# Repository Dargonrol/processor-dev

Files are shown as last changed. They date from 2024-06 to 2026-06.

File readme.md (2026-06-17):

# Project overview

| Project-name | Architecture | Microarchitecture | ISA | status |
| --- | --- | --- | --- | --- |
| **Dragon-1** | SAP-1 | SAP-1 | Dragon-1 | **completed** |
| Dragon-2 | SAP-1 | SAP-1 (mod.) | Dragon-2 | abandoned |
| Dragon-3 | JAM-1 (mod.) | JAM-1 (mod.) | - | abandoned |
| **Dragon-4** | Dragon-4 | Dragon-4 | Dragon-4 | **completed** |
| *Dragon-5* | RISC-D (Dragon) | Dragon-5 | Dragon-5 | *WIP* |
| LED+ | LED | LED-ext. | LED | abandoned |
| Phoenix-1 | - | - | - | in planning |
| Surtr-1 | Z80 | Z80 | Z80 | in planning |

# Descriptions
## Dragon-1
My first try to build an CPU. Basically followed Ben-Eaters breadboard CPU series and read the book Digital Computer Electronics from Albert P. Malvino. I did however implement and thought of my own ISA. It was a good project to get into processors and I'd recommend anyone interested giving building a simple SAP-1 a try.

## Dragon-2
Here is when I went creative and tried to implement all sorts of things I came up with. I only heard of interrupts without knowing what exactly they are and tried to implement them. I also tried to add a display. Both went horribly wrong. It was fun though coming up with all those interesting solutions. It was definitely an important learning step even if it never came to life.

## Dragon-3
Dragon-3 is when I watched a lot of James Sherman and his great homebrew CPU series. Seriously, if you have watched Ben Eater and want to step up things, go ahead and watch James Sherman. You will learn a lot. This is also when I first came across pipelining. Interestingly enough, James implemented it quite differently then a standard risc-V microarchitecture.
Anyway I tried to build my own pipelined CPU but ended up (mostly) copying James which I didn't like so I abandoned it. I am sure it would have come out quite differently if I would have continued but there was really no time to do that because at that time I got in contact with a person who would change my processor development journey for ever. He convinced me to participate at a German science tournament called 'Jugend Forscht'.

## Dragon-4
Knowing I need something proper for this (and especially not a copy of James's CPU) for Jugend Forscht, I began developing the Dragon-4. Due to time constrains I knew, that I couldn't make Dragon-4 pipelined since that would have been much more complicated.  Even tough I tried to not copy James, I was still heavily influenced by him and that's why the rough architecture is quite similar to his JAM-1. It is also the first CPU I build in reallife which added a lot of interesting challenges. If you are interested in the design process and inner workings, I'd recommend reading my 'paper' I had to write for the tournament.
If I had to name one feature of the Dragon-4, it would be that the ISA is horrible. Dragon-4 has 31 instructions, but uses 242 op-codes for them!!! That would be fine if I would have implemented different addressing modes like the 6502 but most of the instructions where just permutations to perform the same action with different registers. E.g. ADD A B, ADD B A, ADD A C etc...
The logic simulation was fine but for some reason I never got the flags working in the real-life version. 
The control logic is also really bad since it consists of 4x32kb of ROMs to decode instructions. This is also why Dragon-4 is really difficult to recreate in games.

## Dragon-5
My current work of art. Originally made to be easily build in computer games but honestly I might scratch that. More important is that I am getting really close to the physical limit for a completely custom microarchitecture. This is also why this will be my last and most capable processor I will build IRL. It's a risc like CPU with a capable ISA. It has stuff like MMIO, basic interrupt support, memory banks to support a large amount of memory as well as seperate instruction and data caches. It's still in early WIP. You'll find a simple comparison of the CPU's in the [readme](Dragon/Dragon_5/readme.md) of Dragon-5.

## LED+
This CPU was developed as an more capable successor to the LED-CPU in the game 'Turing Complete'. LED+ was basically completed but since I wasn't happy I kept trying to improve it but ultimately failed. There were even more iterations of the LED like LED++ and LED+++ but I decided to not include them in this list because they never got really far. Eventually the need for a good processor ingame let to the beginning of the development of the Dragon-5.
Fun-fact: 
Originally Dragon-5 was going to be Phoenix-1 and Phonix-1 was going to be Dragon-5.  Since Dragon-4 was my first real CPU I wanted the most capable and powerful CPU to be the successor of that. And Phoenix-1 was supposed to be the CPU 'for games'. However the reason why I did not do it that way was because the architecture and microarchitecture of the Dragon-4 (if you can even call it architecture) was really simple which fits to the now Dragon-5 (of course Dragon-5 is much more capable and is heavily inspired by the RISC-V). Phoenix-1 is going to be much more complicated therefore I thought a new name would be more fitting.

## Phönix-1
Phoenix-1 is going to be my most capable processor yet. While Dragon-5 was designed to be the last processor IRL, Phoenix-1 will be completely simulated giving me complete freedom. In future it should be able to run a simple operating system etc. (Description WIP)
- Has things like DMA, Branch prediction etc.

## Surtr-1
Surtr-1 is not going to be one of my most powerful machines, but is rather supposed to imitate an old gaming console... using the Z80 CPU...

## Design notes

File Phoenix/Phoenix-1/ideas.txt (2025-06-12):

superpipelining
UART
Interrupts
	- Normal Interrupts
	- Non maskable Interrupts
	- Reset
	{ interrupt interruptbar? -> ja ->  prioritäten... -> prop table in mem. ***annhang1***}
	{ interrupts as trap instr. or different?????? }
	{ Interrupt reg for defining type of int. etc. trough special instr. modble}
	{ When interrupt, save machine state, liks all regs inc. flags }
DMA?
16 oder 32bit???
seperate instruction and data Cache
hardware mul/div?
CLA adder
32 registers? saved and temp usw
program pointer mod-bar, add instr -> don't need jmp instr. but then slower as like in dragon-4

Things like northbrige for graphics card and sound card?????
or integrated graphics? then seperate graphics mem. 

Flags:
	Interrupt Enable

***anhang1***
ext. mem wie z.B. Floppy oder Festplatte wo OS drauf ist. und dann auch sowas wie prop table etc.
ROM on CPU für BIOS, welches OS lädt?
maybe 2 floppy drives or something else, one for OS other for idk. games? user data?

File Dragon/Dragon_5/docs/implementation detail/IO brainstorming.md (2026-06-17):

Remember, with MMIO no I/O data is in RAM. The address decoder detects that I am accessing IO and just pulls data from them.
on every I/O card dip switches to set start address? that way we do not have to convert addresses from CPU address space to IO address space. This also makes it possible to split addresses dynamically aka making having a device more MMIO then usual. 
IO address and data bus is the same with main address and data bus.
Dip switches are 16 bit. They select the address range of the device. we need two dip switches to select a range. The MMIO bit is always set.
``0bxxxx 1xxx xxxx xxxx``
When interrupt, send the upper 4 bits to Interrupt reg. it automatically completes to the full 16bit address.

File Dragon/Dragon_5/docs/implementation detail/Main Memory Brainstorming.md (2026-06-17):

### memory banks
I think it would make the most sense if one memory card holds multiple memory banks. because I want to use a PCIe connector the card would be too small in comparison if I would only put one bank on each card. I am thinking of maybe 4 per card. each card then has jumper or dip switches or simple two close vias that can be brigded to set which card is which *or* the mem cards don't really have any logic and the slot where you put it in decides which one is which. The second option would provide a better user experience.

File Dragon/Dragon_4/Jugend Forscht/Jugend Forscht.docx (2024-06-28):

Projekttitel: Dragon-4 | Ein auf Logikebene selbst entwickelter Prozessor

Projektbeschreibung: Beschreibe kurz, worum es in Deinem Projekt geht und welche Vorgehensweise Du planst.

Schon als kleines Kind habe ich mich immer gefragt, wie es möglich ist, dass ein so kleiner Microchip so viel kann. Als ich älter wurde fing ich an, mich damit auseinander zu setzten. Man findet viele Informationsvideos oder Datenblätter zu Prozessoren und ihrer Funktionsweise. Doch sie alle haben eins gemeinsam: Sie veranschaulichen nur oberflächlich, wie solch ein Wunderwerk der Technik funktioniert. Eine Antwort wie: „Die ALU (Arithmetic Logic Unit) berechnet irgendwelche Zahlen“ oder „Der RAM Speichert Daten“ reicht mir nicht. Ich will wissen, wie genau, auf kleinster Ebene, solch ein Prozessor funktioniert. Wie werden Daten gespeichert? Wie rechnet die ALU? Diese Fragen versuche ich zu beantworten, indem ich selbst einen Prozessor entwickle, um seine Funktionsweise bis ins kleinste Detail zu verstehen. Dazu verwende ich keinen fertigen Microcontroller, sondern stelle mir die benötigte Logik selbst zusammen, um das so tief wie mögliche Verständnis zu erlangen.

Ideen

In welcher Pipeline stage muss welche Control line hin. -> näher erläutern, denn bis zur ersten execution hat es ziemlich lange gedauert…

Überlegt, macht es Sinn content von RAM direkt in MAIN BUS? Aber nein, weil dann REG Controls in der ersten Stage sein müssten, das sind zu viele Lines für die erste

Pipeline: muss 1 clock cycle behind sein, weil sonst speicher an die falsche stelle pointet. -> input der Pipeline latchen

Reg controls in first and second stage, zwar mehr control lines, aber dafür kein noFetch notwendig -> speicher bus ist free to use, wir müssen keine „op skippen“ | DOCH NICHT, da wir keine neue Fetchen können, da das nächste Value im Speicher keineOP ist, sonder just a constant. Also würden wir wenn wir keine 2 Stages brauchen würden und also noFetch weg lassen, das Value als OP fetchen…. Deswegen brauchen wir auch keine direkte Verbindung zwischen RAM und Mainbus, weil wir eh 2 cylcen brauchen bis wir was neues fetchen können.

Alles was ich anders machen wollte, hat sich herausgestellt macht keinen Sinn

Pipeline zu Comlex. Würde eine Copie von James sein.bräuchte mehr Zeit um selber drauf zu kommen, mein Ziel zu lernen würde es dennoch erfüllen. Nur Jugend Forscht nicht. Weil ich unbedingt was eigenes auf die beine stellen möchte für Jugend Forscht, mache ich single Stage.

Anfangskonzept von Ben Eater, mit ROM als Control Unit und Fetch Unit

So, I ran out of OP-Codes when I did the ALU

Why not include cMOV instructions?

Immer gedacht, pipeline notwendig für cpu die quch wirklich was machen können, aber liegt eig. Nur an Architektur.

RAM logic war aua, hahb a lot of truth tables gedrawed, um das hin zu kriegen (some truth tables in die arbeit adden)

Last minute Change, all regs inv clocks

Talk about problem with CREGs in simulation

And massive routing problems, talk about airwires, pin’s waren nicht connected

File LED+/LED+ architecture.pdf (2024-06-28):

# LED+ architecture

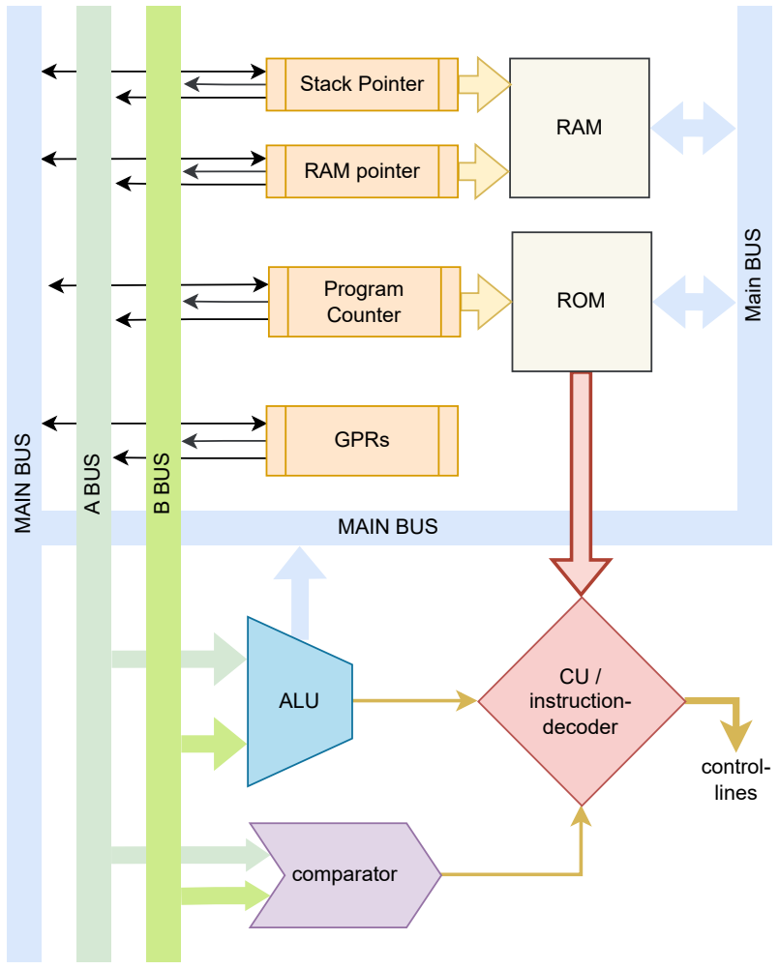
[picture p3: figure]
MAIN BUS; ROM; RAM; GPRs; Program Counter; Stack Pointer; RAM pointer; B BUS; BUS; Main BUS; ALU; comparator; CU / instruction- decoder; control- lines

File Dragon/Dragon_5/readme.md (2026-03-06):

#Dashboard #Dragon5 #Dragon
## general information
- 16bit CPU
- Pipelinded (? stages)
- separate data/instruction-cache
- dynamic instruction range
	- 16bit memory addr, 2 byte word (therefore no need for (auipc)

- Directly Mapped Cache

- nibble = 4-bit
- byte = 8-bit
- word = 16-bit
- dword = 32-bit
- qword = 64-bit

## Instruction Cache
- Directly Mapped
- 64k Cache lines
- 4-bit tag
- 16-bit set
that makes realistically: 2x32k x 8 bit memory chips for tag + valid bit and 1x64k x 16 bit memory chip for data

1. Cache Miss
2. Stall Pipeline
3. Send nearest round down address to RAM, request data
4. Increment address by 1, storing receiving words in Cache
5. after counter at SIZE unstall pipeline

## Graphics
- banked memory
- set double frame buffer mode for half the memory size
# CPU comparison
## **Dragon 5:**
### Instruction count
**Total Instruction Count (used op-codes):** 56 (without pseudo)
**Maximal Instruction Count:** 64, 6-bit
### Features
**Pipelined:** yes
**Variable Instruction Length:** no

## **Dragon 4:**
### Instruction count
**Real Instruction Count:** 31 (without permutations)*
**Total Instruction Count (used op-codes):** 242 (with permutations)*
**Maximal Instruction Count:** 256, 8-bit
### Features
**Pipelined:** no
**Variable Instruction Length:** yes

## **6502:**
### Instruction count
**Real Instruction Count:** 56 (without illegal ones)
**Total Instruction Count (used op-codes):** ?
**Maximal Instruction Count** 256, 8-bit

### Features
**Pipelined:** no
**Variable Instruction Length:** yes

footnote *
permutations means e.g. all the different addressing modes from the 6502 or in case of the dragon 4  for every register combination to add a value you had a different instruction (ADD A B is different than ADD B A) which resulted in a lot of permutations...

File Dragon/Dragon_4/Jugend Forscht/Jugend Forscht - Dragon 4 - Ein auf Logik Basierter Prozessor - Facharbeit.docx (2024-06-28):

2023

Bach Alexander

Jugend forscht

25.3.2023

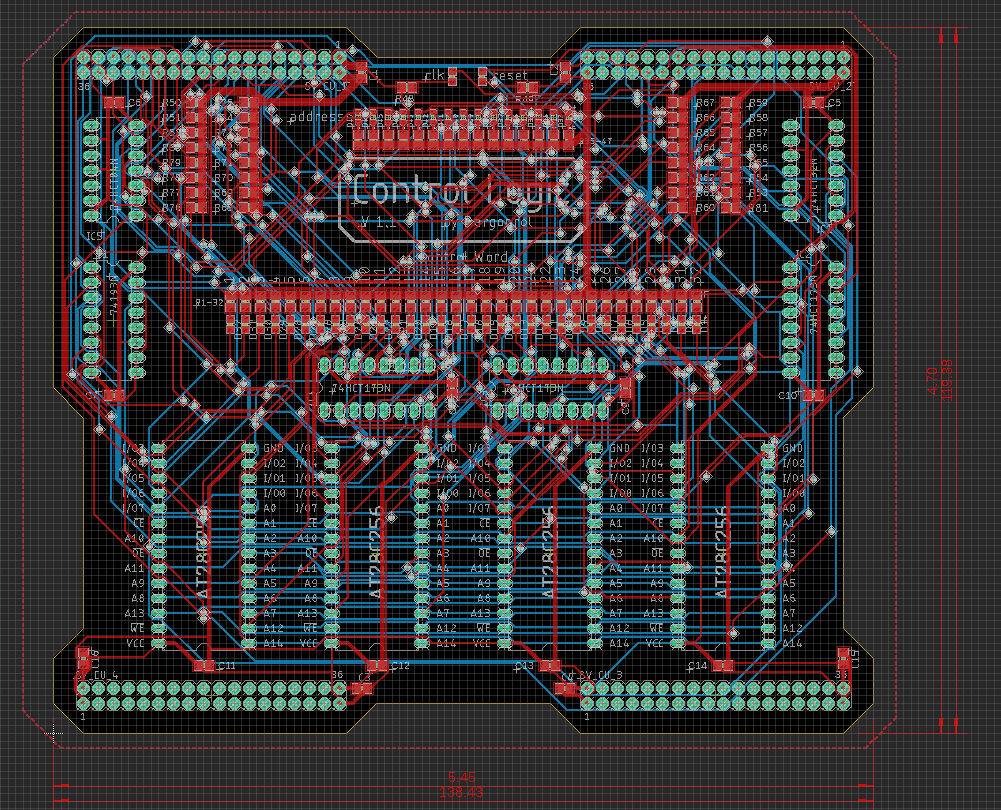
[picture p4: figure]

„Zu verstehen, ist die Essenz, um zu erschaffen.“

Dragon-4 | Ein auf Logikebene selbst entwickelter Prozessor

# Kurzfassung

Mein Ziel ist es die fundamentale Funktionsweise eines Prozessors zu verstehen. Schon oft habe ich gröbere Erklärvideos gesehen, die grundlegende Zusammenhänge darstellen wie zum Beispiel den Aufbau eines Prozessors. Doch all diese Lehrinhalte haben eines gemeinsam: Sie veranschaulichen nur einen groben Einblick in die komplexe Welt der Computer. So will ich nicht nur grundlegende Prinzipien verstehen, sondern mir einen so tiefgreifenden Einblick in die Thematik schaffen, dass ich selbst in der Lage wäre einen Prozessor von Grund auf selbst zu entwickeln. Und genau das tat ich. In diesem Projekt, konzentriert sich Jahrelange Liebe für Technik sowie stundenlanges Forschen und Entwickeln, für das Erschaffen eines eigenen Prozessors.

# 1. Einleitung

## 1.1 Ursprünge

Seit jungen Jahren bin ich ein technikbegeisterter Mensch. Schon damals wurde ich mit kleinen Bastelkits oder Technikmuseen begeistert. Mein Opa brachte mir viel allgemeines Wissen bei und ich fing an meine eigenen Projekte zu realisieren. Doch den Einstieg in Digitaltechnik machte ich tatsächlich durch ein Computerspiel namens Minecraft. So simpel es doch ausschaut ist es möglich, ganze Computer in diesem Spiel zu kreieren. An Inspiration mangelte es nicht. Auf YouTube sah ich dauernd Menschen, welche Taschenrechner oder einfache Spiele erschaffen hatten. Nicht lange danach fing ich selbst an mich mit dieser Thematik zu beschäftigen und machte mich relativ schnell vertraut mit Logikgattern. Logikgatter sind die ultimative Basis jeder Digitaltechnik. Auch wenn man sie weiter in z.B. Transistoren unterteilen kann, bilden Logikgatter die wahre Essenz und absolute Grundlage. In Minecraft dauert es nicht lange, bis man an die Grenzen des Möglichen stößt, weswegen sich die Ausweitung auf eine Logiksimulations-software wie Logisim nicht lange vor sich warten ließ. Zum ersten Mal war es mir möglich, alle meine Ideen umzusetzen, ohne Geld in teures Material zu investieren. Mein Wissen erweiterte ich, selbst heute noch, mit kostenlosen Inhalten wie Videos auf YouTube. Wenn man lange genug sucht, findet man äußerst lehrreichen Inhalt, der nur darauf warten gesehen zu werden. Durch Hilfe von außerhalb erlangte ich auch Zugriff auf Bücher wie The Art of Electronics von Paul Horowitz und Winfield Hill, sowie Digital Computer Electronics von Albert P. Malvino und Jerald A. Brown. Mehrere Jahre experimentiere ich so herum und erweiterte mein Horizont. Erst Letztes Jahr entfachte in mir die Flamme, einen Prozessor zu entwickeln und in der Realität umzusetzen.

## 1.2 Ein Traum wird Realität

Der Wendepunkt meiner Geschichte wurde von nur einer einzigen Person inszeniert. Mein Projektbetreuer Benjamin Brück war es, der mich zu Jugend forscht brachte. Erst jetzt war es möglich das kostenintensive Hobby in die Realität umzusetzen. Die Deadline, die dadurch entstand, brachte natürlich einerseits Unmut, doch im Wesentlichen ist genau das der Grund, warum ich überhaupt Fortschritte gemacht habe. Man kann sich plötzlich keine drei Jahre mehr Zeitnehmen, sondern wird aktiv dazu gebracht, weiterzumachen. Einen Monat vor der Anmeldung begann ich schließlich intensiv zu forschen, verwarf mehrmals meine Konzepte und brachte schließlich eine teilfertige Version ins Leben. Vor allem James Sharman, ein Youtuber, welcher einen sog. Pipelined processor[^1] entwickelt hat, löste einen unglaublichen Motivationsschub hervor. Zunächst wollte ich seinen Prozessor aus Zwecken des Verstehens lediglich nachbauen, doch die Teilnahme an Jugend forscht stellte sich dem Quer und das aus gutem Grund. Für meine privaten Ziele, des Verstehens hätte ein einfaches Nachbauen ausgereicht, doch durch die Teilnahme an Jugend forscht wollte ich etwas Eigenes auf die Beine stellen. Einfach etwas nachbauen kann jeder, auch wenn das Nachbauen und das tatsächliche Verstehen zwei unterschiedliche Dinge sind. So nahm ich mir stattdessen Sharmans Werk als Vorbild und baute darauf meinen eigenen Prozessor. Die Architektur[^2] mag ähnlich sein, doch meine bis zu dem Punkt entwickelten Architekturen wurden restlos übertroffen. So musste ich einen Kompromiss eingehen. Ich nahm seine Architektur als Vorbild, veränderte sie und baute dann darauf auf. Ich wollte mich so weit wie möglich von ihm entfernen, doch die Genialität seiner Architektur beibehalten. So ist der Kern meines CPUs[^3] essenziell anders. Jedes Modul wurde von mir selbst entwickelt, simuliert, geplant und schließlich gebaut. Ich habe immense Zeit und stundenlanges Kopfzerbrechen in dieses Projekt investiert, um mein Ziel, das tiefgründige Verstehen eines Prozessors, zu erreichen.

# 2. Vorgehens- und Funktionsweise

## 2.1 Entwürfe, Planung, Anfänge

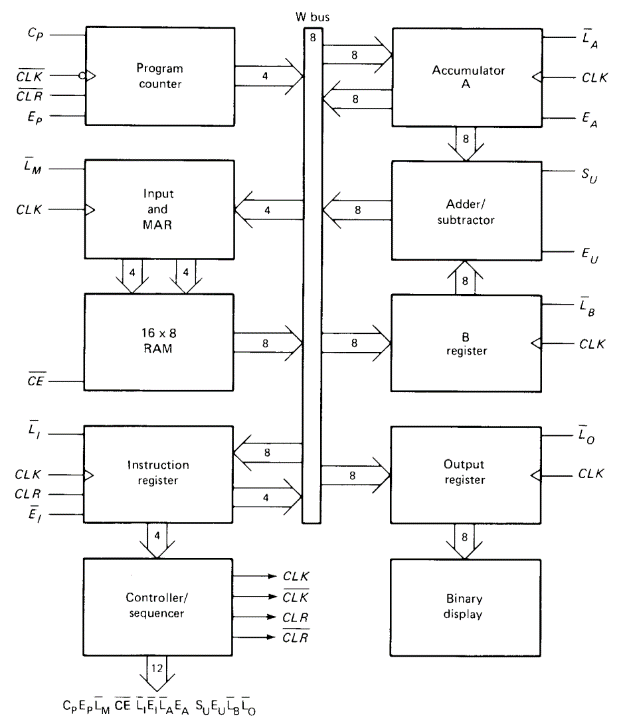
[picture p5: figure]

Zunächst begann alles mit dem SAP-1. SAP steht für Simple as Possible. Das ist Englisch und bedeutet so einfach wie möglich. Der SAP-1 ist eine Prozessor Architektur, vorgestellt von Albert P. Malvino in seinem Buch Digital Computer Electronics mit dem Ziel einem die Grundlagen eines Prozessors nahezubringen. Der SAP-1 ist die simpelste Form eines Turing vollständigen Prozessors. Turing vollständig bedeutet die universelle Programmierbarkeit eines Systems benannt nach Alan Turing. Im Endeffekt ist das ein System, welches in der Lage ist, sich selbst zu emulieren oder jede beliebige Berechnung zu tätigen, wenn sie unendlich Speicherplatz zur Verfügung hätte und die Berechnungszeit endlich ist. Den SAP-1 nachzubauen war mein erstes Ziel und der erste Schritt zu einem näheren Verständnis eines Prozessors. Alles weitere Wissen baut auf diesem Verständnis auf. Aber im Grunde gibt es eine Zentrale Einheit, die sog. Control Logic. Diese ist zuständig für die Erhaltung der Ordnung im System. Das macht sie, indem sie durch control lines Signale an die jeweiligen Module sendet. Das wiederum tut sie basierend auf eng. Instructions, Befehle, welche sie vom RAM[^4] bekommt.

### 2.1.1 Dragon-1

Der SAP-1 war mein Einstieg in Prozessoren. Einmal verstanden, kann man von da aus weiter seinen Weg gehen und komplexere Themen anstreben. Der Dragon-1, der erste Entwurf, war im Prinzip nichts anderes als der SAP-1, mit ein paar erweiterten Funktionen. U.a. konnte die ALU[^5] mehr logische Operationen, die die Ursprünge ALU des SAP-1 nicht konnte. Außerdem hatte der Dragon-1 mehr Register[^6] und vor allem ein Display. Mein Ziel war es damals, ein Display anzuschließen, bei dem sich jeder einzelne Pixel steuern lässt. Auch wenn meine Pläne wahrscheinlich in der Theorie funktioniert hätten, wären die Möglichkeiten sehr begrenzt und ineffizient gewesen. Auch wenn ich ihn schon beinahe fertig simuliert hatte, stufte ich den Dragon-1 äußerst unpraktisch ein und verwarf ihn.

Abbildung 1| SAP-1 Architektur

### 2.1.2 Dragon-2

Relativ schnell setzte ich mich schließlich an den Dragon-2, die Weiterentwicklung des Dragon-1. Hier lag der Fokus vor allem auf I/O-Handling[^7]. Der Dragon-2 hat dazu im Unterschied zum Dragon-1 eine vollständig selbst entwickelte Architektur und versucht Hardware-interrupts[^8] zu integrieren. Ich entwickelte von Grund auf selbst ein System, um Interrupts zu Implementieren. Einer der größten unterschiede war aber wohl das Trennen vom Daten- und Programmspeicher und das hinzufügen eines 16-Bit Adress-busses. So ähnelt die Architektur der Harvard Architektur. Der Dragon-1 hingegen basierte auf der Von-Neumann Architektur, die einen gemeinsamen Bus für Adressen und Daten verwendet. Zu guter Letzt finden wir noch einen sog. Stack, der z.B. für function-calling genutzt wird. Damit war der Dragon-2 eine wesentliche Weiterentwicklung gegenüber dem Dragon-1. Beim dem Dragon-2 wäre es wahrscheinlich auch geblieben, doch fand er nie seinen Weg vom Papier in die Simulation, denn es gibt zwei Sachen, die mich umgestimmt haben. Einmal, war ich mir sehr unsicher bezüglich des I/O-Handling Systems. Ich hatte nicht die Zeit und die Mittel, um dieses System zu testen. Ich konnte mir nie sicher sein, dass es auch wirklich funktionieren würde. Man beachte, dass wir hier vor dem Zeitpunkt der Anmeldung an Jugendforscht reden. Zweitens entdeckte ich James Sharman, ein YouTuber, der seinen eigenen Prozessor nach dem Pipeline-Prinzip entwickelte.

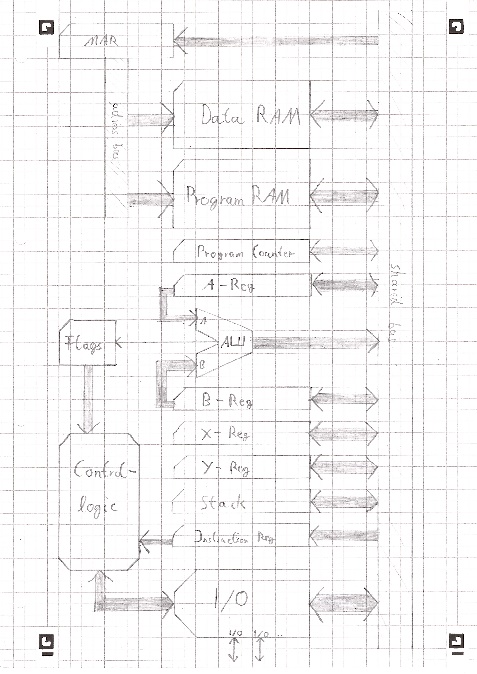
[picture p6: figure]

### 2.1.3 Dragon-3, Pipeline

Eine Pipeline ist eine andere Art der Steuerungseinheit. Im Gegensatz zu multicycle Prozessoren werden hier mehrere Instruktionen gleichzeitig bearbeitet. Das führt dazu, dass sich die Zeit, die der Prozessor benötigt, um einen Befehl auszuführen, effektiv auf Dauer eines Taktes der Taktfrequenz verringert. Bei einem multicycle Prozessor benötigt eine Instruction meist mehrere Taktzyklen. Daher der Begriff multicycle. Mit der Pipeline liegt der größte Unterschied des Dragon-3 zum Dragon-2 aber in der Anzahl der Busse oder einfach gesagt in der Architektur generell. Diese ist wie bereits erwähnt stark inspiriert von James Sharman. Anstatt eines MARs[^9] haben wir einen 16-Bit Adress-Bus, auf dem mehrere Adress-Register ihre Daten ablegen können. Außerdem ist der Haupt-Bus (main bus), auf dem Daten wie Ergebnisse von Berechnungen übertragen werden getrennt von dem Speicher-Bus (memory bus), sodass sich gleichzeitig Daten sowie auch neue Instruktionen bewegen können. Zu guter Letzt kann jedes Register Daten an die ALU mit separaten ALU-Bussen (ALU-Left, ALU-Right) senden. Das alles hat den Vorteil von deutlich mehr Flexibilität und Parallelisierung von Prozessen. Um I/O zu unterstützen, muss man lediglich ein Gerät an den Haupt-Bus anschließen und durch etwa einen I/O-Handler steuern lassen. Theoretisch ginge das auch direkt über die Steuereinheit (CU oder CL), die Anzahl von verfügbaren Steuerleitungen ist aber begrenzt. Auch der Dragon-3 war nicht weit entfernt von der fertigen Simulation, nichtsdestotrotz gibt es einige Punkte, weshalb ich nicht bei dem Dragon-3 geblieben bin. Der Hauptgrund ist wohl, die starke Ähnlichkeit zu James Sharmans CPU. Ein anderer Grund ist die wesentlich höhere Komplexität einer Pipeline. Zwar habe ich das Konzept einer Pipeline verstanden, jedoch würde es zu viel Zeit beanspruchen, eine eigene zu entwickeln, wenn man im Hinterkopf hat, dass wir uns hier schon unmittelbar nach der Anmeldung bei Jugend forscht befinden.

Abbildung 2 | Selbst gezeichnete Architektur des Dragon-2

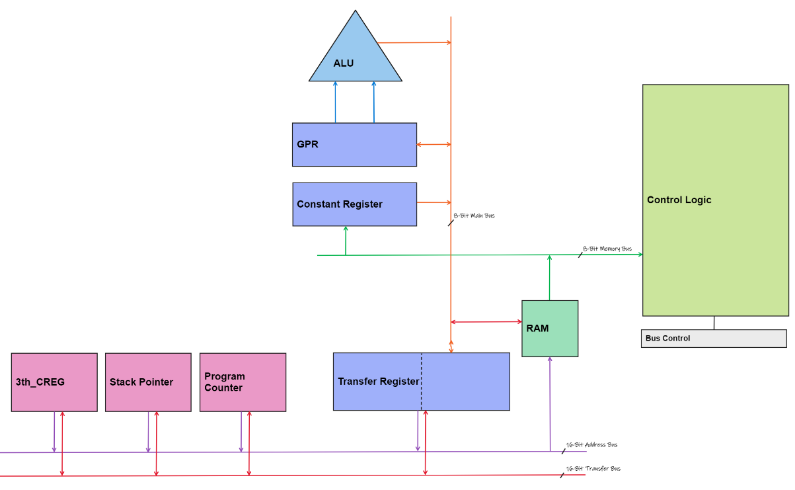
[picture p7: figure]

### 2.1.4 Dragon-4

So sind wir heute bei dem Dragon-4. Die Architektur basiert auf die des Dragon-3, also den von Sharman entworfenen Design, doch das Pipeline-Konzept, welches mich doch sehr inspiriert hat, wurde verworfen und wesentliche Änderungen an der Architektur vorgenommen.

Unter anderem wurde die Anzahl der 16-Bit Register auf drei reduziert und vor allem eine direkte Möglichkeit des RAMs Daten auf den Haupt-Bus aufzulegen erschaffen. Gleichzeitig wurde die Anzahl an GPRs[^10] erhöht und die Bus-Bridge, die in der von Sharmans Ursprünglichen Architektur den Haupt Bus und den Speicherbus verbunden hat, herausgenommen. Diese ist nämlich keine Notwendigkeit und wird durch das Abschaffen der Pipeline sowie eine direkte Verbindung des RAMs zum Haupt Bus auch nicht mehr benötigt.

Abbildung 3 | Dragon-4 Architektur

## 2.2 Vorgehensweise

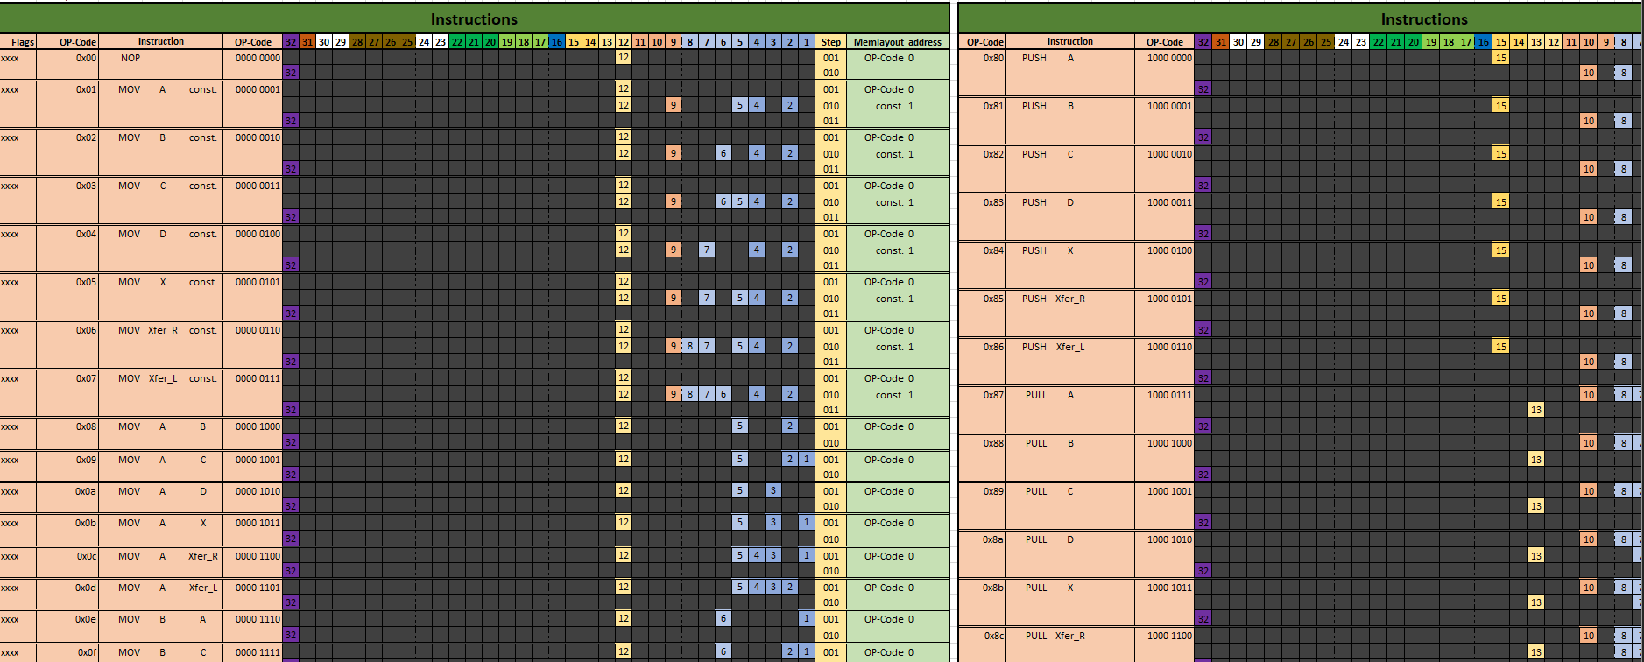
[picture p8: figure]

Zunächst einmal muss man das Grundgerüst, die System Architektur bilden, um anzufangen einen Prozessor zu entwickeln. Da mir diese durch den Dragon-3 bereits klar war, fing ich direkt damit an und nutze das von Microsoft für Windows verfügbare Programm Whiteboard (siehe Abb. 3). Dort ist das Grundgerüst entstanden. Natürlich muss einem vorher klar sein, was man erreichen möchte und was der Prozessor alles können soll, um darauf seine Architektur aufzubauen. Wichtig ist mir eine breite Anzahl an Funktionen, die der CPU leisten kann, sowie einfache Ein- und Ausgabe Möglichkeiten. Natürlich sollte er auch nicht zu langsam sein, um ein Minimalmaß an Nutzbarkeit zu erlangen. Für die Nutzbarkeit war vor allem ein breites Maß an Instruktionen notwendig. Jede Prozessorarchitektur hat seine eigene Programmiersprache, mit eigenen Befehlen, mit dem sie arbeiten kann, die Assemblersprache. Die Assemblersprache steht direkt vor der Maschinensprache mit Einsen und Nullen und besteht aus einfachen Begriffen z.B. MOV A B. Intel Prozessoren haben eine andere Syntax als AMD, da sie direkt vom Prozessortyp abhängig ist. Deshalb gibt es für meinen Prozessor keine fertige Sprache, sondern muss erst entwickelt werden. Dazu fertigte ich eine große Excel-Tabelle mit allen verfügbaren, von mir definierten Befehlen an. Da der Dragon-4 ein 8-Bit Prozessor ist, unterstützt er genau 256 verschiedene Befehle. Als Inspiration habe ich mir dazu das reale Instruction-Set des x86 Prozessors angeschaut.

Abbildung 4 | Ausschnitt des Instruction Sets

### 2.2.1 Simulation

Da nun alle Grundeigenschaften gegeben waren, konnte ich mit der Entwicklung der einzelnen Module anfangen. Das allerdings im realen Leben zu tun ist kostspielig und aufwendig. Deshalb verwendete ich zunächst eine Logik-Simulationssoftware namens Logisim. Logisim ist ein großartiges Werkzeug, um Logikbausteine zu simulieren und zu testen. So habe ich sie zum Beispiel genutzt, um zu experimentieren welche Kombination von Logik Gattern ich benötige, um das gewünschte Ergebnis zu erhalten. Das hat mir das aufwendige Aufbauen und Verkabeln von realen Bauteilen erspart und den Prozess um einiges Beschleunigt. Schließlich habe ich den gesamten Prozessor simuliert, um sicherzugehen, dass er überhaupt funktionieren würde. Dabei sind einem viele Logik- und Denkfehler aufgefallen, die teilweise zu neuen Ideenanstöße geführt haben. Das alles, die Entwicklung des Prozessors in der Software, sowie das Ausmerzen von Fehlern und experimentieren beschreibt einen großen Teil der von mir investierten Zeit in das Projekt.

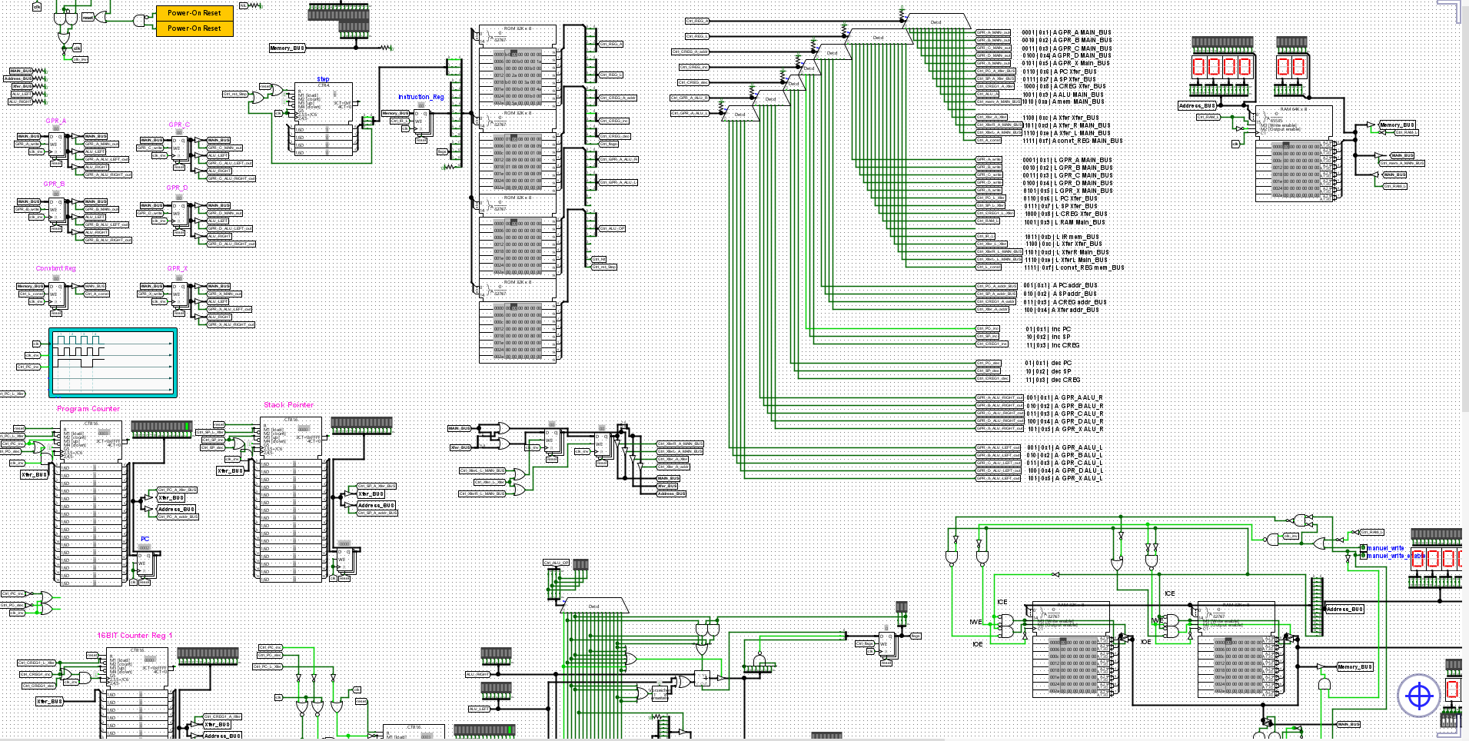
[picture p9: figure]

Abbildung 5 | Ausschnitt der Simulation des Dragon - 4

### 2.2.2 ROM-Datengenerator

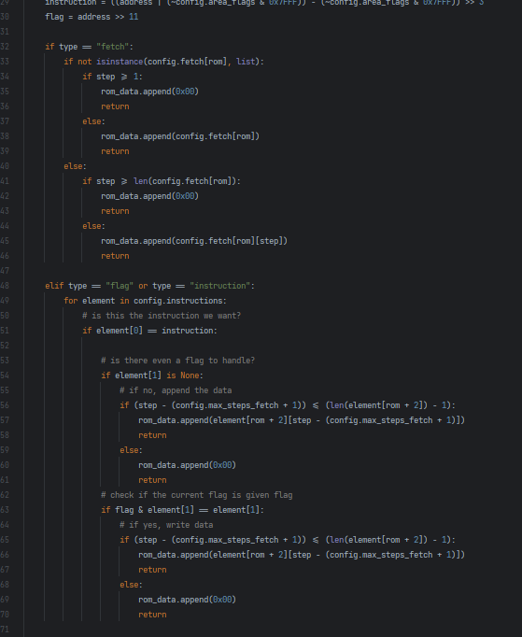
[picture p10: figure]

Um den CPU vollständig in der Logiksoftware zu testen, muss natürlich auch die Steuereinheit vollständig sein. Das Problem, was sich hier aber auftut, ist, dass die Steuereinheit aus ROMs[^11] besteht, die den gigantischen Dekodierer ersetzen, der ansonsten von Nöten wäre. Das Interessante an einen ROM ist, dass man mit Speicherchips jegliche kombinierbare Logik ersetzen kann. Das mache ich mir hier zunutze, um nicht einen übermäßig großen Dekodierer bauen zu müssen. Dieser würde ansonsten jegliche Dimensionen sprengen. Nun müssen dazu aber vorher die ROMs mit Daten gefüllt werden. Die hier verwendeten ROMs haben 32000 mal 8 Bit Speicherplatz. Also 32000 Zeilen mit jeweils 8 Bit oder 1 Byte an Daten. Die Steuereinheit nutzt vier Stück von diesen. Die Daten also von Hand einzutragen wäre nicht nur wahnsinnig, sondern auch noch eine große Zeitverschwendung. Dazu schrieb ich ein Programm in Python, welches für mich alle 32000 Zeilen an Daten füllt. Ich muss lediglich die 256 Instruktionen einmal von Hand in dem Programm definieren.

Abbildung 6 | Ausschnitt des "ROM-Datengenerators"

### 2.2.3 PCB design

Nachdem die Simulation einwandfrei funktionierte, wurde es Zeit, das Projekt in die Realität umzusetzen. Mir schien die Option, das Ganze auf Platinen zu bauen, effizienter und einfacher, als es mit handgefertigten Pantinen oder Breadboards zu versuchen. So arbeitete ich mit der PCB[^12]-Design Software Eagle um Schaltpläne des Dragon-4 zu erstellen und die PCBs zu designen. Dieser Prozess beanspruchte ebenfalls einen großen Teil meiner gesamt Investierten Zeit. Man beachte allerdings, dass „gesamt Investierte Zeit“ sich nur auf den Zeitraum von der Anmeldung bei Jugend forscht bis zur Fertigstellung des Projektes bezieht. Der Dragon-1 ist bereits zwei Jahre vorher entstanden. Über diese zwei Jahre verteilt wurde immens viel Zeit mit Recherche und Weiterbildung zu diesem Thema verbracht, sodass es schwierig ist, die gesamt Investierte Zeit zu schätzen.

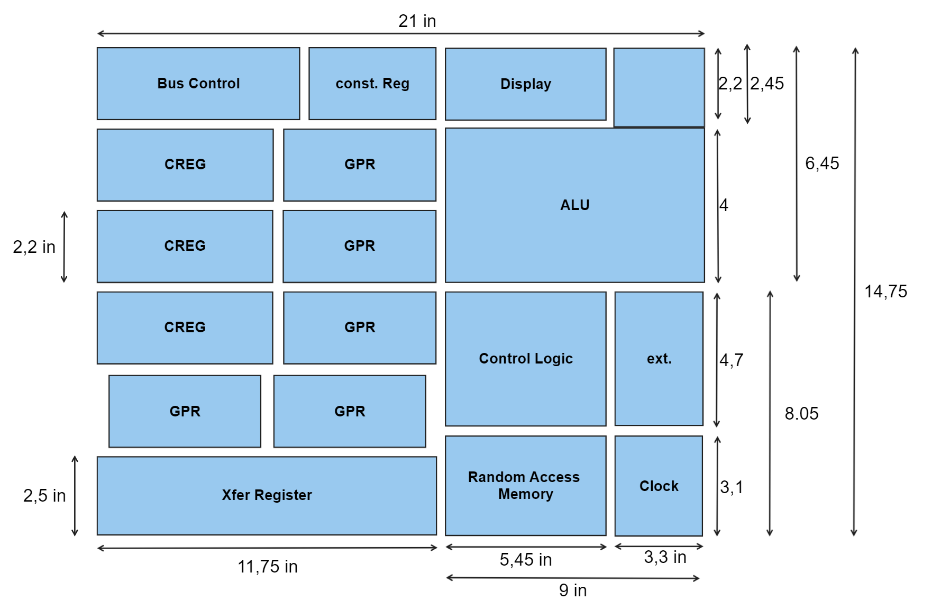
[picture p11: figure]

Bevor ich anfangen konnte, die PCBs zu designen oder die Schaltungen zu erstellen, musste ich mir erst über das Layout im Klaren werden. Hier stellte ich mir die Frage, wie soll der Prozessor später aussehen? Ich entschied mir für ein modulares Design, da Fehler unausweichlich sind und so diese einfacher zu korrigieren sind und ein modulares Design am meisten Flexibilität bietet. Ich kann einfach ein fehlerhaftes Modul herausnehmen und mit einem neuen ersetzen. Die tatsächlichen Maße weichen durch Weiterentwicklung während des PCB-Designs etwas ab, im Großen und Ganzen spiegelt Abbildung 7 aber sehr genau die tatsächliche Größe wider.

Abbildung 7 | Physisches Layout vom Dragon-4

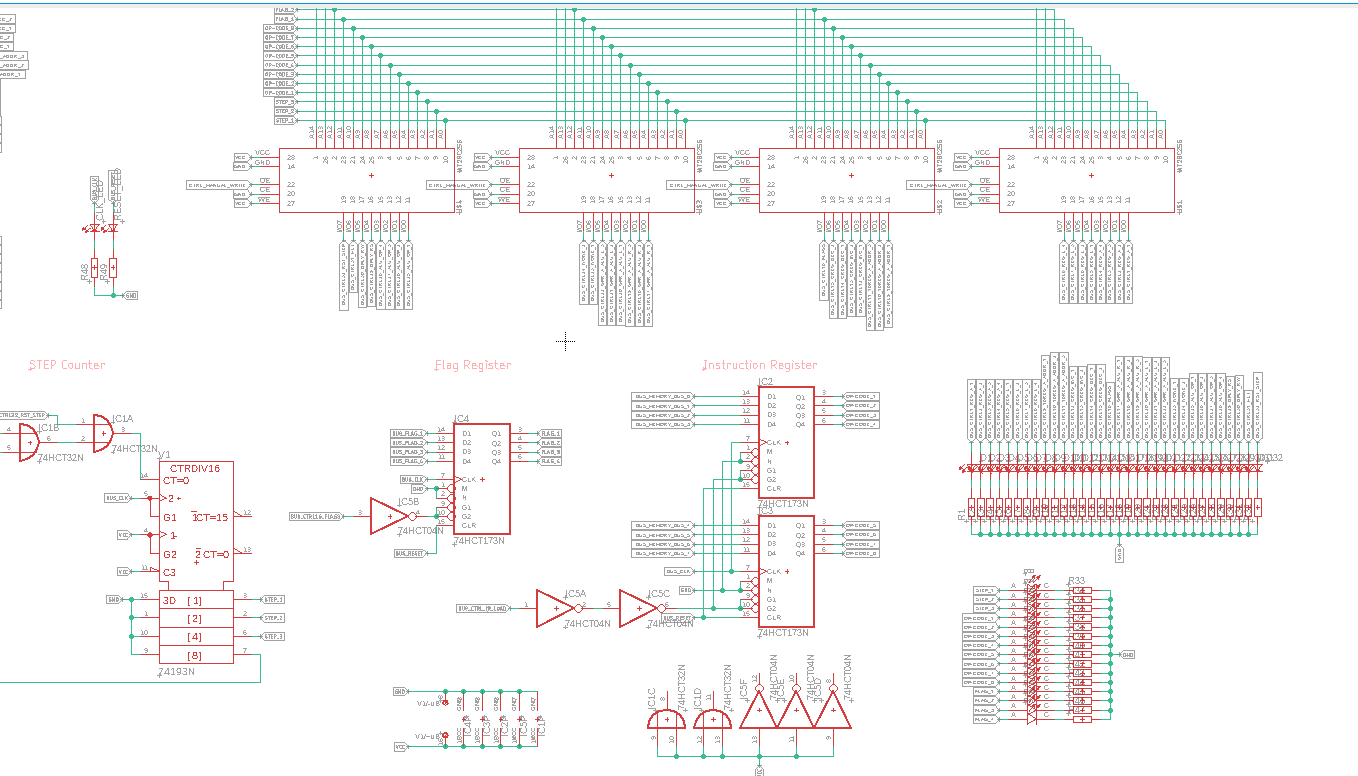
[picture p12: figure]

Nachdem das Layout stand, konnte ich anfangen, die Module zu erstellen. Zunächst der Schaltplan, dann das PCB. Hier galt es allerdings einiges zu beachten. Zunächst einmal muss man schauen, wie man die Bauteile in der Simulation in einen Schaltplan überträgt, denn die Simulation bietet nur idealisierte Bauteile. Ich musste also durch Recherche Bauteile finden, die dieselbe Funktion haben wie in der Simulation. Außerdem musste ich mich entscheiden, welche LEDs, welche Widerstände, welche Kondensatoren, welche Verbinder und noch vieles mehr ich nutzen möchte. Falls es diese dann nicht in dem Programm existieren, muss ich sie selbst erstellen. Zu beachten gibt es hier auch Dinge wie z.B. Lieferzeiten von Bauteilen und Verfügbarkeit. Ist die Schaltung einmal fertig gestellt, kann es zum PCB-Design übergehen. Hier musste ich mich erst mit allgemeinen Designregeln beschäftigen wie zum Beispiel, wann und wo man einen Kondensator platziert, und lernen mit dem Programm umzugehen. Da ich ein modulares Design verwende, muss es noch eine Grundplatte geben, die alles verbindet, das Motherboard. Nachdem alle Teile fertig designt waren, mussten diese lediglich von einem Platinen Hersteller gefertigt werden.

Abbildung 8 | Ausschnitt der Kontroll-Logik

### 2.2.4 Zusammenbau und Programmieren

Nach Anfertigen der Teileliste und deren bestellen. Steht nur noch das Zusammenfügen vor einem. Nach Löten von über 6000 Pins, wochenlanges verbessern von Fehlern und debuggen ist der Prozessor fertig. Doch äußerst viel kann er in dem Zustand noch nicht, denn es müssen noch die ROMs, welche sich in der Steuerungseinheit befinden, beschrieben werden. Danach muss man lediglich ein Programm in den RAM laden und schon konnte der Prozessor seiner Bestimmung nachgehen.

## 2.3 Funktionsweise

Die Funktionsweise in einem Umfang zu erklären, welche nicht die Limitierungen dieser Facharbeit sprengen würde, ist schwierig, weshalb ich mich hier relativ kurzfasse.

Um die Funktionsweise des Dragon-4 zu verstehen, ist ein gewisses Grundwissen notwendig. Dieses erläutert man am besten anhand des SAP-1. Immerhin ist der SAP-1 so einfach wie nur möglich aufgebaut. Um den folgenden Erklärungen besser zu folgen, ist auf der nächsten Seite wieder die Architektur des SAP-1, nur dieses Mal etwas größer, abgebildet.

### 2.3.1 Clock

Die Clock ist wohl das simpelste Bauteil eines jeden Prozessors. Die Clock ist dazu zuständig, nach einem definierten Zeitintervall periodisch ein Signal auszusenden. Dieses wird dazu verwendet den gesamten Prozessor zu synchronisieren, damit jedes Bauteil fehlerfrei miteinander kommunizieren kann. Die Frequenzen erreichen in modernen Prozessoren mehr als 4 GHz . Im Dragon-4 ist die Frequenz durch seine Größe und verwendeten Bauteile sehr begrenzt. Dadurch, dass das Clock-Modul noch nicht fertiggestellt wurde, wurden noch keine Hochgeschwindigkeitsversuche durchgeführt, ich rechne aber mit einer theoretischen maximalen Frequenz von 1,67 MHz . Die bisher höchste getestete Frequenz liegt bei 5 kHz .

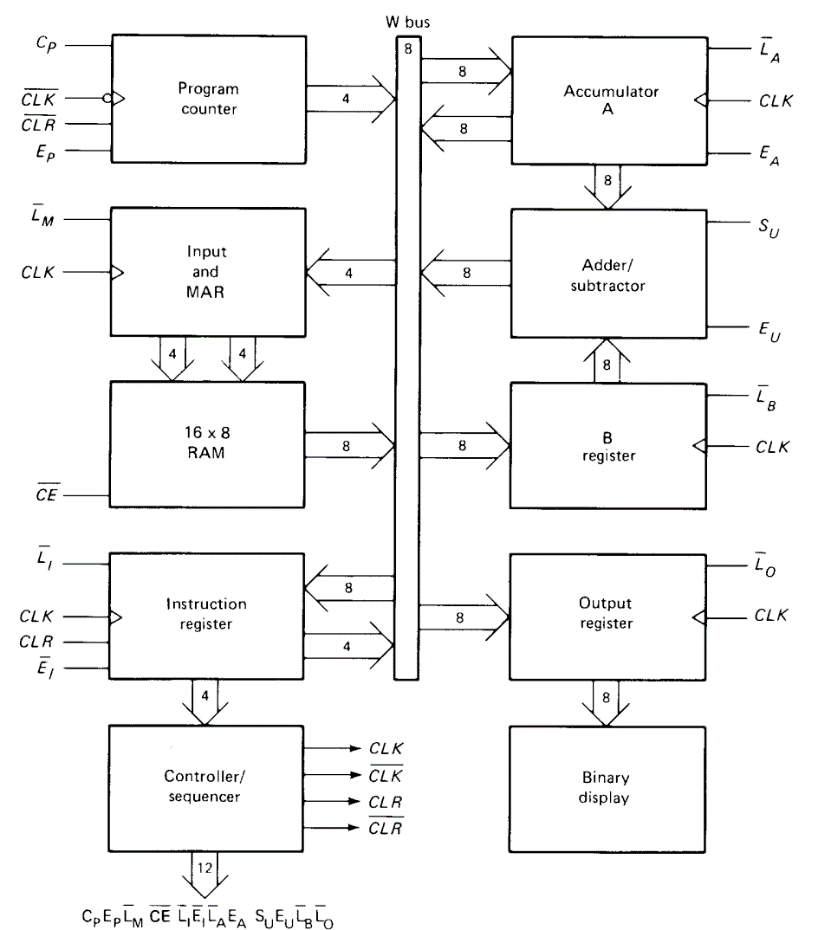
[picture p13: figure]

### 2.3.2 Register

Das Register, ein fester Bestandteil eines jeden Prozessors, tut nichts anderes als in meinem Fall 1-2 Byte an Daten für spätere Wiederverwendung zu speichern. Anders als bei dem RAM, haben wir hier nur eine Zeile mit Daten. Wenn das Register ein Signal zum Speichern empfängt, wird bei dem nächsten Clock-Zyklus die Daten, die sich am angrenzenden Datenbus befinden gespeichert. Nach empfangen eines Ausgabe-Befehls wirft das Register seine Daten wieder auf den Datenbus.

### 2.3.3 PC (Program Counter)

Der Programmzähler ist nichts anders als ein Register, welches die Fähigkeit hat, binär zu zählen. Auf Kommando erhöht es den Wert in seinem Register um eins. Das passiert genau nach jeder Instruktion. So könnte man ihn auch Instruction Pointer nennen. Denn er zählt im Grunde nur mit, bei welchem Punkt wir uns im Programm befinden. Er zeigt auf die Adresse im RAM, bei der die nächste Instruction gespeichert ist, damit diese ausgeführt werden kann.

Abbildung 9 | SAP-1 Architektur

### 2.3.4 MAR (Memory Address Register)

Das MAR ist ein weiteres Register, welches die Aktuelle Adresse des RAMs speichert. Im SAP-1 wird der Inhalt des program counters in das MAR verschoben, um die aktuelle Adresse zu ändern. In meinem Prozessor gibt es direkt kein MAR. Hier wird der Inhalt des program counters so lange auf einen Adressbus ausgegeben, bis sie nicht mehr benötigt wird. Der Adressbus ist direkt mit dem RAM verbunden.

### 2.3.5 RAM

Der RAM ist einer der zentralen Komponenten. Er beinhaltet das Programm, welches wir ausführen möchten und so die Instruktionen, die dem Prozessor sagen, was er zu tun hat. RAMs können mehrere Hunderttausende Speicherbänke mit Datensätze beinhalten. Welche Speicherbank gerade ausgewählt ist, wird als Adresse bezeichnet. In meinem Fall besitzt der RAM 64000 Speicherbänke mit jeweils einem Byte, also 8 Bit Daten. Der RAM kann seine Daten entweder auf einen BUS ausgeben, oder direkt Steuereinheit überreichen.

Der RAM des Dragon-4 ist gleichzeitig das Stack. Das Stack wird zum function-calling verwendet. Die Besonderheit, dass der Stack in dem RAM integriert ist, ist dass der Speicherplatz für beides, Stack und Programm variable ist. Wenn man nicht aufpasst, könnte man den einen Bereich mit dem anderen überschreiben, andererseits hat es den Vorteil, dass wenn man mehr RAM benötigt, einfach mehr nutzten kann.

### 2.3.6 Control Logic (CU, CL)

Die Steuereinheit ist das Herz eines jeden Prozessors. Ohne sie, wäre er nicht funktionsfähig. Die Steuereinheit nimmt sich eine Instruktion, welche sie von dem Instruktions-Register oder dem RAM bekommt und sagt dem ganzen Rest des CPUs, was er zu tun hat. Das macht sie mithilfe eines riesigen Dekodierers, der für jede Instruction einen Befehlssatz das sog. Control Word ausgibt.

### 2.3.7 ALU

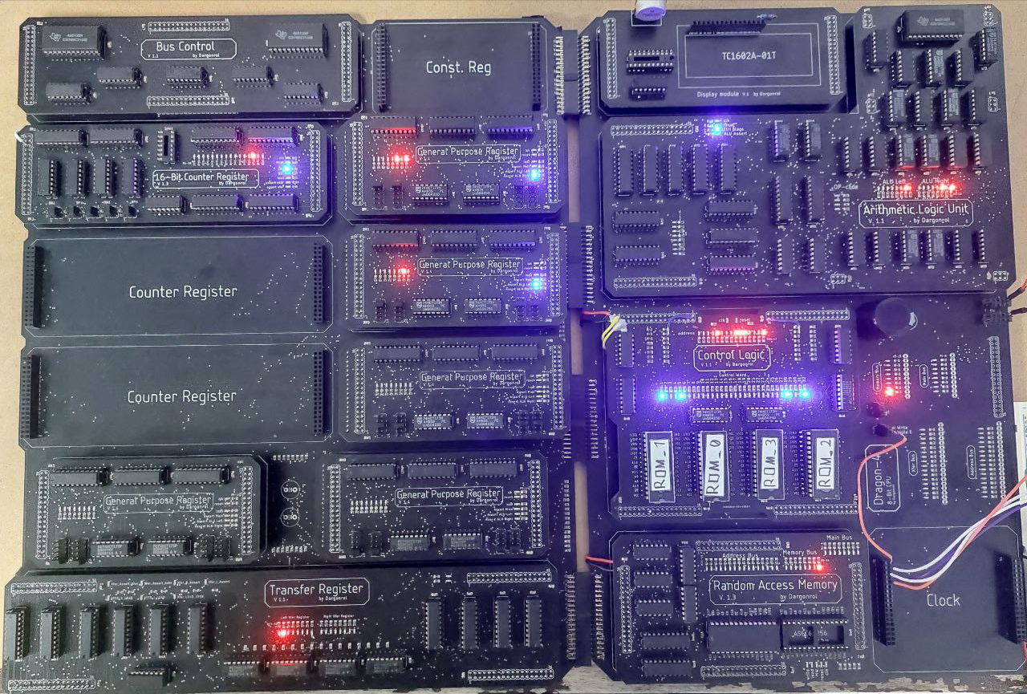
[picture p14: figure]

Viele bezeichnen die ALU, Arithmetisch Logische Einheit als das Gehirn eines Prozessors, doch ohne die anderen Komponenten ist sie sehr nutzlos. Wie der Name bereits hergibt, nimmt sie ein oder mehrere Werte von z.B. dem A und B Register (siehe Abbildung 9) oder von einem Bus, wie in dem Dragon-4 und führt mit diesen Werten Arithmetische Operationen wie plus- oder minusrechnen oder logische sowie bitwise Operationen wie AND oder bit shifting durch.

Abbildung 10 | gesamter Prozessor mit unfertigen Modulen

### 2.3.8 IR (Instruction Register)

Das Instruktions-Register speichert die derzeitig bearbeitete Instruktion, damit sie von der der Kontroll-Logik genutzt werden kann. Im Dragon-4 ist dieses in der Steuereinheit implementiert.

# 3. Ergebnisse

## 3.1 Probleme

Einen Prozessor zu entwickeln ist keine einfache Aufgabe. Das zeigte sich immer wieder während der Entwicklung, sowie auch während des Zusammenbauens. Fangen wir bei dem Dragon-3 an, der noch auf einer Pipeline basierte.

### 3.1.1 Pipeline

Die Pipeline ist ein geniales Konzept, welches die Nutzung von der internen Logik maximal optimiert. Doch mit der Genialität wächst auch die Komplexität. Eine Pipeline beinhaltet mehrere Stages, bei der eine Instruktion jeweils unterschiedliche Control-words lossenden muss. Fehler führen zu einem nicht ausführen einer Instruktion oder das Fetchen[^13] einer nicht Instruktion. Herauszufinden welche Steuerleitung, in welcher Pipeline Stufe wann aktiviert werden muss, war sehr herausfordernd und hat einige Zeit beansprucht. Zu der ersten Ausführung eines Befehles, hat es sehr lange gedauert.

Die Entscheidung das Pipeline-Konzept zu verwerfen, hat alle Probleme des Dragon-3 hinfällig gemacht. Für die Komplexität einer Pipeline, war einfach nicht genügend Zeit vorhanden, nichtsdestotrotz habe ich das Konzept und die Funktionsweise einer Pipeline verstanden und zu verstehen sowie sich weiterzubilden ist wie schon oft beschrieben, meine Hauptmotivation.

### 3.1.2 Simulation vs. Realität

In der Simulation gibt es Probleme, die man in der Realität nicht hat, in der Realität gibt es Probleme, die man in der Simulation nicht hat. Vereinfacht gesagt, Simulation und Realität sind etwas komplett Unterschiedliches. Mit einer Simulation kann man schließlich eine Realität nur nachahmen. Das hat unausweichlich zu einigen, teilweise fatalen, Problemen geführt. Zunächst einmal sind die Bauteile, die man in der Logik-Software verwenden konnte, nur idealisierte Bauelemente, die so in der Realität nicht existieren. Das brachte mich dazu reale Äquivalente zu finden, doch ist es nun mal so, dass es nicht immer welche gibt. So musste ich kreativ werden und nach weiteren Bauteilen suchen, die diese ersetzen können. Dabei sind einige Änderungen Im Schaltplan im Vergleich zu der Simulation entstanden. Ein Beispiel wäre, dass fast alle Control Lines, invertiert wurden. Das war aufgrund der Bauweise der Chips. Diese Tatsache führte zu einem meiner größten Probleme, denn invertiere Control Lines bedeutete eine teilweise komplett unterschiedliche Logik. In Kombination mit den unterschiedlichen Bauteilen führte das dazu, dass die im Schaltplan verwendete Logik vollständig in meinem Kopf entstand und so viele Fehler enthielt. Erst einen Tag vor der Bestellung der Platinen fielen mir nochmal so viele Fehler auf, dass ich beschlossen habe, die Idealisierten Bauteile in der Simulation so anzupassen, dass sie der Realität entsprechen. So fand ich nochmals einige fatale Fehler, wie zum Beispiel das Anwenden falscher Logikgatter im RAM-Modul. Das hätte dazu geführt, dass dieses nicht ganz oder sogar gar nicht funktioniert hätte. Durch das realitätsnähere Simulieren kann ich mir zumindest etwas sicherer sein, dass mein Entwurf funktioniert.

### 3.1.3 Routing Probleme

Das ganze Verbessern der Fehler beinhaltet das Neurouten von den Leiterbahnen auf den Platinen. Auf kleineren Boards ist das kein Problem, doch auf größeren komplexeren, wie die ALU wird das sehr schnell sehr unübersichtlich und schwierig. Da auf solch einem Board teilweise über 300 Verbindungen getätigt werden müssen, benutzte ich einen Autorouter, der mir die Leiterbahnen automatisch nach einem Algorithmus verlegt. Man sollte lediglich gewisse Voreinstellungen wie Leiterbahndicke festlegen. So schön das auch klingen mag, bei solch hochkomplexen Platinen benötigt der Autorouter teilweise stundenlange Rechenzeit und manchmal versagt er sogar, da es schlicht weg einfach unmöglich sein kann, auf so engen Platz so viele routen zu verlegen. Als Lösung arrangierte ich Bauteile neu und stellte die Leiterbahndicke niedriger, wobei man hier einen Kompromiss eingehen muss, denn je dünner die Bahnen, desto weniger Strom kann durch sie hindurchfließen. Die ALU erfolgreich zu routen hat dann schlussendlich mehrere Stunden gedauert.

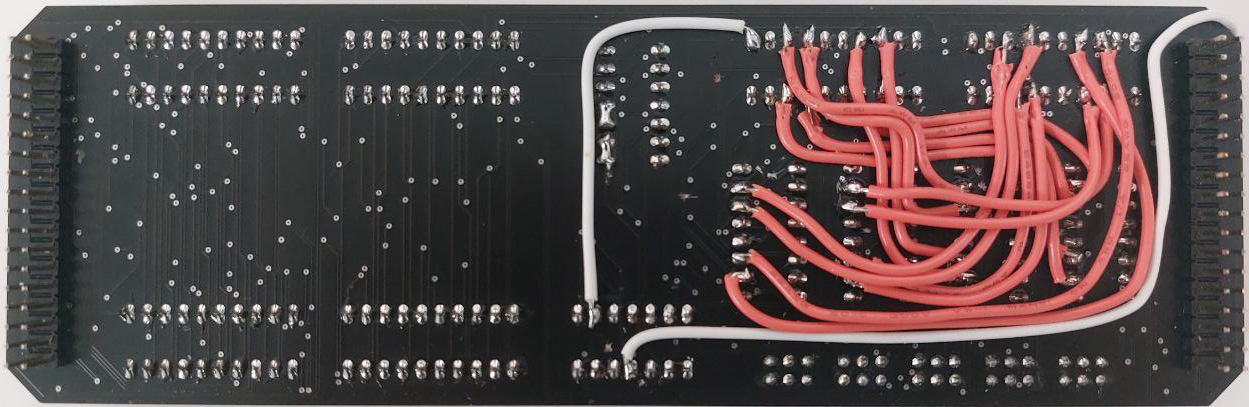
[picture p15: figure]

Abbildung 11 | fehlerhafte Platine

### 3.1.4 „Fehler sind Menschlich“

Nach dem Bestellen und zusammenbauen, passierte erst einmal nichts. Natürlich mussten sich Fehler, die man nicht voraussehen konnte, einschleichen, denn es wäre leichtsinnig gewesen, zu vermuten, dass alles auf Anhieb funktionieren würde. Trotzdem beansprucht das Debuggen von Problemen immense Zeit und kann sehr frustrierend sein. Doch dadurch lernt man, was ein wichtiger Prozess ist. Das Debuggen ist ein Prozess, der mehrere Wochen in Anspruch genommen hat. Letztendlich musste ich sogar den größten Teil der Platinen nochmal neu erstellen.

## 3.2 Leistung

Die Frage, was der Dragon-4 leisten kann ist eine schwierige, da ich noch nicht die Möglichkeit hatte ihn auf seine Höchstleistung zu testen. Fragt man mich aber was der Dragon-4 alles so kann, antworte ich alles. Das liegt daran, dass der Dragon-4 nach Alan Turing Turing Vollständig ist. D.h. er ist in der Lage jede beliebe Berechnung zu tätigen. Das beinhaltet auch hoch moderne Grafiken. Hätte der Prozessor eine Grafikkarte, wäre er auch in der Lage, diese anzuzeigen. Nach meinen Hypothesen sollte er bis zu einer Geschwindigkeit von 1,6 Mhz laufen können. Limitiert wird er von der Geschwindigkeit der ROM-chips, da diese am größten und komplexesten sind und so am meisten Zeit benötigen, bis eingehende Signale bearbeitet werden. Wenn eine Instruktion durchschnittlich ca. 5 Zyklen benötigt und wir eine maximale Taktfrequenz von 1,67 Mhz haben, kommen wir auf:

(1,67∙10^6 Hz)/5=334 kIPS (thousend instructions per second)

Da eine Pipeline theoretisch pro Zyklus eine Instruction verarbeitet, ist diese in dem Fall doppelt so schnell. Realistisch würde ich allerdings die Geschwindigkeit meines Prozessors geringer schätzen.

Der Grund, weshalb moderne Prozessoren wesentlich schneller sind, ist da diese mikroskopisch klein sind, und so die Bauteile nah aneinander liegen. Außerdem verwenden Hersteller modernste Technologien, auf die ich keinen Zugriff habe.

Allgemeine Statistiken:

Anzahl Instruktionen | durchschnittliche Länge der Instruktionen | Maximale Taktfrequenz | Speicherplatz | IPS (instructions per second) | Stromverbrauch
256 | 5 Zyklen | ca. 1,6 Mhz | 512 kB | 334 kIPS | ca. 1 Watt

# 4. Ergebnisdiskussion

Allgemein bin ich sehr zufrieden mit meinem Prozessor, doch Pläne habe ich noch viele mehr. Unter anderem wollte ich Ursprünglich eine Grafikkarte bauen, um die errechneten Ergebnisse zu visualisieren. Doch eine Grafikkarte ist kein einfaches Bauteil. Ich hätte wesentlich mehr Zeit benötigt, um eine Grafikkarte fertig zu stellen, vor allem da es für mich wichtig ist, dass ich keine fertigen Microcomputer für meinen CPU benutzte. Ich möchte alles von Grund auf selbst bauen. Das gleiche gilt für eine Soundkarte. I/O Handling war ein Ziel, welches ich Ursprünglich unbedingt implementiert haben wollte, doch auch hier war wegen der Vorbereitung auf die annähernden Abiturprüfungen im April wenig Zeit. Schließlich baute ich den Prozessor so, dass es theoretisch möglich wäre, einen I/O-handler anzuschließen, sollte ich in Zukunft Zeit und Lust finden, diesen zu bauen. Auch die Funktion durch eine Tastatur den Inhalt des RAMs zu verändern, ist momentan noch nicht möglich, da ich die dazu fehlende Hardware nicht rechtzeitig fertig stellen konnte. Trotzdem habe ich auch hier vorausgeplant und die Module so entwickelt, dass man diese Hardware einfach dazu stellen könnte. Bisher muss man also den RAM herausnehmen und sein Programm extern über einen Computer programmieren. Eine weitere Sache für die Zukunft wäre einen assembler zu schreiben. Bisher muss ich Programme direkt im Maschinencode programmieren, was sehr aufwendig ist.

Außerdem haben die fehlende Erfahrung in den diversen Programmen mir einige Schwierigkeiten und Frust bereitet, doch letztendlich habe ich nur dazugelernt. Sollte ich erneut einen Prozessor bauen oder diesen weiterentwickeln, weiß ich, wie. Vor allem das PCB-Design würde ich in Zukunft anders machen. Ich weiß zum Beispiel, dass man alle Bauteile nur auf die Oberfläche platzieren sollte, um sich eine Menge Arbeit und Kosten bei der Produktion zu sparen. Auch habe ich gelernt, dass es durch schlechte oder zu wenige Ground-Verbindungen zu Instabilität in den Chips kommen kann.

Rein theoretisch müsste es auch durch kleine Modifikationen möglich sein, das Pipeline-Konzept wieder einzuführen. Da der Prozessor sehr modular ist, kann man einfach Module austauschen. In dem Fall müsste man die gesamte Steuereinheit neu entwickeln. Das sind Dinge, die man sich in Zukunft vornehmen könnte.

# 5. Zusammenfassung

Trotz all den dutzenden Problemen bin ich sehr zufrieden. Dieses Projekt hat mir sehr viel Frust bereitet, aber auch umso mehr Erfahrung in allen Teilbereichen. Insgesamt hat es einen großen Spaß den Prozessor zu entwickeln und bauen, was das aller wichtigste ist.

Vor allem das zu demselben Zeitpunkt immer näher Rückende Abitur hat mir besonders Kopfschmerzen und immensen Zeitdruck veranstaltet. Nichtsdestotrotz war und ist meine Begeisterung für Technik und dem Forschen groß und hat schließlich dazu geführt, dass ich das Projekt rechtzeitig, nicht unbedingt abschließen, aber bis zu einen Zufriedenstellenden Punkt fertigstellen konnte. Mein Ziel, zu verstehen, habe ich erreicht. Ich verstehe nicht zu 50%, sondern zu 100%, wie zumindest eine solch simple Form eines Prozessors funktioniert. Zu verstehen, ist nicht nur das Ziel dieses einen Projektes, sondern das Ziel mehrere Jahre Begeisterung für Digitaltechnik. Man könnte sogar noch weiter gehen und sagen, es war Ziel, seit Anbeginn meiner Kindheit, seit Anbeginn meiner Sehnsucht und Liebe nach Technik. Schon als kleines Kind wollte ich wissen, wie die Welt funktioniert. Seither strebt mich das an weiter zu forschen, weiter zu entdecken, zu erfinden, zu leben. Technik ist Teil meines Lebens und ich bin dankbar dafür. Das Ziel im Engen Sinne, diesen Prozessor zu bauen, habe ich erreicht. Auch wenn manche Dinge nicht vollständig funktionieren, oder anders sind als erwartet, ist mein Ziel etwas selbst entwickeltes ins Leben zu rufen geglückt. Doch Ende ist hier noch lange nicht. Zu verstehen ist die Basis für alles Darauffolgende. Wenn man versteht, kann man kreieren, wenn man versteht, kann man weiterkommen. So will ich weiter verstehen, weiter nach Wissen streben, um immer höhere Horizonte zu erreichen. Ich bin dankbar für diese einzigartige Chance meinen Horizont zu erweitern und mir Wege für die Zukunft zu eröffnen. Dieses Projekt hat mir unglaublichen Spaß gemacht.

# 6. Quellenverzeichnis

- Wikipedia, Turing Vollständigkeit, https://de.wikipedia.org/wiki/Turing-Vollständigkeit, zuletzt besucht am 12.02.2023
- Wikipedia, Instruction pipelining, https://en.wikipedia.org/wiki/Instruction_pipelining, zuletzt besucht am 12.02.2023
- Wikipedia, Instructions per second, https://en.wikipedia.org/wiki/Instructions_per_second, zuletzt besucht am 25.03.2023
- Albert P. Malvino, Jerald A. Brown: „Digital Computer Electronics”, Kalifornien 1977
- Ben Eaters Video Reihe: „Building an 8-bit breadboard computer!”
- James Sharmans Video Reihe: „Making an 8 Bit pipelined CPU”

# 7. Unterstützungsleistung

Ich möchte meinen herzlichsten Dank an allen Personen ausrichten, die mich bei der Planung bis zur Realisierung dieses Projektes unterstützt haben.

Besonderes Dankeschön an:

- Wolfgang Schröder, für Ideenfindung und Wissensbereicherung
- Ben Eater, für den Einstieg in das Themenfeld der Funktionsweise von Prozessoren durch seine Video-Reihe
- James Sharman, für die Umfangreiche Ideenfindung und Wissensbereicherung, sowie Inspiration und Erläuterungen von komplexen Konzepten wie der Pipeline durch seine Video-Reihe

Und ganz besonders an:

Benjamin Brück,

für das in Kontakt bringen mit Jugend forscht, der finanziellen Unterstützung, das Bereitstellen diverser Materialien, Werkzeugen und Räumen, das Korrekturlesen dieser Arbeit und die Hilfestellung bei diversen Fragen

[^1] Siehe 2.2.3 Dragon-3, Pipeline
[^2] Architektur, hier: Aufbau eines Prozessors
[^3] CPU = Eng. Central Processing Unit | Prozessor
[^4] RAM = Random Access Memory | veränderbarer Speicherplatz für Daten
[^5] Arithmetic Logic Unit kurz ALU oder Arithmetisch Logische Einheit | zuständig für Logische und Arithmetische Berechnungen.
[^6] Register | zuständig für Temporäres Speichern von Daten
[^7] I/O = Input Output | I/O-Handling meint das Unterstützen von Geräten wie Tastatur und Display
[^8] Unterbrechung des laufenden Programmes für z.B. eine Tastatureingabe
[^9] MAR = Memory Address Register | Speicherort für die Adresse des RAMs
[^10] GPR = General Purpose Register | Temporärer Speicherort für Daten
[^11] ROM = Read Only Memory | Speicherchip, von dem nur gelesen werden kann
[^12] PCB = Printed Circuit Board | Platine
[^13] To fetch an instruction beschreibt den Prozess einen neuen Befehl in die Kontroll-Logik aufzunehmen, um ihn abzuarbeiten.

Seite 2 von 2

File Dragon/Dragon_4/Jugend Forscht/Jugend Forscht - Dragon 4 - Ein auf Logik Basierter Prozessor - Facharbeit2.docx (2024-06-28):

2023

Bach Alexander

Jugend forscht

12.2.2023


„Zu verstehen, ist die Essenz, um zu kreieren.“

Dragon-4 | Ein auf Logikebene selbst entwickelter Prozessor

# Kurzfassung

Zu verstehen bringt die Menschheit weiter, zu verstehen erschafft neue Talente, zu verstehen ist unsere Zukunft. Allein durch das Verständnis, eröffnet sich überhaupt erst die Möglichkeit Dinge zu erreichen, zu erschaffen. Nur weil wir Statik verstehen, können wir Hochhäuser bauen, nur weil wir die Chemie gründlich erforscht haben, ist es uns möglich täglich mit solch fortgeschrittenen chemischen Produkten zu leben. So ist das Verständnis auch Ziel meines Projektes. Es gilt zu verstehen, wie es uns möglich ist, Virtuelle Welten zu erschaffen, Millionen Rechnungen pro Sekunde zu tätigen oder auf ein Hundertstel Millimeter genau Metall zu schneiden. Das alles unterliegt einzig allein dem Fortschritt der Digitaltechnik, genauer noch dem Kern jedes fortgeschrittenen Elektronischen Gerätes; Dem Prozessor. So ist es mein Ziel diese Zentrale Komponente nicht nur oberflächlich, sondern genaustens auf dem Grund zu gehen. Das zu verstehende dann von Grund auf neu zu kreieren, ist nichts anderes als der direkte Beweis, des verstehen des erlangten Verständnisses. Auch wenn dieses Thema bereits erforscht worden mag, ist es trotzdem notwendig, die Grundlagen zu verstehen, um weitere Horizonten zu erreichen, denn alles baut auf einer Basis auf, alles fängt irgendwo an. In dem Ich versuche das größtmögliche Verständnis zu den Grundlagen eines Prozessors zu erlangen, erschaffe ich mir einen Weg in die Zukunft, eine Basis, auf der ich aufbauen kann. Das Ziel dieses Projektes sowie dieser Facharbeit ist das Erläutern und Veranschaulichen meiner Forschungsergebnisse, bei dem Versuch einen solchen Prozessor zu verstehen und zu erschaffen.

# 1. Einleitung

## 1.1 Ursprünge

Seit jungen Jahren, bin ich ein Technikbegeisterter Mensch. Schon damals wurde ich mit kleinen Bastelkits oder Technikmuseen begeistert. Mein Opa brachte mir viel allgemeines Wissen bei und ich fing an meine eigenen Projekte zu realisieren. Doch den Einstieg in Digitaltechnik machte ich tatsächlich durch ein Computerspiel namens Minecraft. So simpel es doch ausschaut, ist es möglich ganze Computer in diesem Spiel zu kreieren. An Inspiration mangelte es nicht. Auf YouTube sah ich dauernd Menschen, welche Taschenrechner oder einfache Spiele erschaffen hatten. Nicht lange danach fing ich selbst an mich mit dieser Thematik zu beschäftigen und machte mich relativ schnell vertraut mit Logikgattern. Logikgatter sind die Ultimative Basis jeder Digitaltechnik. Auch wenn man sie weiter in z.B. Transistoren unterteilen kann, bilden Logikgatter die wahre Essenz und absolute Grundlage. In Minecraft dauert es nicht lange, bis man an die Grenzen des Möglichen stoßt, weswegen sich die Ausweitung auf Logiksimulations-Software wie Logisim nicht lange vor sich hin braute. Zum ersten Mal war es mir Möglich alle meine Ideen umzusetzen, ohne Geld in teures Material zu investieren. Mein Wissen erweiterte ich, selbst heute noch mit kostenlosen Inhalten wie Videos auf YouTube. Wenn man lange genug sucht, findet man äußerst Lehrreichen Inhalt, der nur darauf warten gesehen zu werden. Durch Hilfe von außerhalb erlangte ich auch Zugriff auf Bücher wie The Art of Electronics von Paul Horowitz und Winfield Hill, sowie Digital Computer Electronics von Albert P. Malvino und Jerald A. Brown. Mehrere Jahre experimentiere ich so herum und erweiterte mein Horizont. Erst Letztes Jahr entfachte in mir die Flamme das Ganze in der Realität umzusetzen.

## 1.2 Ein Traum wird Realität

Der Wendepunkt meiner Geschichte wurde von nur einer einzigen Person inszeniert. Mein Projektbetreuer Benjamin Brück war es, der mich zu Jugendforscht brachte. Erst jetzt war es möglich das doch relativ kostenintensive Hobby in die Realität, um zu setzen. Die Deadline, die dadurch entstand, brachte natürlich einerseits Unmut, doch im Wesentlichen ist genau das der Grund, warum ich überhaupt Fortschritte gemacht habe. Man kann sich plötzlich keine 3 Jahre mehr Zeitnehmen, sondern wird aktiv dazu gebracht weiterzumachen. Einen Monat vor der Anmeldung begann ich schließlich intensiv zu forschen, verwarf mehrmals meine Konzepte und brachte schließlich eine teilfertige Version ins Leben. Vor allem James Sharman, ein Youtuber, welcher einen sog. Pipelined processor[^1] entwickelt hat, löste einen unglaublichen Motivationsschub hervor. Zunächst wollte ich seinen Prozessor aus Zwecken des Verstehens lediglich nachbauen, doch die Teilnahme an Jugendforscht stellte sich dem Quer und das aus gutem Grund. Für meine privaten Ziele, des Verstehens hätte ein einfaches Nachbauen ausgereicht, doch durch die Teilnahme an Jugendforscht wollte ich etwas Eigenes auf die Beine stellen. Einfach etwas nachbauen kann jeder, auch wenn das Nachbauen und das tatsächliche Verstehen zwei unterschiedliche Dinge sind. So nahm ich mir stattdessen Sharmans Werk als Vorbild und baute darauf meinen eigenen Prozessor. Die Architektur[^2] mag ähnlich sein, doch meine bis zu dem Punkt entwickelten Architekturen wurden restlos übertroffen. So musste ich ein Kompromiss einschlagen. Ich nahm seine Architektur als Vorbild, veränderte sie und baute dann darauf auf. Ich wollte mich so weit wie möglich von ihm entfernen, doch die Genialität seiner Architektur beibehalten. So ist der Kern meines CPUs[^3] essenziell anders. Jedes Modul wurde von mir selbst entwickelt, simuliert, geplant und schließlich gebaut. Natürlich floss viel Inspiration von anderen in meine Kreation, doch ändert das nichts an der Tatsache, dass ich immense Zeit und stundenlanges Kopfzerbrechen in dieses Projekt investiert habe. Mein Ziel ist und bleibt das tiefgründige Verstehen eines Prozessors.

# 2. Vorgehens- und Funktionsweise

## 2.1 Entwürfe, Planung, Anfänge


Zunächst begann alles mit dem SAP-1. SAP steht für Simple as Possible eng. Für so einfach wie möglich. Der SAP-1 ist eine Prozessor Architektur, vorgestellt von Albert P. Malvino in seinem Buch Digital Computer Electronics. Der SAP-1 ist die simpelste Form eines Turing vollständigen Prozessors. Turing vollständig bedeutet die universelle Programmierbarkeit eines Systems benannt nach Alan Turing. Im Endeffekt ist das ein System, welches in der Lage ist sich selbst zu emulieren oder auch jede beliebige Berechnung zu tätigen, wenn sie unendlich Speicherplatz zur Verfügung hätte. Die dafür benötigte Zeit wird allerdings völlig außer Acht gelassen. Den SAP-1 nachzubauen war mein erstes Ziel und der erste Schritt zu einem näheren Verständnis eines Prozessors. Wenn man ihn verstanden hat, hat man die Grundlage jedes modernen Prozessors verstanden. Moderne Prozessoren können um ein Vielfaches komplexer sein, doch im Kern basieren sie auf das gleiche Prinzip, welches sich in dem Bild sehr gut veranschaulichen lässt. Es gibt eine Zentrale Einheit, die sog. Control Logic. Diese ist zuständig für die Erhaltung der Ordnung im System. Das macht sie, indem sie durch control lines Signale an die jeweiligen Module sendet. Das wiederum tut sie basierend auf eng. Instructions, Befehle, welche sie vom RAM[^4] bekommt.

Abbildung 1| SAP-1 Architektur

### 2.1.1 Dragon-1

Der SAP-1 war mein Einstieg in Prozessoren. Einmal verstanden, kann man von da aus weiter seinen Weg gehen und komplexere Themen anstreben. Der Dragon-1, der erste Entwurf, war im Prinzip nichts anderes als der SAP-1, mit ein paar erweiterten Funktionen. U.a. konnte die ALU[^5] mehrere Logische Operation, die die Ursprünge ALU des SAP-1 nicht konnte. Außerdem hatte der Dragon-1 mehr Register[^6] und vor allem ein Display. Mein Ziel war es damals ein Display anzuschließen, bei dem sich jeder einzelne Pixel steuern lässt. Auch wenn meine Pläne wahrscheinlich in der Theory funktioniert hätten, wären die Möglichkeiten sehr begrenzt gewesen. Der Dragon-1 lässt sich also als äußerst unpraktisch einstufen und wurde so schnell verworfen.

### 2.1.2 Dragon-2

Relativ schnell setzte ich mich schließlich an den Dragon-2. Hier lag der Fokus vor allem auf I/O-Handling[^7]. Der Dragon-2 hat dazu im Unterschied zum Dragon-1 eine vollständig selbst entwickelte Architektur und versucht Hardware-interrupts[^8] zu integrieren. Ich entwickelte von Grund auf selbst ein System um Interrupts zu Implementieren. Einer der größten unterschiede war aber wohl das Trennen vom Daten- und Programmspeicher und das hinzufügen eines 16-Bit Adress-busses. So ähnelt die Architektur der Harvard Architektur. Der Dragon-1 hingeben basierte auf der Von-Neumann Architektur, die einen gemeinsamen Bus für Adressen und Daten verwendet. Zu guter Letzt finden wir noch einen Stack, der z.B. für function-calling genutzt wird. Damit war der Dragon-2 eine wesentliche Weiterentwicklung gegenüber dem Dragon-1. Beim dem Dragon-2 wäre es wahrscheinlich auch geblieben, gäbe es nicht zwei Sachen, die mich umgestimmt haben. Einmal, war ich mir sehr unsicher bezüglich des I/O-Handling Systems. Ich hatte nicht die Zeit und die Mittel, um dieses System zu testen. Ich konnte mir nie sicher sein, dass es auch wirklich funktionieren würde. Man beachte, dass wir hier vor dem Zeitpunkt der Anmeldung an Jugendforscht reden. Zweitens entdeckte ich James Sharman, ein YouTuber, der seinen eigenen Prozessor nach dem Pipeline-Prinzip entwickelte.

### 2.1.3 Dragon-3, Pipeline

Eine Pipeline ist eine andere Art der Control Logic. Im Gegensatz zu multicycle Prozessoren werden hier mehrere Instructions gleichzeitig bearbeitet. Das führt dazu, dass sich die Zeit, die der Prozessor benötigt, um einen Befehl auszuführen, effektiv auf Dauer eines Taktes der Taktfrequenz verringert. Bei einem multicycle Prozessor benötigt eine Instruction meist mehrere Taktzyklen. Daher der Begriff multicycle. Mit der Pipeline liegt der größte Unterschied des Dragon-3 zum Dragon-2 aber in der Anzahl der Busse oder einfach gesagt in der Architektur generell. Diese ist wie bereits erwähnt stark inspiriert von James Sharman. Anstatt eines MARs[^9] haben wir einen 16-Bit Adress-Bus, auf dem mehrere Adress-Register ihre Daten ablegen können. Außerdem ist der Haupt-Bus (main bus), auf dem Daten wie Ergebnisse von Berechnungen übertragen werden getrennt von dem Speicher-Bus (memory bus), sodass sich gleichzeitig Daten sowie auch neue Instructions bewegen können. Zu guter Letzt kann jedes Register Daten an die ALU mit separaten ALU-Bussen (ALU-Left, ALU-Right) senden. Das alles hat den Vorteil von deutlich mehr Flexibilität und Parallelisierung von Prozessen. Um I/O zu unterstützen, muss man lediglich ein Gerät an den Haupt-Bus anschließen und durch etwa einen I/O-Handler steuern lassen. Theoretisch ginge das auch direkt über die Control Logic (CU oder CL), die Anzahl von verfügbaren control lines ist aber begrenzt. Nichtsdestotrotz gibt es einige Punkte, weshalb ich nicht bei dem Dragon-3 geblieben bin. Dar Hauptgrund ist wohl, die starke Ähnlichkeit zu James Sharmans CPU. Ein anderer Grund ist die wesentlich höhere Komplexität einer Pipeline. Zwar habe ich das Konzept einer Pipeline verstanden, jedoch würde es zu viel Zeit beanspruchen eine eigene zu entwickeln, wenn man im Hinterkopf hat, dass wir uns hier schon unmittelbar nach der Anmeldung an Jugendforscht befinden.

### 2.1.4 Dragon-4

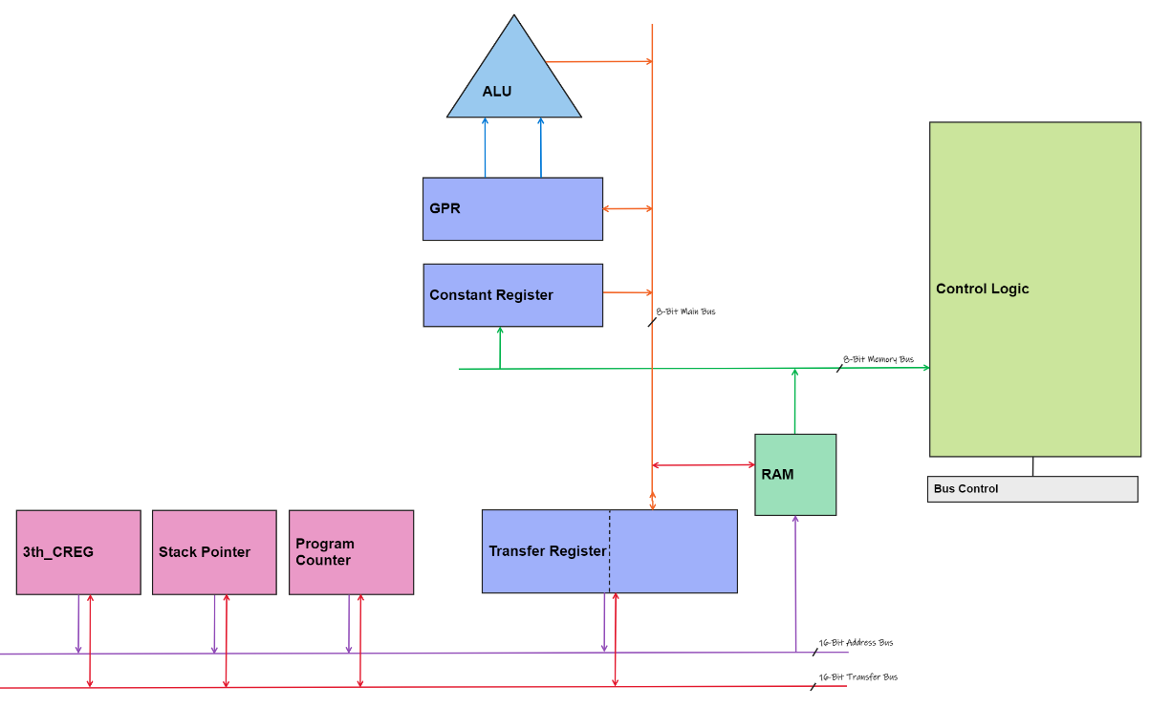
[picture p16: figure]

So befinden wir uns heute bei dem Dragon-4. Das Pipeline-Konzept, welches mich doch sehr inspiriert hat, wurde verworfen und wesentliche Änderungen an der Architektur vorgenommen.

Abbildung 2 | Dragon-4 Architektur

Unteranderem wurde die Anzahl der 16-Bit Register auf drei reduziert und vor allem eine direkte Möglichkeit des RAMs Daten auf den Haupt-Bus aufzulegen erschaffen. Gleichzeitig wurde die Anzahl an GPRs[^10] erhöht und die Bus-Bridge, die in der von Sharmans Ursprünglichen Architektur den Haupt Bus und den Speicherbus verbunden hat, herausgenommen. Diese ist nämlich keine Notwendigkeit und wird durch das Abschaffen der Pipeline sowie eine direkte Verbindung des RAMs zum Haupt Bus auch nicht mehr benötigt.

## 2.2 Vorgehensweise


Zunächst einmal muss man das Grundgerüst, die System Architektur bilden, um anzufangen einen Prozessor zu entwickeln. Da mir diese durch den Dragon-3 schon relativ klar war, fing ich direkt damit an und nutze das von Microsoft für Windows verfügbare Programm Whiteboard (siehe Abb. 2). Dort ist sozusagen das Grundgerüst entstanden. Natürlich muss einem vorher klar sein, was man erreichen möchte und was der Prozessor alles können soll, um darauf seine Architektur aufzubauen. Wichtig ist mir eine breite Anzahl an Funktionen, die der CPU leisten kann, sowie einfache Ein- und Ausgabe Möglichkeiten. Natürlich sollte er auch nicht zu langsam sein, um ein Minimalmaß an Nutzbarkeit zu erlangen. Für die Nutzbarkeit war vor allem ein breites Maß an Instructions notwendig. Jede Prozessorarchitektur hat seine eigene Programmiersprache, Instructions, mit dem sie arbeiten kann, die Assemblersprache. Die Assemblersprache steht direkt vor der Maschinensprache mit Einsen und Nullen und besteht aus einfachen Begriffen z.B. MOV A B. Intel Prozessoren haben eine andere Syntax als AMD, da sie direkt vom Prozessortyp abhängig ist. Deshalb gibt es für meinen Prozessor keine fertige Sprache, sondern muss erst entwickelt werden. Dazu fertigte ich eine große Excel-Tabelle mit allen verfügbaren, von mir definierten Befehlen an. Da der Dragon-4 ein 8-Bit Prozessor ist, unterstützt er genau 256 verschiedene Befehle. Als Inspiration habe ich mir dazu das reale Instruction-Set des x86 Prozessors angeschaut.

Abbildung 3 | Ausschnitt des Instruction Sets

### 2.2.1 Simulation

Da nun alle Grundeigenschaften gegeben waren, konnte ich mit der Entwicklung der einzelnen Module anfangen. Das allerdings im realen Leben zu tun ist kostspielig und aufwendig. Deshalb verwendete ich zunächst eine Logik-Simulationssoftware namens Logisim. Logisim ist ein großartiges Werkzeug, um Logikbausteine zu simulieren und zu testen. So habe ich sie zum Beispiel genutzt, um zu experimentieren welche Kombination von Logik Gattern ich benötige, um das gewünschte Ergebnis zu erhalten. Das hat mir das aufwendige Aufbauen und Verkabeln von realen Bauteilen erspart und den Prozess um einiges Beschleunigt. Schließlich habe ich den gesamten Prozessor simuliert, um sicherzugehen, dass er überhaupt funktionieren würde. Dabei sind einem viele Logik- und Denkfehler aufgefallen, die teilweise zu neuen Ideenanstöße geführt haben. Das alles, die Entwicklung des Prozessors in der Software, sowie das Ausmerzen von Fehlern und experimentieren beschreibt einen großen Teil der von mir investierten Zeit in das Projekt.

### 2.2.2 ROM-Programmierer

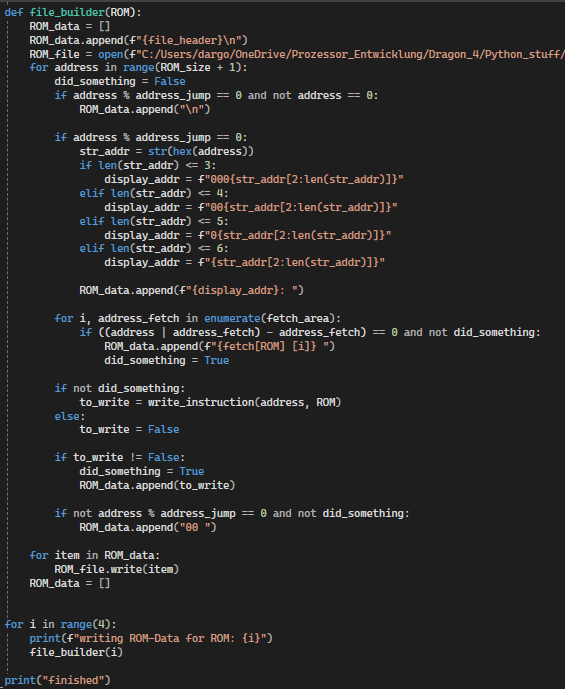
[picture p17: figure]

Um den CPU vollständig in der Logiksoftware zu testen, muss natürlich auch die Control Logic vollständig sein. Das Problem was sich hier aber auftut ist, dass die Control Logic aus ROMs[^11] besteht, die den gigantischen Dekodierer ersetzen, der ansonsten von Nöten wäre. Das interessante an einen ROM ist, dass man mit Speicherchips jegliche kombinierbare Logik ersetzen kann. Das mache ich mir hier zunutze, um nicht einen übermäßig großen Dekodierer bauen zu müssen. Dieser würde ansonsten jegliche Maße an Dimensionen sprengen. Nun müssen dazu aber vorher die ROMs mit Daten gefüllt werden. Die hier verwendeten ROMs haben 32000 mal 8 Bit Speicherplatz. Also 32000 Zeilen mit jeweils 8 Bit oder 1 Byte an Daten. Die Control Logic nutzt vier stück von diesen. Die Daten also von Hand einzutragen wäre nicht nur wahnsinnig, sondern auch noch eine große Zeitverschwendung. Dazu schrieb ich ein Programm in Python, welches für mich alle 32000 Zeilen an Daten füllt. Ich muss lediglich die 256 Instructions einmal von Hand in dem Programm definieren.

Abbildung 4 | Ausschnitt des "ROM-Programmierers"

### 2.2.3 PCB design


Nachdem die Simulation einwandfrei funktionierte, wurde es Zeit das Projekt in die Realität umzusetzen. Mir schien die Option das Ganze auf Platinen zu bauen effizienter und einfacher, als es mit handgefertigten Pantinen oder Breadboards zu versuchen. So arbeitete ich mit der PCB[^12]-Design Software Eagle um Schaltpläne des Dragon-4 zu erstellen und die PCBs zu designen. Dieser Prozess beanspruchte ebenfalls einen großen Teil meiner gesamt Investierten Zeit. Man beachte allerdings, dass „gesamt Investierte Zeit“ sich nur auf den Zeitraum von der Anmeldung bei Jugendforscht bis zur Fertigstellung des Projektes bezieht. Der Dragon-1 ist bereits zwei Jahre vorher entstanden. Über diese zwei Jahre verteilt wurde immens viel Zeit mit Recherche und Weiterbildung zu diesem Thema verbracht, sodass es schwierig ist, die gesamt Investierte Zeit zu schätzen.

Abbildung 5 | Physisches Layout vom Dragon-4

Bevor ich anfangen konnte, die PCBs zu designen oder die Schaltungen zu erstellen, musste ich mir erst über das Layout im Klaren werden. Hier stellte ich mir die Frage, wie soll der Prozessor später aussehen? Ich entschied mir für ein Modulares Design, da Fehler unausweichlich sind und so diese einfacher zu korrigieren sind und ein Modulares Design am meisten Flexibilität bietet. Ich kann einfach ein Fehlerhaftes Modul herausnehmen und mit einem neuen ersetzen. Die Tatsächlichen Maße weichen durch Weiterentwicklung während dem PCB design etwas ab, im Großen und Ganzen spiegelt Abbildung 5 aber sehr genau die Tatsächliche Größe wieder.


Nachdem das Layout stand, konnte ich anfangen die Module zu erstellen. Zunächst der Schaltplan, dann das PCB. Hier galt es allerdings einiges zu beachten. Zunächst einmal muss man schauen, wie man die Bauteile in der Simulation in einen Schaltplan überträgt, denn die Simulation bietet nur idealisierte Bauteile. Ich musste also durch Recherche Bauteile finden, die dieselbe Funktion haben, wie in der Simulation. Außerdem musste ich mich entscheiden, welche LEDs, welche Widerstände, welche Kondensatoren, welche Verbinder und noch vieles mehr ich nutzen möchte. Falls es diese dann nicht in dem Programm existieren, muss ich sie selbst erstellen. Zu beachtet gibt es hier auch Dinge wie z.B. Lieferzeiten von Bauteilen und Verfügbarkeit. Ist die Schaltung einmal fertig gestellt, kann es zum PCB-Design übergehen. Hier musste ich mich erst mit allgemeinen Designregeln beschäftigen wie zum Beispiel wann und wo man einen Kondensator platziert und lernen mit dem Programm umzugehen. Da ich ein Modulares Design verwende, muss es noch eine Grundplatte geben, die alles verbindet, das Motherboard. Nachdem alle Teile fertig designt waren, mussten diese lediglich von einem Platinen Hersteller gefertigt werden.

Abbildung 6 | Ausschnitt der Kontroll-Logik

### 2.2.4 Zusammenbau und Programmieren

Nach Anfertigen der Teileliste und deren bestellen. Steht nur noch das Zusammenfügen vor einem. Nach langem Löten, Fehler verbessern und debuggen ist der Prozessor fertig. Doch äußerst viel kann er in dem Zustand noch nicht, denn es müssen noch die ROMs, welche sich in der Kontroll-Logik befinden beschrieben werden. Hierfür nutze ich ein auf den vorherigen ROM-Programmierer basierenden selbst geschriebenes Programm, um die Daten für einen EEPROM-Programer[^13] zu erstellen. Mit diesem lässt sich dann so ein ROM sehr einfach Programmieren. War das getan, musste ich nur noch ein Programm in den RAM laden und schon konnte der Prozessor seiner Bestimmung nachgehen.

## 2.3 Funktionsweise

Die Funktionsweise in einem Umfang zu erklären, der nicht die Limitierungen dieser Facharbeit sprengen würde, ist schwierig, weshalb ich mich hier relativ kurzfasse.

Um die Funktionsweise des Dragon-4 zu verstehen, ist ein gewisses Grundwissen vonnöten. Dieses erläutert man am besten anhand des SAP-1. Immerhin ist der SAP-1 so einfach wie nur irgendwie möglich aufgebaut. Um den folgenden Erklärungen besser zu folgen, ist auf der nächsten Seite wieder die Architektur des SAP-1, nur dieses Mal etwas größer, abgebildet.

### 2.3.1 Clock

Die Clock ist wohl das simpelste Bauteil eines jeden Prozessors. Die Clock ist dazu zuständig, nach einem definierten Zeitintervall periodisch ein Signal auszusenden. Dieses wird dazu verwendet den gesamten Prozessor zu synchronisieren, damit jedes Bauteil fehlerfrei miteinander kommunizieren kann. Die Frequenzen erreichen in modernen Prozessoren mehr als 4 GHz . Im Dragon-4 ist die Frequenz durch seine Größe und verwendeten Bauteile sehr begrenzt. Dadurch, dass das Clock-Modul noch nicht fertiggestellt wurde, wurden noch keine Hochgeschwindigkeitsversuche durchgeführt, ich rechne aber mit einer theoretischen maximalen Frequenz von 1Mhz .

### 2.3.2 Register

Das Register, ein fester Bestandteil eines jeden Prozessors, tut nichts anderes als in meinem Fall 1-2 Byte an Daten für spätere Wiederverwendung zu speichern. Anders als bei dem RAM, haben wir hier nur eine Zeile mit Daten. Wenn das Register ein Signal zum Speichern empfängt, wird bei dem nächsten Clock-Zyklus die Daten, die sich am angrenzenden Datenbus befinden gespeichert. Nach empfangen eines Ausgabe-Befehls wirft das Register seine Daten wieder auf den Datenbus.


### 2.3.3 PC (Program Counter)

Der program counter ist nichts anders als ein Register, welches die Fähigkeit hat, binär zu zählen. Auf Kommando erhöht es den Wert in seinem Register um eins. Das passiert genau nach jeder Instruction. So könnte man ihn auch Instruction Pointer nennen. Denn er zählt im Grunde nur mit, bei welchem Punkt wir uns im Programm befinden. Er zeigt auf die Adresse im RAM, bei der die nächste Instruction gespeichert ist, damit diese ausgeführt werden kann.

### 2.3.4 MAR (Memory Address Register)

Das MAR ist ein weiteres Register, welches die Aktuelle Adresse des RAMs speichert. Im SAP-1 wird der Inhalt des program counters in das MAR verschoben, um die aktuelle Adresse zu ändern. In meinem Prozessor gibt es direkt kein MAR. Hier wird der Inhalt des program counters so lange auf einen Adressbus ausgegeben, bis sie nicht mehr benötigt wird. Der Adressbus ist direkt mit dem RAM verbunden.

### 2.3.5 RAM

Abbildung 7 | SAP-1 Architektur

Der RAM ist einer der zentralen Komponenten. Er beinhaltet das Programm, welches wir ausführen möchten und so die Instructions, die dem Prozessor sagen, was er zu tun hat. RAMs können mehrere Hunderttausende Speicherbänke mit Datensätze beinhalten. Welche Speicherbank gerade ausgewählt ist, wird als Adresse bezeichnet. In meinem Fall besitzt der RAM 64000 Speicherbänke mit jeweils einem Byte, also 8 Bit Daten. Der RAM kann seine Daten entweder auf einen BUS ausgeben, oder direkt der Kontroll-Logik überreichen.

Der RAM des Dragon-4 ist gleichzeitig der Stack. Der Stack wird zum function-calling verwendet. Die Besonderheit, dass der Stack in dem RAM integriert ist, ist dass der Speicherplatz für beides, Stack und Programm variable ist. Wenn man nicht aufpasst, könnte man den einen Bereich mit dem anderen überschreiben, andererseits hat es den Vorteil, dass man wenn man mehr RAM braucht einfach mehr nutzten kann.

### 2.3.6 Control Logic

Die Kontroll-Logik ist das Herz eines jeden Prozessors. Ohne sie, wäre er nicht funktionsfähig. Die Kontroll-Logik nimmt sich eine Instruction, welche sie von einem Instruction Register oder dem RAM bekommt und sagt dem ganzen Rest des CPUs, was er zu tun hat. Das macht sie mithilfe eines riesigen Dekodierers, der für jede Instruction einen Befehlssatz das sog. Control-word ausgibt.

### 2.3.7 ALU

Viele bezeichnen die ALU, Arithmetisch Logische Einheit als das Herz eines Prozessors, doch ohne die anderen Komponenten ist sie sehr nutzlos. Wie der Name bereits hergibt, nimmt sie ein oder mehrere Werte von z.B. dem A und B Register (siehe Abbildung 7) oder von einem Bus, wie in dem Dragon-4 und führt mit diesen Werten Arithmetische Operationen wie plus- oder minusrechnen oder logische sowie bitwise Operationen wie AND oder bit shifting durch.

### 2.3.8 IR (Instruction Register)

Das Instruction Register speichert die derzeitig bearbeitete Instruction, damit sie von der der Kontroll-Logik genutzt werden kann. Im Dragon-4 ist dieses in der Kontroll-Logik implementiert.

# 3. Ergebnisse

## 3.1 Probleme

Einen Prozessor zu entwickeln ist keine einfache Aufgabe. Das zeigte sich immer wieder während der Entwicklung, sowie auch während des Zusammenbauens. Fangen wir bei dem Dragon-3 an, der noch auf einer Pipeline basierte.

### 3.1.1 Pipeline

Die Pipeline ist ein geniales Konzept, welches die Nutzung von der internen Logik maximal optimiert. Doch mit der Genialität wächst auch die Komplexität. Eine Pipeline beinhaltet mehrere Stages, bei der eine Instruction jeweils unterschiedliche Control words lossenden muss. Fehler führen zu einem nicht ausführen einer Instruction oder das Fetchen[^14] einer nicht Instruction. Herauszufinden welche Control line, in welcher Pipeline stage wann aktiviert werden muss, war extrem anstrengend und hat einige Zeit beansprucht. Zu der ersten Ausführung eines Befehles, hat es sehr lange gedauert.

Die Entscheidung das Pipeline-Konzept zu verwerfen, hat alle Probleme des Dragon-3 hinfällig gemacht. Für die Komplexität einer Pipeline, war einfach nicht genügend Zeit vorhanden, nichtsdestotrotz habe ich das Konzept und die Funktionsweise einer Pipeline verstanden und zu verstehen sowie sich weiterzubilden ist der Hauptschwerpunkt meiner Motivation.

### 3.1.2 Simulation vs. Realität

In der Simulation gibt es Probleme, die man in der Realität nicht hat, in der Realität gibt es Probleme, die man in der Simulation nicht hat. Vereinfacht gesagt, Simulation und Realität sind etwas komplett Unterschiedliches. Mit einer Simulation kann man schließlich eine Realität nur nachahmen. Das hat unausweichlich zu einigen, teilweise fatalen, Problemen geführt. Zunächst einmal sind die Bauteile, die man in der Logik-Software verwenden konnte, nur idealisierte Bauelemente, die so in der Realität nicht existieren. Das brachte mich dazu reale Äquivalente zu finden, doch ist es nun mal so, dass es nicht immer welche gibt. So musste ich kreativ werden und nach weiteren Bauteilen suchen, die diese ersetzen können. Dabei sind einige Änderungen Im Schaltplan im Vergleich zu der Simulation entstanden. Ein Beispiel wäre, dass fast alle Control Lines, invertiert wurden. Das war aufgrund der Bauweise der Chips. Diese Tatsache führte zu einer meinen größten Problemen, denn invertiere Control Lines bedeutete eine teilweise komplett unterschiedliche Logik. In Kombination mit den Unterschiedlichen Bauteilen führte das dazu, dass die im Schaltplan verwendete Logik vollständig in meinem Kopf entstand und so viele Fehler enthielt. Erst einen Tag vor der Bestellung der Platinen vielen mir nochmal so viele Fehler auf, dass ich beschlossen habe, die Idealisierten Bauteile in der Simulation so anzupassen, dass sie der Realität entsprechen. So konnte ich nochmals einige fatale Fehler ausfindig machen und den Prozessor „realitätsnäher“ Simulieren.

### 3.1.3 Routing Probleme

Das ganze Verbessern der Fehler beinhaltet das Neurouten von den Leiterbahnen auf den Platinen. Auf kleineren Boards ist das kein Problem, doch auf größeren komplexeren, wie die ALU wird das sehr schnell sehr unübersichtlich und schwierig. Da auf solch einem Board teilweise über 300 Verbindungen getätigt werden müssen, benutzte ich einen Autorouter, der mir die Leiterbahnen automatisch nach einem Algorithmus verlegt. Man sollte lediglich gewisse Voreinstellungen wie Leiterbahndicke festlegen. SO schön das auch klingen mag, bei solch hochkomplexen Platinen benötigt der Autorouter teilweise stundenlange rechen Zeit und manchmal versagt er sogar, da es schlicht weg einfach unmöglich sein kann, auf so engen Platz so viele routen zu verlegen. Als Lösung arrangierte ich Bauteile neu und stellte die Leiterbahndicke niedriger, wobei man hier einen Kompromiss eingehen muss, denn so dünner die Bahnen, desto weniger Strom kann durch sie hindurchfließen. Die ALU erfolgreich zu routen hat dann schlussendlich mehrere Stunden gedauert.

### 3.1.4 „Fehler sind Menschlich“

Nach dem Bestellen und zusammenbauen, passierte erst einmal nichts. Natürlich mussten sich Fehler, die man nicht voraussehen konnte, einschleichen. Wer erwartet, dass etwas beim ersten Versuch funktioniert, ist leichtsinnig. Trotzdem beansprucht das Debuggen von Problemen immense Zeit und kann sehr frustrierend sein. Doch dadurch lernt man, was ein wichtiger Prozess des Lebens ist.

## 3.2 Leistung

Die Frage, was der Dragon-4 leisten kann ist eine schwierige, da ich noch nicht die Möglichkeit hatte ihn auf seine Höchstleistung zu testen. Fragt man mich aber was der Dragon-4 alles so kann, antworte ich alles. Das liegt daran, dass der Dragon-4 nach Alan Turing Turing Vollständig ist. D.h. er ist in der Lage jede beliebe Berechnung zu tätigen. Das beinhaltet auch hoch moderne Grafiken. Hätte der Prozessor eine Grafikkarte, wäre er auch in der Lage diese anzuzeigen. Das Problem ist nur, dass sich Turing Vollständig auf keine Zeit bezieht. Mein Prozessor könnte also unendlich lange Zeit für eine Berechnung benötigen, würde aber trotzdem als „Alleskönner“ eingestuft werden. Das heißt allerdings nicht, dass er langsam ist. Nach meinen Hypothesen sollte er bis zu einer Geschwindigkeit von 1Mhz laufen können. Limitiert wird er von der Geschwindigkeit der ROM-chips. Wenn eine Instruction durchschnittlich ca. 2 Zyklen benötigt, dann kann er bei einer Geschwindigkeit von 1Mhz 500.000 Instructions pro Sekunde verarbeiten.

(1Mhz)/2=500.000

Da eine Pipeline theoretisch pro Zyklus eine Instruction verarbeitet, ist diese in dem Fall doppelt so schnell. Realistisch würde ich allerdings die Geschwindigkeit meines Prozessors geringer schätzen.

Der Grund, weshalb moderne Prozessoren wesentlich schneller sind ist, da diese mikroskopisch klein sind, und so die Bauteile nah aneinander liegen. Außerdem verwenden Hersteller modernste Technologien, auf die ich keinen Zugriff habe.

Allgemeine Daten:

Anzahl Instructions | Durchschnittliche Länge der Instruction | Maximale Taktfrequenz | Speicherplatz
256 | 1,988 Zyklen | ca. 1Mhz | 65,536 KB

# 4. Ergebnisdiskussion

Allgemein bin ich sehr zufrieden mit meinem Prozessor, doch Pläne hatte ich noch viele mehr. Unter anderem wollte ich Ursprünglich eine Grafikkarte bauen, um die errechneten Ergebnisse zu visualisieren. Doch eine Grafikkarte ist kein einfaches Bauteil. Ich hätte wesentlich mehr Zeit benötigt, um eine Grafikkarte fertig zu stellen, vor allem da es für mich wichtig ist, dass ich keine fertigen Microcomputer für meinen CPU benutzte. Ich möchte alles von Grund auf selbst bauen. Das gleiche gilt für eine Soundkarte. I/O Handling war ein Ziel, welches ich Ursprünglich unbedingt implementiert haben wollte, doch auch hier viel die Zeit und vor allem das Abitur mir in den Rücken. Schließlich baute ich den Prozessor so, dass es theoretisch möglich wäre einen I/O-handler anzuschließen, sollte ich in Zukunft Zeit und Lust finden, diesen bauen zu wollen. Auch die Funktion durch eine Tastatur den Inhalt des RAMs zu verändern ist momentan noch nicht möglich, da ich die dazu fehlende Hardware nicht rechtzeitig fertig stellen konnte. Trotzdem habe ich auch hier vorausgeplant und die Module so entwickelt, dass man diese Hardware einfach dazu stellen könnte. Bisher muss man also den RAM herausnehmen und sein Programm extern über einen Computer eintragen.

Die Fehlende Erfahrung in den diversen Programmen haben mir einige Schwierigkeiten und Frust bereitet, doch letztendlich habe ich nur dazugelernt. Sollte ich erneut einen Prozessor bauen oder diesen weiterentwickeln, weiß ich wie. Vor allem das PCB design würde ich in Zukunft anders machen. Ich weiß zum Beispiel, dass man alle Bauteile nur auf die Oberfläche platzieren sollte, um sich eine Menge Arbeit und kosten bei der Produktion zu sparen. Rein theoretisch müsste es auch durch kleine Modifikationen möglich sein, das Pipeline-Konzept wieder einzuführen. Da der Prozessor sehr modular ist, kann man einfach Module austauschen. In dem Fall müsste man die gesamte Kontroll-Logik neu entwickeln. Das sind Dinge, die man sich in Zukunft vornehmen könnte.

Auch die nicht Fertigstellung des Clock-modules ärgert mich, da das ein fester Bestandteil eines jeden Prozessors ist. Allerdings hat auch hier die Zeit mir das nicht erlaubt, da ich mich hierzu erst ausführlicher mit Quarz-Crystalen müsste.

# 5. Zusammenfassung

Trotz all den unfertigen Modulen und Problemen bin ich sehr zufrieden. Dieses Projekt hat mir unglaublich viel Erfahrung in allen Teilbereichen eingebracht.

Vor allem das zu demselben Zeitpunkt immer näher Rückende Abitur hat mir besonders Kopfschmerzen und immensen Zeitdruck veranstaltet. Nichtsdestotrotz, war und ist meine Begeisterung für Technik und dem Forschen groß und hat schließlich dazu geführt, dass ich das Projekt rechtzeitig, nicht unbedingt abschließen, aber bis zu einen Zufriedenstellenden Punkt fertigstellen konnte. Mein Ziel, zu verstehen, habe ich erreicht. Ich verstehe nicht zu 50, sondern zu 100%, wie zumindest eine solch simple Form eines Prozessors funktioniert. Zu verstehen, ist nicht nur das Ziel dieses einen Projektes, sondern das Ziel mehrere Jahre Begeisterung für Digitaltechnik. Man könnte sogar noch weiter gehen und sagen, es war Ziel, seit Anbeginn meiner Kindheit, seit Anbeginn meiner Sehnsucht und Liebe nach Technik. Schon als kleines Kind wollte ich wissen, wie die Welt funktioniert. Seither strebt mich das an weiter zu forschen, weiter zu entdecken, zu erfinden, zu leben. Technik ist Teil meines Lebens und ich bin dankbar dafür. Doch Ende ist hier noch lange nicht. Wie in der Kurzfassung angedeutet, ist das hier nur der Anfang. Zu verstehen ist die Basis für alles Darauffolgende. Wenn man versteht, kann man kreieren, wenn man versteht, kann man weiterkommen. So will ich weiter verstehen, weiter streben nach Wissen, um immer höhere Horizonte zu erreichen. Ich bin dankbar für diese einzigartige Chance meinen Horizont zu erweitern und mir Wege für die Zukunft zu eröffnen. Dieses Projekt hat mir unglaublichen Spaß gemacht.

# 6. Quellenverzeichnis

- https://www.youtube.com/@weirdboyjim
- https://www.youtube.com/@BenEater
- Wikipedia, Turing Vollständigkeit, https://de.wikipedia.org/wiki/Turing-Vollständigkeit, zuletzt besucht am 12.02.2023
- Wikipedia, Instruction pipelining, https://en.wikipedia.org/wiki/Instruction_pipelining, zuletzt besucht am 12.02.2023
- Albert P. Malvino, Jerald A. Brown: „Digital Computer Electronics”, Kalifornien 1977
- Ben Eaters Video Reihe: „Building an 8-bit breadboard computer!”
- James Sharmans Video Reihe: „Making an 8 Bit pipelined CPU”

# 7. Unterstützungsleistung

Ich möchte meinen herzlichsten Dank an allen Personen ausrichten, die mich bei der Planung bis zur Realisierung dieses Projektes unterstützt haben.

Besonderes Dankeschön an:

- Wolfgang Schröder, für Ideenfindung und Wissensbereicherung
- Ben Eater, für den Einstieg in das Themenfeld der Funktionsweise von Prozessoren durch seine Video-Reihe
- James Sharman, für die Umfangreiche Ideenfindung und Wissensbereicherung, sowie Inspiration und Erläuterungen von komplexen Konzepten wie der Pipeline durch seine Video-Reihe

Und ganz besonders an:

Benjamin Brück,

für das in Kontakt bringen mit Jugendforscht, der finanziellen Unterstützung, das Bereitstellen diverser Materialien, Werkzeugen und Räumen und die Hilfestellung bei diversen Fragen

[^1] Siehe 2.2.3 Dragon-3, Pipeline
[^2] Architektur, hier: Aufbau eines Prozessors
[^3] CPU = Eng. Central Processing Unit | Prozessor
[^4] RAM = Random Access Memory | veränderbarer Speicherplatz für Daten
[^5] Arithmetic Logic Unit kurz ALU oder Arithmetisch Logische Einheit | Zuständig für Logische und Arithmetische Berechnungen.
[^6] Register | zuständig für Temporäres Speichern von Daten
[^7] I/O = Input Output | I/O-Handling meint das Unterstützen von Geräten wie Tastatur und Display
[^8] Unterbrechung des laufenden Programmes für z.B. eine Tastatureingabe
[^9] MAR = Memory Address Register | Speicherort für die Adresse des RAMs
[^10] GPR = General Purpose Register | Temporärer Speicherort für Daten
[^11] ROM = Read Only Memory | Speicherchip, von dem nur gelesen werden kann
[^12] PCB = Printed Circuit Board | Platine
[^13] EEPROM = Electrically Erasable Programmable Read-Only Memory | EEPROM-Programer werden genutzt, um EEPROMs zu beschreiben, obwohl sie eigentlich nur lesbar sind.
[^14] To fetch an instruction beschreibt den Prozess einen neuen Befehl in die Kontroll-Logik aufzunehmen, um ihn abzuarbeiten.

Seite 2 von 2

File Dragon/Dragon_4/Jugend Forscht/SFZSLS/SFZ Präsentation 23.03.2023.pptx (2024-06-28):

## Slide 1

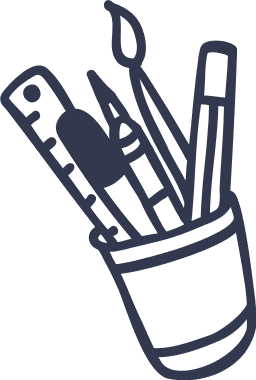
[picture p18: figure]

Der

Prozessor

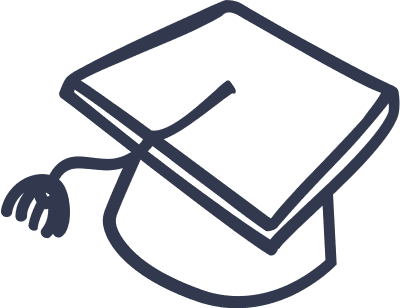
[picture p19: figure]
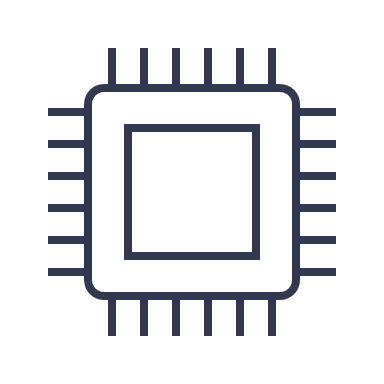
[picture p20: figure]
Prozessor Silhouette

One of the greatest achievements of mankind

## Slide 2

Ein Wunderwerk der Technik

> 1 Milliarde Transistoren

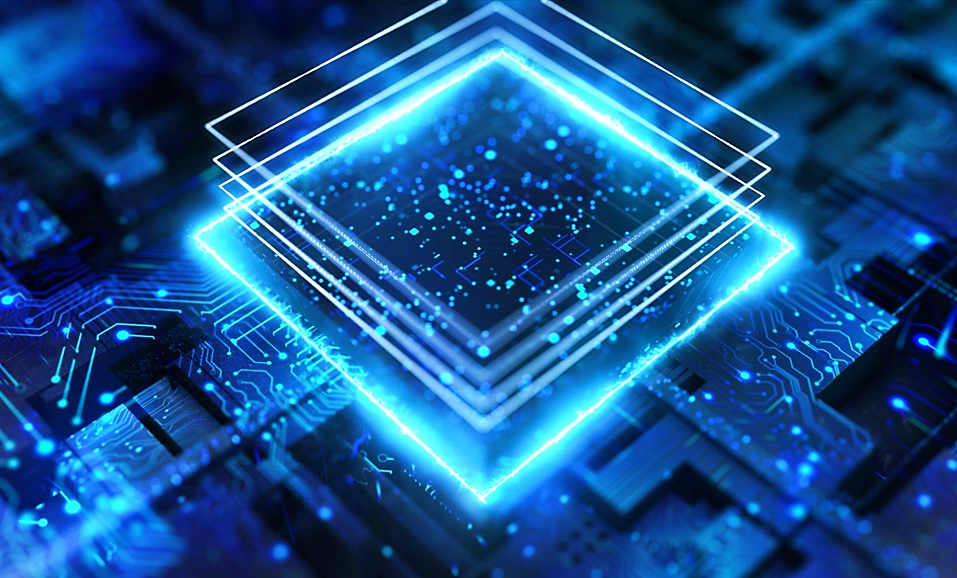
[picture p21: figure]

333 Millionen Transistoren pro mm²

128.300 MIPS (million instructions per second)

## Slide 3

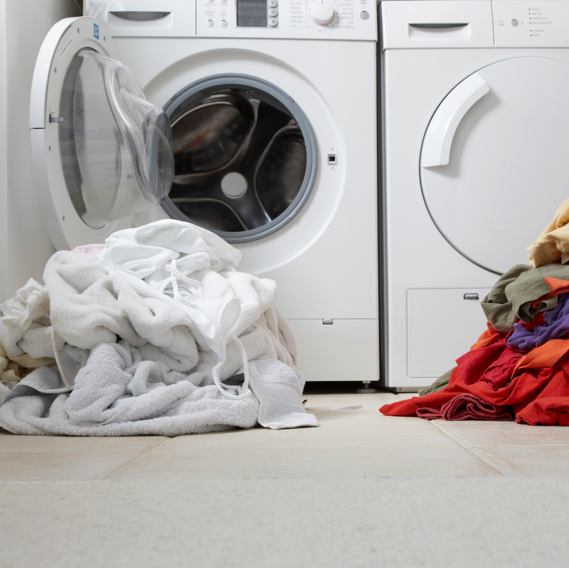
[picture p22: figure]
Wäscheraum mit Waschmaschinen und Kleidungsstücken

Alltag

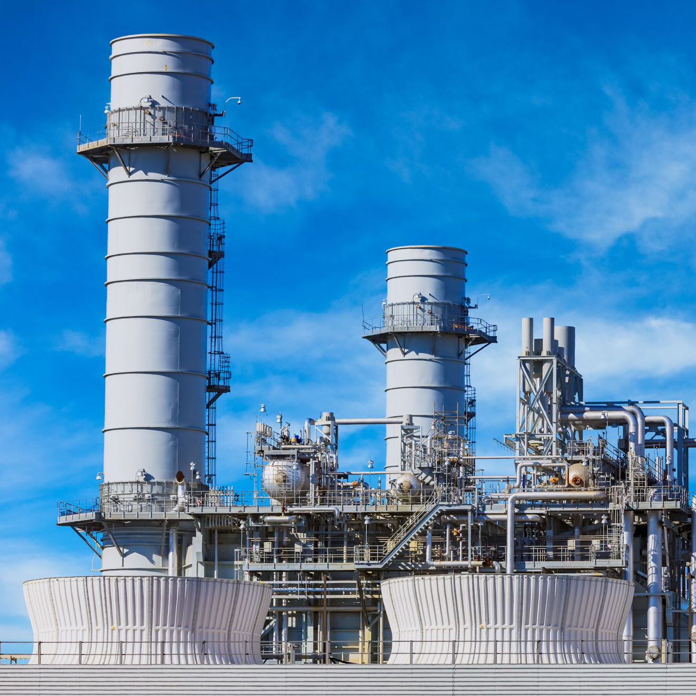
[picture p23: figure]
Erdgasbetriebenes Stromkraftwerk

Infrastruktur

Sie sind überall

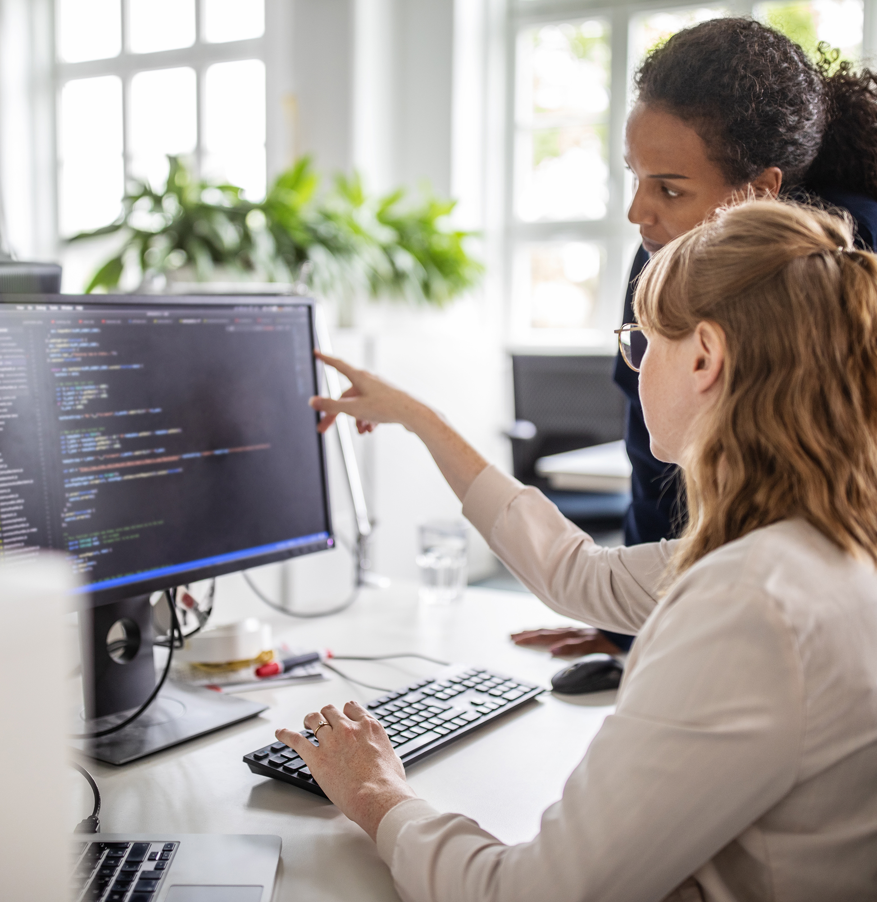
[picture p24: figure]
Personen, die am Computer arbeiten
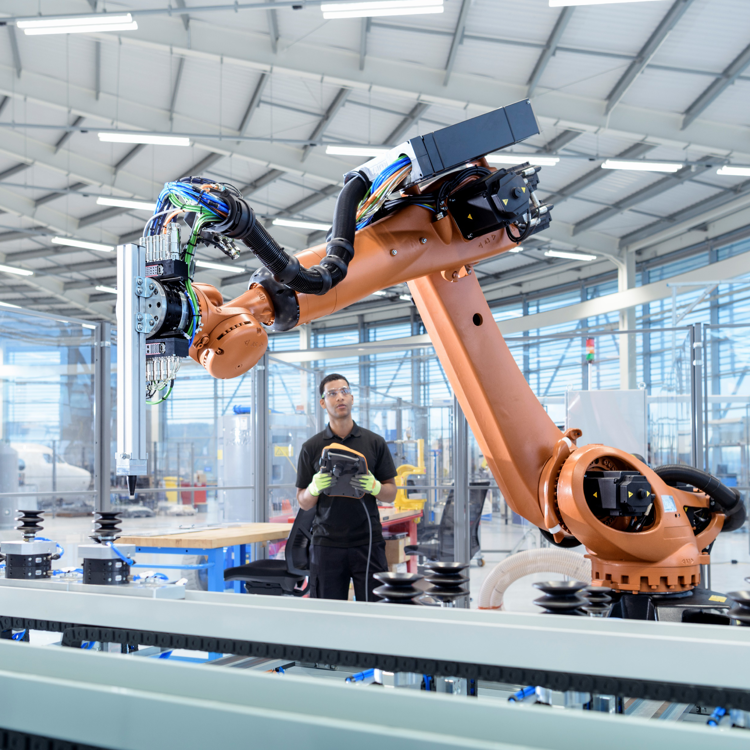
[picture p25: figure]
Ingenieurin, die einen Roboter in einer Robotik-Forschungseinrichtung programmiert

Wirtschaft

Beruf

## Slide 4

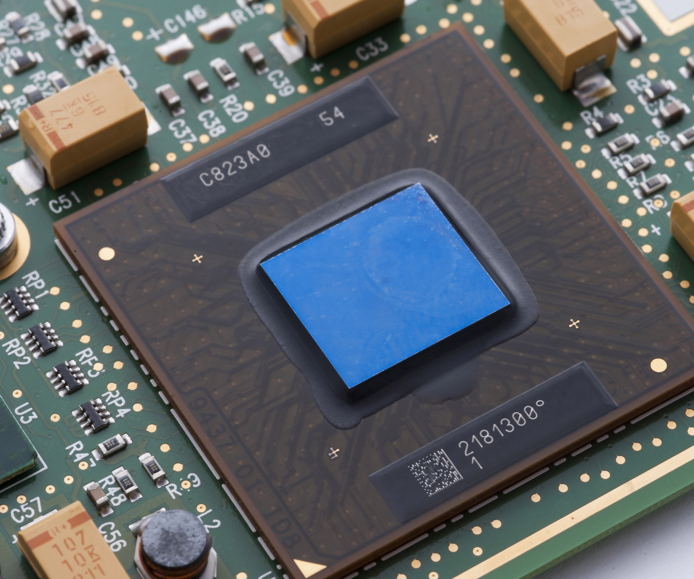
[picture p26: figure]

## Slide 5


Konrad Zuse

Pionier der Computergeschichte

Entwicklung der Z1, Z2 und Z3

Die Z3 war der erste funktionsfähige Digitalrechner weltweit.

Z3

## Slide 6

20


23

Netzteil (PCU)

Stellt den benötigten Strom zur Verfügung

Prozessor (CPU)

berechnen, koordinieren und ausführen von Befehlen und Daten

Grafikkarte (GPU)

Verarbeitet und stellt Grafiken dar

Arbeitsspeicher (RAM)

Schnelles zwischenspeichern von Daten

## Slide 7

20

Lupe

23

Prozessor (CPU)

berechnen, koordinieren und ausführen von Befehlen und Daten

CPU

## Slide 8

Introducing the
SAP-1

Der SAP-1 (Simple As Possible) entwickelt von Albert Paul Malvino ist dafür da, die absoluten Grundlagen eines Prozessors zu verstehen.
Jede höhere Stufe eines SAPs enthält komplexere Elemente, um einen schrittweise die Funktionsweise eines modernen Prozessors (CPU) zu erläutern.


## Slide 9

Die Register

Ein Register ist ein Ort, an dem sich ein Satz an Daten speichern lässt. Sie sind dazu da, um Daten zwischen zu speichern, damit sie anderweitig weiterverwendet werden können.


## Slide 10

Der Arbeitsspeicher

Der RAM (Random Access Memory) ist dazu dar, Daten zwischenzuspeichern. In ihm befindet sich das Programm, sowie auch einfache Werte.

Es gibt auch Architekturen, bei denen Programm- und Datenspeicher getrennt sind.

address

data

10011101
00110111
01010101
10101010
10110110
10101011
11110000
10101111

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
INPUT

0000

OUTPUT

10011101

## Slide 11

Der Arbeitsspeicher

Der RAM (Random Access Memory) ist dazu dar, Daten zwischenzuspeichern. In ihm befindet sich das Programm, sowie auch einfache Werte.

Es gibt auch Architekturen, bei denen Programm- und Datenspeicher getrennt sind.

address

data

10011101
00110111
01010101
10101010
10110110
10101011
11110000
10101111

INPUT

0001

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
OUTPUT

00110111

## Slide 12

Die ALU

Die Arithmetische Logische Einheit, ist dazu dar, arithmetische Operation wie plus oder minus oder auch logische Operationen wie and oder xor durchzuführen.


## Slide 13

Die Steuereinheit

Die CU (Control Logic) ist der wahre Mittelpunkt eines Prozessors. Sie steuert jedes Modul und passt auf, das es keine Komplikationen gibt.
Sie sagt z.B. der ALU, dass sie addieren soll.


Instruction Register

Step Counter

Befehls Dekodierer

Control Word

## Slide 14

PC_(out) | MAR_(in)

PC_(count) | RAM_(out) | IR_(in)

fetch

step 0

step 1

Die Steuereinheit

Die CU (Control Logic) ist der wahre Mittelpunkt eines Prozessors. Sie steuert jedes Modul und passt auf, das es keine Komplikationen gibt.
Sie sagt z.B. der ALU, dass sie addieren soll.

RAM_(out) | B_(in) | PC_(out) | OP:ADD

ALU_(out) | A_(in) | PC_(count)

instruction

step 2

RAM_(out) | A_(in) | PC_(count) | PC_(out)

step 4

step 3

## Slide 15

Vielen Dank!

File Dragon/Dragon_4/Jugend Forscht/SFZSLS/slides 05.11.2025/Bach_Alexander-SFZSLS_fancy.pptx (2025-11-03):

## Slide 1

>

Absolvierte am Oberstufenverbund Saarlouis das Abitur 2023

Belegte im selben Jahr den 1. Platz im Landeswettbewerb Jugendforscht

>

Alexander Bach


>

Das SFZSLS

- Erstkontakt über die Oberstufe
- Wichtige finanzielle und materielle Untersützung des Projektes
- Zugang zu diversen Laborressourcen

Studiert nun Informationssystemtechnik an der Technischen Universität Darmstadt

>

A desk with several computer monitors and a keyboard

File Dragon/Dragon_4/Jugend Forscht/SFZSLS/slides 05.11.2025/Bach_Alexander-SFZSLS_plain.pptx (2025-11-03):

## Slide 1

Bach Alexander

- Absolvierte am Oberstufenverbund Saarlouis das Abitur 2023
- Belegte im selben Jahr den 1. Platz im Landeswettbewerb Jugendforscht


- Studiert nun Informationssystemtechnik an der Technischen Universität Darmstadt
- Das SFZSLS
  - Erstkontakt über die Oberstufe
  - Wichtige finanzielle und materielle Unterstützung des Projektes
  - Zugang zu diversen Laborresourcen

A desk with several computer monitors and a keyboard

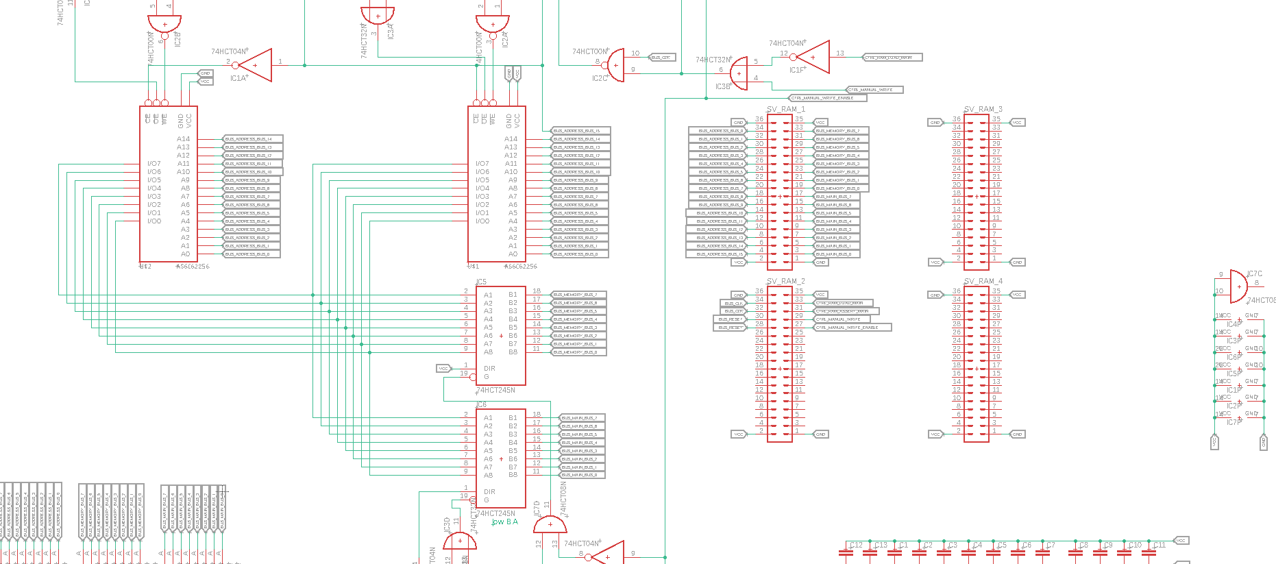
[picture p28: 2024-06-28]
Dragon/Dragon_4/Jugend Forscht/Jugend Forscht/RAM-schematic_screenshot.png

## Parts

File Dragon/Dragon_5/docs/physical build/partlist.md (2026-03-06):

## IC's

| part | quant. | cost | total | descrip. |
| --- | --- | --- | --- | --- |
| IS61C6416AL-12TLI | 10 | 2,25 € | 21,03 € | 64Kx16 **sram** |
| | | | | |

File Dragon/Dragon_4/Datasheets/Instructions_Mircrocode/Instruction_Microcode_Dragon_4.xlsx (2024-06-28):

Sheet: Instructions
Instructions |  |  |  |  |  |  |  |  |  |  |  |  |  |  |  |  |  |  |  |  |  |  |  |  |  |  |  |  |  |  |  |  |  |  |  |  |  |  |  |  | Instructions
Flags | OP-Code | Instruction |  |  | OP-Code | 32 | 31 | 30 | 29 | 28 | 27 | 26 | 25 | 24 | 23 | 22 | 21 | 20 | 19 | 18 | 17 | 16 | 15 | 14 | 13 | 12 | 11 | 10 | 9 | 8 | 7 | 6 | 5 | 4 | 3 | 2 | 1 | Step | Memlayout | address | OP-Code | Instruction |  |  | OP-Code | 32 | 31 | 30 | 29 | 28 | 27 | 26 | 25 | 24 | 23 | 22 | 21 | 20
xxxx | 0x00 | NOP |  |  | 0000 |  |  |  |  |  |  |  |  |  |  |  |  |  |  |  |  |  |  |  |  | 12 |  |  |  |  |  |  |  |  |  |  |  | 001 | OP-Code | 0 | 80 | ADD | A | B | 10000000 |  |  |  |  |  |  |  |  |  |  |  | 21
 |  |  |  |  |  | 32 |  |  |  |  |  |  |  |  |  |  |  |  |  |  |  |  |  |  |  |  |  |  |  |  |  |  |  |  |  |  |  | 010
xxxx | 0x01 | MOV | A | const. | 0001 |  |  |  |  |  |  |  |  |  |  |  |  |  |  |  |  |  |  |  |  | 12 |  |  |  |  |  |  |  |  |  |  |  | 001 | OP-Code | 0 |  |  |  |  |  | 32
 |  |  |  |  |  |  |  |  |  |  |  |  |  |  |  |  |  |  |  |  |  |  |  |  |  | 12 |  |  | 9 |  |  |  | 5 | 4 |  | 2 |  | 010 | const. | 1 | 81 | ADD | A | C | 10000001 |  |  |  |  |  |  |  |  |  |  |  | 21 | 20
 |  |  |  |  |  | 32 |  |  |  |  |  |  |  |  |  |  |  |  |  |  |  |  |  |  |  |  |  |  |  |  |  |  |  |  |  |  |  | 011
xxxx | 0x02 | MOV | B | const. | 0010 |  |  |  |  |  |  |  |  |  |  |  |  |  |  |  |  |  |  |  |  | 12 |  |  |  |  |  |  |  |  |  |  |  | 001 | OP-Code | 0 |  |  |  |  |  | 32
 |  |  |  |  |  |  |  |  |  |  |  |  |  |  |  |  |  |  |  |  |  |  |  |  |  | 12 |  |  | 9 |  |  | 6 |  | 4 |  | 2 |  | 010 | const. | 1 | 82 | ADD | A | D | 10000010 |  |  |  |  |  |  |  |  |  |  | 22
 |  |  |  |  |  | 32 |  |  |  |  |  |  |  |  |  |  |  |  |  |  |  |  |  |  |  |  |  |  |  |  |  |  |  |  |  |  |  | 011
xxxx | 0x03 | MOV | C | const. | 0011 |  |  |  |  |  |  |  |  |  |  |  |  |  |  |  |  |  |  |  |  | 12 |  |  |  |  |  |  |  |  |  |  |  | 001 | OP-Code | 0 |  |  |  |  |  | 32
 |  |  |  |  |  |  |  |  |  |  |  |  |  |  |  |  |  |  |  |  |  |  |  |  |  | 12 |  |  | 9 |  |  | 6 | 5 | 4 |  | 2 |  | 010 | const. | 1 | 83 | ADD | A | X | 10000011 |  |  |  |  |  |  |  |  |  |  | 22 |  | 20
 |  |  |  |  |  | 32 |  |  |  |  |  |  |  |  |  |  |  |  |  |  |  |  |  |  |  |  |  |  |  |  |  |  |  |  |  |  |  | 011
xxxx | 0x04 | MOV | D | const. | 0100 |  |  |  |  |  |  |  |  |  |  |  |  |  |  |  |  |  |  |  |  | 12 |  |  |  |  |  |  |  |  |  |  |  | 001 | OP-Code | 0 |  |  |  |  |  | 32
 |  |  |  |  |  |  |  |  |  |  |  |  |  |  |  |  |  |  |  |  |  |  |  |  |  | 12 |  |  | 9 |  | 7 |  |  | 4 |  | 2 |  | 010 | const. | 1 | 84 | ADD | B | C | 10000100 |  |  |  |  |  |  |  |  |  |  |  | 21 | 20
 |  |  |  |  |  | 32 |  |  |  |  |  |  |  |  |  |  |  |  |  |  |  |  |  |  |  |  |  |  |  |  |  |  |  |  |  |  |  | 011
xxxx | 5 | MOV | X | const. | 0101 |  |  |  |  |  |  |  |  |  |  |  |  |  |  |  |  |  |  |  |  | 12 |  |  |  |  |  |  |  |  |  |  |  | 001 | OP-Code | 0 |  |  |  |  |  | 32
 |  |  |  |  |  |  |  |  |  |  |  |  |  |  |  |  |  |  |  |  |  |  |  |  |  | 12 |  |  | 9 |  | 7 |  | 5 | 4 |  | 2 |  | 010 | const. | 1 | 85 | ADD | B | D | 10000101 |  |  |  |  |  |  |  |  |  |  | 22
 |  |  |  |  |  | 32 |  |  |  |  |  |  |  |  |  |  |  |  |  |  |  |  |  |  |  |  |  |  |  |  |  |  |  |  |  |  |  | 011
xxxx | 6 | MOV | Xfer_R | const. | 0110 |  |  |  |  |  |  |  |  |  |  |  |  |  |  |  |  |  |  |  |  | 12 |  |  |  |  |  |  |  |  |  |  |  | 001 | OP-Code | 0 |  |  |  |  |  | 32
 |  |  |  |  |  |  |  |  |  |  |  |  |  |  |  |  |  |  |  |  |  |  |  |  |  | 12 |  |  | 9 | 8 | 7 |  | 5 | 4 |  | 2 |  | 010 | const. | 1 | 86 | ADD | B | X | 10000110 |  |  |  |  |  |  |  |  |  |  | 22 |  | 20
 |  |  |  |  |  | 32 |  |  |  |  |  |  |  |  |  |  |  |  |  |  |  |  |  |  |  |  |  |  |  |  |  |  |  |  |  |  |  | 011
xxxx | 7 | MOV | Xfer_L | const. | 0111 |  |  |  |  |  |  |  |  |  |  |  |  |  |  |  |  |  |  |  |  | 12 |  |  |  |  |  |  |  |  |  |  |  | 001 | OP-Code | 0 |  |  |  |  |  | 32
 |  |  |  |  |  |  |  |  |  |  |  |  |  |  |  |  |  |  |  |  |  |  |  |  |  | 12 |  |  | 9 | 8 | 7 | 6 |  | 4 |  | 2 |  | 010 | const. | 1 | 87 | ADD | C | D | 10000111 |  |  |  |  |  |  |  |  |  |  | 22
 |  |  |  |  |  | 32 |  |  |  |  |  |  |  |  |  |  |  |  |  |  |  |  |  |  |  |  |  |  |  |  |  |  |  |  |  |  |  | 011
xxxx | 8 | MOV | A | B | 1000 |  |  |  |  |  |  |  |  |  |  |  |  |  |  |  |  |  |  |  |  | 12 |  |  |  |  |  |  | 5 |  |  | 2 |  | 001 | OP-Code | 0 |  |  |  |  |  | 32
 |  |  |  |  |  | 32 |  |  |  |  |  |  |  |  |  |  |  |  |  |  |  |  |  |  |  |  |  |  |  |  |  |  |  |  |  |  |  | 010 |  |  | 88 | ADD | C | X | 10001000 |  |  |  |  |  |  |  |  |  |  | 22 |  | 20
xxxx | 9 | MOV | A | C | 1001 |  |  |  |  |  |  |  |  |  |  |  |  |  |  |  |  |  |  |  |  | 12 |  |  |  |  |  |  | 5 |  |  | 2 | 1 | 001 | OP-Code | 0
 |  |  |  |  |  | 32 |  |  |  |  |  |  |  |  |  |  |  |  |  |  |  |  |  |  |  |  |  |  |  |  |  |  |  |  |  |  |  | 010 |  |  |  |  |  |  |  | 32
xxxx | 0x0a | MOV | A | D | 1010 |  |  |  |  |  |  |  |  |  |  |  |  |  |  |  |  |  |  |  |  | 12 |  |  |  |  |  |  | 5 |  | 3 |  |  | 001 | OP-Code | 0 | 89 | ADD | D | X | 10001001 |  |  |  |  |  |  |  |  |  |  | 22 |  | 20
 |  |  |  |  |  | 32 |  |  |  |  |  |  |  |  |  |  |  |  |  |  |  |  |  |  |  |  |  |  |  |  |  |  |  |  |  |  |  | 010
xxxx | 0x0b | MOV | A | X | 1011 |  |  |  |  |  |  |  |  |  |  |  |  |  |  |  |  |  |  |  |  | 12 |  |  |  |  |  |  | 5 |  | 3 |  | 1 | 001 | OP-Code | 0 |  |  |  |  |  | 32
 |  |  |  |  |  | 32 |  |  |  |  |  |  |  |  |  |  |  |  |  |  |  |  |  |  |  |  |  |  |  |  |  |  |  |  |  |  |  | 010 |  |  | 0x8a | ADC | A | B | 10001010 |  |  |  |  |  |  |  | 25 |  |  |  | 21
xxxx | 0x0c | MOV | A | Xfer_R | 1100 |  |  |  |  |  |  |  |  |  |  |  |  |  |  |  |  |  |  |  |  | 12 |  |  |  |  |  |  | 5 | 4 | 3 |  | 1 | 001 | OP-Code | 0
 |  |  |  |  |  | 32 |  |  |  |  |  |  |  |  |  |  |  |  |  |  |  |  |  |  |  |  |  |  |  |  |  |  |  |  |  |  |  | 010 |  |  |  |  |  |  |  | 32
xxxx | 0x0d | MOV | A | Xfer_L | 1101 |  |  |  |  |  |  |  |  |  |  |  |  |  |  |  |  |  |  |  |  | 12 |  |  |  |  |  |  | 5 | 4 | 3 | 2 |  | 001 | OP-Code | 0 | 0x8b | ADC | A | C | 10001011 |  |  |  |  |  |  |  | 25 |  |  |  | 21 | 20
 |  |  |  |  |  | 32 |  |  |  |  |  |  |  |  |  |  |  |  |  |  |  |  |  |  |  |  |  |  |  |  |  |  |  |  |  |  |  | 010
xxxx | 0x0e | MOV | B | A | 1110 |  |  |  |  |  |  |  |  |  |  |  |  |  |  |  |  |  |  |  |  | 12 |  |  |  |  |  | 6 |  |  |  |  | 1 | 001 | OP-Code | 0 |  |  |  |  |  | 32
 |  |  |  |  |  | 32 |  |  |  |  |  |  |  |  |  |  |  |  |  |  |  |  |  |  |  |  |  |  |  |  |  |  |  |  |  |  |  | 010 |  |  | 0x8c | ADC | A | D | 10001100 |  |  |  |  |  |  |  | 25 |  |  | 22
xxxx | 0x0f | MOV | B | C | 1111 |  |  |  |  |  |  |  |  |  |  |  |  |  |  |  |  |  |  |  |  | 12 |  |  |  |  |  | 6 |  |  |  | 2 | 1 | 001 | OP-Code | 0
 |  |  |  |  |  | 32 |  |  |  |  |  |  |  |  |  |  |  |  |  |  |  |  |  |  |  |  |  |  |  |  |  |  |  |  |  |  |  | 010 |  |  |  |  |  |  |  | 32
xxxx | 0x10 | MOV | B | D | 10000 |  |  |  |  |  |  |  |  |  |  |  |  |  |  |  |  |  |  |  |  | 12 |  |  |  |  |  | 6 |  |  | 3 |  |  | 001 | OP-Code | 0 | 0x8d | ADC | A | X | 10001101 |  |  |  |  |  |  |  | 25 |  |  | 22 |  | 20
 |  |  |  |  |  | 32 |  |  |  |  |  |  |  |  |  |  |  |  |  |  |  |  |  |  |  |  |  |  |  |  |  |  |  |  |  |  |  | 010
xxxx | 11 | MOV | B | X | 10001 |  |  |  |  |  |  |  |  |  |  |  |  |  |  |  |  |  |  |  |  | 12 |  |  |  |  |  | 6 |  |  | 3 |  | 1 | 001 | OP-Code | 0 |  |  |  |  |  | 32
 |  |  |  |  |  | 32 |  |  |  |  |  |  |  |  |  |  |  |  |  |  |  |  |  |  |  |  |  |  |  |  |  |  |  |  |  |  |  | 010 |  |  | 0x8e | ADC | B | C | 10001110 |  |  |  |  |  |  |  | 25 |  |  |  | 21 | 20
xxxx | 12 | MOV | B | Xfer_R | 10010 |  |  |  |  |  |  |  |  |  |  |  |  |  |  |  |  |  |  |  |  | 12 |  |  |  |  |  | 6 |  | 4 | 3 |  | 1 | 001 | OP-Code | 0
 |  |  |  |  |  | 32 |  |  |  |  |  |  |  |  |  |  |  |  |  |  |  |  |  |  |  |  |  |  |  |  |  |  |  |  |  |  |  | 010 |  |  |  |  |  |  |  | 32
xxxx | 13 | MOV | B | Xfer_L | 10011 |  |  |  |  |  |  |  |  |  |  |  |  |  |  |  |  |  |  |  |  | 12 |  |  |  |  |  | 6 |  | 4 | 3 | 2 |  | 001 | OP-Code | 0 | 0x8f | ADC | B | D | 10001111 |  |  |  |  |  |  |  | 25 |  |  | 22
 |  |  |  |  |  | 32 |  |  |  |  |  |  |  |  |  |  |  |  |  |  |  |  |  |  |  |  |  |  |  |  |  |  |  |  |  |  |  | 010
xxxx | 14 | MOV | C | A | 10100 |  |  |  |  |  |  |  |  |  |  |  |  |  |  |  |  |  |  |  |  | 12 |  |  |  |  |  | 6 | 5 |  |  |  | 1 | 001 | OP-Code | 0 |  |  |  |  |  | 32
 |  |  |  |  |  | 32 |  |  |  |  |  |  |  |  |  |  |  |  |  |  |  |  |  |  |  |  |  |  |  |  |  |  |  |  |  |  |  | 010 |  |  | 90 | ADC | B | X | 10010000 |  |  |  |  |  |  |  | 25 |  |  | 22 |  | 20
xxxx | 15 | MOV | C | B | 10101 |  |  |  |  |  |  |  |  |  |  |  |  |  |  |  |  |  |  |  |  | 12 |  |  |  |  |  | 6 | 5 |  |  | 2 |  | 001 | OP-Code | 0
 |  |  |  |  |  | 32 |  |  |  |  |  |  |  |  |  |  |  |  |  |  |  |  |  |  |  |  |  |  |  |  |  |  |  |  |  |  |  | 010 |  |  |  |  |  |  |  | 32
xxxx | 16 | MOV | C | D | 10110 |  |  |  |  |  |  |  |  |  |  |  |  |  |  |  |  |  |  |  |  | 12 |  |  |  |  |  | 6 | 5 |  | 3 |  |  | 001 | OP-Code | 0 | 91 | ADC | C | D | 10010001 |  |  |  |  |  |  |  | 25 |  |  | 22
 |  |  |  |  |  | 32 |  |  |  |  |  |  |  |  |  |  |  |  |  |  |  |  |  |  |  |  |  |  |  |  |  |  |  |  |  |  |  | 010
xxxx | 17 | MOV | C | X | 10111 |  |  |  |  |  |  |  |  |  |  |  |  |  |  |  |  |  |  |  |  | 12 |  |  |  |  |  | 6 | 5 |  | 3 |  | 1 | 001 | OP-Code | 0 |  |  |  |  |  | 32
 |  |  |  |  |  | 32 |  |  |  |  |  |  |  |  |  |  |  |  |  |  |  |  |  |  |  |  |  |  |  |  |  |  |  |  |  |  |  | 010 |  |  | 92 | ADC | C | X | 10010010 |  |  |  |  |  |  |  | 25 |  |  | 22 |  | 20
xxxx | 18 | MOV | C | Xfer_R | 11000 |  |  |  |  |  |  |  |  |  |  |  |  |  |  |  |  |  |  |  |  | 12 |  |  |  |  |  | 6 | 5 | 4 | 3 |  | 1 | 001 | OP-Code | 0
 |  |  |  |  |  | 32 |  |  |  |  |  |  |  |  |  |  |  |  |  |  |  |  |  |  |  |  |  |  |  |  |  |  |  |  |  |  |  | 010 |  |  |  |  |  |  |  | 32
xxxx | 19 | MOV | C | Xfer_L | 11001 |  |  |  |  |  |  |  |  |  |  |  |  |  |  |  |  |  |  |  |  | 12 |  |  |  |  |  | 6 | 5 | 4 | 3 | 2 |  | 001 | OP-Code | 0 | 93 | ADC | D | X | 10010011 |  |  |  |  |  |  |  | 25 |  |  | 22 |  | 20
 |  |  |  |  |  | 32 |  |  |  |  |  |  |  |  |  |  |  |  |  |  |  |  |  |  |  |  |  |  |  |  |  |  |  |  |  |  |  | 010
xxxx | 0x1a | MOV | D | A | 11010 |  |  |  |  |  |  |  |  |  |  |  |  |  |  |  |  |  |  |  |  | 12 |  |  |  |  | 7 |  |  |  |  |  | 1 | 001 | OP-Code | 0 |  |  |  |  |  | 32
 |  |  |  |  |  | 32 |  |  |  |  |  |  |  |  |  |  |  |  |  |  |  |  |  |  |  |  |  |  |  |  |  |  |  |  |  |  |  | 010 |  |  | 94 | SUB | A | B | 10010100 |  |  |  |  |  |  | 26 |  |  |  |  | 21
xxxx | 0x1b | MOV | D | B | 11011 |  |  |  |  |  |  |  |  |  |  |  |  |  |  |  |  |  |  |  |  | 12 |  |  |  |  | 7 |  |  |  |  | 2 |  | 001 | OP-Code | 0
 |  |  |  |  |  | 32 |  |  |  |  |  |  |  |  |  |  |  |  |  |  |  |  |  |  |  |  |  |  |  |  |  |  |  |  |  |  |  | 010 |  |  |  |  |  |  |  | 32
xxxx | 0x1c | MOV | D | C | 11100 |  |  |  |  |  |  |  |  |  |  |  |  |  |  |  |  |  |  |  |  | 12 |  |  |  |  | 7 |  |  |  |  | 2 | 1 | 001 | OP-Code | 0 | 95 | SUB | A | C | 10010101 |  |  |  |  |  |  | 26 |  |  |  |  | 21 | 20
 |  |  |  |  |  | 32 |  |  |  |  |  |  |  |  |  |  |  |  |  |  |  |  |  |  |  |  |  |  |  |  |  |  |  |  |  |  |  | 010
xxxx | 0x1d | MOV | D | X | 11101 |  |  |  |  |  |  |  |  |  |  |  |  |  |  |  |  |  |  |  |  | 12 |  |  |  |  | 7 |  |  |  | 3 |  | 1 | 001 | OP-Code | 0 |  |  |  |  |  | 32
 |  |  |  |  |  | 32 |  |  |  |  |  |  |  |  |  |  |  |  |  |  |  |  |  |  |  |  |  |  |  |  |  |  |  |  |  |  |  | 010 |  |  | 96 | SUB | A | D | 10010110 |  |  |  |  |  |  | 26 |  |  |  | 22
xxxx | 0x1e | MOV | D | Xfer_R | 11110 |  |  |  |  |  |  |  |  |  |  |  |  |  |  |  |  |  |  |  |  | 12 |  |  |  |  | 7 |  |  | 4 | 3 |  | 1 | 001 | OP-Code | 0
 |  |  |  |  |  | 32 |  |  |  |  |  |  |  |  |  |  |  |  |  |  |  |  |  |  |  |  |  |  |  |  |  |  |  |  |  |  |  | 010 |  |  |  |  |  |  |  | 32
xxxx | 0x1f | MOV | D | Xfer_L | 11111 |  |  |  |  |  |  |  |  |  |  |  |  |  |  |  |  |  |  |  |  | 12 |  |  |  |  | 7 |  |  | 4 | 3 | 2 |  | 001 | OP-Code | 0 | 97 | SUB | A | X | 10010111 |  |  |  |  |  |  | 26 |  |  |  | 22 |  | 20
 |  |  |  |  |  | 32 |  |  |  |  |  |  |  |  |  |  |  |  |  |  |  |  |  |  |  |  |  |  |  |  |  |  |  |  |  |  |  | 010
xxxx | 0x20 | MOV | X | A | 100000 |  |  |  |  |  |  |  |  |  |  |  |  |  |  |  |  |  |  |  |  | 12 |  |  |  |  | 7 |  | 5 |  |  |  | 1 | 001 | OP-Code | 0 |  |  |  |  |  | 32
 |  |  |  |  |  | 32 |  |  |  |  |  |  |  |  |  |  |  |  |  |  |  |  |  |  |  |  |  |  |  |  |  |  |  |  |  |  |  | 010 |  |  | 98 | SUB | B | A | 10011000 |  |  |  |  |  |  | 26 |  |  |  |  |  | 20
xxxx | 21 | MOV | X | B | 100001 |  |  |  |  |  |  |  |  |  |  |  |  |  |  |  |  |  |  |  |  | 12 |  |  |  |  | 7 |  | 5 |  |  | 2 |  | 001 | OP-Code | 0
 |  |  |  |  |  | 32 |  |  |  |  |  |  |  |  |  |  |  |  |  |  |  |  |  |  |  |  |  |  |  |  |  |  |  |  |  |  |  | 010 |  |  |  |  |  |  |  | 32
xxxx | 22 | MOV | X | C | 100010 |  |  |  |  |  |  |  |  |  |  |  |  |  |  |  |  |  |  |  |  | 12 |  |  |  |  | 7 |  | 5 |  |  | 2 | 1 | 001 | OP-Code | 0 | 99 | SUB | B | C | 10011001 |  |  |  |  |  |  | 26 |  |  |  |  | 21 | 20
 |  |  |  |  |  | 32 |  |  |  |  |  |  |  |  |  |  |  |  |  |  |  |  |  |  |  |  |  |  |  |  |  |  |  |  |  |  |  | 010
xxxx | 23 | MOV | X | D | 100011 |  |  |  |  |  |  |  |  |  |  |  |  |  |  |  |  |  |  |  |  | 12 |  |  |  |  | 7 |  | 5 |  | 3 |  |  | 001 | OP-Code | 0 |  |  |  |  |  | 32
 |  |  |  |  |  | 32 |  |  |  |  |  |  |  |  |  |  |  |  |  |  |  |  |  |  |  |  |  |  |  |  |  |  |  |  |  |  |  | 010 |  |  | 0x9a | SUB | B | D | 10011010 |  |  |  |  |  |  | 26 |  |  |  | 22
xxxx | 24 | MOV | X | Xfer_R | 100100 |  |  |  |  |  |  |  |  |  |  |  |  |  |  |  |  |  |  |  |  | 12 |  |  |  |  | 7 |  | 5 | 4 | 3 |  | 1 | 001 | OP-Code | 0
 |  |  |  |  |  | 32 |  |  |  |  |  |  |  |  |  |  |  |  |  |  |  |  |  |  |  |  |  |  |  |  |  |  |  |  |  |  |  | 010 |  |  |  |  |  |  |  | 32
xxxx | 25 | MOV | X | Xfer_L | 100101 |  |  |  |  |  |  |  |  |  |  |  |  |  |  |  |  |  |  |  |  | 12 |  |  |  |  | 7 |  | 5 | 4 | 3 | 2 |  | 001 | OP-Code | 0 | 0x9b | SUB | B | X | 10011011 |  |  |  |  |  |  | 26 |  |  |  | 22 |  | 20
 |  |  |  |  |  | 32 |  |  |  |  |  |  |  |  |  |  |  |  |  |  |  |  |  |  |  |  |  |  |  |  |  |  |  |  |  |  |  | 010
xxxx | 26 | MOV | Xfer_R | A | 100110 |  |  |  |  |  |  |  |  |  |  |  |  |  |  |  |  |  |  |  |  | 12 |  |  |  | 8 | 7 |  | 5 |  |  |  | 1 | 001 | OP-Code | 0 |  |  |  |  |  | 32
 |  |  |  |  |  | 32 |  |  |  |  |  |  |  |  |  |  |  |  |  |  |  |  |  |  |  |  |  |  |  |  |  |  |  |  |  |  |  | 010 |  |  | 0x9c | SUB | C | A | 10011100 |  |  |  |  |  |  | 26 |  |  |  |  |  | 20
xxxx | 27 | MOV | Xfer_R | B | 100111 |  |  |  |  |  |  |  |  |  |  |  |  |  |  |  |  |  |  |  |  | 12 |  |  |  | 8 | 7 |  | 5 |  |  | 2 |  | 001 | OP-Code | 0
 |  |  |  |  |  | 32 |  |  |  |  |  |  |  |  |  |  |  |  |  |  |  |  |  |  |  |  |  |  |  |  |  |  |  |  |  |  |  | 010 |  |  |  |  |  |  |  | 32
xxxx | 28 | MOV | Xfer_R | C | 101000 |  |  |  |  |  |  |  |  |  |  |  |  |  |  |  |  |  |  |  |  | 12 |  |  |  | 8 | 7 |  | 5 |  |  | 2 | 1 | 001 | OP-Code | 0 | 0x9d | SUB | C | B | 10011101 |  |  |  |  |  |  | 26 |  |  |  |  | 21
 |  |  |  |  |  | 32 |  |  |  |  |  |  |  |  |  |  |  |  |  |  |  |  |  |  |  |  |  |  |  |  |  |  |  |  |  |  |  | 010
xxxx | 29 | MOV | Xfer_R | D | 101001 |  |  |  |  |  |  |  |  |  |  |  |  |  |  |  |  |  |  |  |  | 12 |  |  |  | 8 | 7 |  | 5 |  | 3 |  |  | 001 | OP-Code | 0 |  |  |  |  |  | 32
 |  |  |  |  |  | 32 |  |  |  |  |  |  |  |  |  |  |  |  |  |  |  |  |  |  |  |  |  |  |  |  |  |  |  |  |  |  |  | 010 |  |  | 0x9e | SUB | C | D | 10011110 |  |  |  |  |  |  | 26 |  |  |  | 22
xxxx | 0x2a | MOV | Xfer_R | X | 101010 |  |  |  |  |  |  |  |  |  |  |  |  |  |  |  |  |  |  |  |  | 12 |  |  |  | 8 | 7 |  | 5 |  | 3 |  | 1 | 001 | OP-Code | 0
 |  |  |  |  |  | 32 |  |  |  |  |  |  |  |  |  |  |  |  |  |  |  |  |  |  |  |  |  |  |  |  |  |  |  |  |  |  |  | 010 |  |  |  |  |  |  |  | 32
xxxx | 0x2b | MOV | Xfer_R | Xfer_L | 101011 |  |  |  |  |  |  |  |  |  |  |  |  |  |  |  |  |  |  |  |  | 12 |  |  |  | 8 | 7 |  | 5 | 4 | 3 | 2 |  | 001 | OP-Code | 0 | 0x9f | SUB | C | X | 10011111 |  |  |  |  |  |  | 26 |  |  |  | 22 |  | 20
 |  |  |  |  |  | 32 |  |  |  |  |  |  |  |  |  |  |  |  |  |  |  |  |  |  |  |  |  |  |  |  |  |  |  |  |  |  |  | 010
xxxx | 0x2c | MOV | Xfer_L | A | 101100 |  |  |  |  |  |  |  |  |  |  |  |  |  |  |  |  |  |  |  |  | 12 |  |  |  | 8 | 7 | 6 |  |  |  |  | 1 | 001 | OP-Code | 0 |  |  |  |  |  | 32
 |  |  |  |  |  | 32 |  |  |  |  |  |  |  |  |  |  |  |  |  |  |  |  |  |  |  |  |  |  |  |  |  |  |  |  |  |  |  | 010 |  |  | 0xa0 | SUB | D | A | 10100000 |  |  |  |  |  |  | 26 |  |  |  |  |  | 20
xxxx | 0x2d | MOV | Xfer_L | B | 101101 |  |  |  |  |  |  |  |  |  |  |  |  |  |  |  |  |  |  |  |  | 12 |  |  |  | 8 | 7 | 6 |  |  |  | 2 |  | 001 | OP-Code | 0
 |  |  |  |  |  | 32 |  |  |  |  |  |  |  |  |  |  |  |  |  |  |  |  |  |  |  |  |  |  |  |  |  |  |  |  |  |  |  | 010 |  |  |  |  |  |  |  | 32
xxxx | 0x2e | MOV | Xfer_L | C | 101110 |  |  |  |  |  |  |  |  |  |  |  |  |  |  |  |  |  |  |  |  | 12 |  |  |  | 8 | 7 | 6 |  |  |  | 2 | 1 | 001 | OP-Code | 0 | 0xa1 | SUB | D | B | 10100001 |  |  |  |  |  |  | 26 |  |  |  |  | 21
 |  |  |  |  |  | 32 |  |  |  |  |  |  |  |  |  |  |  |  |  |  |  |  |  |  |  |  |  |  |  |  |  |  |  |  |  |  |  | 010
xxxx | 0x2f | MOV | Xfer_L | D | 101111 |  |  |  |  |  |  |  |  |  |  |  |  |  |  |  |  |  |  |  |  | 12 |  |  |  | 8 | 7 | 6 |  |  | 3 |  |  | 001 | OP-Code | 0 |  |  |  |  |  | 32
 |  |  |  |  |  | 32 |  |  |  |  |  |  |  |  |  |  |  |  |  |  |  |  |  |  |  |  |  |  |  |  |  |  |  |  |  |  |  | 010 |  |  | 0xa2 | SUB | D | C | 10100010 |  |  |  |  |  |  | 26 |  |  |  | 21 | 20
xxxx | 30 | MOV | Xfer_L | X | 110000 |  |  |  |  |  |  |  |  |  |  |  |  |  |  |  |  |  |  |  |  | 12 |  |  |  | 8 | 7 | 6 |  |  | 3 |  | 1 | 001 | OP-Code | 0
 |  |  |  |  |  | 32 |  |  |  |  |  |  |  |  |  |  |  |  |  |  |  |  |  |  |  |  |  |  |  |  |  |  |  |  |  |  |  | 010 |  |  |  |  |  |  |  | 32
xxxx | 31 | MOV | Xfer_L | Xfer_R | 110001 |  |  |  |  |  |  |  |  |  |  |  |  |  |  |  |  |  |  |  |  | 12 |  |  |  | 8 | 7 | 6 |  | 4 | 3 |  | 1 | 001 | OP-Code | 0 | 0xa3 | SUB | D | X | 10100011 |  |  |  |  |  |  | 26 |  |  |  | 22 |  | 20
 |  |  |  |  |  | 32 |  |  |  |  |  |  |  |  |  |  |  |  |  |  |  |  |  |  |  |  |  |  |  |  |  |  |  |  |  |  |  | 010
xxxx | 32 | MOV | PC | Xfer | 110010 |  |  |  |  |  |  |  |  |  |  |  |  |  |  |  |  |  |  |  |  | 12 |  |  |  |  | 7 | 6 |  | 4 | 3 |  |  | 001 | OP-Code | 0 |  |  |  |  |  | 32
 |  |  |  |  |  | 32 |  |  |  |  |  |  |  |  |  |  |  |  |  |  |  |  |  |  |  |  |  |  |  |  |  |  |  |  |  |  |  | 010 |  |  | 0xa4 | SUB | X | A | 10100100 |  |  |  |  |  |  | 26 |  |  |  |  |  | 20
xxxx | 33 | MOV | PC | SP | 110011 |  |  |  |  |  |  |  |  |  |  |  |  |  |  |  |  |  |  |  |  | 12 |  |  |  |  | 7 | 6 |  |  | 3 | 2 | 1 | 001 | OP-Code | 0
 |  |  |  |  |  | 32 |  |  |  |  |  |  |  |  |  |  |  |  |  |  |  |  |  |  |  |  |  |  |  |  |  |  |  |  |  |  |  | 010 |  |  |  |  |  |  |  | 32
xxxx | 34 | MOV | PC | CREG | 110100 |  |  |  |  |  |  |  |  |  |  |  |  |  |  |  |  |  |  |  |  | 12 |  |  |  |  | 7 | 6 |  | 4 |  |  |  | 001 | OP-Code | 0 | 0xa5 | SUB | X | B | 10100101 |  |  |  |  |  |  | 26 |  |  |  |  | 21
 |  |  |  |  |  | 32 |  |  |  |  |  |  |  |  |  |  |  |  |  |  |  |  |  |  |  |  |  |  |  |  |  |  |  |  |  |  |  | 010
xxxx | 35 | MOV | SP | Xfer | 110101 |  |  |  |  |  |  |  |  |  |  |  |  |  |  |  |  |  |  |  |  | 12 |  |  |  |  | 7 | 6 | 5 | 4 | 3 |  |  | 001 | OP-Code | 0 |  |  |  |  |  | 32
 |  |  |  |  |  | 32 |  |  |  |  |  |  |  |  |  |  |  |  |  |  |  |  |  |  |  |  |  |  |  |  |  |  |  |  |  |  |  | 010 |  |  | 0xa6 | SUB | X | C | 10100110 |  |  |  |  |  |  | 26 |  |  |  | 21 | 20
xxxx | 36 | MOV | SP | PC | 110110 |  |  |  |  |  |  |  |  |  |  |  |  |  |  |  |  |  |  |  |  | 12 |  |  |  |  | 7 | 6 | 5 |  | 3 | 2 |  | 001 | OP-Code | 0
 |  |  |  |  |  | 32 |  |  |  |  |  |  |  |  |  |  |  |  |  |  |  |  |  |  |  |  |  |  |  |  |  |  |  |  |  |  |  | 010 |  |  |  |  |  |  |  | 32
xxxx | 37 | MOV | SP | CREG | 110111 |  |  |  |  |  |  |  |  |  |  |  |  |  |  |  |  |  |  |  |  | 12 |  |  |  |  | 7 | 6 | 5 | 4 |  |  |  | 001 | OP-Code | 0 | 0xa7 | SUB | X | D | 10100111 |  |  |  |  |  |  | 26 |  |  | 22
 |  |  |  |  |  | 32 |  |  |  |  |  |  |  |  |  |  |  |  |  |  |  |  |  |  |  |  |  |  |  |  |  |  |  |  |  |  |  | 010
xxxx | 38 | MOV | CREG | Xfer | 111000 |  |  |  |  |  |  |  |  |  |  |  |  |  |  |  |  |  |  |  |  | 12 |  |  |  | 8 |  |  |  | 4 | 3 |  |  | 001 | OP-Code | 0 |  |  |  |  |  | 32
 |  |  |  |  |  | 32 |  |  |  |  |  |  |  |  |  |  |  |  |  |  |  |  |  |  |  |  |  |  |  |  |  |  |  |  |  |  |  | 010 |  |  | 0xa8 | SBB | A | B | 10101000 |  |  |  |  |  |  | 26 | 25 |  |  |  | 21
xxxx | 39 | MOV | CREG | PC | 111001 |  |  |  |  |  |  |  |  |  |  |  |  |  |  |  |  |  |  |  |  | 12 |  |  |  | 8 |  |  |  |  | 3 | 2 |  | 001 | OP-Code | 0
 |  |  |  |  |  | 32 |  |  |  |  |  |  |  |  |  |  |  |  |  |  |  |  |  |  |  |  |  |  |  |  |  |  |  |  |  |  |  | 010 |  |  |  |  |  |  |  | 32
xxxx | 0x3a | MOV | CREG | SP | 111010 |  |  |  |  |  |  |  |  |  |  |  |  |  |  |  |  |  |  |  |  | 12 |  |  |  | 8 |  |  |  |  | 3 | 2 | 1 | 001 | OP-Code | 0 | 0xa9 | SBB | B | A | 10101001 |  |  |  |  |  |  | 26 | 25 |  |  |  |  | 20
 |  |  |  |  |  | 32 |  |  |  |  |  |  |  |  |  |  |  |  |  |  |  |  |  |  |  |  |  |  |  |  |  |  |  |  |  |  |  | 010
xxxx | 0x3b | MOV | Xfer | PC | 111011 |  |  |  |  |  |  |  |  |  |  |  |  |  |  |  |  |  |  |  |  | 12 |  |  |  | 8 | 7 |  |  |  | 3 | 2 |  | 001 | OP-Code | 0 |  |  |  |  |  | 32
 |  |  |  |  |  | 32 |  |  |  |  |  |  |  |  |  |  |  |  |  |  |  |  |  |  |  |  |  |  |  |  |  |  |  |  |  |  |  | 010 |  |  | 0xaa | INC | A |  | 10101010 |  |  |  |  |  | 27
xxxx | 0x3c | MOV | Xfer | SP | 111100 |  |  |  |  |  |  |  |  |  |  |  |  |  |  |  |  |  |  |  |  | 12 |  |  |  | 8 | 7 |  |  |  | 3 | 2 | 1 | 001 | OP-Code | 0
 |  |  |  |  |  | 32 |  |  |  |  |  |  |  |  |  |  |  |  |  |  |  |  |  |  |  |  |  |  |  |  |  |  |  |  |  |  |  | 010 |  |  |  |  |  |  |  | 32
xxxx | 0x3d | MOV | Xfer | CREG | 111101 |  |  |  |  |  |  |  |  |  |  |  |  |  |  |  |  |  |  |  |  | 12 |  |  |  | 8 | 7 |  |  | 4 |  |  |  | 001 | OP-Code | 0 | 0xab | INC | B |  | 10101011 |  |  |  |  |  | 27
 |  |  |  |  |  | 32 |  |  |  |  |  |  |  |  |  |  |  |  |  |  |  |  |  |  |  |  |  |  |  |  |  |  |  |  |  |  |  | 010
xxxx | 0x3e | MOV | A | addr | 111110 |  |  |  |  |  |  |  |  |  |  |  |  |  |  |  |  |  |  |  |  | 12 |  |  |  |  |  |  |  |  |  |  |  | 001 | OP-Code | 0 |  |  |  |  |  | 32
 |  |  |  |  |  |  |  |  |  |  |  |  |  |  |  |  |  |  |  |  |  |  |  |  |  | 12 |  |  | 9 | 8 | 7 |  | 5 | 4 |  | 2 |  | 010 | addr | 1 | 0xac | INC | C |  | 10101100 |  |  |  |  |  | 27
 |  |  |  |  |  |  |  |  |  |  |  |  |  |  |  |  |  |  |  |  |  |  |  |  |  | 12 |  |  | 9 | 8 | 7 | 6 |  | 4 |  | 2 |  | 011 | addr | 2
 |  |  |  |  |  |  |  |  |  |  |  |  |  |  |  |  |  |  |  |  |  |  |  |  |  |  | 11 |  |  |  |  |  | 5 | 4 |  | 2 |  | 100 |  |  |  |  |  |  |  | 32
 |  |  |  |  |  | 32 |  |  |  |  |  |  |  |  |  |  |  |  |  |  |  |  |  |  |  |  |  |  |  |  |  |  |  |  |  |  |  | 101 |  |  | 0xad | INC | D |  | 10101101 |  |  |  |  |  | 27
xxxx | 0x3f | MOV | B | addr | 111111 |  |  |  |  |  |  |  |  |  |  |  |  |  |  |  |  |  |  |  |  | 12 |  |  |  |  |  |  |  |  |  |  |  | 001 | OP-Code | 0
 |  |  |  |  |  |  |  |  |  |  |  |  |  |  |  |  |  |  |  |  |  |  |  |  |  | 12 |  |  | 9 | 8 | 7 |  | 5 | 4 |  | 2 |  | 010 | addr | 1 |  |  |  |  |  | 32
 |  |  |  |  |  |  |  |  |  |  |  |  |  |  |  |  |  |  |  |  |  |  |  |  |  | 12 |  |  | 9 | 8 | 7 | 6 |  | 4 |  | 2 |  | 011 | addr | 2 | 0xae | INC | X |  | 10101110 |  |  |  |  |  | 27
 |  |  |  |  |  |  |  |  |  |  |  |  |  |  |  |  |  |  |  |  |  |  |  |  |  |  | 11 |  |  |  |  | 6 |  | 4 |  | 2 |  | 100
 |  |  |  |  |  | 32 |  |  |  |  |  |  |  |  |  |  |  |  |  |  |  |  |  |  |  |  |  |  |  |  |  |  |  |  |  |  |  | 101 |  |  |  |  |  |  |  | 32
xxxx | 40 | MOV | C | addr | 1000000 |  |  |  |  |  |  |  |  |  |  |  |  |  |  |  |  |  |  |  |  | 12 |  |  |  |  |  |  |  |  |  |  |  | 001 | OP-Code | 0 | 0xaf | DEC | A |  | 10101111 |  |  |  |  |  | 27 |  | 25
 |  |  |  |  |  |  |  |  |  |  |  |  |  |  |  |  |  |  |  |  |  |  |  |  |  | 12 |  |  | 9 | 8 | 7 |  | 5 | 4 |  | 2 |  | 010 | addr | 1
 |  |  |  |  |  |  |  |  |  |  |  |  |  |  |  |  |  |  |  |  |  |  |  |  |  | 12 |  |  | 9 | 8 | 7 | 6 |  | 4 |  | 2 |  | 011 | addr | 2 |  |  |  |  |  | 32
 |  |  |  |  |  |  |  |  |  |  |  |  |  |  |  |  |  |  |  |  |  |  |  |  |  |  | 11 |  |  |  |  | 6 | 5 | 4 |  | 2 |  | 100 |  |  | 0xb0 | DEC | B |  | 10110000 |  |  |  |  |  | 27 |  | 25
 |  |  |  |  |  | 32 |  |  |  |  |  |  |  |  |  |  |  |  |  |  |  |  |  |  |  |  |  |  |  |  |  |  |  |  |  |  |  | 101
xxxx | 41 | MOV | D | addr | 1000001 |  |  |  |  |  |  |  |  |  |  |  |  |  |  |  |  |  |  |  |  | 12 |  |  |  |  |  |  |  |  |  |  |  | 001 | OP-Code | 0 |  |  |  |  |  | 32
 |  |  |  |  |  |  |  |  |  |  |  |  |  |  |  |  |  |  |  |  |  |  |  |  |  | 12 |  |  | 9 | 8 | 7 |  | 5 | 4 |  | 2 |  | 010 | addr | 1 | 0xb1 | DEC | C |  | 10110001 |  |  |  |  |  | 27 |  | 25
 |  |  |  |  |  |  |  |  |  |  |  |  |  |  |  |  |  |  |  |  |  |  |  |  |  | 12 |  |  | 9 | 8 | 7 | 6 |  | 4 |  | 2 |  | 011 | addr | 2
 |  |  |  |  |  |  |  |  |  |  |  |  |  |  |  |  |  |  |  |  |  |  |  |  |  |  | 11 |  |  |  | 7 |  |  | 4 |  | 2 |  | 100 |  |  |  |  |  |  |  | 32
 |  |  |  |  |  | 32 |  |  |  |  |  |  |  |  |  |  |  |  |  |  |  |  |  |  |  |  |  |  |  |  |  |  |  |  |  |  |  | 101 |  |  | 0xb2 | DEC | D |  | 10110010 |  |  |  |  |  | 27 |  | 25
xxxx | 42 | MOV | X | addr | 1000010 |  |  |  |  |  |  |  |  |  |  |  |  |  |  |  |  |  |  |  |  | 12 |  |  |  |  |  |  |  |  |  |  |  | 001 | OP-Code | 0
 |  |  |  |  |  |  |  |  |  |  |  |  |  |  |  |  |  |  |  |  |  |  |  |  |  | 12 |  |  | 9 | 8 | 7 |  | 5 | 4 |  | 2 |  | 010 | addr | 1 |  |  |  |  |  | 32
 |  |  |  |  |  |  |  |  |  |  |  |  |  |  |  |  |  |  |  |  |  |  |  |  |  | 12 |  |  | 9 | 8 | 7 | 6 |  | 4 |  | 2 |  | 011 | addr | 2 | 0xb3 | DEC | X |  | 10110011 |  |  |  |  |  | 27 |  | 25
 |  |  |  |  |  |  |  |  |  |  |  |  |  |  |  |  |  |  |  |  |  |  |  |  |  |  | 11 |  |  |  | 7 |  | 5 | 4 |  | 2 |  | 100
 |  |  |  |  |  | 32 |  |  |  |  |  |  |  |  |  |  |  |  |  |  |  |  |  |  |  |  |  |  |  |  |  |  |  |  |  |  |  | 101 |  |  |  |  |  |  |  | 32
xxxx | 43 | MOV | Xfer_R | addr | 1000011 |  |  |  |  |  |  |  |  |  |  |  |  |  |  |  |  |  |  |  |  | 12 |  |  |  |  |  |  |  |  |  |  |  | 001 | OP-Code | 0 | 0xb4 | AND | A | B | 10110100 |  |  |  |  |  | 27 | 26 |  |  |  |  | 21
 |  |  |  |  |  |  |  |  |  |  |  |  |  |  |  |  |  |  |  |  |  |  |  |  |  | 12 |  |  | 9 | 8 | 7 |  | 5 | 4 |  | 2 |  | 010 | addr | 1
 |  |  |  |  |  |  |  |  |  |  |  |  |  |  |  |  |  |  |  |  |  |  |  |  |  | 12 |  |  | 9 | 8 | 7 | 6 |  | 4 |  | 2 |  | 011 | addr | 2 |  |  |  |  |  | 32
 |  |  |  |  |  |  |  |  |  |  |  |  |  |  |  |  |  |  |  |  |  |  |  |  |  |  | 11 |  |  | 8 | 7 |  | 5 | 4 |  | 2 |  | 100 |  |  | 0xb5 | AND | A | C | 10110101 |  |  |  |  |  | 27 | 26 |  |  |  |  | 21 | 20
 |  |  |  |  |  | 32 |  |  |  |  |  |  |  |  |  |  |  |  |  |  |  |  |  |  |  |  |  |  |  |  |  |  |  |  |  |  |  | 101
xxxx | 44 | MOV | Xfer_L | addr | 1000100 |  |  |  |  |  |  |  |  |  |  |  |  |  |  |  |  |  |  |  |  | 12 |  |  |  |  |  |  |  |  |  |  |  | 001 | OP-Code | 0 |  |  |  |  |  | 32
 |  |  |  |  |  |  |  |  |  |  |  |  |  |  |  |  |  |  |  |  |  |  |  |  |  | 12 |  |  | 9 | 8 | 7 |  | 5 | 4 |  | 2 |  | 010 | addr | 1 | 0xb6 | AND | A | D | 10110110 |  |  |  |  |  | 27 | 26 |  |  |  | 22
 |  |  |  |  |  |  |  |  |  |  |  |  |  |  |  |  |  |  |  |  |  |  |  |  |  | 12 |  |  | 9 | 8 | 7 | 6 |  | 4 |  | 2 |  | 011 | addr | 2
 |  |  |  |  |  |  |  |  |  |  |  |  |  |  |  |  |  |  |  |  |  |  |  |  |  |  | 11 |  |  | 8 | 7 | 6 |  | 4 |  | 2 |  | 100 |  |  |  |  |  |  |  | 32
 |  |  |  |  |  | 32 |  |  |  |  |  |  |  |  |  |  |  |  |  |  |  |  |  |  |  |  |  |  |  |  |  |  |  |  |  |  |  | 101 |  |  | 0xb7 | AND | A | X | 10110111 |  |  |  |  |  | 27 | 26 |  |  |  | 22 |  | 20
xxxx | 45 | MOV | addr | A | 1000101 |  |  |  |  |  |  |  |  |  |  |  |  |  |  |  |  |  |  |  |  | 12 |  |  |  |  |  |  |  |  |  |  |  | 001 | OP-Code | 0
 |  |  |  |  |  |  |  |  |  |  |  |  |  |  |  |  |  |  |  |  |  |  |  |  |  | 12 |  |  | 9 | 8 | 7 |  | 5 | 4 |  | 2 |  | 010 | addr | 1 |  |  |  |  |  | 32
 |  |  |  |  |  |  |  |  |  |  |  |  |  |  |  |  |  |  |  |  |  |  |  |  |  | 12 |  |  | 9 | 8 | 7 | 6 |  | 4 |  | 2 |  | 011 | addr | 2 | 0xb8 | AND | B | C | 10111000 |  |  |  |  |  | 27 | 26 |  |  |  |  | 21 | 20
 |  |  |  |  |  |  |  |  |  |  |  |  |  |  |  |  |  |  |  |  |  |  |  |  |  |  | 11 |  |  | 8 |  |  | 5 |  |  |  | 1 | 100
 |  |  |  |  |  | 32 |  |  |  |  |  |  |  |  |  |  |  |  |  |  |  |  |  |  |  |  |  |  |  |  |  |  |  |  |  |  |  | 101 |  |  |  |  |  |  |  | 32
xxxx | 46 | MOV | addr | B | 1000110 |  |  |  |  |  |  |  |  |  |  |  |  |  |  |  |  |  |  |  |  | 12 |  |  |  |  |  |  |  |  |  |  |  | 001 | OP-Code | 0 | 0xb9 | AND | B | D | 10111001 |  |  |  |  |  | 27 | 26 |  |  |  | 22
 |  |  |  |  |  |  |  |  |  |  |  |  |  |  |  |  |  |  |  |  |  |  |  |  |  | 12 |  |  | 9 | 8 | 7 |  | 5 | 4 |  | 2 |  | 010 | addr | 1
 |  |  |  |  |  |  |  |  |  |  |  |  |  |  |  |  |  |  |  |  |  |  |  |  |  | 12 |  |  | 9 | 8 | 7 | 6 |  | 4 |  | 2 |  | 011 | addr | 2 |  |  |  |  |  | 32
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

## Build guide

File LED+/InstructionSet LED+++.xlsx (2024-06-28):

ADD
ADC
SUB
SBB
INC
DEC
INC | variabler anzahl
DEC | variabler anzahl
AND
OR
NAND
XOR
XNOR
NOR
NOT
NEG
SHL | variabler anzahl
LRS | variabler anzahl
ARS | variabler anzahl
ROL | variabler anzahl
ROR | variabler anzahl
ROLc | variabler anzahl
RORc | variabler anzahl
ADDnC
SUBnC
MUL | (8bit)
DIV

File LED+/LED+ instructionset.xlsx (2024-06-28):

Instructionset LED+ architecure
 |  | memory layout
mode | name | byte 0 | byte 1 | byte 2 | byte 3
 |  | OP-Code | Arg A / immediate | Arg B / immediate | destination
 | add | 0b00xx0000
 | adc | 0b00xx0001
 | sub | 0b00xx0010
 | sbb | 0b00xx0011
 | inc
 | dec
 | and
 | or
 | xor
 | not
 | neg
 | shl
 | shrl
 | shra
 | rol
 | ror

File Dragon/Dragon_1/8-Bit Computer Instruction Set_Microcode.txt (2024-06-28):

_______________________________________________________________________________________________________________________________________________________________________________________________________________________________________________________________________________________________________________________________________________________________________
Control Word:

Clock halt | Step reset | RAM out | RAM write | MAR out BUS | MAR out RAM | MAR write | IR out BUS | IR out CU | IR In | A-reg out | A-reg In | B-reg out | B-reg In | OP-codeALU1 | OP-codeALU2 | OP-codeALU3 | ALU Sum out | PC out | PC count enable | PC load | Flag Reg Update | X Reg In | X Reg out | display x In | display y In | display write
hlt 	   | Sr	        | Ro      | Rw        | MBo         | MRo 	  | Mw	      | IBo	   | ICo       | II    | Ao	   | AI       | Bo        | BI       | OP1         | OP2         | OP3         | So	     | PCo    | PCe             | PCl     | FU              | Xi       | Xo	   | dxI	  | dyI		 | dw
_______________________________________________________________________________________________________________________________________________________________________________________________________________________________________________________________________________________________________________________________________________________________________

____________________________________________________________________________________________________________________________________________________
   1    2    3    4     5     6    7     8     9    10   11   12   13   14   15    16    17    18   19    20    21    22   23   24   25    26    27
| hlt | Sr | Ro | Rw | MBo | MRo | Mw | IBo | ICo | II | Ao | AI | Bo | BI | OP1 | OP2 | OP3 | So | PCo | PCe | PCl | FU | Xi | Xo | dxI | dyI | dw

	OP code	     Flags    Steps   MicroCode          1                   2                   3
_______________________________________1_2_3_4_5_6_7_8_9_0_1_2_3_4_5_6_7_8_9_0_1_2_3_4_5_6_7_8_9_0_1_2
Fetch	x x x x x x  x x x  0 0 0 0  | 0 0 0 0 0 0 1 0 0 0 0 0 0 0 0 0 0 0 1 0 0 0 0 0 0 0 0 0 0 0 0 0 HEX_2002000
	x x x x x x  x x x  0 0 0 1  | 0 0 1 0 0 1 0 0 0 1 0 0 0 0 0 0 0 0 0 1 0 0 0 0 0 0 0 0 0 0 0 0 HEX_24401000

NULL	0 0 0 0 0 0  x x x  0 0 1 0  | 0 1 0 0 0 0 0 0 0 0 0 0 0 0 0 0 0 0 0 0 0 1 0 0 0 0 0 0 0 0 0 0 HEX_40000400

LDA	0 0 0 0 0 1  x x x  0 0 1 0  | 0 0 0 0 0 0 1 0 1 0 0 0 0 0 0 0 0 0 0 0 0 0 0 0 0 0 0 0 0 0 0 0 HEX_2800000 		
	0 0 0 0 0 1  x x x  0 0 1 1  | 0 0 1 0 0 1 0 0 0 0 0 1 0 0 0 0 0 0 0 0 0 0 0 0 0 0 0 0 0 0 0 0 HEX_24100000
	0 0 0 0 0 1  x x x  0 1 0 0  | 0 1 0 0 0 0 0 0 0 0 0 0 0 0 0 0 0 0 0 0 0 0 0 0 0 0 0 0 0 0 0 0 HEX_40000000

LDB	0 0 0 0 0 1  x x x  0 0 1 0  | 0 0 0 0 0 0 1 0 1 0 0 0 0 0 0 0 0 0 0 0 0 0 0 0 0 0 0 0 0 0 0 0 HEX_28000000		
	0 0 0 0 0 1  x x x  0 0 1 1  | 0 0 1 0 0 1 0 0 0 0 0 0 0 1 0 0 0 0 0 0 0 0 0 0 0 0 0 0 0 0 0 0 HEX_24040000
	0 0 0 0 0 1  x x x  0 1 0 0  | 0 1 0 0 0 0 0 0 0 0 0 0 0 0 0 0 0 0 0 0 0 0 0 0 0 0 0 0 0 0 0 0 HEX_40000000

LDX	0 0 0 0 1 0  x x x  0 0 1 0  | 0 0 0 0 0 0 1 0 1 0 0 0 0 0 0 0 0 0 0 0 0 0 0 0 0 0 0 0 0 0 0 0 HEX_28000000		
	0 0 0 0 1 0  x x x  0 0 1 1  | 0 0 1 0 0 1 0 0 0 0 0 0 0 0 0 0 0 0 0 0 0 0 1 0 0 0 0 0 0 0 0 0 HEX_24000200
	0 0 0 0 1 0  x x x  0 1 0 0  | 0 1 0 0 0 0 0 0 0 0 0 0 0 0 0 0 0 0 0 0 0 0 0 0 0 0 0 0 0 0 0 0 HEX_40000000

ADD	0 0 0 0 0 1  x x x  0 0 1 0  | 0 0 0 0 0 0 1 1 0 0 0 0 0 0 0 0 0 0 0 0 0 0 0 0 0 0 0 0 0 0 0 0 HEX_3000000		
	0 0 0 0 0 1  x x x  0 0 1 1  | 0 0 1 0 0 1 0 0 0 0 0 0 0 1 1 0 0 0 0 0 0 0 0 0 0 0 0 0 0 0 0 0 HEX_24060000
	0 0 0 0 0 1  x x x  0 1 0 0  | 0 0 0 0 0 0 0 0 0 0 0 1 0 0 1 0 0 1 0 0 0 0 0 0 0 0 0 0 0 0 0 0 HEX_124000
	0 0 0 0 0 1  x x x  0 1 0 1  | 0 1 0 0 0 0 0 0 0 0 0 0 0 0 0 0 0 0 0 0 0 0 0 0 0 0 0 0 0 0 0 0 HEX_40000000

HLT:	0 0 1 0 1 1  x x x  0 0 1 0  | 1 0 0 0 0 0 0 0 0 0 0 0 0 0 0 0 0 0 0 0 0 0 0 0 0 0 0 0 0 0 0 0 HEX_80000000

Ui	1 0 0 0 0 0  0 0 0  0 0 1 0  | 0 0 0 0 0 0 0 0 0 0 0 0 0 0 0 0 0 0 0 0 0 0 0 0 0 0 0 0 0 0 0 0 HEX_ MARo PCi SCr(StepCounterReset)
	1 0 0 0 0 0  0 0 1  0 0 1 1  | 0 0 0 0 0 0 0 0 0 0 0 0 0 0 0 0 0 0 0 0 0 0 0 0 0 0 0 0 0 0 0 0 HEX_ IRo MARi
	1 0 0 0 0 0  x x x  0 1 0 0  | InRo RAMwe  reset input Flag reg | reset input reg

_______________________________________________________________________________________________________________________________________________________________________________________________________________________________________________________________________________________________________________________________________________________________________
Control Word Dragon-2:

Clock halt | Step reset | RAM out | RAM write | MAR out BUS | MAR out RAM | MAR write | IR out BUS | IR out CU | IR In | A-reg out | A-reg In | B-reg out | B-reg In | OP-codeALU1 | OP-codeALU2 | OP-codeALU3 | ALU Sum out | PC out | PC count enable | PC load | Flag Reg Update | X Reg In | X Reg out | display x In | display y In | display write
hlt 	   | Sr	        | Ro      | Rw        | MBo         | MRo 	  | Mw	      | IBo	   | ICo       | II    | Ao	   | AI       | Bo        | BI       | OP1         | OP2         | OP3         | So	     | PCo    | PCe             | PCl     | FU              | Xi       | Xo	   | dxI	  | dyI		 | dw
_______________________________________________________________________________________________________________________________________________________________________________________________________________________________________________________________________________________________________________________________________________________________________

____________________________________________________________________________________________________________________________________________________
   1    2    3    4     5     6    7     8     9    10   11   12   13   14   15    16    17    18   19    20    21    22   23   24   25    26    27
| hlt | Sr | Ro | Rw | MBo | MRo | Mw | IBo | ICo | II | Ao | AI | Bo | BI | OP1 | OP2 | OP3 | So | PCo | PCe | PCl | FU | Xi | Xo | dxI | dyI | dw

	OP code	     Flags    Steps   MicroCode          1                   2                   3
_______________________________________1_2_3_4_5_6_7_8_9_0_1_2_3_4_5_6_7_8_9_0_1_2_3_4_5_6_7_8_9_0_1_2
Fetch	x x x x x x  x x x  0 0 0 0  | 0 0 0 0 0 0 1 0 0 0 0 0 0 0 0 0 0 0 1 0 0 0 0 0 0 0 0 0 0 0 0 0 HEX_2002000
	x x x x x x  x x x  0 0 0 1  | 0 0 1 0 0 1 0 0 0 1 0 0 0 0 0 0 0 0 0 1 0 0 0 0 0 0 0 0 0 0 0 0 HEX_24401000

NULL	0 0 0 0 0 0  x x x  0 0 1 0  | 0 1 0 0 0 0 0 0 0 0 0 0 0 0 0 0 0 0 0 0 0 1 0 0 0 0 0 0 0 0 0 0 HEX_40000400

LDA	0 0 0 0 0 1  x x x  0 0 1 0  | 0 0 0 0 0 0 1 0 1 0 0 0 0 0 0 0 0 0 0 0 0 0 0 0 0 0 0 0 0 0 0 0 HEX_2800000 		
	0 0 0 0 0 1  x x x  0 0 1 1  | 0 0 1 0 0 1 0 0 0 0 0 1 0 0 0 0 0 0 0 0 0 0 0 0 0 0 0 0 0 0 0 0 HEX_24100000
	0 0 0 0 0 1  x x x  0 1 0 0  | 0 1 0 0 0 0 0 0 0 0 0 0 0 0 0 0 0 0 0 0 0 0 0 0 0 0 0 0 0 0 0 0 HEX_40000000

LDB	0 0 0 0 0 1  x x x  0 0 1 0  | 0 0 0 0 0 0 1 0 1 0 0 0 0 0 0 0 0 0 0 0 0 0 0 0 0 0 0 0 0 0 0 0 HEX_28000000		
	0 0 0 0 0 1  x x x  0 0 1 1  | 0 0 1 0 0 1 0 0 0 0 0 0 0 1 0 0 0 0 0 0 0 0 0 0 0 0 0 0 0 0 0 0 HEX_24040000
	0 0 0 0 0 1  x x x  0 1 0 0  | 0 1 0 0 0 0 0 0 0 0 0 0 0 0 0 0 0 0 0 0 0 0 0 0 0 0 0 0 0 0 0 0 HEX_40000000

LDX	0 0 0 0 1 0  x x x  0 0 1 0  | 0 0 0 0 0 0 1 0 1 0 0 0 0 0 0 0 0 0 0 0 0 0 0 0 0 0 0 0 0 0 0 0 HEX_28000000		
	0 0 0 0 1 0  x x x  0 0 1 1  | 0 0 1 0 0 1 0 0 0 0 0 0 0 0 0 0 0 0 0 0 0 0 1 0 0 0 0 0 0 0 0 0 HEX_24000200
	0 0 0 0 1 0  x x x  0 1 0 0  | 0 1 0 0 0 0 0 0 0 0 0 0 0 0 0 0 0 0 0 0 0 0 0 0 0 0 0 0 0 0 0 0 HEX_40000000

ADD	0 0 0 0 0 1  x x x  0 0 1 0  | 0 0 0 0 0 0 1 1 0 0 0 0 0 0 0 0 0 0 0 0 0 0 0 0 0 0 0 0 0 0 0 0 HEX_3000000		
	0 0 0 0 0 1  x x x  0 0 1 1  | 0 0 1 0 0 1 0 0 0 0 0 0 0 1 1 0 0 0 0 0 0 0 0 0 0 0 0 0 0 0 0 0 HEX_24060000
	0 0 0 0 0 1  x x x  0 1 0 0  | 0 0 0 0 0 0 0 0 0 0 0 1 0 0 1 0 0 1 0 0 0 0 0 0 0 0 0 0 0 0 0 0 HEX_124000
	0 0 0 0 0 1  x x x  0 1 0 1  | 0 1 0 0 0 0 0 0 0 0 0 0 0 0 0 0 0 0 0 0 0 0 0 0 0 0 0 0 0 0 0 0 HEX_40000000

HLT:	0 0 1 0 1 1  x x x  0 0 1 0  | 1 0 0 0 0 0 0 0 0 0 0 0 0 0 0 0 0 0 0 0 0 0 0 0 0 0 0 0 0 0 0 0 HEX_80000000

Ui	1 0 0 0 0 0  0 0 0  0 0 1 0  | 0 0 0 0 0 0 0 0 0 0 0 0 0 0 0 0 0 0 0 0 0 0 0 0 0 0 0 0 0 0 0 0 HEX_ MARo PCi SCr(StepCounterReset)
	1 0 0 0 0 0  0 0 1  0 0 1 1  | 0 0 0 0 0 0 0 0 0 0 0 0 0 0 0 0 0 0 0 0 0 0 0 0 0 0 0 0 0 0 0 0 HEX_ IRo MARi
	1 0 0 0 0 0  x x x  0 1 0 0  | InRo RAMwe  reset input Flag reg | reset input reg

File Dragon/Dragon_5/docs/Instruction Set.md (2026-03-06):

# Arithmetic Operations

| Instr. | Attr. 1 | Attr. 2 | Attr. 3 | OP-code  | size | Instr type | info |
| --- | --- | --- | --- | --- | ---- | --- | --- |
| **ADD** | regS | regS | regD | ``0x01`` | 3 | RRR | |
| **ADDi** | regS | regD | Imm | ``0x02`` | 4 | RRI | |
| **ADC** | regS | regS | regD | ``0x03`` | 3 | RRR | add with carry |
| **SUB** | regS | regS | regD | ``0x04`` | 3 | RRR | |
| **SUBi** | regS | regD | Imm | ``0x05`` | 4 | RRI | |
| **SBB** | regS | regS | regD | ``0x06`` | 3 | RRR | sub with borrow |
| **MUL** | regS | regS | regD | ``0x07`` | 3 | RRR | multiply lower half |
| **MULH** | regS | regS | regD | ``0x08`` | 3 | RRR | multiply upper half |
| **MULHu**  | regS | regS | regD | ``0x09`` | 3 | RRR | multiply upper half unsigned |
| **MULHsu** | regS | regS | regD | ``0x0A`` | 3 | RRR | multiply upper half signed, unsigned |
| **DIV** | regS | regS | regD | ``0x0B`` | 3 | RRR | |
| **DIVu** | regS | regS | regD | ``0x0C`` | 3 | RRR | |
| **REM** | regS | regS | regD | ``0x0D`` | 3 | RRR | remainder |
| **REMu** | regS | regS | regD | ``0x0E`` | 3 | RRR | |
| **CMP** | regS | regS | | ``0x0F`` | 2 | RR | compare. Sub R1 and R2 and set flags without saving value |
# Logical Operations

| Instr. | Attr. 1 | Attr. 2 | Attr. 3 | OP-code  | size | Instr type | info |
| --- | --- | --- | --- | --- | ---- | --- | --- |
| **AND** | regS | regS | regD | ``0x10`` | 3 | RRR | |
| **OR** | regS | regS | regD | ``0x11`` | 3 | RRR | |
| **XOR** | regS | regS | regD | ``0x12`` | 3 | RRR | |
| **NOR** | regS | regS | regD | ``0x13`` | 3 | RRR | |
| **NAND**  | regS | regS | regD | ``0x14`` | 3 | RRR | |
| **NOT** | regS | regD | | ``0x15`` | 2 | RR | ~regS |
| **NEG** | regS | regD | | ``0x16`` | 2 | RR | ~regS + 1 |
| **SHL** | regS | regS | regD | ``0x17`` | 3 | RRR | shift left |
| **SHR** | regS | regS | regD | ``0x18`` | 3 | RRR | shift right (logical) |
| **SHRa**  | regS | regS | regD | ``0x19`` | 3 | RRR | shift right (arithmetical) |
| **SHLi**  | regS | regD | Imm | ``0x1A`` | 4 | RRI | |
| **SHRi**  | regS | regD | Imm | ``0x1B`` | 4 | RRI | |
| **SHRai** | regS | regD | Imm | ``0x1C`` | 4 | RRI | |
| **ROR** | regS | regD | | ``0x1D`` | 2 | RR | rotate right |
| **ROL** | regS | regD | | ``0x1E`` | 2 | RR | rotate left |
| **NOP** | | | | ``0x1F`` | 1 | | reserved |

# Jumps
absolute jump:
**JMP** reg, Imm
PC = reg + Imm
**JALr** reg, RA, Imm (modifies RA register)
PC = reg + Imm ; RA = PC + 4

relative jump:
**JALr** PC, RA, Imm | or | **JAL** Imm
**JZ** LABEL
if zeroflag = 1:
	RA=PC+4,    PC+=Imm(signed)
Take the value of R2, add it with the offset and put it into R1.

| Instr. | Attr. 1 | Attr. 2 | Attr. 3  | OP-code  | size | Instr type | info |
| --- | --- | --- | --- | --- | ---- | --- | --- |
| **JALr** | regS | regD | Imm/offs | ``0x20`` | 4 | RRI | Jump and Link; PC = regS+Offs; regD(RA) = PC+4 |
| **JZr**  | regS | regD | offs | ``0x21`` | 4 | RRI | Jump if Zero |
| **JNZr** | regS | regD | offs | ``0x22`` | 4 | RRI | Jump if not Zero |
| **JSr**  | regS | regD | offs | ``0x23`` | 4 | RRI | Jump if Signed |
| **JNSr** | regS | regD | offs | ``0x24`` | 4 | RRI | Jump if not Signed |
| **JCr**  | regS | regD | offs | ``0x25`` | 4 | RRI | Jump if Carry |
| **JNCr** | regS | regD | offs | ``0x26`` | 4 | RRI | Jump if not Carry |
| **JOr**  | regS | regD | offs | ``0x27`` | 4 | RRI | Jump if Overflow |
| **JNOr** | regS | regD | offs | ``0x28`` | 4 | RRI | Jump if not Overflow |
| **JPr**  | regS | regD | offs | ``0x29`` | 4 | RRI | Jump if Parity |
| **JNPr** | regS | regD | offs | ``0x2A`` | 4 | RRI | Jump if not Parity |
| **JGr**  | regS | regD | offs | ``0x2B`` | 4 | RRI | Jump if greater ``ZF==0 and SF==OF`` (signed) |
| **JLEr** | regS | regD | offs | ``0x2C`` | 4 | RRI | Jump if less or equal ``ZF==1 or SF!=OF`` (signed) |
| **JAr**  | regS | regD | offs | ``0x2D`` | 4 | RRI | Jump if above ``CF==0 and ZF==0`` (unsigned) |
| **JBEr** | regS | regD | offs | ``0x2E`` | 4 | RRI | Jump if Below or Equal ``CF==1 or ZF==1`` (unsigned) |
| **NOP**  | | | | ``0x2F`` | 1 | | reserved |

# Memory Operations

| Instr. | Attr. 1 | Attr. 2 | Attr. 3 | OP-code  | size | Instr type | info |
| --- | --- | --- | --- | --- | ---- | --- | --- |
| **SW** | regS | regS^ | offs | ``0x30`` | 4 | RRI | store word |
| **LW** | regS | regD^ | offs | ``0x31`` | 4 | RRI | load word |
| **SWi**  | regS | Imm | | ``0x32`` | 4 | RI | Store Immediate at regS |
| **MOV**  | regS | regD | | ``0x33`` | 2 | RR | move |
| **SW0**  | regS | regS^ | offs | ``0x34`` | 4 | RRI | ignores mem bank |
| **LW0**  | regS | regD^ | offs | ``0x35`` | 4 | RRI | ignores mem bank |
| **SWB**  | regS | regS^ | Imm^^ | ``0x36`` | 4 | RRI | Store word Bank (Imm) |
| **LWB**  | regS | regD^ | Imm^^ | ``0x37`` | 4 | RRI | Load word Bank (Imm) |
| **SWBr** | regS | regS^ | regS^^  | ``0x38`` | 3 | RRR | Store Word Bank (register) |
| **LWBr** | regS | regS^^  | regD^ | ``0x39`` | 3 | RRR | Load Word Bank (register)  |
^ this is the register that get's saved or saved to
^^ which memory bank
# Other Instructions

| Instr. | Attr. 1 | Attr. 2 | Attr. 3 | OP-code  | size | Instr type | info |
| --- | --- | --- | --- | --- | ---- | --- | --- |
| **NOP** | | | | ``0x00`` | 1 | | No operation |
| **INVDC** | regS | | | ``0x3A`` | | | Invalidate data cache |
| **INVIC** | regS | | | ``0x3B`` | | | Invalidate instruction cache |
| **NOP** | | | | ``0x3C`` | | | reserved |
| **NOP** | | | | ``0x3D`` | | | reserved |
| **NOP** | | | | ``0x3E`` | | | reserved |
| **HALT**  | | | | ``0x3F`` | 1 | | halts the CPU |

# Pseudo Instructions
## Arithmetic
| Instr.  | Attr. 1 | Attr. 2 | Attr. 3 | translation | OP-code  | info |
| --- | --- | --- | --- | --- | --- | --- |
| **INC** | regS | regD | | **ADD** 0x1 regS regD | ``0x01`` | increment by 1 |
| **DEC** | regS | regD | | **SUB** 0x1 regS regD | ``0x04`` | decrement by 1 |
| **INC** | reg | | | **ADD** 0x1 reg reg | ``0x01`` | |
| **DEC** | reg | | | **SUB** 0x1 reg reg | ``0x04`` | |

## Logical
| Instr. | Attr. 1 | Attr. 2 | Attr. 3 | translation | OP-code  | info |
| --- | --- | --- | --- | --- | --- | --- |
| **SHRl**  | regS | regS | regD | **SHRa** regS regS regD | ``0x18`` | shift right logical |
| **SHRli** | regS | regD | Imm | **SHRai** regS regD Imm | ``0x1B`` | shift right logical |

## Jumps
| Instr.  | Attr. 1 | Attr. 2 | Attr. 3 | translation | OP-code  | info |
| --- | --- | --- | --- | --- | --- | --- |
| **JMP** | reg | offs | | **ADDi** reg offs PC | ``0x02`` | absolute jump |
| **JAL** | offs/Label | | | **JALr** PC RA offs | ``0x20`` | relative jump |
| **JAL** | reg | offs | | **JALr** PC reg offs | ``0x20`` | custom RA register |
| **JZ**  | offs | | | **JZr** PC x0 offs | ``0x21`` | doesn't change RA  |
| **JNZ** | offs | | | **JNZr** PC x0 offs | ``0x22`` | |
| **JE**  | offs | | | **JZr** PC x0 offs | ``0x21`` | |
| **JNE** | offs | | | **JNE** PC x0 offs | ``0x22`` | |
| **JS**  | offs | | | **JSr** PC x0 offs | ``0x23`` | |
| **JNS** | offs | | | **JNSr** PC x0 offs | ``0x24`` | |
| **JC**  | offs | | | **JCr** PC x0 offs | ``0x25`` | |
| **JNC** | offs | | | **JNCr** PC x0 offs | ``0x26`` | |
| **JO**  | offs | | | **JOr** PC x0 offs | ``0x27`` | |
| **JNO** | offs | | | **JNOr** PC x0 offs | ``0x28`` | |
| **JP**  | offs | | | **JPr** PC x0 offs | ``0x29`` | |
| **JNP** | offs | | | **JNPr** PC x0 offs | ``0x2A`` | |
| **JG**  | offs | | | **JGr** PC x0 offs | ``0x2B`` | |
| **JLE** | offs | | | **JLEr** PC x0 offs<br> | ``0x2C`` | |
| **JA**  | offs | | | **JAr** PC x0 offs | ``0x2D`` | |
| **JBE** | offs | | | **JBEr** PC x0 offs | ``0x2E`` | |

## Memory Operations
| Instr. | Attr. 1 | Attr. 2 | Attr. 3 | translation | OP-code  | info |
| --- | --- | --- | --- | --- | --- | --- |
| **WRITE**  | regS | regS | Imm | **SW** regS regS Imm | ``0x30`` | |
| **READ** | regS | regD | Imm | **LW** regS regD Imm | ``0x31`` | |
| **WRITEi** | regS | Imm | | **SWi** regS Imm | ``0x34`` | |
| **MV** | regS | regD | | **MOV** regS regD | ``0x36`` | |
| **MOVE** | regS | regD | | **MOV** regS regD | ``0x36`` | |
| **RET** | | | | **MOV** PC RA | ``0x36`` | PC = RA (does not pop from stack) |
| **RETURN** | | | | **MOV** PC RA | ``0x36`` | |
| **PUSH** | reg | offs | | **SW0** SP reg offs  | ``0x30`` | push to stack |
| **POP** | reg | offs | | **LW0** SP reg offs  | ``0x31`` | pop from stack |

## other Instructions
| Instr. | Attr. 1 | Attr. 2 | Attr. 3 | translation | OP-code  | info |
| --- | --- | --- | --- | --- | --- | --- |
| **cFLAGS** | | | | **MOV** x1F x0 | ``0x36`` | clears FLAGS |

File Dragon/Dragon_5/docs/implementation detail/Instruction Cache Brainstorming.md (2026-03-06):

Caches are complicated so I have to write down step by step what needs to happen in order to help me implement the Cache.

Each cache line has 16 words. Those are stored consecutively  in sram. To access those individually the word offset is needed. 
If I fetch something at address 0x415F the next 15 words are also fetched into the cache. 
The address is split into multiple parts:

| tag | index  | word offset |
| ----- | --- | --- |
| 7 bit | 12 bit | 4 bit |

Cache SRAM layout:

| valid flag | tag | data |
| --- | ----- | --- |
| 1 bit | 7 bit | 16 bit |
So the Cache has 64k words with a word being 24 bit long.

## What needs to happen
Whenever an read or write is performed either of two things can happen:
- **Cache miss**
- **Cache hit**

### Cache Hit
The pipeline accesses the cache at it's address and performs it's action on the location. 
If the value is just *read*, nothing special needs to happen.
If the value is *modified*, we update both the value in the cache and main memory.
This is called **Write-Through, write-allocate**. 

### Cache Miss
If the given address is not in the Cache, it has to be fetched. 
The Pipeline is stalled and the Control Logic gives full bus control to the cache controller. The cache controller fetches 16 words from the main memory and loads it into the cache. the valid bit get's set.

### I/O writes to main memory
I forgot that I have memory mapped I/O (MMIO). With MMIO I/O devides cannot simply write into main memory. MMIO should also not be cached so if the CPU accesses those addresses, the Cache get's bypassed.

## Cache invalidation
When a store instruction wrote to the main memory the cache could be incoherent. A potential solution would be an invalidation buffer. If the Data cache writes, send the address to the instruction cache and buffer it. When the cache is not busy work through the buffer. if an address in the buffer is also in the cache, invalidate it. If the Instruction Cache is read and invalidation buffer not empty, stall pipeline, work through buffer then read.
-> Too much work, too much hardware... Self modifying code not allowed! (not enforced) + simple instruction to invalid single line of cache.
Then neither the Instruction Cache nor the Data Cache need any coherence mechanisms which saves a lot of hardware, pcb real-estate and time.

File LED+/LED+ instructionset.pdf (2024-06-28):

mode | Instruction | OP-Code
byte 0

Arg A/immediate
byte 1

Arg B/immediate
byte 2

destination
byte 3
mode | Instruction | OP-Code
byte 0

Arg A/immediate
byte 1

Arg B/immediate
byte 2

destination byte
3
mode | Instruction | OP-Code
byte 0

Arg A/immediate
byte 1

Arg B/immediate
byte 2

destination
byte 3
add | 0b00 00 0000 | register | register | register | mov / move | 0b01 00 0000 | register | (addr register) | register / RAM / IO | jz | 0b01 00 0000 | register | x | PC
adc | 0b00 00 0001 | register | register | register | push | 0b01 00 0001 | register | x | RAM | jnz | 0b01 00 0001 | register | x | PC
sub | 0b00 00 0010 | register | register | register | pop | 0b01 00 0010 | RAM | x | register / IO | js | 0b01 00 0010 | register | x | PC
mul | 0b00 00 0011 | register | register | register | jmp | 0b01 00 0011 | register | x | register | jns | 0b01 00 0011 | register | x | PC
inc | 0b00 00 0100 | x | register | register | | 0b01 00 0100 | | | | jc | 0b01 00 0100 | register | x | PC
dec | 0b00 00 0101 | x | register | register | | 0b01 00 0101 | | | | jnc | 0b01 00 0101 | register | x | PC
and | 0b00 00 0110 | register | register | register | | 0b01 00 0110 | | | | je (equal) | 0b01 00 0110 | register | register | PC
or | 0b00 00 0111 | register | register | register | | 0b01 00 0111 | | | | jne (not equal) | 0b01 00 0111 | register | register | PC
xor | 0b00 00 1000 | register | register | register | | 0b01 00 1000 | | | | ja (above unsigned) | 0b01 00 1000 | register | register | PC
not | 0b00 00 1001 | x | register | register | | 0b01 00 1001 | | | | jb (below unsigned) | 0b01 00 1001 | register | register | PC
neg | 0b00 00 1010 | x | register | register | | 0b01 00 1010 | | | | jg (greater signed) | 0b01 00 1010 | register | register | PC
shl | 0b00 00 1011 | x | register | register | | 0b01 00 1011 | | | | jl (less signed) | 0b01 00 1011 | register | register | PC
shrl | 0b00 00 1100 | x | register | register | | 0b01 00 1100 | | | | jp / jpe (even parity) | 0b01 00 1100 | register | x | PC
shra | 0b00 00 1101 | x | register | register | | 0b01 00 1101 | | | | jnp / jpo (odd parity) | 0b01 00 1101 | register | x | PC
rol | 0b00 00 1110 | x | register | register | | 0b01 00 1110 | | | | jcz (last calc. zero) | 0b01 00 1110 | register | x | PC
ror | 0b00 00 1111 | x | register | register | | 0b01 00 1111 | | | | jcnz (last calc. not zero) | 0b01 00 1111 | register | x | PC
iBadd / iadd | 0b00 01 0000 | register | immediate | register | iamov / iamove | 0b01 01 0000 | register | immediate | RAM | | 0b01 01 0000
iBadc / iadc | 0b00 01 0001 | register | immediate | register | | 0b01 01 0001 | | | | | 0b01 01 0001
iBsub / isub | 0b00 01 0010 | register | immediate | register | | 0b01 01 0010 | | | | | 0b01 01 0010
iBmul / imul | 0b00 01 0011 | register | immediate | register | | 0b01 01 0011 | | | | | 0b01 01 0011
iBinc / iinc | 0b00 01 0100 | x | immediate | register | | 0b01 01 0100 | | | | | 0b01 01 0100
iBdec / idec | 0b00 01 0101 | x | immediate | register | | 0b01 01 0101 | | | | | 0b01 01 0101
iBand / iand | 0b00 01 0110 | register | immediate | register | | 0b01 01 0110 | | | | iBJE (equal) | 0b01 01 0110 | register | immediate | PC
iBor / ior | 0b00 01 0111 | register | immediate | register | | 0b01 01 0111 | | | | iBJNE (not equal) | 0b01 01 0111 | register | immediate | PC
iBxor / ixor | 0b00 01 1000 | register | immediate | register | | 0b01 01 1000 | | | | iBJA (above unsigned) | 0b01 01 1000 | register | immediate | PC
iBnot / inot | 0b00 01 1001 | x | immediate | register | | 0b01 01 1001 | | | | iBJB (below unsigned) | 0b01 01 1001 | register | immediate | PC
iBneg / ineg | 0b00 01 1010 | x | immediate | register | | 0b01 01 1010 | | | | iBJG (greater signed) | 0b01 01 1010 | register | immediate | PC
iBshl / ishl | 0b00 01 1011 | x | immediate | register | | 0b01 01 1011 | | | | iBJL (less signed) | 0b01 01 1011 | register | immediate | PC
iBshrl / ishrl | 0b00 01 1100 | x | immediate | register | | 0b01 01 1100 | | | | | 0b01 01 1100
iBshra / ishra | 0b00 01 1101 | x | immediate | register | | 0b01 01 1101 | | | | | 0b01 01 1101
iBrol / irol | 0b00 01 1110 | x | immediate | register | | 0b01 01 1110 | | | | | 0b01 01 1110
iBror / iror | 0b00 01 1111 | x | immediate | register | | 0b01 01 1111 | | | | | 0b01 01 1111
iAadd | 0b00 10 0000 | immediate | register | register | ivmov / ivmove | 0b01 10 0000 | immediate | (addr register) | register / RAM / IO | iAjz | 0b01 10 0000 | immediate | x | PC
iAadc | 0b00 10 0001 | immediate | register | register | ipush | 0b01 10 0001 | immediate | x | RAM | iAjnz | 0b01 10 0001 | immediate | x | PC
iAsub | 0b00 10 0010 | immediate | register | register | ipop | 0b01 10 0010 | immediate | x | register / IO | iAjs | 0b01 10 0010 | immediate | x | PC
iAmul | 0b00 10 0011 | immediate | register | register | ijmp | 0b01 10 0011 | immediate | x | register | iAjns | 0b01 10 0011 | immediate | x | PC
iAinc (unvalid) | 0b00 10 0100 | UNVALID | UNVALID | UNVALID | | 0b01 10 0100 | | | | iAjc | 0b01 10 0100 | immediate | x | PC
iAdec (unvalid) | 0b00 10 0101 | UNVALID | UNVALID | UNVALID | | 0b01 10 0101 | | | | iAjnc | 0b01 10 0101 | immediate | x | PC
iAand | 0b00 10 0110 | immediate | register | register | | 0b01 10 0110 | | | | iAje (equal) | 0b01 10 0110 | immediate | register | PC
iAor | 0b00 10 0111 | immediate | register | register | | 0b01 10 0111 | | | | iAjne (not equal) | 0b01 10 0111 | immediate | register | PC
iAxor | 0b00 10 1000 | immediate | register | register | | 0b01 10 1000 | | | | iAja (above unsigned) | 0b01 10 1000 | immediate | register | PC
iAnot (unvalid) | 0b00 10 1001 | UNVALID | UNVALID | UNVALID | | 0b01 10 1001 | | | | iAjb (below unsigned) | 0b01 10 1001 | immediate | register | PC
iAneg (unvalid) | 0b00 10 1010 | UNVALID | UNVALID | UNVALID | | 0b01 10 1010 | | | | iAjg (greater signed) | 0b01 10 1010 | immediate | register | PC
iAshl (unvalid) | 0b00 10 1011 | UNVALID | UNVALID | UNVALID | | 0b01 10 1011 | | | | iAjl (less signed) | 0b01 10 1011 | immediate | register | PC
iAshrl (unvalid) | 0b00 10 1100 | UNVALID | UNVALID | UNVALID | | 0b01 10 1100 | | | | iAjp / iAjpe (even parity) | 0b01 10 1100 | immediate | x | PC
iAshra (unvalid) | 0b00 10 1101 | UNVALID | UNVALID | UNVALID | | 0b01 10 1101 | | | | iAjnp / iAjpo (odd parity) | 0b01 10 1101 | immediate | x | PC
iArol (unvalid) | 0b00 10 1110 | UNVALID | UNVALID | UNVALID | | 0b01 10 1110 | | | | iAjcz (last calc. zero) | 0b01 10 1110 | immediate | x | PC
iAror (unvalid) | 0b00 10 1111 | UNVALID | UNVALID | UNVALID | | 0b01 10 1111 | | | | iAjcnz (last calc. not zero) | 0b01 10 1111 | immediate | x | PC
iABadd | 0b00 11 0000 | immediate | immediate | register | | 0b01 11 0000 | | | | | 0b01 11 0000
iABadc | 0b00 11 0001 | immediate | immediate | register | | 0b01 11 0001 | | | | | 0b01 11 0001
iABsub | 0b00 11 0010 | immediate | immediate | register | | 0b01 11 0010 | | | | | 0b01 11 0010
iABsbb | 0b00 11 0011 | immediate | immediate | register | | 0b01 11 0011 | | | | | 0b01 11 0011
iABinc (unvalid) | 0b00 11 0100 | UNVALID | UNVALID | UNVALID | | 0b01 11 0100 | | | | | 0b01 11 0100
iABdec (unvalid) | 0b00 11 0101 | UNVALID | UNVALID | UNVALID | | 0b01 11 0101 | | | | | 0b01 11 0101
iABand | 0b00 11 0110 | immediate | immediate | register | | 0b01 11 0110 | | | | iABJE (equal) | 0b01 11 0110 | immediate | immediate | PC
iABor | 0b00 11 0111 | immediate | immediate | register | | 0b01 11 0111 | | | | iABJNE (not equal) | 0b01 11 0111 | immediate | immediate | PC
iABxor | 0b00 11 1000 | immediate | immediate | register | | 0b01 11 1000 | | | | iABJA (above unsigned) | 0b01 11 1000 | immediate | immediate | PC
iABnot (unvalid) | 0b00 11 1001 | UNVALID | UNVALID | UNVALID | | 0b01 11 1001 | | | | iABJB (below unsigned) | 0b01 11 1001 | immediate | immediate | PC
iABneg (unvalid) | 0b00 11 1010 | UNVALID | UNVALID | UNVALID | | 0b01 11 1010 | | | | iABJG (greater signed) | 0b01 11 1010 | immediate | immediate | PC
iABshl (unvalid) | 0b00 11 1011 | UNVALID | UNVALID | UNVALID | | 0b01 11 1011 | | | | iABJL (less signed) | 0b01 11 1011 | immediate | immediate | PC
iABshrl (unvalid) | 0b00 11 1100 | UNVALID | UNVALID | UNVALID | | 0b01 11 1100 | | | | | 0b01 11 1100
iABshra (unvalid) | 0b00 11 1101 | UNVALID | UNVALID | UNVALID | | 0b01 11 1101 | | | | | 0b01 11 1101
iABrol (unvalid) | 0b00 11 1110 | UNVALID | UNVALID | UNVALID | | 0b01 11 1110 | | | | | 0b01 11 1110
iABror (unvalid) | 0b00 11 1111 | UNVALID | UNVALID | UNVALID | | 0b01 11 1111 | | | | | 0b01 11 1111

# Instructionset LED+ architecture

# condition condition condition

# calculate

# condition

# move move move move

# calculate calculate calculate

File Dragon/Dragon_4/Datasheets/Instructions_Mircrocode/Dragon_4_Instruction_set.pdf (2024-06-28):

237/255

## Instructions

Flags | OP-Code | Instruction | OP-Code | 32 | 31 | 30 | 29 | 28 | 27 | 26 | 25 24 | 23 | 22 | 21 | 20 | 19 | 18 | 17 16 | 15 | 14 | 13 | 12 | 11 | 10 | 9 8 | 7 | 6 | 5 | 4 | 3 | 2 | 1 | Step | Memlayout address
xxxx | 0x00 | NOP | 0000 0000 | | | | | | | | | | | | | | | | | | | | | 12 | | | | | | | | | | | | 001 010 | OP-Code 0
| | | | 32
xxxx | 0x01 | MOV A const. | 0000 0001 | | | | | | | | | | | | | | | | | | | | | 12 | | | | | | | | | | | | 001 010 011 | OP-Code 0 const. 1
| | | | | | | | | | | | | | | | | | | | | | | | 12 | | | 9 | | | | 5 | 4 | | 2
| | | | 32
xxxx | 0x02 | MOV B const. | 0000 0010 | | | | | | | | | | | | | | | | | | | | | 12 | | | | | | | | | | | | 001 010 011 | OP-Code 0 const. 1
| | | | | | | | | | | | | | | | | | | | | | | | 12 | | | 9 | | | 6 | | 4 | | 2
| | | | 32
xxxx | 0x03 | MOV C const. | 0000 0011 | | | | | | | | | | | | | | | | | | | | | 12 | | | | | | | | | | | | 001 010 011 | OP-Code 0 const. 1
| | | | | | | | | | | | | | | | | | | | | | | | 12 | | | 9 | | | 6 | 5 | 4 | | 2
| | | | 32
xxxx | 0x04 | MOV D const. | 0000 0100 | | | | | | | | | | | | | | | | | | | | | 12 | | | | | | | | | | | | 001 010 011 | OP-Code 0 const. 1
| | | | | | | | | | | | | | | | | | | | | | | | 12 | | | 9 | | 7 | | | 4 | | 2
| | | | 32
xxxx | 0x05 | MOV X const. | 0000 0101 | | | | | | | | | | | | | | | | | | | | | 12 | | | | | | | | | | | | 001 010 011 | OP-Code 0 const. 1
| | | | | | | | | | | | | | | | | | | | | | | | 12 | | | 9 | | 7 | | 5 | 4 | | 2
| | | | 32
xxxx | 0x06 | MOV Xfer_R const. | 0000 0110 | | | | | | | | | | | | | | | | | | | | | 12 | | | | | | | | | | | | 001 010 011 | OP-Code 0 const. 1
| | | | | | | | | | | | | | | | | | | | | | | | 12 | | | 9 8 | | 7 | | 5 | 4 | | 2
| | | | 32
xxxx | 0x07 | MOV Xfer_L const. | 0000 0111 | | | | | | | | | | | | | | | | | | | | | 12 | | | | | | | | | | | | 001 010 011 | OP-Code 0 const. 1
| | | | | | | | | | | | | | | | | | | | | | | | 12 | | | 9 8 | | 7 | 6 | | 4 | | 2
| | | | 32
xxxx | 0x08 | MOV A B | 0000 1000 | | | | | | | | | | | | | | | | | | | | | 12 | | | | | | | 5 | | | 2 | | 001 010 | OP-Code 0
| | | | 32
xxxx | 0x09 | MOV A C | 0000 1001 | | | | | | | | | | | | | | | | | | | | | 12 | | | | | | | 5 | | | 2 | 1 | 001 010 | OP-Code 0
| | | | 32
xxxx | 0x0a | MOV A D | 0000 1010 | | | | | | | | | | | | | | | | | | | | | 12 | | | | | | | 5 | | 3 | | | 001 010 | OP-Code 0
| | | | 32
xxxx | 0x0b | MOV A X | 0000 1011 | | | | | | | | | | | | | | | | | | | | | 12 | | | | | | | 5 | | 3 | | 1 | 001 010 | OP-Code 0
| | | | 32
xxxx | 0x0c | MOV A Xfer_R | 0000 1100 | | | | | | | | | | | | | | | | | | | | | 12 | | | | | | | 5 | 4 | 3 | | 1 | 001 010 | OP-Code 0
| | | | 32
xxxx | 0x0d | MOV A Xfer_L | 0000 1101 | | | | | | | | | | | | | | | | | | | | | 12 | | | | | | | 5 | 4 | 3 | 2 | | 001 010 | OP-Code 0
| | | | 32
xxxx | 0x0e | MOV B A | 0000 1110 | | | | | | | | | | | | | | | | | | | | | 12 | | | | | | 6 | | | | | 1 | 001 010 | OP-Code 0
| | | | 32
xxxx | 0x0f | MOV B C | 0000 1111 | | | | | | | | | | | | | | | | | | | | | 12 | | | | | | 6 | | | | 2 | 1 | 001 010 | OP-Code 0
| | | | 32
xxxx | 0x10 | MOV B D | 0001 0000 | | | | | | | | | | | | | | | | | | | | | 12 | | | | | | 6 | | | 3 | | | 001 010 | OP-Code 0
| | | | 32
xxxx | 0x11 | MOV B X | 0001 0001 | | | | | | | | | | | | | | | | | | | | | 12 | | | | | | 6 | | | 3 | | 1 | 001 010 | OP-Code 0
| | | | 32
xxxx | 0x12 | MOV B Xfer_R | 0001 0010 | | | | | | | | | | | | | | | | | | | | | 12 | | | | | | 6 | | 4 | 3 | | 1 | 001 010 | OP-Code 0
| | | | 32
xxxx | 0x13 | MOV B Xfer_L | 0001 0011 | | | | | | | | | | | | | | | | | | | | | 12 | | | | | | 6 | | 4 | 3 | 2 | | 001 010 | OP-Code 0
| | | | 32
xxxx | 0x14 | MOV C A | 0001 0100 | | | | | | | | | | | | | | | | | | | | | 12 | | | | | | 6 | 5 | | | | 1 | 001 010 | OP-Code 0
| | | | 32
xxxx | 0x15 | MOV C B | 0001 0101 | | | | | | | | | | | | | | | | | | | | | 12 | | | | | | 6 | 5 | | | 2 | | 001 010 | OP-Code 0
| | | | 32
xxxx | 0x16 | MOV C D | 0001 0110 | | | | | | | | | | | | | | | | | | | | | 12 | | | | | | 6 | 5 | | 3 | | | 001 010 | OP-Code 0
| | | | 32
xxxx | 0x17 | MOV C X | 0001 0111 | | | | | | | | | | | | | | | | | | | | | 12 | | | | | | 6 | 5 | | 3 | | 1 | 001 010 | OP-Code 0
| | | | 32
xxxx | 0x18 | MOV C Xfer_R | 0001 1000 | | | | | | | | | | | | | | | | | | | | | 12 | | | | | | 6 | 5 | 4 | 3 | | 1 | 001 010 | OP-Code 0
| | | | 32
xxxx | 0x19 | MOV C Xfer_L | 0001 1001 | | | | | | | | | | | | | | | | | | | | | 12 | | | | | | 6 | 5 | 4 | 3 | 2 | | 001 010 | OP-Code 0
| | | | 32
xxxx | 0x1a | MOV D A | 0001 1010 | | | | | | | | | | | | | | | | | | | | | 12 | | | | | 7 | | | | | | 1 | 001 010 | OP-Code 0
| | | | 32
xxxx | 0x1b | MOV D B | 0001 1011 | | | | | | | | | | | | | | | | | | | | | 12 | | | | | 7 | | | | | 2 | | 001 010 | OP-Code 0
| | | | 32
xxxx | 0x1c | MOV D C | 0001 1100 | | | | | | | | | | | | | | | | | | | | | 12 | | | | | 7 | | | | | 2 | 1 | 001 010 | OP-Code 0
| | | | 32
xxxx | 0x1d | MOV D X | 0001 1101 | | | | | | | | | | | | | | | | | | | | | 12 | | | | | 7 | | | | 3 | | 1 | 001 010 | OP-Code 0
| | | | 32
xxxx | 0x1e | MOV D Xfer_R | 0001 1110 | | | | | | | | | | | | | | | | | | | | | 12 | | | | | 7 | | | 4 | 3 | | 1 | 001 010 | OP-Code 0
| | | | 32
xxxx | 0x1f | MOV D Xfer_L | 0001 1111 | | | | | | | | | | | | | | | | | | | | | 12 | | | | | 7 | | | 4 | 3 | 2 | | 001 010 | OP-Code 0
| | | | 32
xxxx | 0x20 | MOV X A | 0010 0000 | | | | | | | | | | | | | | | | | | | | | 12 | | | | | 7 | | 5 | | | | 1 | 001 010 | OP-Code 0
| | | | 32
xxxx | 0x21 | MOV X B | 0010 0001 | | | | | | | | | | | | | | | | | | | | | 12 | | | | | 7 | | 5 | | | 2 | | 001 010 | OP-Code 0
| | | | 32
xxxx | 0x22 | MOV X C | 0010 0010 | | | | | | | | | | | | | | | | | | | | | 12 | | | | | 7 | | 5 | | | 2 | 1 | 001 010 | OP-Code 0
| | | | 32
xxxx | 0x23 | MOV X D | 0010 0011 | | | | | | | | | | | | | | | | | | | | | 12 | | | | | 7 | | 5 | | 3 | | | 001 010 | OP-Code 0
| | | | 32
xxxx | 0x24 | MOV X Xfer_R | 0010 0100 | | | | | | | | | | | | | | | | | | | | | 12 | | | | | 7 | | 5 | 4 | 3 | | 1 | 001 010 | OP-Code 0
| | | | 32
xxxx | 0x25 | MOV X Xfer_L | 0010 0101 | | | | | | | | | | | | | | | | | | | | | 12 | | | | | 7 | | 5 | 4 | 3 | 2 | | 001 010 | OP-Code 0
| | | | 32
xxxx | 0x26 | MOV Xfer_R A | 0010 0110 | | | | | | | | | | | | | | | | | | | | | 12 | | | | 8 | 7 | | 5 | | | | 1 | 001 010 | OP-Code 0
| | | | 32
xxxx | 0x27 | MOV Xfer_R B | 0010 0111 | | | | | | | | | | | | | | | | | | | | | 12 | | | 8 | | 7 | | 5 | | | 2 | | 001 010 | OP-Code 0
| | | | 32
xxxx | 0x28 | MOV Xfer_R C | 0010 1000 | | | | | | | | | | | | | | | | | | | | | 12 | | | 8 | | 7 | | 5 | | | 2 | 1 | 001 010 | OP-Code 0
| | | | 32
xxxx | 0x29 | MOV Xfer_R D | 0010 1001 | | | | | | | | | | | | | | | | | | | | | 12 | | | | 8 | 7 | | 5 | | 3 | | | 001 010 | OP-Code 0
| | | | 32
xxxx | 0x2a | MOV Xfer_R X | 0010 1010 | | | | | | | | | | | | | | | | | | | | | 12 | | | 8 | | 7 | | 5 | | 3 | | 1 | 001 | OP-Code 0

xxxx | 0x2b | MOV Xfer_R | Xfer_L | 0010 1011 | 12
2 | 001 | OP-Code
xxxx | 0x2c | A MOV Xfer_L | 0010 1100 | | 12 | | 8 | 7 | 6 | | | | | 1 | 001 010 | OP-Code 0
| | | | 32
xxxx | 0x2d | MOV Xfer_L B | 0010 1101 | | | 12 | | | | 8 | 7 | 6 | | | | 2 | | 001 010 | OP-Code 0
| | | | 32
xxxx | 0x2e | C MOV Xfer_L | 0010 1110 | | | 12 | | | 8 | | 7 | 6 | | | | 2 | 1 | 001 010 | OP-Code 0
| | | | 32
xxxx | 0x2f | MOV Xfer_L D | 0010 1111 | | | 12 | | | 8 | | 7 | 6 | | | 3 | | | 001 010 | OP-Code 0
| | | | 32
xxxx | 0x30 | X MOV Xfer_L | 0011 0000 | | | 12 | | | | 8 | 7 | 6 | | | 3 | | 1 | 001 010 | OP-Code 0
| | | | 32
xxxx | 0x31 | MOV Xfer_L Xfer_R | 0011 0001 | | | 12 | | | 8 | | 7 | 6 | | 4 | 3 | | 1 | 001 010 | OP-Code 0
| | | | 32
xxxx | 0x32 | MOV PC Xfer | 0011 0010 | | | 12 | | | | | 7 | 6 | | 4 | 3 | | | 001 010 | OP-Code 0
| | | | 32
xxxx | 0x33 | MOV PC SP | 0011 0011 | | | 12 | | | | | 7 | 6 | | | 3 | 2 | 1 | 001 010 | OP-Code 0
| | | | 32
xxxx | 0x34 | MOV PC CREG | 0011 0100 | | | 12 | | | | | 7 | 6 | | 4 | | | | 001 010 | OP-Code 0
| | | | 32
xxxx | 0x35 | MOV SP Xfer | 0011 0101 | | | 12 | | | | | 7 | 6 | 5 | 4 | 3 | | | 001 010 | OP-Code 0
| | | | 32
xxxx | 0x36 | MOV SP PC | 0011 0110 | | | 12 | | | | | 7 | 6 | 5 | | 3 | 2 | | 001 010 | OP-Code 0
| | | | 32
xxxx | 0x37 | MOV SP CREG | 0011 0111 | | | 12 | | | | | 7 | 6 | 5 | 4 | | | | 001 010 | OP-Code 0
| | | | 32
xxxx | 0x38 | MOV CREG Xfer | 0011 1000 | | | 12 | | | 8 | | | | | 4 | 3 | | | 001 010 | OP-Code 0
| | | | 32
xxxx | 0x39 | MOV CREG PC | 0011 1001 | | | 12 | | | 8 | | | | | | 3 | 2 | | 001 010 | OP-Code 0
| | | | 32
xxxx | 0x3a | MOV CREG SP | 0011 1010 | | | 12 | | | | 8 | | | | | 3 | 2 | 1 | 001 010 | OP-Code 0
| | | | 32
xxxx | 0x3b | MOV Xfer PC | 0011 1011 | | | 12 | | | 8 | | 7 | | | | 3 | 2 | | 001 010 | OP-Code 0
| | | | 32
xxxx | 0x3c | MOV Xfer SP | 0011 1100 | | | 12 | | | 8 | | 7 | | | | 3 | 2 | 1 | 001 010 | OP-Code 0
| | | | 32
xxxx | 0x3d | MOV Xfer CREG | 0011 1101 | | | 12 | | | | 8 | 7 | | | 4 | | | | 001 010 | OP-Code 0
| | | | 32
xxxx | 0x3e | MOV A addr | 0011 1110 | | | 12 | | | | | | | | | | | | 001 010 011 100 101 | OP-Code 0 addr 1 addr 2
| | | | | | 12 | | | 9 8 | | 7 | | 5 | 4 | | 2
| | | | | | 12 | | | 9 8 | | 7 | 6 | | 4 | | 2
| | | | | | | 11 | | | | | | 5 | 4 | | 2
| | | | 32
xxxx | 0x3f | MOV B addr | 0011 1111 | | | 12 | | | | | | | | | | | | 001 010 011 100 101 | OP-Code 0 addr 1 addr 2
| | | | | | 12 | | | 9 | 8 | 7 | | 5 | 4 | | 2
| | | | | | 12 | | | 9 8 | | 7 | 6 | | 4 | | 2
| | | | | | | 11 | | | | | 6 | | 4 | | 2
| | | | 32
xxxx | 0x40 | MOV C addr | 0100 0000 | | | 12 | | | | | | | | | | | | 001 010 011 100 101 | OP-Code 0 addr 1 addr 2
| | | | | | 12 | | | 9 8 | | 7 | | 5 | 4 | | 2
| | | | | | 12 | | | 9 8 | | 7 | 6 | | 4 | | 2
| | | | | | | 11 | | | | | 6 | 5 | 4 | | 2
| | | | 32
xxxx | 0x41 | MOV D addr | 0100 0001 | | | 12 | | | | | | | | | | | | 001 010 011 100 101 | OP-Code 0 addr 1 addr 2
| | | | | | 12 | | | 9 8 | | 7 | | 5 | 4 | | 2
| | | | | | 12 | | | 9 | 8 | 7 | 6 | | 4 | | 2
| | | | | | | 11 | | | | 7 | | | 4 | | 2
| | | | 32
xxxx | 0x42 | MOV X addr | 0100 0010 | | | 12 | | | | | | | | | | | | 001 010 011 100 101 | OP-Code 0 addr 1 addr 2
| | | | | | 12 | | | 9 8 | | 7 | | 5 | 4 | | 2
| | | | | | 12 | | | 9 8 | | 7 | 6 | | 4 | | 2
| | | | | | | 11 | | | | 7 | | 5 | 4 | | 2
| | | | 32
xxxx | 0x43 | MOV Xfer_R addr | 0100 0011 | | | 12 | | | | | | | | | | | | 001 010 011 100 101 | OP-Code 0 addr 1 addr 2
| | | | | | 12 | | | 9 8 | | 7 | | 5 | 4 | | 2
| | | | | | 12 | | | 9 8 | | 7 | 6 | | 4 | | 2
| | | | | | | 11 | | | 8 | 7 | | 5 | 4 | | 2
| | | | 32
xxxx | 0x44 | MOV Xfer_L addr | 0100 0100 | | | 12 | | | | | | | | | | | | 001 010 011 100 101 | OP-Code 0 addr 1 addr 2
| | | | | | 12 | | | 9 | 8 | 7 | | 5 | 4 | | 2
| | | | | | 12 | | | 9 8 | | 7 | 6 | | 4 | | 2
| | | | | | | 11 | | 8 | | 7 | 6 | | 4 | | 2
| | | | 32
xxxx | 0x45 | MOV addr A | 0100 0101 | | | 12 | | | | | | | | | | | | 001 010 011 100 101 | OP-Code 0 addr 1 addr 2
| | | | | | 12 | | | 9 8 | | 7 | | 5 | 4 | | 2
| | | | | | 12 | | | 9 | 8 | 7 | 6 | | 4 | | 2
| | | | | | | 11 | | 8 | | | | 5 | | | | 1
| | | | 32
xxxx | 0x46 | MOV addr B | 0100 0110 | | | 12 | | | | | | | | | | | | 001 010 011 100 101 | OP-Code 0 addr 1 addr 2
| | | | | | 12 | | | 9 8 | | 7 | | 5 | 4 | | 2
| | | | | | 12 | | | 9 | 8 | 7 | 6 | | 4 | | 2
| | | | | | | 11 | | 8 | | | | 5 | | | 2
| | | | 32
xxxx | 0x47 | MOV addr C | 0100 0111 | | | 12 | | | | | | | | | | | | 001 010 011 100 101 | OP-Code 0 addr 1 addr 2
| | | | | | 12 | | | 9 8 | | 7 | | 5 | 4 | | 2
| | | | | | 12 | | | 9 8 | | 7 | 6 | | 4 | | 2
| | | | | | | 11 | | | 8 | | | 5 | | | 2 | 1
| | | | 32
xxxx | 0x48 | D MOV addr | 0100 1000 | | | 12 | | | | | | | | | | | | 001 010 011 100 101 | OP-Code 0 addr 1 addr 2
| | | | | | 12 | | | 9 8 | | 7 | | 5 | 4 | | 2
| | | | | | 12 | | | 9 8 | | 7 | 6 | | 4 | | 2
| | | | | | | 11 | | 8 | | | | 5 | | 3
| | | | 32

xxxx | 0x49 | MOV | addr
X | 0100 1001 | 12 | 001 | OP-Code
2 | 010 | addr
12 | | 9 8 | 7 | 6 | | 4
| 11 | 8 | | | 5 | | 3
2 | 011 | addr

2
1 | 100
32 | 101
xxxx | 0x4a JMP const. 0100 1010 | | 12 | | | | | | | | | | 001 010 011 100 101 | OP-Code 0 const. 1 const. 2
| | | 12 | | 9 8 | 7 | | 5 | 4 | | 2
| | | | | 9 8 | 7 | 6 | | 4 | | 2
| | | | | | 7 | 6 | | 4 | 3
| | 32
xxxx | 0x4b JMP Xfer 0100 1011 | | | | | 7 | 6 | | 4 | 3 | | | 001 010 | OP-Code 0
| | 32
xxxx | 0x4c JMP SP 0100 1100 | | | | | 7 | 6 | | | 3 | 2 | 1 | 001 010 | OP-Code 0
| | 32
xxxx | 0x4d JMP CREG 0100 1101 | | | | | 7 | 6 | | 4 | | | | 001 010 | OP-Code 0
32
0001 0000 | 0x4e JC const. 0100 1110 0x4e 0100 1110 | | 12 | | | | | | | | | | 001 010 011 100 101 001 010 | OP-Code 0 const. 1 const. 2
| | | 12 | | 9 8 | 7 | | 5 | 4 | | 2
| | | | | 9 | 8 | 7 | 6 | | 4 | | 2
| | | | | | | 7 | 6 | | 4 | 3
32 | | | 12

32
0001 0000 | 0x4f JC Xfer 0100 1111 0x4f 0100 1111 | | | | | 7 | 6 | | 4 | 3 | | | 001 010 001 010 | OP-Code 0
| | 32 | 12

32
0001 0000 | 0x50 JC Sp 0101 0000 0x50 0101 0000 | | | | | 7 | 6 | | | 3 | 2 | 1 | 001 010 001 010 | OP-Code 0
| | 32 | 12
| | 32
0001 0000 | 0x51 JC CREG 0101 0001 0x51 0101 0001 | | | | | 7 | 6 | | 4 | | | | 001 010 001 010 | OP-Code 0
| | 32 | 12
| | 32
0000 0001 | 0x52 JNC const. 0101 0010 0x52 0101 0010 | | | 12 | | | | | | | | | | | | 001 010 011 100 101 001 010 | OP-Code 0 const. 1 const. 2
| | | | 12 | | | 9 8 | | 7 | | 5 | 4 | | 2
| | | | | | | 9 8 | | 7 | 6 | | 4 | | 2
| | | | | | | | | 7 | 6 | | 4 | 3
| | 32 | | 12
| | 32
0000 0001 | 0x53 JNC Xfer 0101 0011 0x53 0101 0011 | | | | | | | | 7 | 6 | | 4 | 3 | | | 001 010 001 010 | OP-Code 0
| | 32 | | 12
| | 32
0000 0001 | 0x54 JNC Sp 0101 0100 0x54 0101 0100 | | | | | | | | 7 | 6 | | | 3 | 2 | 1 | 001 010 001 010 | OP-Code 0
| | 32 | | 12
| | 32
0000 0001 | 0x55 JNC CREG 0101 0101 0x55 0101 0101 | | | | | | | | 7 | 6 | | 4 | | | | 001 010 001 010 | OP-Code 0
| | 32 | | 12
| | 32
0010 0000 | 0x56 JZ const. 0101 0110 0x56 0101 0110 | | | 12 | | | | | | | | | | | | 001 010 011 100 101 001 010 | OP-Code 0 const. 1 const. 2
| | | | 12 | | | 9 8 | | 7 | | 5 | 4 | | 2
| | | | | | | 9 8 | | 7 | 6 | | 4 | | 2
| | | | | | | | | 7 | 6 | | 4 | 3
| | 32 | | 12
| | 32
0010 0000 | 0x57 JZ Xfer 0101 0111 0x57 0101 0111 | | | | | | | | 7 | 6 | | 4 | 3 | | | 001 010 001 010 | OP-Code 0
| | 32 | | 12
| | 32
0010 0000 | 0x58 JZ Sp 0101 1000 0x58 0101 1000 | | | | | | | | 7 | 6 | | | 3 | 2 | 1 | 001 010 001 010 | OP-Code 0
| | 32 | | 12
| | 32
0010 0000 | 0x59 JZ CREG 0101 1001 0x59 0101 1001 | | | | | | | | 7 | 6 | | 4 | | | | 001 010 001 010 | OP-Code 0
| | 32 | | 12
| | 32
0000 0010 | 0x5a JNZ const. 0101 1010 0x5a 0101 1010 | | | 12 | | | | | | | | | | | | 001 010 011 100 101 001 010 | OP-Code 0 const. 1 const. 2
| | | | 12 | | | 9 | 8 | 7 | | 5 | 4 | | 2
| | | | | | | 9 8 | | 7 | 6 | | 4 | | 2
| | | | | | | | | 7 | 6 | | 4 | 3
| | 32 | | 12
| | 32
0000 0010 | 0x5b JNZ Xfer 0101 1011 0x5b 0101 1011 | | | | | | | | 7 | 6 | | 4 | 3 | | | 001 010 001 010 | OP-Code 0
| | 32 | | 12
| | 32

0000 | 0x5c | JNZ | Sp | 0101 1100
1 | 001 | OP-Code
0010 | 0x5c | 0101 1100 | 12 | 001
32 | 010
0000 0010 | 0x5d JNZ CREG 0101 1101 0x5d 0101 1101 | | | | | | | | 7 | 6 | | 4 | | | | 001 010 001 010 | OP-Code 0
| | 32 | | | 12
| | 32
0100 0000 | 0x5e JS const. 0101 1110 0x5e 0101 1110 | | | | 12 | | | | | | | | | | | 001 010 011 100 101 001 010 | OP-Code 0 const. 1 const. 2
| | | | | 12 | | 9 8 | | 7 | | 5 | 4 | | 2
| | | | | | | 9 8 | | 7 | 6 | | 4 | | 2
| | | | | | | | | 7 | 6 | | 4 | 3
| | 32 | | | 12
| | 32
0100 0000 | 0x5f JS Xfer 0101 1111 0x5f 0101 1111 | | | | | | | | 7 | 6 | | 4 | 3 | | | 001 010 001 010 | OP-Code 0
| | 32 | | | 12
| | 32
0100 0000 | 0x60 JS Sp 0110 0000 0x60 0110 0000 | | | | | | | | 7 | 6 | | | 3 | 2 | 1 | 001 010 001 010 | OP-Code 0
| | 32 | | | 12
| | 32
0100 0000 | 0x61 JS CREG 0110 0001 0x61 0110 0001 | | | | | | | | 7 | 6 | | 4 | | | | 001 010 001 010 | OP-Code 0
| | 32 | | | 12
| | 32
0000 0100 | 0x62 JNS const. 0110 0010 0x62 0110 0010 | | | | 12 | | | | | | | | | | | 001 010 011 100 101 001 010 | OP-Code 0 const. 1 const. 2
| | | | | 12 | | 9 8 | | 7 | | 5 | 4 | | 2
| | | | | | | 9 | 8 | 7 | 6 | | 4 | | 2
| | | | | | | | | 7 | 6 | | 4 | 3
| | 32 | | | 12
| | 32
0000 0100 | 0x63 JNS Xfer 0110 0011 0x63 0110 0011 | | | | | | | | 7 | 6 | | 4 | 3 | | | 001 010 001 010 | OP-Code 0
| | 32 | | | 12
| | 32
0000 0100 | 0x64 JNS Sp 0110 0100 0x64 0110 0100 | | | | | | | | 7 | 6 | | | 3 | 2 | 1 | 001 010 001 010 | OP-Code 0
| | 32 | | | 12
| | 32
0000 0100 | 0x65 JNS CREG 0110 0101 0x65 0110 0101 | | | | | | | | 7 | 6 | | 4 | | | | 001 010 001 010 | OP-Code 0
| | 32 | | | 12
| | 32
xxxx | 0x66 CALL CREG 0110 0110 | | | | | | | 8 | 7 | | 5 | | 3 | 2 | | 001 010 011 100 101 110 | OP-Code 0
| | | | | | | 8 | | 7 | 6 | | | 3 | 2
| | | 15 | | | | | | 7 | 6 | | 4
| | | 15 | | | 10 | 8 | | | | 5 | 4 | 3 | | 1
| | | | | | 10 | 8 | | | | 5 | 4 | 3 | 2
| | 32
xxxx | 0x67 RETURN 0110 0111 | | | 13 | | 10 | 8 | | 7 | | 5 | 4 | | 2 | | 001 010 011 100 101 | OP-Code 0
| | | | 13 | | 10 | 8 | | 7 | 6 | | 4 | | 2
| | | | | | | | | 7 | 6 | | 4 | 3
| | | | | 12
| | 32
xxxx | 0x68 MOV CREG const. 0110 1000 | | | | 12 | | | | | | | | | | | 001 010 011 100 101 | OP-Code 0 const. 1 const. 2
| | | | | 12 | | 9 | 8 | 7 | | 5 | 4 | | 2
| | | | | 12 | | 9 | 8 | 7 | 6 | | 4 | | 2
| | | | | | | 8 | | | | | 4 | 3
| | 32
0001 0000 | 0x69 cMOVC A B 0110 1001 0x69 0110 1001 | | | | 12 | | | | | | 5 | | | 2 | | 001 010 001 010 | OP-Code 0
| | 32 | | | 12
| | 32
0001 0000 | 0x6a cMOVC B A 0110 1010 0x6a 0110 1010 | | | | 12 | | | | | 6 | | | | | 1 | 001 010 001 010 | OP-Code 0
| | 32 | | | 12
| | 32
0001 0000 | 0x6b cMOVC X A 0110 1001 0x6b 0110 1001 | | | | 12 | | | | 7 | | 5 | | | | 1 | 001 010 001 010 | OP-Code 0
| | 32 | | | 12
| | 32
0001 0000 | 0x6c cMOVC X B 0110 1010 0x6c 0110 1010 | | | | 12 | | | | 7 | | 5 | | | 2 | | 001 010 001 010 | OP-Code 0
| | 32 | | | 12
| | 32

0001 | 0x6d | cMOVC

A

X | 0110 1001 | 12
1 | 001 | OP-Code
0000 | 0x6d | 0110 1001 | 12 | 001
32 | 010
0001 0000 | 0x6e cMOVC B X 0110 1010 0x6e 0110 1010 | | 12 | 7 | 6 | 3 | 1 | 001 010 001 010 | OP-Code 0
| | 32 | 12
| | 32

OP-Code | Instruction | OP-Code | 32 | 31 | 30 | 29 | 28 | 27 | 26 | 25 24 | 23 | 22 | 21 | 20 | 19 | 18 | 17 16 | 15 | 14 | 13 | 12 | 11 | 10 | 9 8 | 7 | 6 | 5 | 4 | 3 | 2 | 1 | Step | Memlayout address
0x80 | PUSH A | 1000 0000 | | | | | | | | | | | | | | | | | | 15 | | | | | | | | | | | | | | | 001 010 011 | OP-Code 0
| | | | | | | | | | | | | | | | | | | | | | | | | 10 | 8 | | | | 5 | | | | 1
| | | 32
0x81 | PUSH B | 1000 0001 | | | | | | | | | | | | | | | | | | 15 | | | | | | | | | | | | | | | 001 010 011 | OP-Code 0
| | | | | | | | | | | | | | | | | | | | | | | | | 10 | 8 | | | | 5 | | | 2
| | | 32
0x82 | PUSH C | 1000 0010 | | | | | | | | | | | | | | | | | | 15 | | | | | | | | | | | | | | | 001 010 011 | OP-Code 0
| | | | | | | | | | | | | | | | | | | | | | | | | 10 | 8 | | | | 5 | | | 2 | 1
| | | 32
0x83 | PUSH D | 1000 0011 | | | | | | | | | | | | | | | | | | 15 | | | | | | | | | | | | | | | 001 010 011 | OP-Code 0
| | | | | | | | | | | | | | | | | | | | | | | | | 10 | 8 | | | | 5 | | 3
| | | 32
0x84 | PUSH X | 1000 0100 | | | | | | | | | | | | | | | | | | 15 | | | | | | | | | | | | | | | 001 010 011 | OP-Code 0
| | | | | | | | | | | | | | | | | | | | | | | | | 10 | 8 | | | | 5 | | 3 | | 1
| | | 32
0x85 | PUSH Xfer_R | 1000 0101 | | | | | | | | | | | | | | | | | | 15 | | | | | | | | | | | | | | | 001 010 011 | OP-Code 0
| | | | | | | | | | | | | | | | | | | | | | | | | 10 | 8 | | | | 5 | 4 | 3 | | 1
| | | 32
0x86 | PUSH Xfer_L | 1000 0110 | | | | | | | | | | | | | | | | | | 15 | | | | | | | | | | | | | | | 001 010 011 | OP-Code 0
| | | | | | | | | | | | | | | | | | | | | | | | | 10 | 8 | | | | 5 | 4 | 3 | 2
| | | 32
0x87 | PULL A | 1000 0111 | | | | | | | | | | | | | | | | | | | | | | | 10 | 8 | | 7 | 6 | 5 | | | | | 001 010 011 | OP-Code 0
| | | | | | | | | | | | | | | | | | | | | | 13 | | | | | | | | 5 | 4 | 3 | 2 | 1
| | | 32
0x88 | PULL B | 1000 1000 | | | | | | | | | | | | | | | | | | | | | | | 10 | 8 | | 7 | 6 | 5 | | | | | 001 010 011 | OP-Code 0
| | | | | | | | | | | | | | | | | | | | | | 13 | | | | | | | 6 | | 4 | 3 | 2 | 1
| | | 32
0x89 | PULL C | 1000 1001 | | | | | | | | | | | | | | | | | | | | | | | 10 | 8 | | 7 | 6 | 5 | | | | | 001 010 011 | OP-Code 0
| | | | | | | | | | | | | | | | | | | | | | 13 | | | | | | | 6 | 5 | 4 | 3 | 2 | 1
| | | 32
0x8a | PULL D | 1000 1010 | | | | | | | | | | | | | | | | | | | | | | | 10 | 8 | | 7 | 6 | 5 | | | | | 001 010 011 | OP-Code 0
| | | | | | | | | | | | | | | | | | | | | | 13 | | | | | | 7 | | | 4 | 3 | 2 | 1
| | | 32
0x8b | PULL X | 1000 1011 | | | | | | | | | | | | | | | | | | | | | | | 10 | 8 | | 7 | 6 | 5 | | | | | 001 010 011 | OP-Code 0
| | | | | | | | | | | | | | | | | | | | | | 13 | | | | | | 7 | | 5 | 4 | 3 | 2 | 1
| | | 32
0x8c | PULL Xfer_R | 1000 1100 | | | | | | | | | | | | | | | | | | | | | | | 10 | 8 | | 7 | 6 | 5 | | | | | 001 010 011 | OP-Code 0
| | | | | | | | | | | | | | | | | | | | | | 13 | | | | | 8 | 7 | | 5 | 4 | 3 | 2 | 1
| | | 32
0x8d | PULL Xfer_L | 1000 1101 | | | | | | | | | | | | | | | | | | | | | | | 10 | 8 | | 7 | 6 | 5 | | | | | 001 010 011 | OP-Code 0
| | | | | | | | | | | | | | | | | | | | | | 13 | | | | | 8 | 7 | 6 | | 4 | 3 | 2 | 1
| | | 32
0x8e | ADD A B | 1000 1110 | | | | | | | | | | | | 21 | | | | 17 16 | | | | | 12 | | | | | | | | | | | | 001 010 011 | OP-Code 0
| | | | | | | | | | | | | | | | | | | | | | | | | | | | | | 5 | 4 | | | 1
| | | 32
0x8f | ADD A C | 1000 1111 | | | | | | | | | | | | 21 | 20 | | | 17 16 | | | | | 12 | | | | | | | | | | | | 001 010 011 | OP-Code 0
| | | | | | | | | | | | | | | | | | | | | | | | | | | | | | 5 | 4 | | | 1
| | | 32
0x90 | ADD A D | 1001 0000 | | | | | | | | | | | 22 | | | | | 17 16 | | | | | 12 | | | | | | | | | | | | 001 010 011 | OP-Code 0
| | | | | | | | | | | | | | | | | | | | | | | | | | | | | | 5 | 4 | | | 1
| | | 32
0x91 ADD A X 1001 0001 | | | | | | | | | | | | | 22 | | 20 | | | 17 16 | | | | | 12 | | | | | | | | | | | | 001 010 011 | OP-Code 0
| | | | | | | | | | | | | | | | | | | | | | | | | | | | | | 5 | 4 | | | 1
| | | 32
0x92 ADD B C 1001 0010 | | | | | | | | | | | | | | 21 | 20 | | 18 | 16 | | | | | 12 | | | | | | | | | | | | 001 010 011 | OP-Code 0
| | | | | | | | | | | | | | | | | | | | | | | | | | | | | 6 | | 4 | | | 1
| | | 32
0x93 ADD B D 1001 0011 | | | | | | | | | | | | | 22 | | | | 18 | 16 | | | | | 12 | | | | | | | | | | | | 001 010 011 | OP-Code 0
| | | | | | | | | | | | | | | | | | | | | | | | | | | | | 6 | | 4 | | | 1
| | | 32
0x94 ADD B X 1001 0100 | | | | | | | | | | | | | 22 | | 20 | | 18 | | 16 | | | | 12 | | | | | | | | | | | | 001 010 011 | OP-Code 0
| | | | | | | | | | | | | | | | | | | | | | | | | | | | | 6 | | 4 | | | 1
| | | 32
0x95 ADD C D 1001 0101 | | | | | | | | | | | | | 22 | | | | 18 | 17 | 16 | | | | 12 | | | | | | | | | | | | 001 010 011 | OP-Code 0
| | | | | | | | | | | | | | | | | | | | | | | | | | | | | 6 | 5 | 4 | | | 1
| | | 32
0x96 ADD C X 1001 0110 | | | | | | | | | | | | | 22 | | 20 | | 18 | 17 | 16 | | | | 12 | | | | | | | | | | | | 001 010 011 | OP-Code 0
| | | | | | | | | | | | | | | | | | | | | | | | | | | | | 6 | 5 | 4 | | | 1
| | | 32
0x97 ADD D X 1001 0111 | | | | | | | | | | | | | 22 | | 20 | 19 | | | 16 | | | | 12 | | | | | | | | | | | | 001 010 011 | OP-Code 0
| | | | | | | | | | | | | | | | | | | | | | | | | | | | 7 | | | 4 | | | 1
| | | 32
0x98 ADC A B 1001 1000 | | | | | | | | | | 25 | | | | 21 | | | | 17 | 16 | | | | 12 | | | | | | | | | | | | 001 010 011 | OP-Code 0
| | | | | | | | | | | | | | | | | | | | | | | | | | | | | | 5 | 4 | | | 1
| | | 32
0x99 ADC A C 1001 1001 | | | | | | | | | | 25 | | | | 21 | 20 | | | 17 16 | | | | | 12 | | | | | | | | | | | | 001 010 011 | OP-Code 0
| | | | | | | | | | | | | | | | | | | | | | | | | | | | | | 5 | 4 | | | 1
| | | 32
0x9a ADC A D 1001 1010 | | | | | | | | | | 25 | | | 22 | | | | | 17 16 | | | | | 12 | | | | | | | | | | | | 001 010 011 | OP-Code 0
| | | | | | | | | | | | | | | | | | | | | | | | | | | | | | 5 | 4 | | | 1
| | | 32
0x9b ADC A X 1001 1011 | | | | | | | | | | 25 | | | 22 | | 20 | | | 17 16 | | | | | 12 | | | | | | | | | | | | 001 010 011 | OP-Code 0
| | | | | | | | | | | | | | | | | | | | | | | | | | | | | | 5 | 4 | | | 1
| | | 32
0x9c ADC B C 1001 1100 | | | | | | | | | | 25 | | | | 21 | 20 | | 18 | 16 | | | | | 12 | | | | | | | | | | | | 001 010 011 | OP-Code 0
| | | | | | | | | | | | | | | | | | | | | | | | | | | | | 6 | | 4 | | | 1
| | | 32
0x9d ADC B D 1001 1101 | | | | | | | | | | 25 | | | 22 | | | | 18 | 16 | | | | | 12 | | | | | | | | | | | | 001 010 011 | OP-Code 0
| | | | | | | | | | | | | | | | | | | | | | | | | | | | | 6 | | 4 | | | 1
| | | 32
0x9e ADC B X 1001 1110 | | | | | | | | | | 25 | | | 22 | | 20 | | 18 | 16 | | | | | 12 | | | | | | | | | | | | 001 010 | OP-Code 0
| | | | | | | | | | | | | | | | | | | | | | | | | | | | | 6 | | 4 | | | 1

## Instructions

0x9f ADC

C

D | 1001 1111 | 25 | 22 | 18 | 17 16 | 12 | 001 | OP-Code
32 | 011
0xa0 ADC C X 1010 0000 | | | | 25 | 22 | | 20 | | 18 | 17 16 | | | 12 | | | | | | | | 001 010 011 | OP-Code 0
| | | | | | | | | | | | | | | | | 6 | 5 | 4 | | | 1
32
X 1010 0001 0xa1 ADC D | | | | 25 | 22 | | 20 | 19 | | 16 | | | 12 | | | | | | | | 001 010 011 | OP-Code 0
| | | | | | | | | | | | | | | | 7 | | | 4 | | | 1
32
0xa2 SUB A B 1010 0010 | | | 26 | | | 21 | | | | 17 16 | | | 12 | | | | | | | | 001 010 011 | OP-Code 0
| | | | | | | | | | | | | | | | | | 5 | 4 | | | 1
32
0xa3 SUB A C 1010 0011 | | | 26 | | | 21 | 20 | | | 17 16 | | | 12 | | | | | | | | 001 010 011 | OP-Code 0
| | | | | | | | | | | | | | | | | | 5 | 4 | | | 1
32
0xa4 SUB A D 1010 0100 | | | 26 | | 22 | | | | | 17 16 | | | 12 | | | | | | | | 001 010 011 | OP-Code 0
| | | | | | | | | | | | | | | | 5 | 4 | | | 1
| 32
0xa5 SUB A X 1010 0101 | | | 26 | | 22 | | 20 | | | 17 16 | | | 12 | | | | | | | | 001 010 011 | OP-Code 0
| | | | | | | | | | | | | | | | 5 | 4 | | | 1
| 32
0xa6 SUB B A 1010 0110 | | | 26 | | | | 20 | | 18 | 16 | | | 12 | | | | | | | | 001 010 011 | OP-Code 0
| | | | | | | | | | | | | | | 6 | | 4 | | | 1
| 32
0xa7 SUB B C 1010 0111 | | | 26 | | | | 21 | 20 | | 18 | | 16 | | 12 | | | | | | | | | | 001 010 011 | OP-Code 0
| | | | | | | | | | | | | | | | | | 6 | | 4 | | | 1
| 32
0xa8 SUB B D 1010 1000 | | | 26 | | | 22 | | | | 18 | | 16 | | 12 | | | | | | | | | | 001 010 011 | OP-Code 0
| | | | | | | | | | | | | | | | | | 6 | | 4 | | | 1
| 32
0xa9 SUB B X 1010 1001 | | | 26 | | | 22 | | 20 | | 18 | | 16 | | 12 | | | | | | | | | | 001 010 011 | OP-Code 0
| | | | | | | | | | | | | | | | | | 6 | | 4 | | | 1
| 32
0xaa SUB C A 1010 1010 | | | 26 | | | | | 20 | | 18 | 17 | 16 | | 12 | | | | | | | | | | 001 010 011 | OP-Code 0
| | | | | | | | | | | | | | | | | | 6 | 5 | 4 | | | 1
| 32
0xab SUB C B 1010 1011 | | | 26 | | | | 21 | | | 18 | 17 | 16 | | 12 | | | | | | | | | | 001 010 011 | OP-Code 0
| | | | | | | | | | | | | | | | | | 6 | 5 | 4 | | | 1
| 32
0xac SUB C D 1010 1100 | | | 26 | | | 22 | | | | 18 | 17 16 | | | 12 | | | | | | | | | | 001 010 011 | OP-Code 0
| | | | | | | | | | | | | | | | | | 6 | 5 | 4 | | | 1
| 32
0xad SUB C X 1010 1101 | | | 26 | | | 22 | | 20 | | 18 | 17 16 | | | 12 | | | | | | | | | | 001 010 011 | OP-Code 0
| | | | | | | | | | | | | | | | | | 6 | 5 | 4 | | | 1
| 32
0xae SUB D A 1010 1110 | | | 26 | | | | | 20 | 19 | | 16 | | | 12 | | | | | | | | | | 001 010 011 | OP-Code 0
| | | | | | | | | | | | | | | | | 7 | | | 4 | | | 1
| 32
0xaf SUB D B 1010 1111 | | | 26 | | | | 21 | | 19 | | 16 | | | 12 | | | | | | | | | | 001 010 011 | OP-Code 0
| | | | | | | | | | | | | | | | | 7 | | | 4 | | | 1
| 32
0xb0 SUB D C 1011 0000 | | | 26 | | | | 21 | 20 | 19 | | 16 | | | 12 | | | | | | | | | | 001 010 011 | OP-Code 0
| | | | | | | | | | | | | | | | | 7 | | | 4 | | | 1
| 32
0xb1 SUB D X 1011 0001 | | | 26 | | | 22 | | 20 | 19 | | 16 | | | 12 | | | | | | | | | | 001 010 011 | OP-Code 0
| | | | | | | | | | | | | | | | | 7 | | | 4 | | | 1
| 32
0xb2 SUB X A 1011 0010 | | | 26 | | | | | 20 | 19 | | 17 16 | | | 12 | | | | | | | | | | 001 010 011 | OP-Code 0
| | | | | | | | | | | | | | | | | 7 | | 5 | 4 | | | 1
| 32
B 1011 0011 0xb3 SUB X | | | 26 | | | | 21 | | 19 | | 17 16 | | | 12 | | | | | | | | | | 001 010 011 | OP-Code 0
| | | | | | | | | | | | | | | | | 7 | | 5 | 4 | | | 1
| 32
0xb4 SUB X C 1011 0100 | | | 26 | | | | 21 | 20 | 19 | | 17 16 | | | 12 | | | | | | | | | | 001 010 011 | OP-Code 0
| | | | | | | | | | | | | | | | | 7 | | 5 | 4 | | | 1
| 32
0xb5 SUB X D 1011 0101 | | | 26 | | | 22 | | | 19 | | 17 16 | | | 12 | | | | | | | | | | 001 010 011 | OP-Code 0
| | | | | | | | | | | | | | | | | 7 | | 5 | 4 | | | 1
| 32
0xb6 SBB A B 1011 0110 | | | 26 | 25 | | | 21 | | | | 17 | 16 | | 12 | | | | | | | | | | 001 010 011 | OP-Code 0
| | | | | | | | | | | | | | | | | | | 5 | 4 | | | 1
| 32
0xb7 SBB B A 1011 0111 | | | 26 | 25 | | | | 20 | | 18 | | 16 | | 12 | | | | | | | | | | 001 010 011 | OP-Code 0
| | | | | | | | | | | | | | | | | | 6 | | 4 | | | 1
| 32
0xb8 SHL A 1011 1000 | | 27 | | | | | | | | | 17 | 16 | | 12 | | | | | | | | | | 001 010 011 | OP-Code 0
| | | | | | | | | | | | | | | | | | | 5 | 4 | | | 1
| 32
0xb9 SHL B 1011 1001 | | 27 | | | | | | | | 18 | 16 | | | 12 | | | | | | | | | | 001 010 011 | OP-Code 0
| | | | | | | | | | | | | | | | | | 6 | | 4 | | | 1
| 32
0xba SHL C 1011 1010 | | 27 | | | | | | | | 18 | 17 16 | | | 12 | | | | | | | | | | 001 010 011 | OP-Code 0
| | | | | | | | | | | | | | | | | | 6 | 5 | 4 | | | 1
| 32
0xbb SHL D 1011 1011 | | 27 | | | | | | | 19 | | 16 | | | 12 | | | | | | | | | | 001 010 011 | OP-Code 0
| | | | | | | | | | | | | | | | | 7 | | | 4 | | | 1
| 32
0xbc SHL X 1011 1100 | | 27 | | | | | | | 19 | | 17 16 | | | 12 | | | | | | | | | | 001 010 011 | OP-Code 0
| | | | | | | | | | | | | | | | | 7 | | 5 | 4 | | | 1
| 32
A 1011 1101 0xbd SHRA | | 27 | | 25 | | | | | | | 17 16 | | | 12 | | | | | | | | | | 001 010 011 | OP-Code 0
| | | | | | | | | | | | | | | | | | | 5 | 4 | | | 1
| 32

0xbe | SHRA
B | 1011 1110 | 27 | 25 | 18 | 16 | 12 | 001 | OP-Code
32 | 011
0xbf SHRA C 1011 1111 | | | 27 | | 25 | | | | 18 | 17 16 | | | 12 | | | | | | | | 001 010 011 | OP-Code 0
| | | | | | | | | | | | | | | | | 6 | 5 | 4 | | | 1
32
0xc0 SHRA D 1100 0000 | | | 27 | | 25 | | | 19 | | 16 | | | 12 | | | | | | | | 001 010 011 | OP-Code 0
| | | | | | | | | | | | | | | 7 | | 4 | | | 1
| 32
0xc1 SHRA X 1100 0001 | | | 27 | | 25 | | | 19 | | 17 16 | | | 12 | | | | | | | | 001 010 011 | OP-Code 0
| | | | | | | | | | | | | | | 7 | 5 | 4 | | | 1
| 32
0xc2 SHRL A 1100 0010 | | | 27 | 26 | | | | | | 17 16 | | | 12 | | | | | | | | 001 010 011 | OP-Code 0
| | | | | | | | | | | | | | | | 5 | 4 | | | 1
| 32
0xc3 SHRL B 1100 0011 | | | 27 | 26 | | | | | | 18 | | 16 | | 12 | | | | | | | | | | 001 010 011 | OP-Code 0
| | | | | | | | | | | | | | | | | | 6 | | 4 | | | 1
| 32
0xc4 SHRL C 1100 0100 | | | 27 | 26 | | | | | | 18 | 17 | 16 | | 12 | | | | | | | | | | 001 010 011 | OP-Code 0
| | | | | | | | | | | | | | | | | | 6 | 5 | 4 | | | 1
| 32
0xc5 SHRL D 1100 0101 | | | 27 | 26 | | | | | 19 | | | 16 | | 12 | | | | | | | | | | 001 010 011 | OP-Code 0
| | | | | | | | | | | | | | | | | 7 | | | 4 | | | 1
| 32
0xc6 SHRL X 1100 0110 | | | 27 | 26 | | | | | 19 | | 17 | 16 | | 12 | | | | | | | | | | 001 010 011 | OP-Code 0
| | | | | | | | | | | | | | | | | 7 | | 5 | 4 | | | 1
| 32
0xc7 INC A 1100 0111 | | | 27 | 26 | 25 | | | | | | 17 16 | | | 12 | | | | | | | | | | 001 010 011 | OP-Code 0
| | | | | | | | | | | | | | | | | | | 5 | 4 | | | 1
| 32
0xc8 INC B 1100 1000 | | | 27 | 26 | 25 | | | | | 18 | 16 | | | 12 | | | | | | | | | | 001 010 011 | OP-Code 0
| | | | | | | | | | | | | | | | | | 6 | | 4 | | | 1
| 32
0xc9 INC C 1100 1001 | | | 27 | 26 | 25 | | | | | 18 | 17 16 | | | 12 | | | | | | | | | | 001 010 011 | OP-Code 0
| | | | | | | | | | | | | | | | | | 6 | 5 | 4 | | | 1
| 32
0xca INC D 1100 1010 | | | 27 | 26 | 25 | | | | 19 | | 16 | | | 12 | | | | | | | | | | 001 010 011 | OP-Code 0
| | | | | | | | | | | | | | | | | 7 | | | 4 | | | 1
| 32
0xcb INC X 1100 1011 | | | 27 | 26 | 25 | | | | 19 | | 17 16 | | | 12 | | | | | | | | | | 001 010 011 | OP-Code 0
| | | | | | | | | | | | | | | | | 7 | | 5 | 4 | | | 1
| 32
0xcc AND A B 1100 1100 | | 28 | | | | | 21 | | | | 17 16 | | | 12 | | | | | | | | | | 001 010 011 | OP-Code 0
| | | | | | | | | | | | | | | | | | | 5 | 4 | | | 1
| 32
0xcd AND A C 1100 1101 | | 28 | | | | | 21 | 20 | | | 17 16 | | | 12 | | | | | | | | | | 001 010 011 | OP-Code 0
| | | | | | | | | | | | | | | | | | | 5 | 4 | | | 1
| 32
0xce AND A D 1100 1110 | | 28 | | | | 22 | | | | | 17 16 | | | 12 | | | | | | | | | | 001 010 011 | OP-Code 0
| | | | | | | | | | | | | | | | | | | 5 | 4 | | | 1
| 32
0xcf AND A X 1100 1111 | | 28 | | | | 22 | | 20 | | | 17 16 | | | 12 | | | | | | | | | | 001 010 011 | OP-Code 0
| | | | | | | | | | | | | | | | | | | 5 | 4 | | | 1
| 32
0xd0 AND B C 1101 0000 | | 28 | | | | | 21 | 20 | | 18 | | 16 | | 12 | | | | | | | | | | 001 010 011 | OP-Code 0
| | | | | | | | | | | | | | | | | | 6 | | 4 | | | 1
| 32
0xd1 AND B D 1101 0001 | | 28 | | | | 22 | | | | 18 | | 16 | | 12 | | | | | | | | | | 001 010 011 | OP-Code 0
| | | | | | | | | | | | | | | | | | 6 | | 4 | | | 1
| 32
0xd2 AND B X 1101 0010 | | 28 | | | | 22 | | 20 | | 18 | | 16 | | 12 | | | | | | | | | | 001 010 011 | OP-Code 0
| | | | | | | | | | | | | | | | | | 6 | | 4 | | | 1
| 32
0xd3 AND C D 1101 0011 | | 28 | | | | 22 | | | | 18 | 17 16 | | | 12 | | | | | | | | | | 001 010 011 | OP-Code 0
| | | | | | | | | | | | | | | | | | 6 | 5 | 4 | | | 1
| 32
0xd4 AND C X 1101 0100 | | 28 | | | | 22 | | 20 | | 18 | 17 16 | | | 12 | | | | | | | | | | 001 010 011 | OP-Code 0
| | | | | | | | | | | | | | | | | | 6 | 5 | 4 | | | 1
| 32
0xd5 AND D X 1101 0101 | | 28 | | | | 22 | | 20 | 19 | | 16 | | | 12 | | | | | | | | | | 001 010 011 | OP-Code 0
| | | | | | | | | | | | | | | | | 7 | | | 4 | | | 1
| 32
0xd6 OR A B 1101 0110 | | 28 | | | 25 | | 21 | | | | 17 16 | | | 12 | | | | | | | | | | 001 010 011 | OP-Code 0
| | | | | | | | | | | | | | | | | | | 5 | 4 | | | 1
| 32
C 1101 0111 0xd7 OR A | | 28 | | | 25 | | 21 | 20 | | | 17 16 | | | 12 | | | | | | | | | | 001 010 011 | OP-Code 0
| | | | | | | | | | | | | | | | | | | 5 | 4 | | | 1
| 32
0xd8 OR A D 1101 1000 | | 28 | | | 25 | 22 | | | | | 17 16 | | | 12 | | | | | | | | | | 001 010 011 | OP-Code 0
| | | | | | | | | | | | | | | | | | | 5 | 4 | | | 1
| 32
0xd9 OR A X 1101 1001 | | 28 | | | 25 | 22 | | 20 | | | 17 16 | | | 12 | | | | | | | | | | 001 010 011 | OP-Code 0
| | | | | | | | | | | | | | | | | | | 5 | 4 | | | 1
| 32

0xda OR

B

C | 1101 1010 | 28 | 25 | 21 | 20 | 18 | 16 | 12 | 001 | OP-Code
32 | 011
0xdb OR B D 1101 1011 | | 28 | | 25 | 22 | | | | 18 | 16 | | | 12 | | | | | | | | 001 010 011 | OP-Code 0
| | | | | | | | | | | | | | | | | 6 | | 4 | | | 1
32
0xdc OR B X 1101 1100 | | 28 | | 25 | 22 | | 20 | | 18 | 16 | | | 12 | | | | | | | | 001 010 011 | OP-Code 0
| | | | | | | | | | | | | | | | | 6 | | 4 | | | 1
32
0xdd OR C D 1101 1101 | | 28 | | 25 | 22 | | | | 18 | 17 16 | | | 12 | | | | | | | | 001 010 011 | OP-Code 0
| | | | | | | | | | | | | | | 6 | 5 | 4 | | | 1
| 32
0xde OR C X 1101 1110 | | 28 | | 25 | 22 | | 20 | | 18 | 17 16 | | | 12 | | | | | | | | 001 010 011 | OP-Code 0
| | | | | | | | | | | | | | | 6 | 5 | 4 | | | 1
| 32
0xdf OR D X 1101 1111 | | 28 | | 25 | | 22 | | 20 | 19 | | | 16 | | 12 | | | | | | | | | | 001 010 011 | OP-Code 0
| | | | | | | | | | | | | | | | | 7 | | | 4 | | | 1
| 32
0xe0 XOR A B 1110 0000 | | 28 | 26 | | | | 21 | | | | 17 | 16 | | 12 | | | | | | | | | | 001 010 011 | OP-Code 0
| | | | | | | | | | | | | | | | | | | 5 | 4 | | | 1
| 32
0xe1 XOR A C 1110 0001 | | 28 | 26 | | | | 21 | 20 | | | 17 16 | | | 12 | | | | | | | | | | 001 010 011 | OP-Code 0
| | | | | | | | | | | | | | | | | | | 5 | 4 | | | 1
| 32
0xe2 XOR A D 1110 0010 | | 28 | 26 | | | 22 | | | | | 17 16 | | | 12 | | | | | | | | | | 001 010 011 | OP-Code 0
| | | | | | | | | | | | | | | | | | | 5 | 4 | | | 1
| 32
0xe3 XOR A X 1110 0011 | | 28 | 26 | | | 22 | | 20 | | | 17 16 | | | 12 | | | | | | | | | | 001 010 011 | OP-Code 0
| | | | | | | | | | | | | | | | | | | 5 | 4 | | | 1
| 32
C 1110 0100 0xe4 XOR B | | 28 | 26 | | | | 21 | 20 | | 18 | 16 | | | 12 | | | | | | | | | | 001 010 011 | OP-Code 0
| | | | | | | | | | | | | | | | | | 6 | | 4 | | | 1
| 32
0xe5 XOR B D 1110 0101 | | 28 | 26 | | | 22 | | | | 18 | 16 | | | 12 | | | | | | | | | | 001 010 011 | OP-Code 0
| | | | | | | | | | | | | | | | | | 6 | | 4 | | | 1
| 32
0xe6 XOR B X 1110 0110 | | 28 | 26 | | | 22 | | 20 | | 18 | 16 | | | 12 | | | | | | | | | | 001 010 011 | OP-Code 0
| | | | | | | | | | | | | | | | | | 6 | | 4 | | | 1
| 32
0xe7 XOR C D 1110 0111 | | 28 | 26 | | | 22 | | | | 18 | 17 16 | | | 12 | | | | | | | | | | 001 010 011 | OP-Code 0
| | | | | | | | | | | | | | | | | | 6 | 5 | 4 | | | 1
| 32
0xe8 XOR C X 1110 1000 | | 28 | 26 | | | 22 | | 20 | | 18 | 17 16 | | | 12 | | | | | | | | | | 001 010 011 | OP-Code 0
| | | | | | | | | | | | | | | | | | 6 | 5 | 4 | | | 1
| 32
0xe9 XOR D X 1110 1001 | | 28 | 26 | | | 22 | | 20 | 19 | | 16 | | | 12 | | | | | | | | | | 001 010 011 | OP-Code 0
| | | | | | | | | | | | | | | | | 7 | | | 4 | | | 1
| 32
B 1110 1010 0xea NAND A | | 28 | 26 | 25 | | | 21 | | | | 17 16 | | | 12 | | | | | | | | | | 001 010 011 | OP-Code 0
| | | | | | | | | | | | | | | | | | | 5 | 4 | | | 1
| 32
0xeb NAND A C 1110 1011 | | 28 | 26 | 25 | | | 21 | 20 | | | 17 | 16 | | 12 | | | | | | | | | | 001 010 011 | OP-Code 0
| | | | | | | | | | | | | | | | | | | 5 | 4 | | | 1
| 32
0xec NAND A D 1110 1100 | | 28 | 26 | 25 | | 22 | | | | | 17 | 16 | | 12 | | | | | | | | | | 001 010 011 | OP-Code 0
| | | | | | | | | | | | | | | | | | | 5 | 4 | | | 1
| 32
0xed NAND A X 1110 1101 | | 28 | 26 | 25 | | 22 | | 20 | | | 17 | 16 | | 12 | | | | | | | | | | 001 010 011 | OP-Code 0
| | | | | | | | | | | | | | | | | | | 5 | 4 | | | 1
| 32
C 1110 1110 0xee NAND B | | 28 | 26 | 25 | | | 21 | 20 | | 18 | 16 | | | 12 | | | | | | | | | | 001 010 011 | OP-Code 0
| | | | | | | | | | | | | | | | | | 6 | | 4 | | | 1
| 32
0xef NAND B D 1110 1111 | | 28 | 26 | 25 | | 22 | | | | 18 | 16 | | | 12 | | | | | | | | | | 001 010 011 | OP-Code 0
| | | | | | | | | | | | | | | | | | 6 | | 4 | | | 1
| 32
0xf0 NAND B X 1111 0000 | | 28 | 26 | 25 | | 22 | | 20 | | 18 | 16 | | | 12 | | | | | | | | | | 001 010 011 | OP-Code 0
| | | | | | | | | | | | | | | | | | 6 | | 4 | | | 1
| 32
0xf1 NAND C D 1111 0001 | | 28 | 26 | 25 | | 22 | | | | 18 | 17 16 | | | 12 | | | | | | | | | | 001 010 011 | OP-Code 0
| | | | | | | | | | | | | | | | | | 6 | 5 | 4 | | | 1
| 32
0xf2 NAND C X 1111 0010 | | 28 | 26 | 25 | | 22 | | 20 | | 18 | 17 16 | | | 12 | | | | | | | | | | 001 010 011 | OP-Code 0
| | | | | | | | | | | | | | | | | | 6 | 5 | 4 | | | 1
| 32
0xf3 NAND D X 1111 0011 | | 28 | 26 | 25 | | 22 | | 20 | 19 | | 16 | | | 12 | | | | | | | | | | 001 010 011 | OP-Code 0
| | | | | | | | | | | | | | | | | 7 | | | 4 | | | 1
| 32

0xf4 | NEG
A | 1111 0100 | 28 | 27 | 26 | 17 16 | 12 | 001 | OP-Code
32 | 011
0xf5 NEG B 1111 0101 | | 28 | 27 | 26 | | | | 18 | 16 | | | 12 | | | | | | | | 001 010 011 | OP-Code 0
| | | | | | | | | | | | | | | | 6 | | 4 | | | 1
32
0xf6 NEG C 1111 0110 | | 28 | 27 | 26 | | | | 18 | 17 16 | | | 12 | | | | | | | | 001 010 011 | OP-Code 0
| | | | | | | | | | | | | | | | 6 | 5 | 4 | | | 1
32
0xf7 NEG D 1111 0111 | | 28 | 27 | 26 | | | 19 | | 16 | | | 12 | | | | | | | | 001 010 011 | OP-Code 0
| | | | | | | | | | | | | | 7 | | 4 | | | 1
| 32
0xf8 NEG X 1111 1000 | | 28 | 27 | 26 | | | 19 | | 17 16 | | | 12 | | | | | | | | 001 010 011 | OP-Code 0
| | | | | | | | | | | | | | 7 | 5 | 4 | | | 1
| 32
0xf9 NOT A 1111 1001 | | 28 | 27 | 26 | 25 | | | | | 17 | 16 | | 12 | | | | | | | | | | 001 010 011 | OP-Code 0
| | | | | | | | | | | | | | | | | | 5 | 4 | | | 1
| 32
0xfa NOT B 1111 1010 | | 28 | 27 | 26 | 25 | | | | 18 | | 16 | | 12 | | | | | | | | | | 001 010 011 | OP-Code 0
| | | | | | | | | | | | | | | | | 6 | | 4 | | | 1
| 32
C 1111 1011 0xfb NOT | | 28 | 27 | 26 | 25 | | | | 18 | 17 16 | | | 12 | | | | | | | | | | 001 010 011 | OP-Code 0
| | | | | | | | | | | | | | | | | 6 | 5 | 4 | | | 1
| 32
0xfc NOT D 1111 1100 | | 28 | 27 | 26 | 25 | | | 19 | | 16 | | | 12 | | | | | | | | | | 001 010 011 | OP-Code 0
| | | | | | | | | | | | | | | | 7 | | | 4 | | | 1
| 32
0xfd NOT X 1111 1101 | | 28 | 27 | 26 | 25 | | | 19 | | 17 16 | | | 12 | | | | | | | | | | 001 010 011 | OP-Code 0
| | | | | | | | | | | | | | | | 7 | | 5 | 4 | | | 1
| 32
0xfe NOR A B 1111 1110 | | 28 | 27 | | | 21 | | | | 17 16 | | | 12 | | | | | | | | | | 001 010 011 | OP-Code 0
| | | | | | | | | | | | | | | | | | 5 | 4 | | | 1
| 32
0xff XNOR A B 1111 1111 | | 28 | 27 | | 25 | 21 | | | | 17 16 | | | 12 | | | | | | | | | | 001 010 011 | OP-Code 0
| | | | | | | | | | | | | | | | | | 5 | 4 | | | 1
| 32

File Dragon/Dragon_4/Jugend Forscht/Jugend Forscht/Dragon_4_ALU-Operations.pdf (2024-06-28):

ALU_Right = A
ALU_Left = B
description
0000 0x0 | ADD | | add
0001 0x1 | ADC | | add with carry
0010 0x2 | SUB | | subtract
0011 0x3 | SBB | | subtract with borrow
0100 0x4 | SHL | A << 1 | shift left (ALU_LEFT)
0101 0x5 | SHRA | A >>> 1 | shift right (arithmetic) (ALU_LEFT)
0110 0x6 | SHRL | A >> 1 | shift right (logic) (ALU_LEFT)
0111 0x7 | INC | | increment (ALU_LEFT)
1000 0x8 | AND | A and B | and
1001 0x9 | OR | A or B | or
1010 0xa | XOR | A xor B | xor
1011 0xb | NAND | A nand B | nand
1100 0xc | NOR | A nor B | nor
1101 0xd | XNOR | A xnor B | xnor
1110 0xe | NEG | 2's A | 2's ALU_LEFT
1111 0xf | NOT | | invert ALU_LEFT

## ALU OPERATION'S

OP-Code | Operation

Aҧ

A + 1

A + Bത + C

A + Bത

A + B
A + B + C

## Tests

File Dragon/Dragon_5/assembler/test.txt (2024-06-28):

mov A 0x240f
shr A
push 0x2444
push A
jmp 0x66ff
jz A

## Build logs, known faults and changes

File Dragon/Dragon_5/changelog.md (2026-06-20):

### 01.09.2025
- created changelog
- redesigned "Jumps and Branches" in the ISA; renamed -> "Jumps"
- *after* thinking a lot, RISC-V type branches are going to be omitted in the ISA. The only advantage would be taking up 1 instruction less when branching. Only supporting jumps would get rid of the advantages of flags. Also, with our flag based jumps we can directly call a function with refreshing the RA in one instruction if the flags has been set beforehand.
- created flags documentation
- continued pseudo-instruction-translation-table
- removed pseudo-instruction-translation-table
- separate pseudo instruction from main instruction (put into separate table with translations included)
- (holy sh#t, the jump instructions are so much better now!!)

### 05.12.2025
- corrected Instruction Types documentation and added additional information
- continued Microarchitecture diagram (SVG)
- improved instruction decoding
	Since Instructions can and mostly are longer than 2 byte but we only have a 16bit Bus we have to fetch in 2 cycles. For the RRR-Type instructions I moved the destination register to the second word so that the pipeline can already start working with the first two bytes and no stall is needed. For every other Instruction with a destination register I moved the destination register to the last position to make decoding easier.
- added LogiSim file

### 05.12.2025 (2)
- continued microarchitecture diagram
- fixed jumps explanation in ISA
- after careful consideration, omitted the variable instruction length idea because it would make the architecture and microarchitecture a whole lot more complicated.
	An extra bit to decode the instruction length would be needed which would only allow for 15-bit immediates and with RRR-Types one register would need to be 4bit addressable instead of 5. Both are limitations I can live with but this makes the instructions not word aligned and decoding harder. instructions longer than 2 byte cannot any longer be fetched in 2 cycles but must be present as a whole on one cycle. **Therefore every instruction is now 4 Bytes long** Maybe make a Dragon-5V in the future...

### 06.12.2025
- continued Microarchitecture
- removed **JBIT** instruction.
	while it is totally possible to implement this instruction, it requires special logic outside of normal flag based jumps. Since I want to keep Dragon 5 "as simple as possible" I choose to not include this one.
- removed **SB** and **LB** instructions
	I decided that my memory will not by byte addressable and the smallest possible unit is 16 bits. This makes things simpler.
- made **PUSH** and **POP** instructions Pseudo instructions

### 07.12.2025
- worked on simulation
	- finished register file

### 07.12.2025 (2)
- Reimplemented Register file in simulation
	after thinking how to implement the register file IRL I noticed that this is pretty much impossible because I would need 100+ IC's just for the register file. 
- decided that I would like to address more than 128KiB of RAM therefore introduced memory banks.
- Added **SW0** and **LW0** which always operate on the 0th memory bank as well as **SWB**, **LWB**, **SWBr**, **LWBr** which fetch data from a mem bank without jumping to that address / switching the bank.
- Added **MBR** Register (Memory Bank Register)
- Added **MBS** Flag to detect Memory Bank switches.
- Begann implementing Instruction Cache

### 04.03.2026
- Redesigned instruction cache and decided on a bunch of design questions. 
	The Cache is going to be 64kx32 big. the first 16 bit are the actual value, the rest consists of the tag and valid bit. 
	I will use write though, write allocate to make things simpler.
- Continued implementing the cache in logisim

### 05.03.2026
- changed MBR register size  to 8 bit. Every thing else is overkill, you are not going to connect 64000 memory expansion slots to the pcb. Because of that the tag bits are only 7 bit wide now. 
- continued Instr Cache in logisim
- I came across multiple  huge problems:
	- way to many data lines into the cache: 100+, unrealistic in irl.
	- self modifying code. If a write instruction stores a value at a cached code location, the cache wouldn't update. I could either simply not allow writing to code segments, add a cache invalidation instruction or implement coherence mechanism. the later is needed anyway in the data cache because of I/O. So now I have to decide what to do. I think for now I will implement a proper coherence mechanism. The inner workings are explained in the Instruction Cache Brainstorming file. MMIO should not be cached!!! So bypass cache for IO addresses!!!

### 06.03.2026
- finished data cache
- finished instruction cache

### 06.03.2026 (2)
- added Cache invalidation instructions
- refactored a bunch of stuff
- began partlist
- began main memory in logisim
	- finished memory card
	- began working on main memory controller
- added memory bank count register that always tells you the amount of connected memory banks

### 08.03.2026
- continued working on memory controller

### 17.06.2026
- refactored memory controller a bit
- added documentation
- changed memory bank count register (MBC) to memory card count (MCC). Every bit in the register represents a physical card slot. with the LSB beeing the 0-th card and bit 8 beeing the 7-th card.

### 20.06.2026
- created Memory Bus diagram

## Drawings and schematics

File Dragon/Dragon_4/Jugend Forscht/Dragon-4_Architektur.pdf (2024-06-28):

# Dragon - 4.0

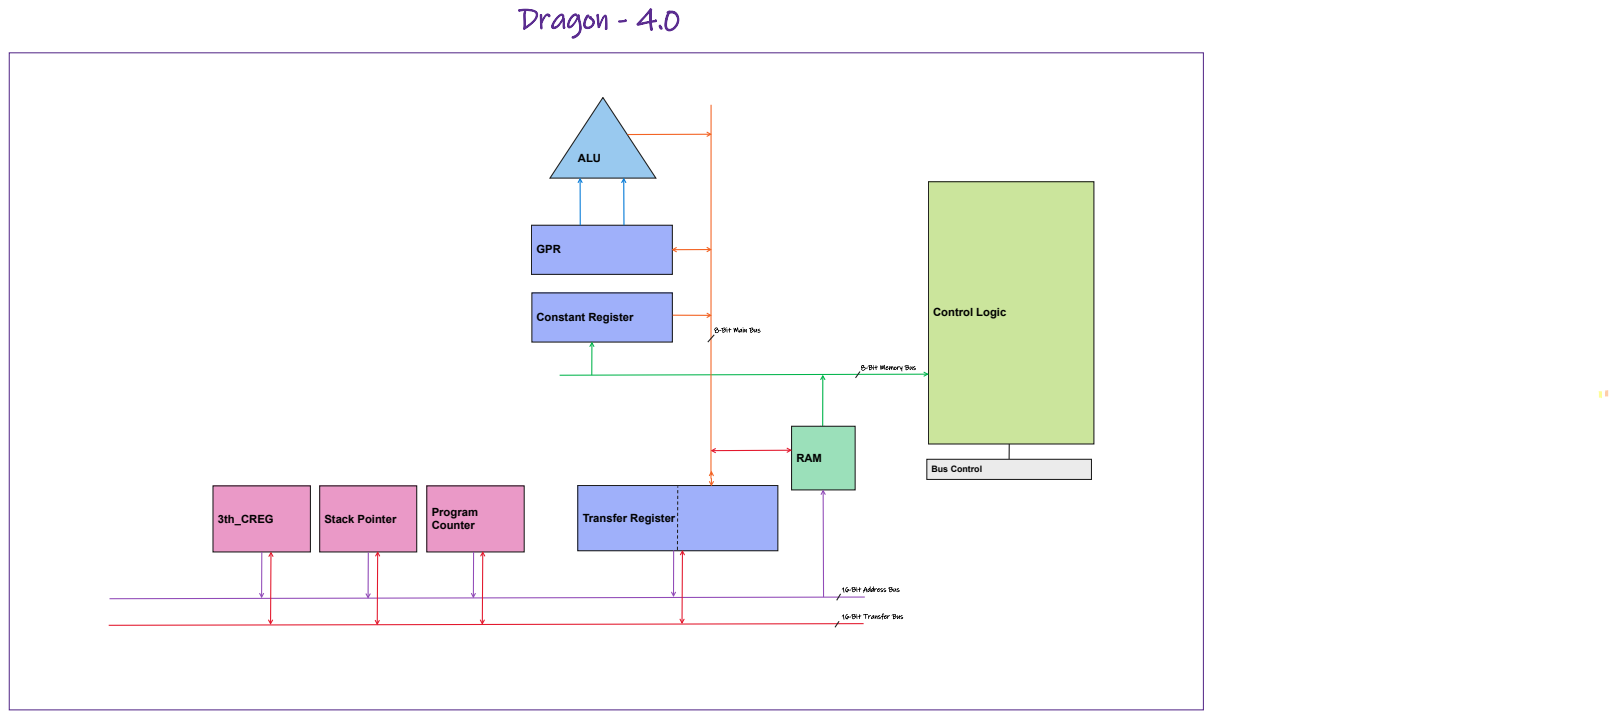
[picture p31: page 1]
Control Logic; Counter 3th_CREG; Stack Pointer; Constant Register; GPR; ALU; RAM; Bus Control

8-Bit Main Bus

8-Bit Memory Bus

Transfer Register Program

16-Bit Address Bus

16-Bit Transfer Bus

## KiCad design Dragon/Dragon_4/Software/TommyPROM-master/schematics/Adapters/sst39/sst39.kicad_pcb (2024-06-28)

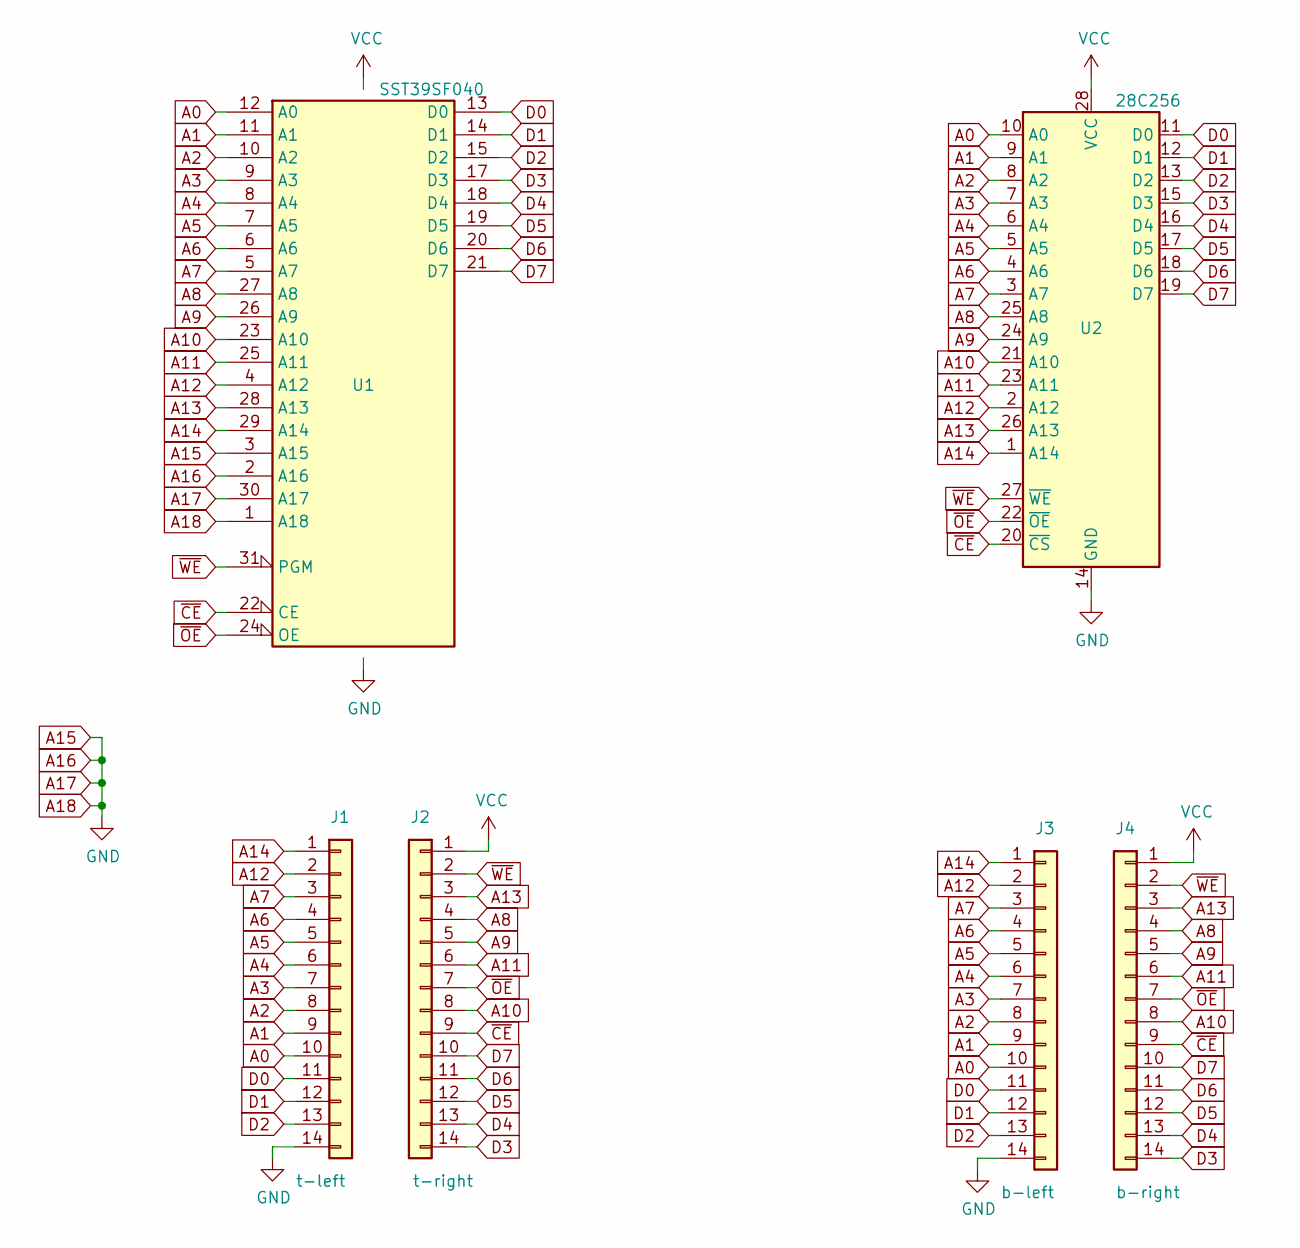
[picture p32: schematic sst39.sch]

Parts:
J1: t-left; PinHeader_1x14_P2.54mm_Vertical
J2: t-right; PinHeader_1x14_P2.54mm_Vertical
J3: b-left; PinSocket_1x14_P2.54mm_Vertical
J4: b-right; PinSocket_1x14_P2.54mm_Vertical
U1: SST39SF040; DIP-32_W15.24mm_Socket
U2: 28C256; DIP-28_W15.24mm

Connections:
A0: J1.10, J3.10, U1.12 (A0), U2.10 (A0)
A1: J1.9, J3.9, U1.11 (A1), U2.9 (A1)
A2: J1.8, J3.8, U1.10 (A2), U2.8 (A2)
A3: J1.7, J3.7, U1.9 (A3), U2.7 (A3)
A4: J1.6, J3.6, U1.8 (A4), U2.6 (A4)
A5: J1.5, J3.5, U1.7 (A5), U2.5 (A5)
A6: J1.4, J3.4, U1.6 (A6), U2.4 (A6)
A7: J1.3, J3.3, U1.5 (A7), U2.3 (A7)
A8: J2.4, J4.4, U1.27 (A8), U2.25 (A8)
A9: J2.5, J4.5, U1.26 (A9), U2.24 (A9)
A10: J2.8, J4.8, U1.23 (A10), U2.21 (A10)
A11: J2.6, J4.6, U1.25 (A11), U2.23 (A11)
A12: J1.2, J3.2, U1.4 (A12), U2.2 (A12)
A13: J2.3, J4.3, U1.28 (A13), U2.26 (A13)
A14: J1.1, J3.1, U1.29 (A14), U2.1 (A14)
A15: J1.14, J3.14, U1.1 (A18), U1.2 (A16), U1.3 (A15), U1.16 (GND), U1.30 (A17), U2.14 (GND)
D0: J1.11, J3.11, U1.13 (D0), U2.11 (D0)
D1: J1.12, J3.12, U1.14 (D1), U2.12 (D1)
D2: J1.13, J3.13, U1.15 (D2), U2.13 (D2)
D3: J2.14, J4.14, U1.17 (D3), U2.15 (D3)
D4: J2.13, J4.13, U1.18 (D4), U2.16 (D4)
D5: J2.12, J4.12, U1.19 (D5), U2.17 (D5)
D6: J2.11, J4.11, U1.20 (D6), U2.18 (D6)
D7: J2.10, J4.10, U1.21 (D7), U2.19 (D7)
VCC: J2.1, J4.1, U1.32 (VCC), U2.28 (VCC)
~CE: J2.9, J4.9, U1.22 (CE), U2.20 (~CS)
~OE: J2.7, J4.7, U1.24 (OE), U2.22 (~OE)
~WE: J2.2, J4.2, U1.31 (PGM), U2.27 (~WE)

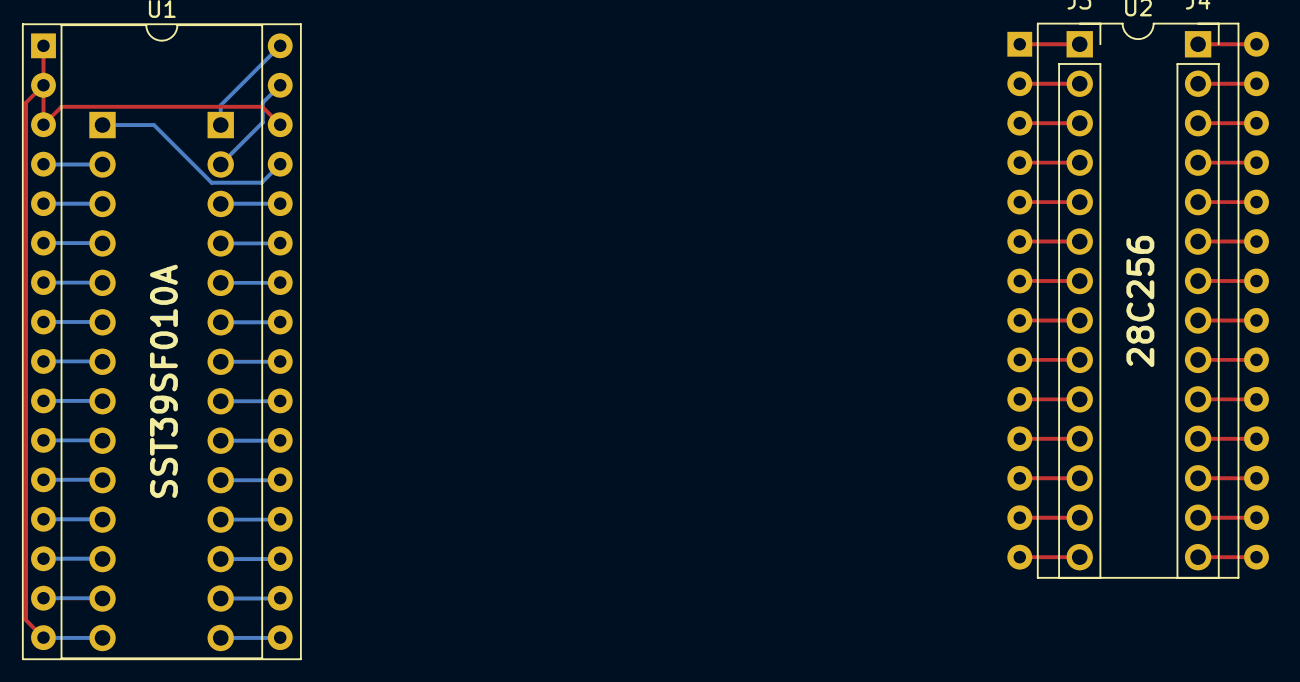
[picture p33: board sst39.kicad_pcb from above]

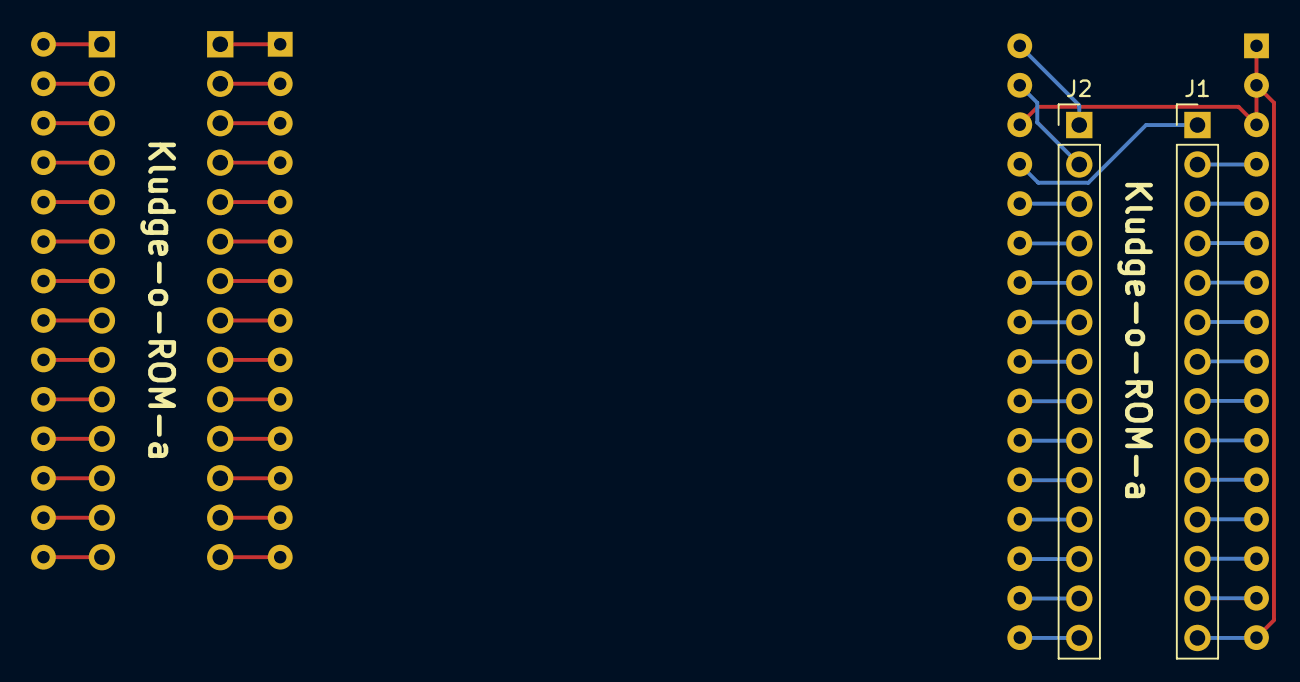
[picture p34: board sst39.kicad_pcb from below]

Board: 2 copper layers, 6 parts (2 on the bottom side), 28 nets.

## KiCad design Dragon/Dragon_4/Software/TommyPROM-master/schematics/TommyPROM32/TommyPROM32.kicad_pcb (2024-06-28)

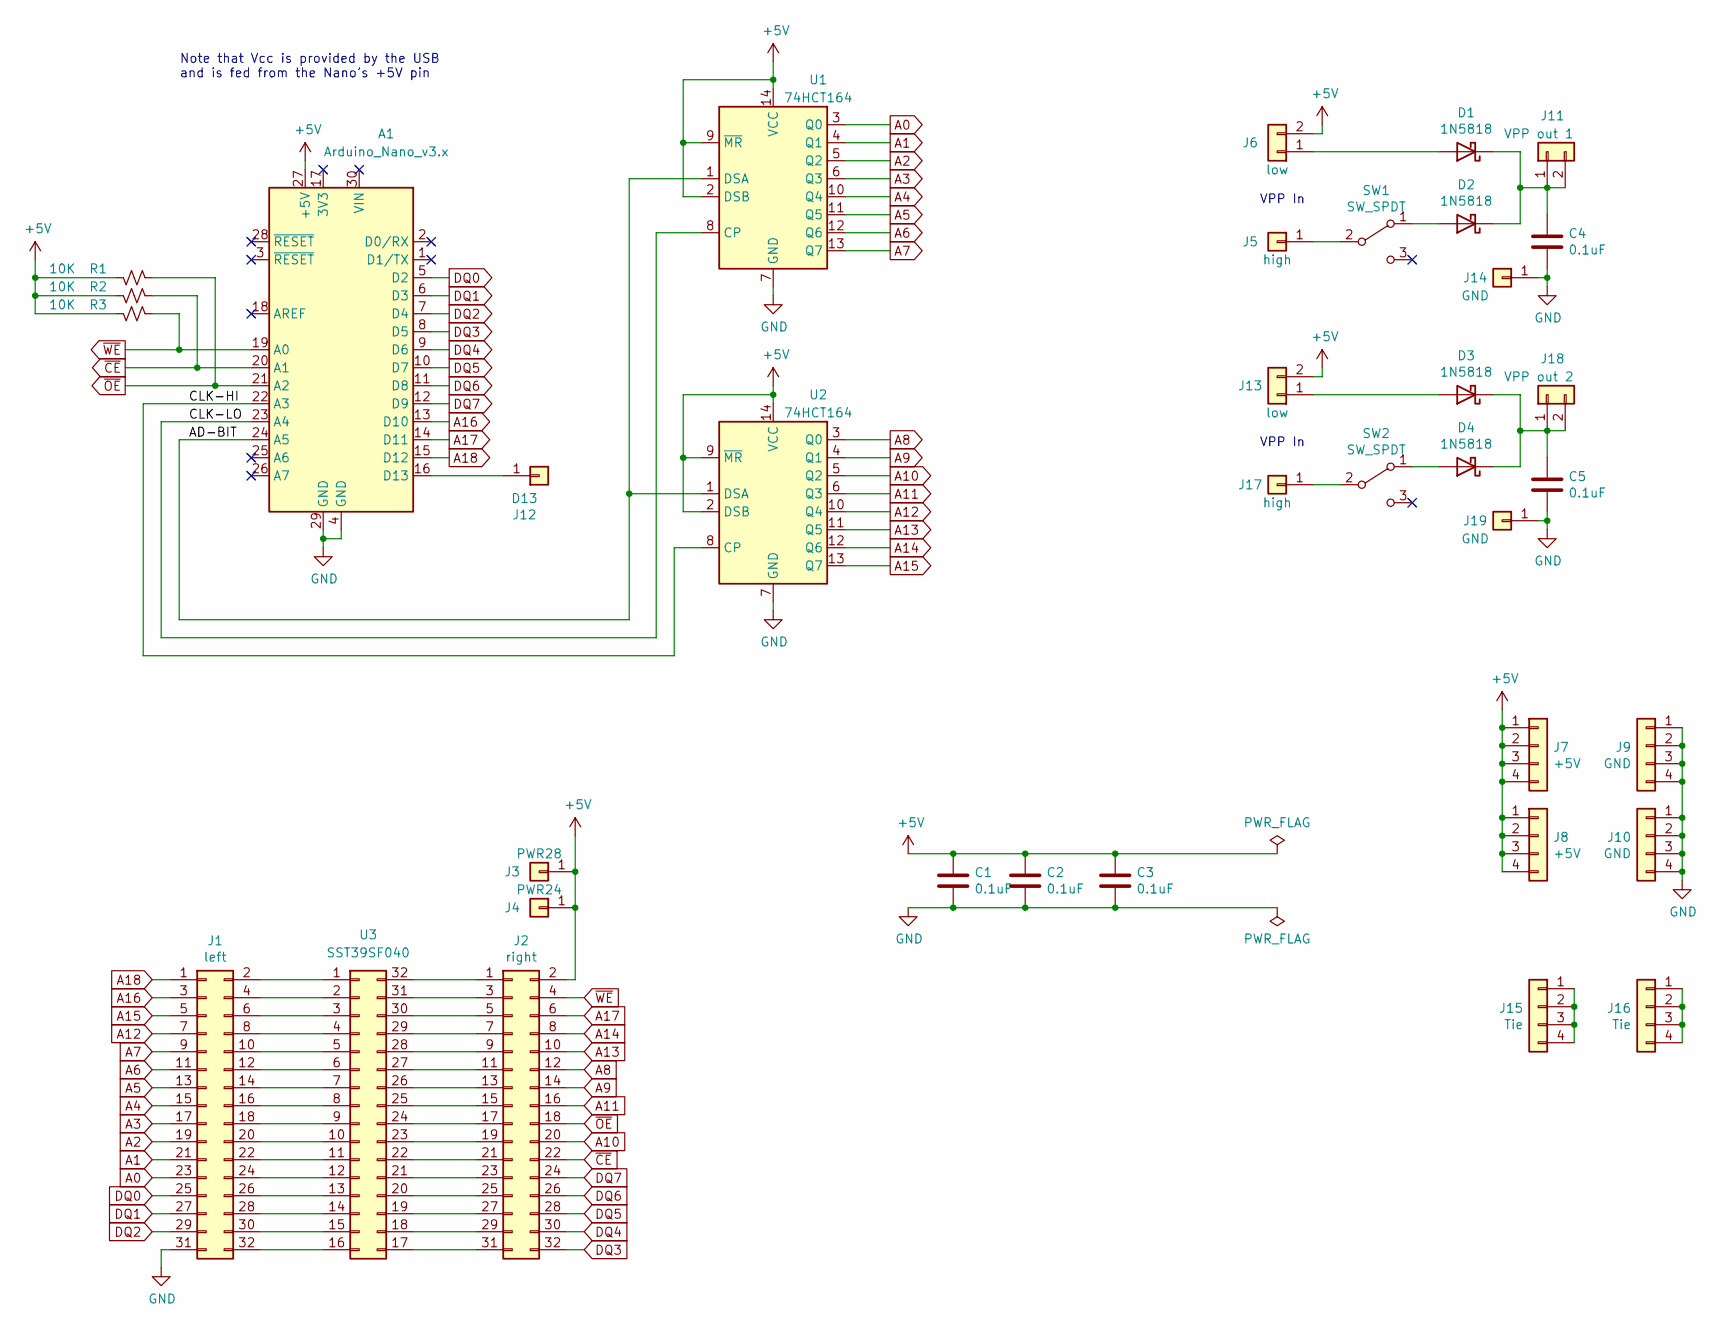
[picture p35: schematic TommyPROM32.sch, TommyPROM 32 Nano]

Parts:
A1: Arduino_Nano_v3.x; Arduino_Nano
C1, C2, C3, C4, C5: 0.1uF; C_Disc_D3.0mm_W1.6mm_P2.50mm
D1, D2, D3, D4: 1N5818; D_DO-41_SOD81_P10.16mm_Horizontal
J1: left; PinHeader_2x16_P2.54mm_Vertical
J2: right; PinHeader_2x16_P2.54mm_Vertical
J3: PWR28; PinHeader_1x01_P2.54mm_Vertical
J4: PWR24; PinHeader_1x01_P2.54mm_Vertical
J5, J17: high; PinHeader_1x01_P2.54mm_Vertical
J6, J13: low; PinHeader_1x02_P2.54mm_Vertical
J7, J8: +5V; PinHeader_1x04_P2.54mm_Vertical
J9, J10: GND; PinHeader_1x04_P2.54mm_Vertical
J11: VPP out 1; PinHeader_1x02_P2.54mm_Vertical
J12: D13; PinHeader_1x01_P2.54mm_Vertical
J14, J19: GND; PinHeader_1x01_P2.54mm_Vertical
J15, J16: Tie; PinHeader_1x04_P2.54mm_Vertical
J18: VPP out 2; PinHeader_1x02_P2.54mm_Vertical
R1, R2, R3: 10K; R_Axial_DIN0207_L6.3mm_D2.5mm_P10.16mm_Horizontal
SW1, SW2: SW_SPDT; Switch_Slide_11.6x4mm_EG1218
U1, U2: 74HCT164; DIP-14_W7.62mm
U3: SST39SF040; DIP_Socket-32_W11.9_W12.7_W15.24_W17.78_W18.5_3M_232-1285-0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

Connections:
+5V: A1.27 (+5V), C1.1, C2.1, C3.1, J2.2, J3.1, J4.1, J6.2, J7.1, J7.2, J7.3, J7.4, J8.1, J8.2, J8.3, J8.4, J13.2, R1.1, R2.1, R3.1, U1.2 (DSB), U1.9 (~MR), U1.14 (VCC), U2.2 (DSB), U2.9 (~MR), U2.14 (VCC)
/AD-BIT: A1.24 (A5), U1.1 (DSA), U2.1 (DSA)
/CLK-HI: A1.22 (A3), U2.8 (CP)
/CLK-LO: A1.23 (A4), U1.8 (CP)
A0: J1.23, U1.3 (Q0)
A1: J1.21, U1.4 (Q1)
A2: J1.19, U1.5 (Q2)
A3: J1.17, U1.6 (Q3)
A4: J1.15, U1.10 (Q4)
A5: J1.13, U1.11 (Q5)
A6: J1.11, U1.12 (Q6)
A7: J1.9, U1.13 (Q7)
A8: J2.12, U2.3 (Q0)
A9: J2.14, U2.4 (Q1)
A10: J2.20, U2.5 (Q2)
A11: J2.16, U2.6 (Q3)
A12: J1.7, U2.10 (Q4)
A13: J2.10, U2.11 (Q5)
A14: J2.8, U2.12 (Q6)
A15: J1.5, U2.13 (Q7)
A16: A1.13 (D10), J1.3
A17: A1.14 (D11), J2.6
A18: A1.15 (D12), J1.1
DQ0: A1.5 (D2), J1.25
DQ1: A1.6 (D3), J1.27
DQ2: A1.7 (D4), J1.29
DQ3: A1.8 (D5), J2.32
DQ4: A1.9 (D6), J2.30
DQ5: A1.10 (D7), J2.28
DQ6: A1.11 (D8), J2.26
DQ7: A1.12 (D9), J2.24
GND: A1.4 (GND), A1.29 (GND), C1.2, C2.2, C3.2, C4.2, C5.2, J1.31, J9.1, J9.2, J9.3, J9.4, J10.1, J10.2, J10.3, J10.4, J14.1, J19.1, U1.7 (GND), U2.7 (GND)
unnamed: A1.16 (D13), J12.1
unnamed: C4.1, D1.1 (K), D2.1 (K), J11.1, J11.2
unnamed: C5.1, D3.1 (K), D4.1 (K), J18.1, J18.2
unnamed: D1.2 (A), J6.1
unnamed: D2.2 (A), SW1.1 (A)
unnamed: D3.2 (A), J13.1
unnamed: D4.2 (A), SW2.1 (A)
unnamed: J1.2, U3.1
unnamed: J1.4, U3.2
unnamed: J1.6, U3.3
unnamed: J1.8, U3.4
unnamed: J1.10, U3.5
unnamed: J1.12, U3.6
unnamed: J1.14, U3.7
unnamed: J1.16, U3.8
unnamed: J1.18, U3.9
unnamed: J1.20, U3.10
unnamed: J1.22, U3.11
unnamed: J1.24, U3.12
unnamed: J1.26, U3.13
unnamed: J1.28, U3.14
unnamed: J1.30, U3.15
unnamed: J1.32, U3.16
unnamed: J2.1, U3.32
unnamed: J2.3, U3.31
unnamed: J2.5, U3.30
unnamed: J2.7, U3.29
unnamed: J2.9, U3.28
unnamed: J2.11, U3.27
unnamed: J2.13, U3.26
unnamed: J2.15, U3.25
unnamed: J2.17, U3.24
unnamed: J2.19, U3.23
unnamed: J2.21, U3.22
unnamed: J2.23, U3.21
unnamed: J2.25, U3.20
unnamed: J2.27, U3.19
unnamed: J2.29, U3.18
unnamed: J2.31, U3.17
unnamed: J5.1, SW1.2 (B)
unnamed: J15.1, J15.2, J15.3, J15.4
unnamed: J16.1, J16.2, J16.3, J16.4
unnamed: J17.1, SW2.2 (B)
~CE: A1.20 (A1), J2.22, R2.2
~OE: A1.21 (A2), J2.18, R1.2
~WE: A1.19 (A0), J2.4, R3.2

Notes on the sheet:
Note that Vcc is provided by the USB and is fed from the Nano’s +5V pin
VPP In

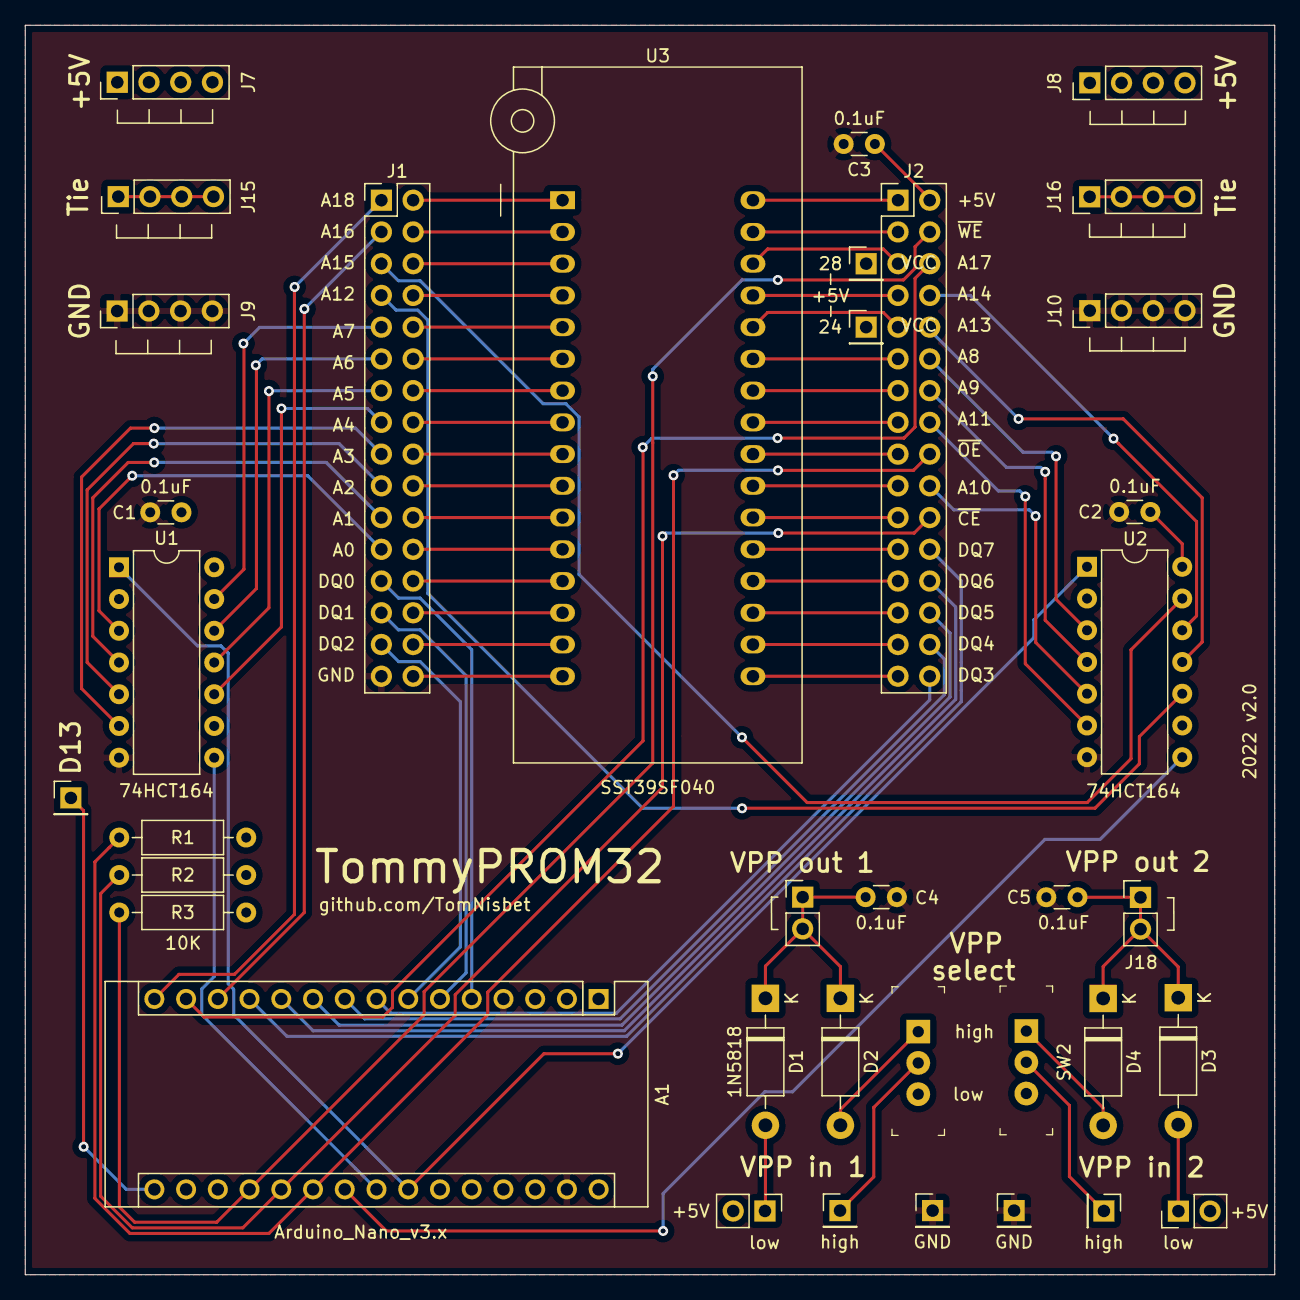
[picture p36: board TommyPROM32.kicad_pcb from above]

Board: 2 copper layers, 100.0 x 100.0 mm, 37 parts (0 on the bottom side), 78 nets.

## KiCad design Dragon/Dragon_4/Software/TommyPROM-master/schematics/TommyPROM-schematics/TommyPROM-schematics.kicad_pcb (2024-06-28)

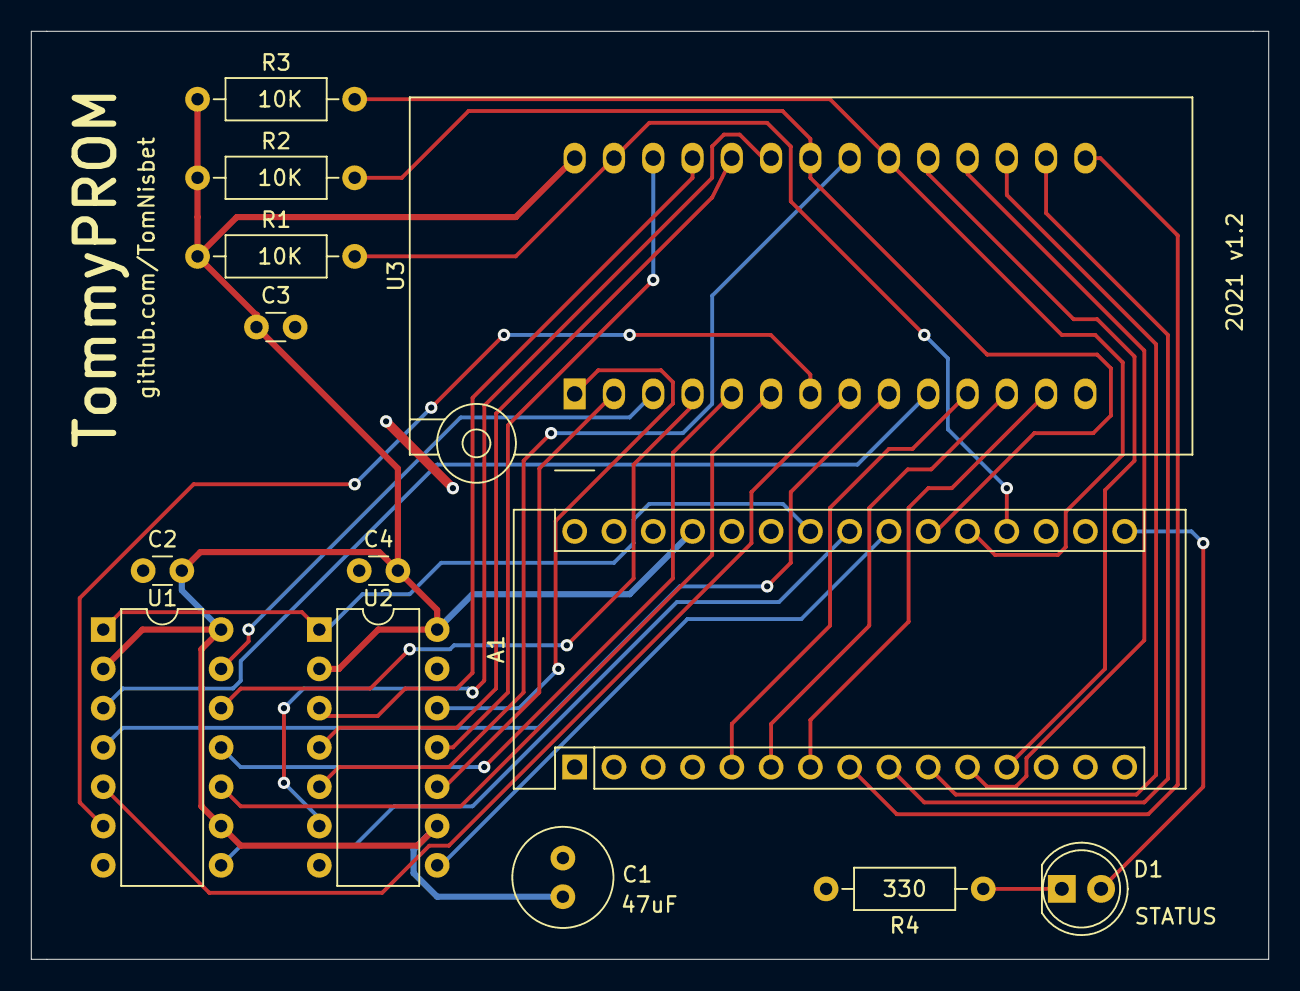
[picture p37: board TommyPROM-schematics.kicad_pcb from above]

Board: 2 copper layers, 80.0 x 60.0 mm, 13 parts (0 on the bottom side), 33 nets.

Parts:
A1: Arduino_Nano_v3.x; Arduino_Nano
C1: 47uF; C_Radial_D6.3mm_H11.0mm_P2.50mm
C2, C3, C4: 0.1uF; C_Disc_D3.0mm_W1.6mm_P2.50mm
D1: STATUS; LED_D5.0mm
R1, R2, R3: 10K; R_Axial_DIN0207_L6.3mm_D2.5mm_P10.16mm_Horizontal
R4: 330; R_Axial_DIN0207_L6.3mm_D2.5mm_P10.16mm_Horizontal
U1, U2: 74HCT164; DIP-14_W7.62mm
U3: 28C256; DIP_Socket-28_W11.9_W12.7_W15.24_W17.78_W18.5_3M_228-1277-0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

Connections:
/A0: U1.3, U3.10
/A1: U1.4, U3.9
/A2: U1.5, U3.8
/A3: U1.6, U3.7
/A4: U1.10, U3.6
/A5: U1.11, U3.5
/A6: U1.12, U3.4
/A7: U1.13, U3.3
/A8: U2.3, U3.25
/A9: U2.4, U3.24
/A10: U2.5, U3.21
/A11: U2.6, U3.23
/A12: U2.10, U3.2
/A13: U2.11, U3.26
/A14: U2.12, U3.1
/AD-BIT: A1.24, U1.1, U2.1
/CE: A1.20, R3.2, U3.20
/CLK-HI: A1.22, U2.8
/CLK-LO: A1.23, U1.8
/D0: A1.5, U3.11
/D1: A1.6, U3.12
/D2: A1.7, U3.13
/D3: A1.8, U3.15
/D4: A1.9, U3.16
/D5: A1.10, U3.17
/D6: A1.11, U3.18
/D7: A1.12, U3.19
/OE: A1.21, R2.2, U3.22
/WE: A1.19, R1.2, U3.27
GND: A1.4, A1.29, C1.2, C2.2, C3.2, C4.2, R4.2, U1.7, U2.7, U3.14
unnamed: A1.16, D1.2
unnamed: D1.1, R4.1
VCC: A1.27, C1.1, C2.1, C3.1, C4.1, R1.1, R2.1, R3.1, U1.2, U1.9, U1.14, U2.2, U2.9, U2.14, U3.28

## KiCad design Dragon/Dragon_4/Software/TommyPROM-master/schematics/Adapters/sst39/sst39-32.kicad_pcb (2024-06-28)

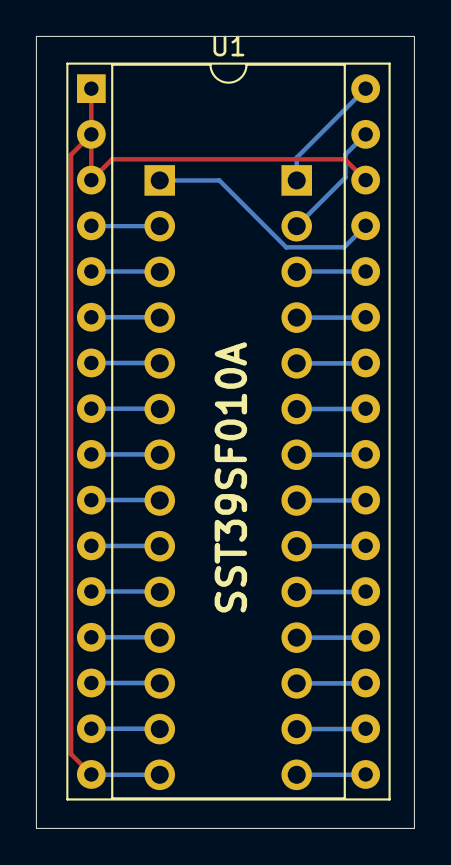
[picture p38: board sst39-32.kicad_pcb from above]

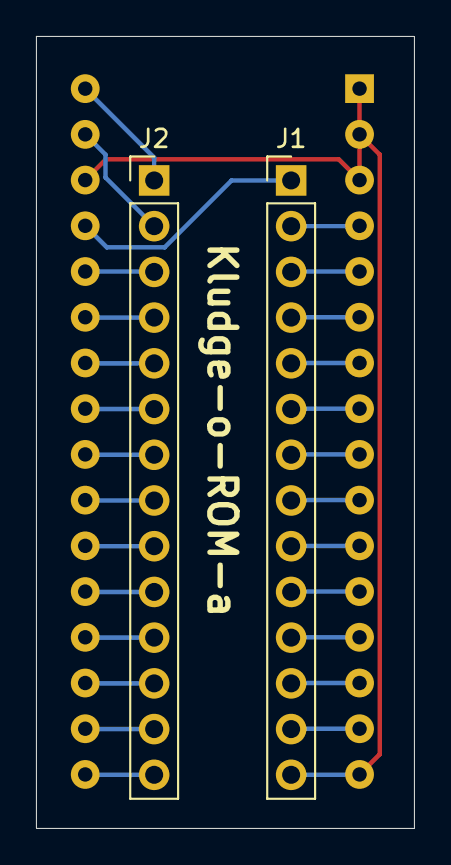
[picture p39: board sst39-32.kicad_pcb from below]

Board: 2 copper layers, 21.0 x 44.0 mm, 3 parts (2 on the bottom side), 28 nets.

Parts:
J1: t-left; PinHeader_1x14_P2.54mm_Vertical
J2: t-right; PinHeader_1x14_P2.54mm_Vertical
U1: SST39SF040; DIP-32_W15.24mm_Socket

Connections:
A0: J1.10, U1.12
A1: J1.9, U1.11
A2: J1.8, U1.10
A3: J1.7, U1.9
A4: J1.6, U1.8
A5: J1.5, U1.7
A6: J1.4, U1.6
A7: J1.3, U1.5
A8: J2.4, U1.27
A9: J2.5, U1.26
A10: J2.8, U1.23
A11: J2.6, U1.25
A12: J1.2, U1.4
A13: J2.3, U1.28
A14: J1.1, U1.29
A15: J1.14, U1.1, U1.2, U1.3, U1.16, U1.30
D0: J1.11, U1.13
D1: J1.12, U1.14
D2: J1.13, U1.15
D3: J2.14, U1.17
D4: J2.13, U1.18
D5: J2.12, U1.19
D6: J2.11, U1.20
D7: J2.10, U1.21
VCC: J2.1, U1.32
~CE: J2.9, U1.22
~OE: J2.7, U1.24
~WE: J2.2, U1.31

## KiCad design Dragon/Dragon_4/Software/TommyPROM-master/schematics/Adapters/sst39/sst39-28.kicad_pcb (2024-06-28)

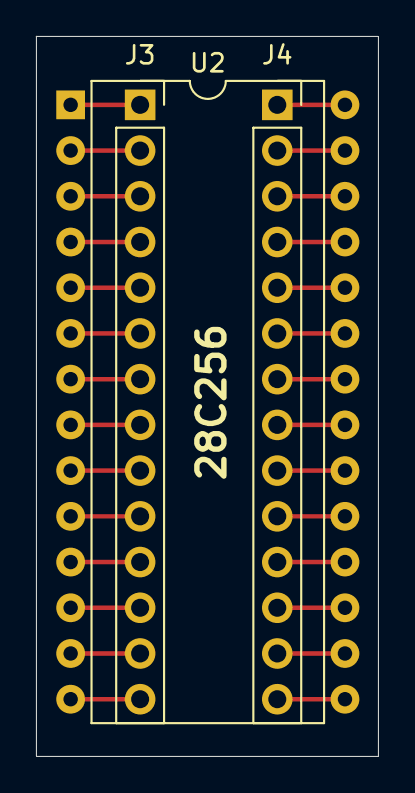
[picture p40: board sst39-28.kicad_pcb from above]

Board: 2 copper layers, 19.0 x 40.0 mm, 3 parts (0 on the bottom side), 28 nets.

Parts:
J3: b-left; PinSocket_1x14_P2.54mm_Vertical
J4: b-right; PinSocket_1x14_P2.54mm_Vertical
U2: 28C256; DIP-28_W15.24mm

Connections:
A0: J3.10, U2.10
A1: J3.9, U2.9
A2: J3.8, U2.8
A3: J3.7, U2.7
A4: J3.6, U2.6
A5: J3.5, U2.5
A6: J3.4, U2.4
A7: J3.3, U2.3
A8: J4.4, U2.25
A9: J4.5, U2.24
A10: J4.8, U2.21
A11: J4.6, U2.23
A12: J3.2, U2.2
A13: J4.3, U2.26
A14: J3.1, U2.1
A15: J3.14, U2.14
D0: J3.11, U2.11
D1: J3.12, U2.12
D2: J3.13, U2.13
D3: J4.14, U2.15
D4: J4.13, U2.16
D5: J4.12, U2.17
D6: J4.11, U2.18
D7: J4.10, U2.19
VCC: J4.1, U2.28
~CE: J4.9, U2.20
~OE: J4.7, U2.22
~WE: J4.2, U2.27

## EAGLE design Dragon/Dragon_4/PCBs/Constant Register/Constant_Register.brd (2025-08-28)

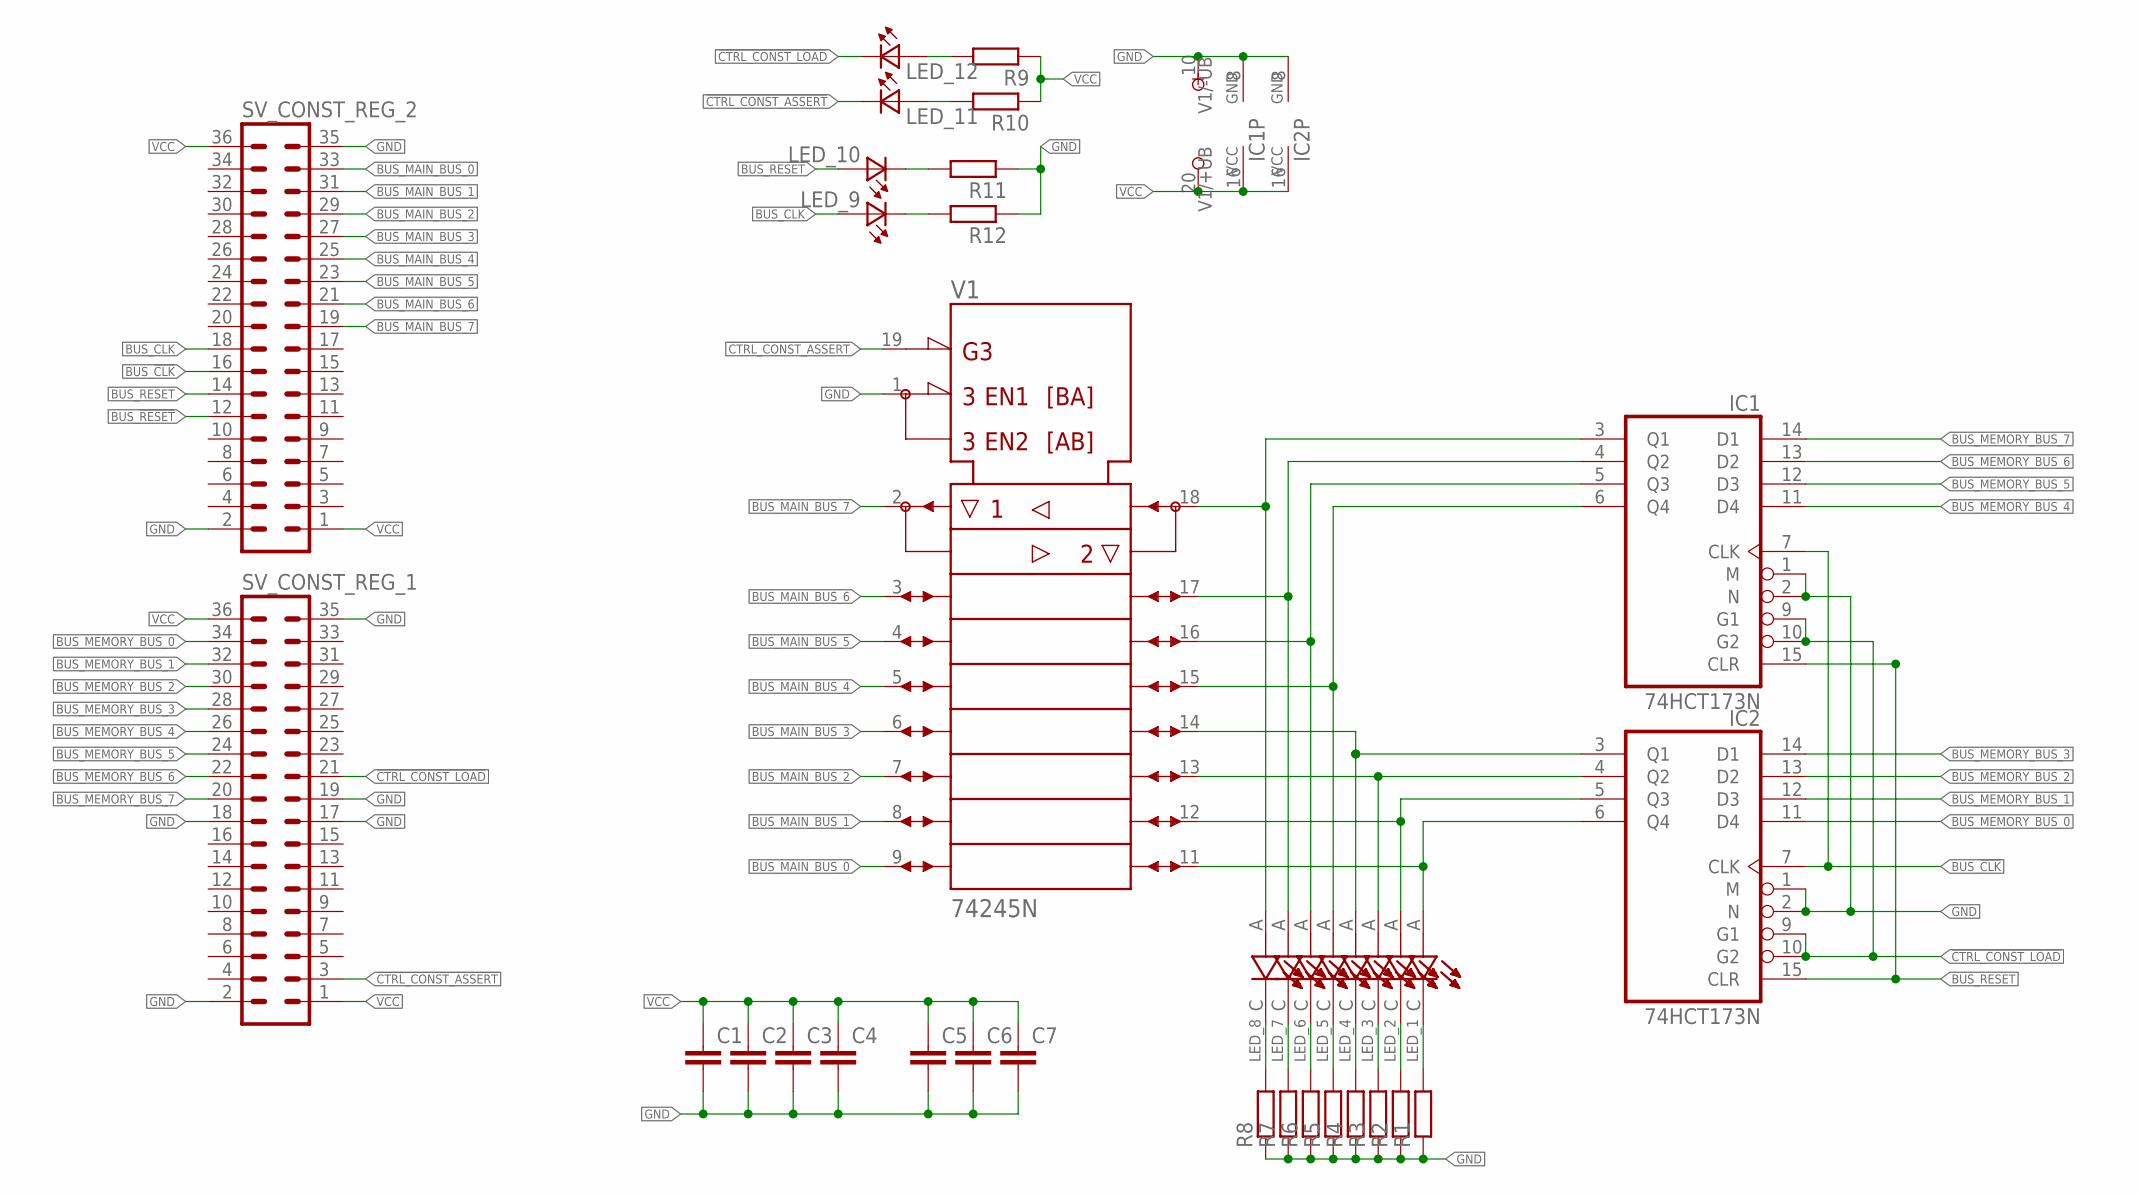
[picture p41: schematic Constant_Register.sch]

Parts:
C1, C2, C3, C4, C5, C6, C7: C-EUC0805; C0805
IC1, IC2: 74HCT173N; DIL16
LED_1, LED_2, LED_3, LED_4, LED_5, LED_6, LED_7, LED_8: LTST-C193KRKT-5A; LEDC1608X45N
LED_9, LED_10, LED_11, LED_12: LTST-C193TBKT-5A; 0603
R1, R2, R3, R4, R5, R6, R7, R8, R9, R10, R11, R12: R-EU_R0805; R0805
SV_CONST_REG_1, SV_CONST_REG_2: MA18-2
V1: 74245N; DIL20

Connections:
!CTRL_CONST_ASSERT: LED_11.1 (K2), SV_CONST_REG_1.3, V1.19 (!G)
!CTRL_CONST_LOAD: IC1.9 (G1), IC1.10 (G2), IC2.9 (G1), IC2.10 (G2), LED_12.1 (K2), SV_CONST_REG_1.21
BUS_!CLK: IC1.7 (CLK), IC2.7 (CLK), SV_CONST_REG_2.16
BUS_!RESET: SV_CONST_REG_2.12
BUS_CLK: LED_9.2 (A2), SV_CONST_REG_2.18
BUS_MAIN_BUS_0: SV_CONST_REG_2.33, V1.9 (A8)
BUS_MAIN_BUS_1: SV_CONST_REG_2.31, V1.8 (A7)
BUS_MAIN_BUS_2: SV_CONST_REG_2.29, V1.7 (A6)
BUS_MAIN_BUS_3: SV_CONST_REG_2.27, V1.6 (A5)
BUS_MAIN_BUS_4: SV_CONST_REG_2.25, V1.5 (A4)
BUS_MAIN_BUS_5: SV_CONST_REG_2.23, V1.4 (A3)
BUS_MAIN_BUS_6: SV_CONST_REG_2.21, V1.3 (A2)
BUS_MAIN_BUS_7: SV_CONST_REG_2.19, V1.2 (A1)
BUS_MEMORY_BUS_0: IC2.11 (D4), SV_CONST_REG_1.34
BUS_MEMORY_BUS_1: IC2.12 (D3), SV_CONST_REG_1.32
BUS_MEMORY_BUS_2: IC2.13 (D2), SV_CONST_REG_1.30
BUS_MEMORY_BUS_3: IC2.14 (D1), SV_CONST_REG_1.28
BUS_MEMORY_BUS_4: IC1.11 (D4), SV_CONST_REG_1.26
BUS_MEMORY_BUS_5: IC1.12 (D3), SV_CONST_REG_1.24
BUS_MEMORY_BUS_6: IC1.13 (D2), SV_CONST_REG_1.22
BUS_MEMORY_BUS_7: IC1.14 (D1), SV_CONST_REG_1.20
BUS_RESET: IC1.15 (CLR), IC2.15 (CLR), LED_10.2 (A2), SV_CONST_REG_2.14
GND: C1.2, C2.2, C3.2, C4.2, C5.2, C6.2, C7.2, IC1.1 (M), IC1.2 (N), IC1.8 (GND), IC2.1 (M), IC2.2 (N), IC2.8 (GND), R1.1, R2.1, R3.1, R4.1, R5.1, R6.1, R7.1, R8.1, R11.1, R12.1, SV_CONST_REG_1.2, SV_CONST_REG_1.17, SV_CONST_REG_1.18, SV_CONST_REG_1.19, SV_CONST_REG_1.35, SV_CONST_REG_2.2, SV_CONST_REG_2.35, V1.1 (DIR), V1.10 (-UB)
unnamed: LED_8.C, R8.2
unnamed: LED_7.C, R7.2
unnamed: LED_6.C, R6.2
unnamed: LED_5.C, R5.2
unnamed: LED_4.C, R4.2
unnamed: LED_3.C, R3.2
unnamed: LED_2.C, R2.2
unnamed: LED_1.C, R1.2
unnamed: IC2.3 (Q1), LED_4.A, V1.14 (B5)
unnamed: IC1.4 (Q2), LED_7.A, V1.17 (B2)
unnamed: IC2.6 (Q4), LED_1.A, V1.11 (B8)
unnamed: IC2.5 (Q3), LED_2.A, V1.12 (B7)
unnamed: IC2.4 (Q2), LED_3.A, V1.13 (B6)
unnamed: IC1.6 (Q4), LED_5.A, V1.15 (B4)
unnamed: IC1.5 (Q3), LED_6.A, V1.16 (B3)
unnamed: IC1.3 (Q1), LED_8.A, V1.18 (B1)
unnamed: LED_11.2 (A2), R10.2
unnamed: LED_12.2 (A2), R9.2
unnamed: LED_9.1 (K2), R12.2
unnamed: LED_10.1 (K2), R11.2
VCC: C1.1, C2.1, C3.1, C4.1, C5.1, C6.1, C7.1, IC1.16 (VCC), IC2.16 (VCC), R9.1, R10.1, SV_CONST_REG_1.1, SV_CONST_REG_1.36, SV_CONST_REG_2.1, SV_CONST_REG_2.36, V1.20 (+UB)

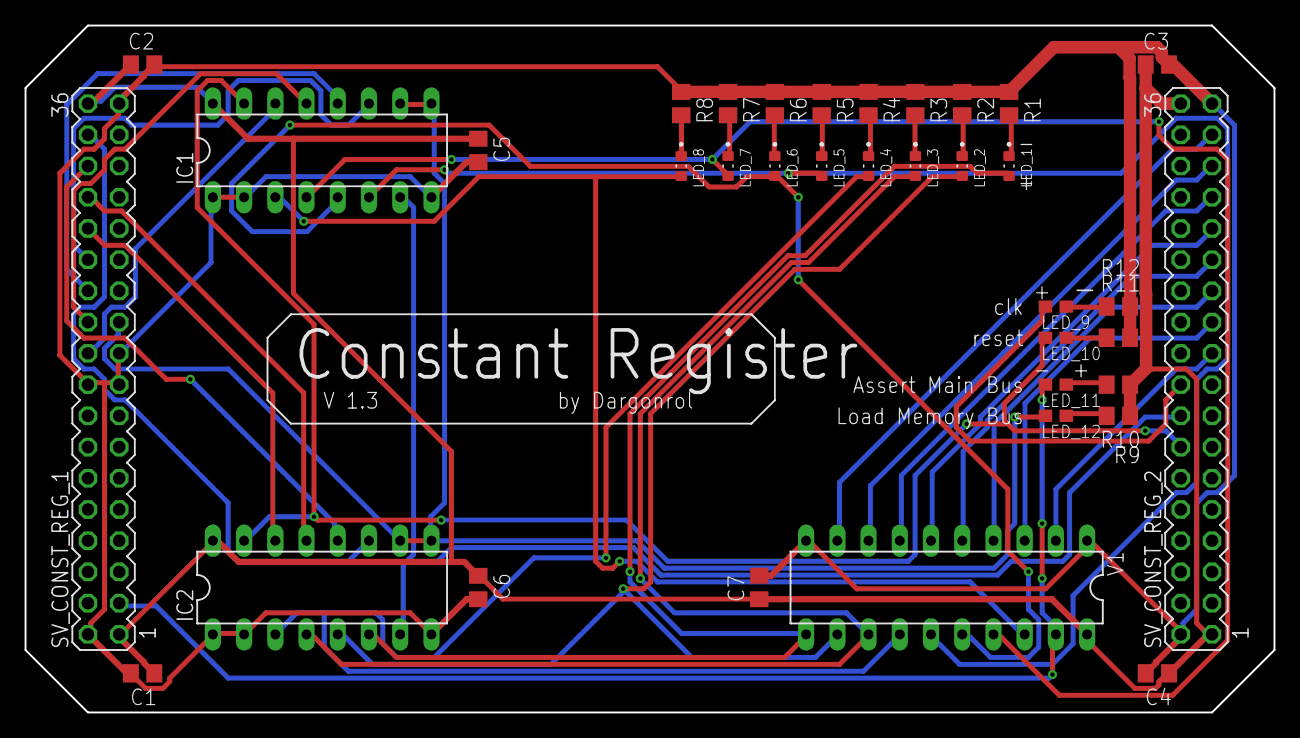
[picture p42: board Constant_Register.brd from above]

Board: 2 copper layers, 101.6 x 55.9 mm, 36 parts (0 on the bottom side), 43 nets.

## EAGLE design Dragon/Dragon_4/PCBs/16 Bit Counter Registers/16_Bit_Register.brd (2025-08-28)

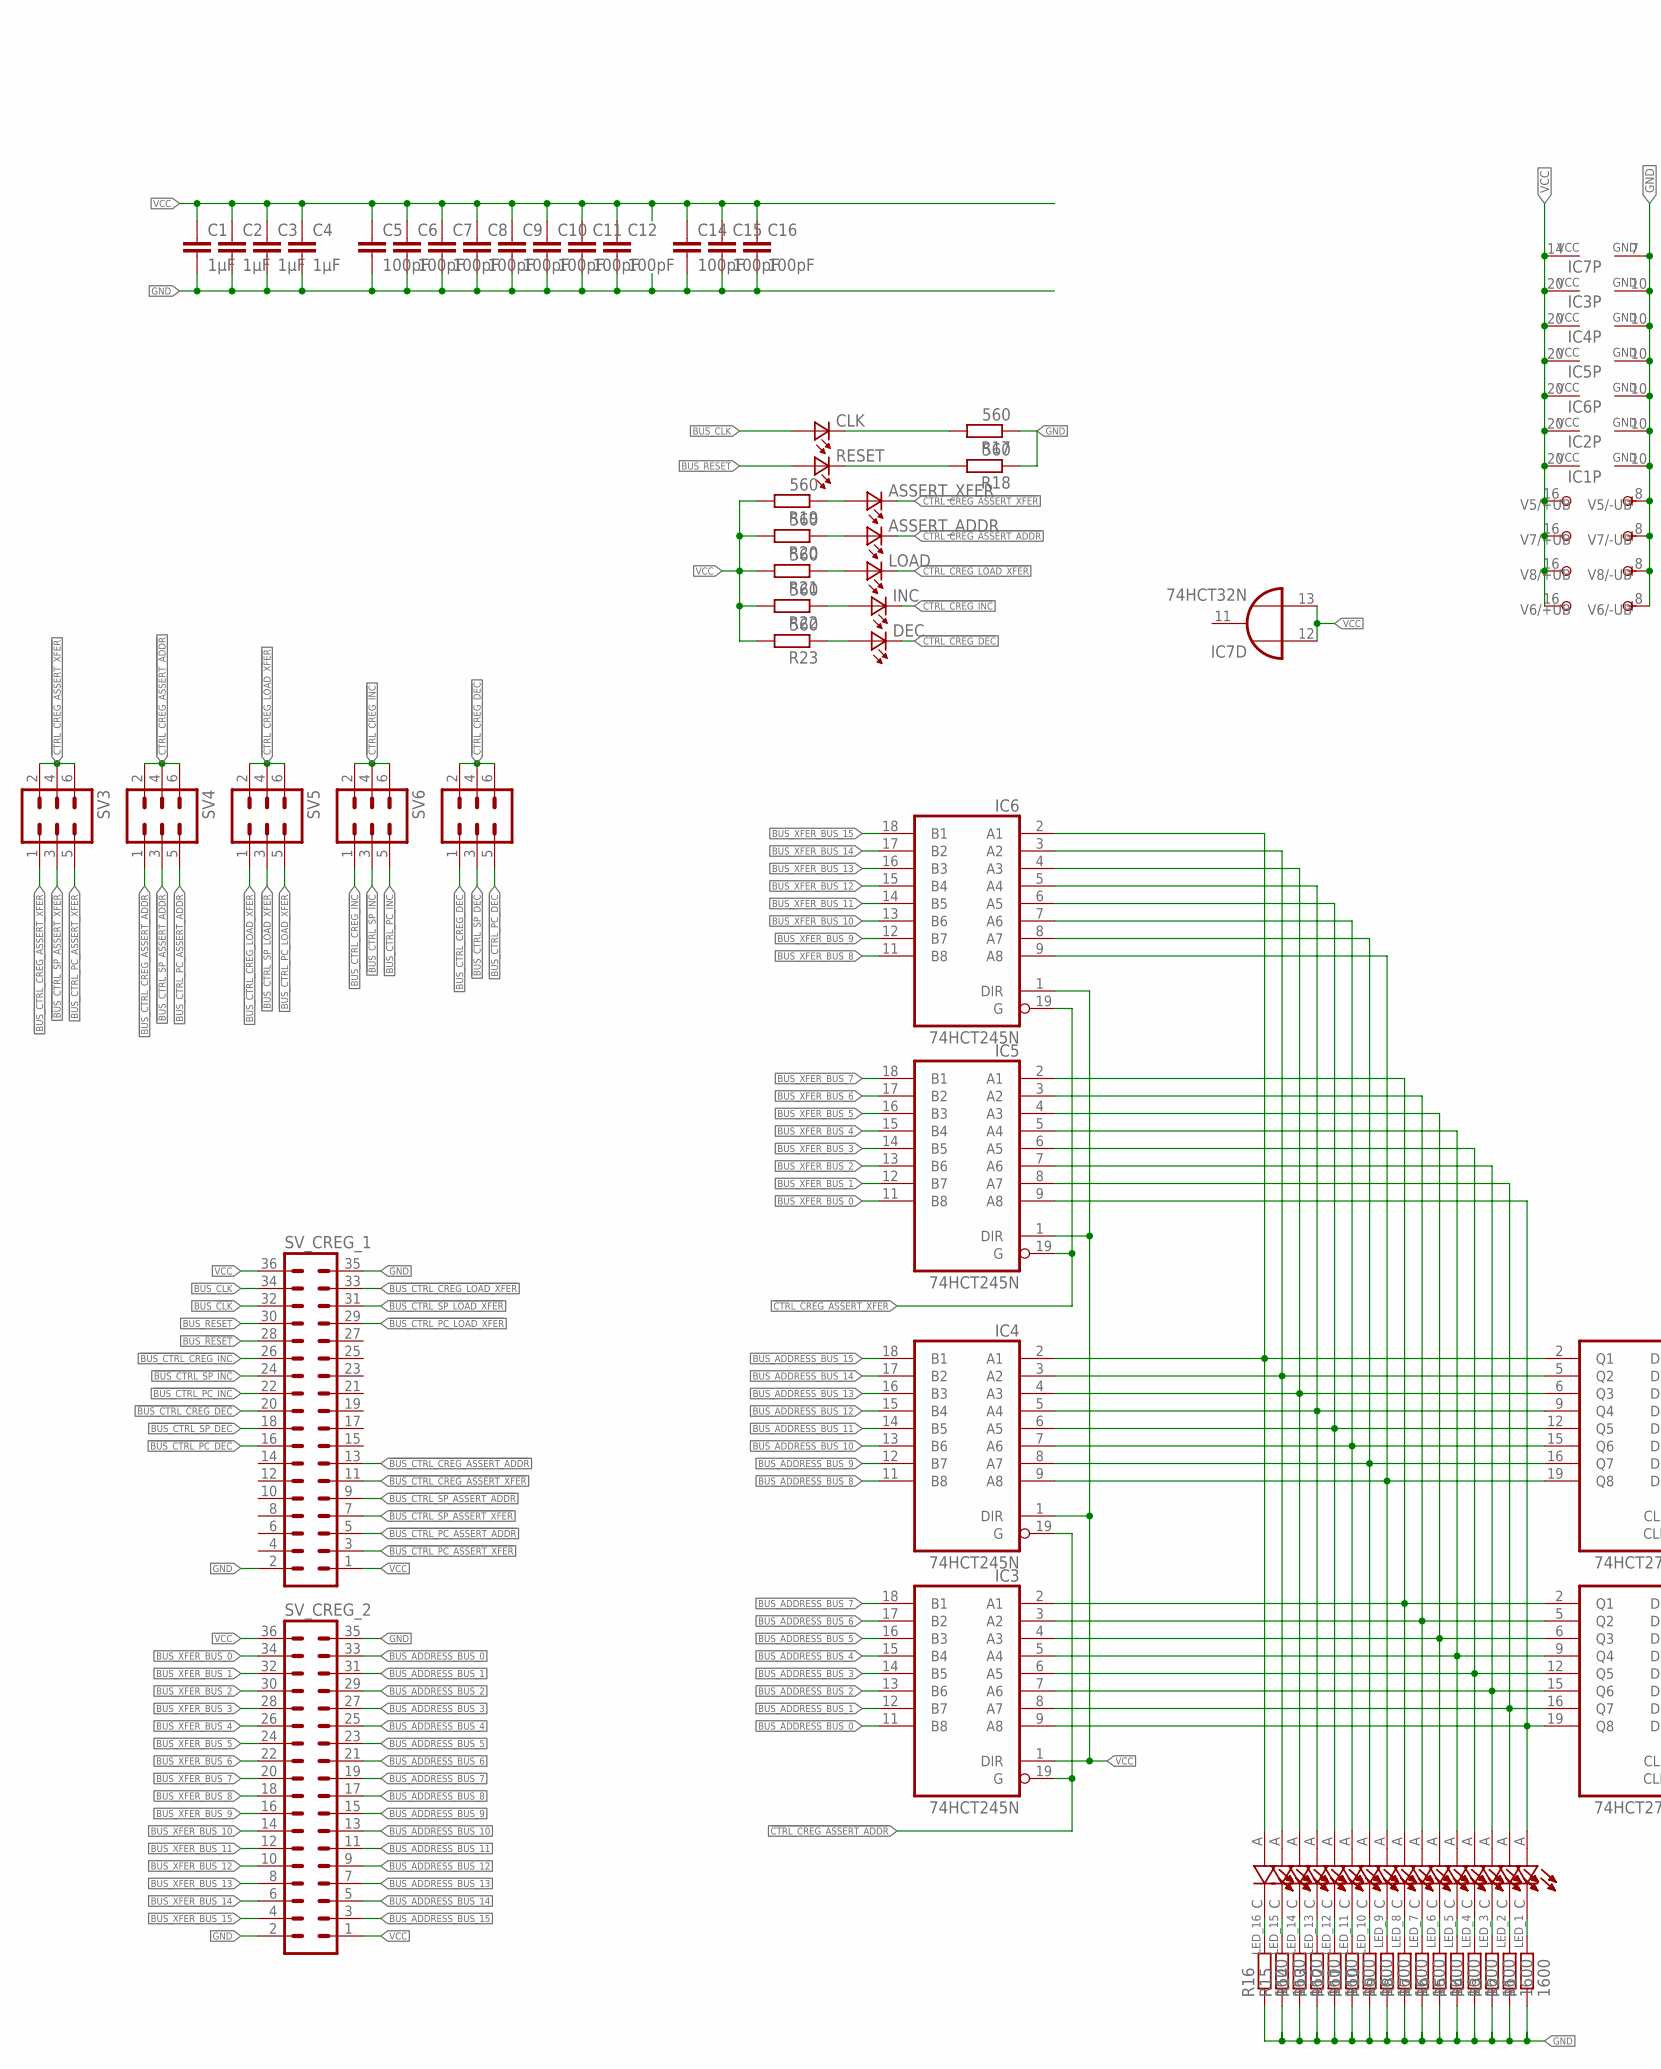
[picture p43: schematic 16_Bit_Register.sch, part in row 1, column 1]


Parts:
ASSERT_ADDR: LTST-C193TBKT-5A; 0603
ASSERT_XFER: LTST-C193TBKT-5A; 0603
C1, C2, C3, C4: 1µF; C0805
C5, C6, C7, C8, C9, C10, C11, C12, C14, C15, C16: 100pF; C0805
CLK: LTST-C193TBKT-5A; 0603
DEC: LTST-C193TBKT-5A; 0603
IC1, IC2: 74HCT273N; DIL20
IC3, IC4, IC5, IC6: 74HCT245N; DIL20
IC7: 74HCT32N; DIL14
INC: LTST-C193TBKT-5A; 0603
LED_1, LED_2, LED_3, LED_4, LED_5, LED_6, LED_7, LED_8, LED_9, LED_10, LED_11, LED_12, LED_13, LED_14, LED_15, LED_16: LTST-C193KRKT-5A; LEDC1608X45N
LOAD: LTST-C193TBKT-5A; 0603
R1, R2, R3, R4, R5, R6, R7, R8, R9, R10, R11, R12, R13, R14, R15, R16: 1600; R0805
R17, R18, R19, R20, R21, R22, R23: 560; R0805
RESET: LTST-C193TBKT-5A; 0603
SV3, SV4, SV5, SV6, SV7: MA03-2
SV_CREG_1, SV_CREG_2: MA18-2
V5, V6, V7, V8: 74193N; DIL16

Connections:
!BUS_CTRL_CREG_ASSERT_ADDR: SV4.1, SV_CREG_1.13
!BUS_CTRL_CREG_ASSERT_XFER: SV3.1, SV_CREG_1.11
!BUS_CTRL_CREG_DEC: SV7.1, SV_CREG_1.20
!BUS_CTRL_CREG_INC: SV6.1, SV_CREG_1.26
!BUS_CTRL_CREG_LOAD_XFER: SV5.1, SV_CREG_1.33
!BUS_CTRL_PC_ASSERT_ADDR: SV4.5, SV_CREG_1.5
!BUS_CTRL_PC_ASSERT_XFER: SV3.5, SV_CREG_1.3
!BUS_CTRL_PC_DEC: SV7.5, SV_CREG_1.16
!BUS_CTRL_PC_INC: SV6.5, SV_CREG_1.22
!BUS_CTRL_PC_LOAD_XFER: SV5.5, SV_CREG_1.29
!BUS_CTRL_SP_ASSERT_ADDR: SV4.3, SV_CREG_1.9
!BUS_CTRL_SP_ASSERT_XFER: SV3.3, SV_CREG_1.7
!BUS_CTRL_SP_DEC: SV7.3, SV_CREG_1.18
!BUS_CTRL_SP_INC: SV6.3, SV_CREG_1.24
!BUS_CTRL_SP_LOAD_XFER: SV5.3, SV_CREG_1.31
!CTRL_CREG_ASSERT_ADDR: ASSERT_ADDR.1 (K2), IC3.19 (G), IC4.19 (G), SV4.2, SV4.4, SV4.6
!CTRL_CREG_ASSERT_XFER: ASSERT_XFER.1 (K2), IC5.19 (G), IC6.19 (G), SV3.2, SV3.4, SV3.6
!CTRL_CREG_DEC: DEC.1 (K2), IC7.5 (I1), SV7.2, SV7.4, SV7.6
!CTRL_CREG_INC: IC7.2 (I1), INC.1 (K2), SV6.2, SV6.4, SV6.6
!CTRL_CREG_LOAD_XFER: IC7.10 (I1), LOAD.1 (K2), SV5.2, SV5.4, SV5.6
BUS_!CLK: IC7.1 (I0), IC7.4 (I0), SV_CREG_1.32
BUS_!RESET: IC1.1 (CLR), IC2.1 (CLR), SV_CREG_1.28
BUS_ADDRESS_BUS_0: IC3.11 (B8), SV_CREG_2.33
BUS_ADDRESS_BUS_1: IC3.12 (B7), SV_CREG_2.31
BUS_ADDRESS_BUS_2: IC3.13 (B6), SV_CREG_2.29
BUS_ADDRESS_BUS_3: IC3.14 (B5), SV_CREG_2.27
BUS_ADDRESS_BUS_4: IC3.15 (B4), SV_CREG_2.25
BUS_ADDRESS_BUS_5: IC3.16 (B3), SV_CREG_2.23
BUS_ADDRESS_BUS_6: IC3.17 (B2), SV_CREG_2.21
BUS_ADDRESS_BUS_7: IC3.18 (B1), SV_CREG_2.19
BUS_ADDRESS_BUS_8: IC4.11 (B8), SV_CREG_2.17
BUS_ADDRESS_BUS_9: IC4.12 (B7), SV_CREG_2.15
BUS_ADDRESS_BUS_10: IC4.13 (B6), SV_CREG_2.13
BUS_ADDRESS_BUS_11: IC4.14 (B5), SV_CREG_2.11
BUS_ADDRESS_BUS_12: IC4.15 (B4), SV_CREG_2.9
BUS_ADDRESS_BUS_13: IC4.16 (B3), SV_CREG_2.7
BUS_ADDRESS_BUS_14: IC4.17 (B2), SV_CREG_2.5
BUS_ADDRESS_BUS_15: IC4.18 (B1), SV_CREG_2.3
BUS_CLK: CLK.2 (A2), IC1.11 (CLK), IC2.11 (CLK), IC7.9 (I0), SV_CREG_1.34
BUS_RESET: RESET.2 (A2), SV_CREG_1.30, V5.14 (CLR), V6.14 (CLR), V7.14 (CLR), V8.14 (CLR)
BUS_XFER_BUS_0: IC5.11 (B8), SV_CREG_2.34, V8.15 (A)
BUS_XFER_BUS_1: IC5.12 (B7), SV_CREG_2.32, V8.1 (B)
BUS_XFER_BUS_2: IC5.13 (B6), SV_CREG_2.30, V8.10 (C)
BUS_XFER_BUS_3: IC5.14 (B5), SV_CREG_2.28, V8.9 (D)
BUS_XFER_BUS_4: IC5.15 (B4), SV_CREG_2.26, V7.15 (A)
BUS_XFER_BUS_5: IC5.16 (B3), SV_CREG_2.24, V7.1 (B)
BUS_XFER_BUS_6: IC5.17 (B2), SV_CREG_2.22, V7.10 (C)
BUS_XFER_BUS_7: IC5.18 (B1), SV_CREG_2.20, V7.9 (D)
BUS_XFER_BUS_8: IC6.11 (B8), SV_CREG_2.18, V6.15 (A)
BUS_XFER_BUS_9: IC6.12 (B7), SV_CREG_2.16, V6.1 (B)
BUS_XFER_BUS_10: IC6.13 (B6), SV_CREG_2.14, V6.10 (C)
BUS_XFER_BUS_11: IC6.14 (B5), SV_CREG_2.12, V6.9 (D)
BUS_XFER_BUS_12: IC6.15 (B4), SV_CREG_2.10, V5.15 (A)
BUS_XFER_BUS_13: IC6.16 (B3), SV_CREG_2.8, V5.1 (B)
BUS_XFER_BUS_14: IC6.17 (B2), SV_CREG_2.6, V5.10 (C)
BUS_XFER_BUS_15: IC6.18 (B1), SV_CREG_2.4, V5.9 (D)
GND: C1.2, C2.2, C3.2, C4.2, C5.2, C6.2, C7.2, C8.2, C9.2, C10.2, C11.2, C12.2, C14.2, C15.2, C16.2, IC1.10 (GND), IC2.10 (GND), IC3.10 (GND), IC4.10 (GND), IC5.10 (GND), IC6.10 (GND), IC7.7 (GND), R1.1, R2.1, R3.1, R4.1, R5.1, R6.1, R7.1, R8.1, R9.1, R10.1, R11.1, R12.1, R13.1, R14.1, R15.1, R16.1, R17.1, R18.1, SV_CREG_1.2, SV_CREG_1.35, SV_CREG_2.2, SV_CREG_2.35, V5.8 (-UB), V6.8 (-UB), V7.8 (-UB), V8.8 (-UB)
unnamed: IC2.19 (Q8), IC3.9 (A8), IC5.9 (A8), LED_1.A
unnamed: IC2.16 (Q7), IC3.8 (A7), IC5.8 (A7), LED_2.A
unnamed: IC2.15 (Q6), IC3.7 (A6), IC5.7 (A6), LED_3.A
unnamed: IC2.12 (Q5), IC3.6 (A5), IC5.6 (A5), LED_4.A
unnamed: IC2.9 (Q4), IC3.5 (A4), IC5.5 (A4), LED_5.A
unnamed: IC2.6 (Q3), IC3.4 (A3), IC5.4 (A3), LED_6.A
unnamed: IC2.5 (Q2), IC3.3 (A2), IC5.3 (A2), LED_7.A
unnamed: IC2.2 (Q1), IC3.2 (A1), IC5.2 (A1), LED_8.A
unnamed: IC1.19 (Q8), IC4.9 (A8), IC6.9 (A8), LED_9.A
unnamed: IC1.16 (Q7), IC4.8 (A7), IC6.8 (A7), LED_10.A
unnamed: IC1.15 (Q6), IC4.7 (A6), IC6.7 (A6), LED_11.A
unnamed: IC1.12 (Q5), IC4.6 (A5), IC6.6 (A5), LED_12.A
unnamed: IC1.9 (Q4), IC4.5 (A4), IC6.5 (A4), LED_13.A
unnamed: IC1.6 (Q3), IC4.4 (A3), IC6.4 (A3), LED_14.A
unnamed: IC1.5 (Q2), IC4.3 (A2), IC6.3 (A2), LED_15.A
unnamed: IC1.2 (Q1), IC4.2 (A1), IC6.2 (A1), LED_16.A
unnamed: LOAD.2 (A2), R21.1
unnamed: ASSERT_ADDR.2 (A2), R20.1
unnamed: LED_1.C, R1.2
unnamed: ASSERT_XFER.2 (A2), R19.1
unnamed: IC2.18 (D8), V5.3 (QA)
unnamed: IC2.17 (D7), V5.2 (QB)
unnamed: IC2.14 (D6), V5.6 (QC)
unnamed: IC2.13 (D5), V5.7 (QD)
unnamed: IC2.8 (D4), V6.3 (QA)
unnamed: IC2.7 (D3), V6.2 (QB)
unnamed: IC2.4 (D2), V6.6 (QC)
unnamed: IC2.3 (D1), V6.7 (QD)
unnamed: IC1.18 (D8), V7.3 (QA)
unnamed: IC1.17 (D7), V7.2 (QB)
unnamed: IC1.14 (D6), V7.6 (QC)
unnamed: IC1.13 (D5), V7.7 (QD)
unnamed: IC1.8 (D4), V8.3 (QA)
unnamed: IC1.7 (D3), V8.2 (QB)
unnamed: IC1.4 (D2), V8.6 (QC)
unnamed: IC1.3 (D1), V8.7 (QD)
unnamed: V5.12 (!CO), V6.5 (UP)
unnamed: V5.13 (!BO), V6.4 (DOWN)
unnamed: V6.12 (!CO), V7.5 (UP)
unnamed: V6.13 (!BO), V7.4 (DOWN)
unnamed: V7.12 (!CO), V8.5 (UP)
unnamed: V7.13 (!BO), V8.4 (DOWN)
unnamed: IC7.6 (O), V5.4 (DOWN)
unnamed: IC7.8 (O), V5.11 (!LOAD), V6.11 (!LOAD), V7.11 (!LOAD), V8.11 (!LOAD)
unnamed: IC7.3 (O), V5.5 (UP)
unnamed: DEC.2 (A2), R23.1
unnamed: INC.2 (A2), R22.1
unnamed: LED_2.C, R2.2
unnamed: LED_3.C, R3.2
unnamed: LED_4.C, R4.2
unnamed: LED_5.C, R5.2
unnamed: LED_6.C, R6.2
unnamed: LED_7.C, R7.2
unnamed: LED_8.C, R8.2
unnamed: LED_9.C, R9.2
unnamed: LED_10.C, R10.2
unnamed: LED_11.C, R11.2
unnamed: LED_12.C, R12.2
unnamed: LED_13.C, R13.2
unnamed: LED_14.C, R14.2
unnamed: CLK.1 (K2), R17.2
unnamed: R18.2, RESET.1 (K2)
unnamed: LED_15.C, R15.2
unnamed: LED_16.C, R16.2
VCC: C1.1, C2.1, C3.1, C4.1, C5.1, C6.1, C7.1, C8.1, C9.1, C10.1, C11.1, C12.1, C14.1, C15.1, C16.1, IC1.20 (VCC), IC2.20 (VCC), IC3.1 (DIR), IC3.20 (VCC), IC4.1 (DIR), IC4.20 (VCC), IC5.1 (DIR), IC5.20 (VCC), IC6.1 (DIR), IC6.20 (VCC), IC7.12 (I0), IC7.13 (I1), IC7.14 (VCC), R19.2, R20.2, R21.2, R22.2, R23.2, SV_CREG_1.1, SV_CREG_1.36, SV_CREG_2.1, SV_CREG_2.36, V5.16 (+UB), V6.16 (+UB), V7.16 (+UB), V8.16 (+UB)


Board: 2 copper layers, 172.7 x 55.9 mm, 79 parts (0 on the bottom side), 122 nets.

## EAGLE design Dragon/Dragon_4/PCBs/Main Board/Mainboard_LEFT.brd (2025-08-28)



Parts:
C1, C2: CPOL-EUE5-10.5; E5-10,5
R1, R2, R3, R4, R5, R6, R7, R8, R9, R10, R11, R12, R13, R14, R15, R16, R17, R18, R19, R20, R21, R22, R23, R24, R25, R26, R27, R28, R29, R30, R31, R32, R33, R34, R35, R36, R37, R38, R39, R40, R41, R42, R43, R44, R45, R46, R47, R48, R49, R50, R51, R52, R53, R54, R55, R56, R57, R58, R59, R60, R61, R62, R63, R64: R-EU_R0805; R0805
SV1_GPR_1, SV1_GPR_2, SV2_CREG_1, SV2_CREG_2, SV2_GPR_1, SV2_GPR_2, SV3_CREG_1, SV3_CREG_2, SV3_GPR_1, SV3_GPR_2, SV4_GPR_1, SV4_GPR_2, SV5_GPR_1, SV5_GPR_2: MA18-2
SV_BUS_CONTROL_1, SV_BUS_CONTROL_2, SV_BUS_CONTROL_3, SV_BUS_CONTROL_4: MA18-2
SV_CONST_REG_1, SV_CONST_REG_2: MA18-2
SV_CREG_1, SV_CREG_2: MA18-2
SV_EXT_1, SV_EXT_2, SV_EXT_3, SV_EXT_4: MA18-2W
SV_XFER_1, SV_XFER_2, SV_XFER_3, SV_XFER_4: MA18-2

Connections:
!CLK: SV1_GPR_1.16, SV2_CREG_1.32, SV2_GPR_1.16, SV3_CREG_1.32, SV3_GPR_1.16, SV4_GPR_1.16, SV5_GPR_1.16, SV_CONST_REG_1.16, SV_CREG_1.32, SV_EXT_3.7, SV_XFER_2.6
!CONST_REG_ASSERT_MAIN_BUS: SV1_GPR_2.3, SV2_GPR_2.3, SV3_GPR_2.3, SV4_GPR_2.3, SV5_GPR_2.3
!CONST_REG_LOAD: SV1_GPR_2.21, SV2_GPR_2.21, SV3_GPR_2.21, SV4_GPR_2.21, SV5_GPR_2.21
!CTRL_ALU_ASSERT: SV_BUS_CONTROL_2.18, SV_EXT_3.13
!CTRL_CONST_ASSERT: SV_BUS_CONTROL_2.6, SV_CONST_REG_2.3
!CTRL_CONST_LOAD: SV_BUS_CONTROL_2.33, SV_CONST_REG_2.21
!CTRL_CREG_ASSERT_ADDR: SV2_CREG_1.13, SV3_CREG_1.13, SV_BUS_CONTROL_3.30, SV_CREG_1.13
!CTRL_CREG_ASSERT_XFER: SV2_CREG_1.11, SV3_CREG_1.11, SV_BUS_CONTROL_2.20, SV_CREG_1.11
!CTRL_CREG_DEC: SV2_CREG_1.20, SV3_CREG_1.20, SV_BUS_CONTROL_3.25, SV_CREG_1.20
!CTRL_CREG_INC: SV2_CREG_1.26, SV3_CREG_1.26, SV_BUS_CONTROL_3.15, SV_CREG_1.26
!CTRL_CREG_LOAD_XFER: SV2_CREG_1.33, SV3_CREG_1.33, SV_BUS_CONTROL_2.19, SV_CREG_1.33
!CTRL_DPLY_ENABLE: SV_BUS_CONTROL_2.23, SV_EXT_3.21
!CTRL_GPR_A_ASSERT: SV_BUS_CONTROL_2.34
!CTRL_GPR_A_ASSERT_ALU_L: SV_BUS_CONTROL_3.16
!CTRL_GPR_A_ASSERT_ALU_R: SV_BUS_CONTROL_3.26
!CTRL_GPR_A_LOAD: SV_BUS_CONTROL_2.5
!CTRL_GPR_B_ASSERT: SV_BUS_CONTROL_2.32
!CTRL_GPR_B_ASSERT_ALU_L: SV_BUS_CONTROL_3.14
!CTRL_GPR_B_ASSERT_ALU_R: SV_BUS_CONTROL_3.24
!CTRL_GPR_B_LOAD: SV_BUS_CONTROL_2.7
!CTRL_GPR_C_ASSERT: SV_BUS_CONTROL_2.30
!CTRL_GPR_C_ASSERT_ALU_L: SV_BUS_CONTROL_3.12
!CTRL_GPR_C_ASSERT_ALU_R: SV_BUS_CONTROL_3.22
!CTRL_GPR_C_LOAD: SV_BUS_CONTROL_2.9
!CTRL_GPR_D_ASSERT: SV_BUS_CONTROL_2.28
!CTRL_GPR_D_ASSERT_ALU_L: SV_BUS_CONTROL_3.10
!CTRL_GPR_D_ASSERT_ALU_R: SV_BUS_CONTROL_3.20
!CTRL_GPR_D_LOAD: SV_BUS_CONTROL_2.11
!CTRL_GPR_X_ASSERT: SV_BUS_CONTROL_2.26
!CTRL_GPR_X_ASSERT_ALU_L: SV_BUS_CONTROL_3.8
!CTRL_GPR_X_ASSERT_ALU_R: SV_BUS_CONTROL_3.18
!CTRL_GPR_X_LOAD: SV_BUS_CONTROL_2.13
!CTRL_IR_LOAD: SV_BUS_CONTROL_2.25, SV_EXT_3.23
!CTRL_PC_ASSERT_ADDR: SV2_CREG_1.5, SV3_CREG_1.5, SV_BUS_CONTROL_3.34, SV_CREG_1.5
!CTRL_PC_ASSERT_XFER: SV2_CREG_1.3, SV3_CREG_1.3, SV_BUS_CONTROL_2.24, SV_CREG_1.3
!CTRL_PC_DEC: SV2_CREG_1.16, SV3_CREG_1.16, SV_BUS_CONTROL_3.21, SV_CREG_1.16
!CTRL_PC_INC: SV2_CREG_1.22, SV3_CREG_1.22, SV_BUS_CONTROL_3.11, SV_CREG_1.22
!CTRL_PC_LOAD_XFER: SV2_CREG_1.29, SV3_CREG_1.29, SV_BUS_CONTROL_2.15, SV_CREG_1.29
!CTRL_RAM_ASSERT_MAIN: SV_BUS_CONTROL_2.16, SV_EXT_3.15
!CTRL_RAM_LOAD_MAIN: SV_BUS_CONTROL_2.21, SV_EXT_3.19
!CTRL_SP_ASSERT_ADDR: SV2_CREG_1.9, SV3_CREG_1.9, SV_BUS_CONTROL_3.32, SV_CREG_1.9
!CTRL_SP_ASSERT_XFER: SV2_CREG_1.7, SV3_CREG_1.7, SV_BUS_CONTROL_2.22, SV_CREG_1.7
!CTRL_SP_DEC: SV2_CREG_1.18, SV3_CREG_1.18, SV_BUS_CONTROL_3.23, SV_CREG_1.18
!CTRL_SP_INC: SV2_CREG_1.24, SV3_CREG_1.24, SV_BUS_CONTROL_3.13, SV_CREG_1.24
!CTRL_SP_LOAD_XFER: SV2_CREG_1.31, SV3_CREG_1.31, SV_BUS_CONTROL_2.17, SV_CREG_1.31
!CTRL_XFER_ASSERT_ADDR: SV_BUS_CONTROL_3.28, SV_XFER_2.23
!CTRL_XFER_ASSERT_XFER: SV_BUS_CONTROL_2.12, SV_XFER_2.25
!CTRL_XFER_LOAD_XFER: SV_BUS_CONTROL_2.27, SV_XFER_2.29
!CTRL_XFER_L_ASSERT: SV_BUS_CONTROL_2.8, SV_XFER_2.19
!CTRL_XFER_L_LOAD: SV_BUS_CONTROL_2.31, SV_XFER_2.31
!CTRL_XFER_R_ASSERT: SV_BUS_CONTROL_2.10, SV_XFER_2.21
!CTRL_XFER_R_LOAD: SV_BUS_CONTROL_2.29, SV_XFER_2.33
!GPR_A_ALU_LEFT_ASSERT: SV1_GPR_2.34, SV2_GPR_2.34, SV3_GPR_2.34, SV4_GPR_2.34, SV5_GPR_2.34
!GPR_A_ALU_RIGHT_ASSERT: SV1_GPR_2.24, SV2_GPR_2.24, SV3_GPR_2.24, SV4_GPR_2.24, SV5_GPR_2.24
!GPR_A_ASSERT_MAIN_BUS: SV1_GPR_2.15, SV2_GPR_2.15, SV3_GPR_2.15, SV4_GPR_2.15, SV5_GPR_2.15
!GPR_A_LOAD: SV1_GPR_2.33, SV2_GPR_2.33, SV3_GPR_2.33, SV4_GPR_2.33, SV5_GPR_2.33
!GPR_B_ALU_LEFT_ASSERT: SV1_GPR_2.32, SV2_GPR_2.32, SV3_GPR_2.32, SV4_GPR_2.32, SV5_GPR_2.32
!GPR_B_ALU_RIGHT_ASSERT: SV1_GPR_2.22, SV2_GPR_2.22, SV3_GPR_2.22, SV4_GPR_2.22, SV5_GPR_2.22
!GPR_B_ASSERT_MAIN_BUS: SV1_GPR_2.13, SV2_GPR_2.13, SV3_GPR_2.13, SV4_GPR_2.13, SV5_GPR_2.13
!GPR_B_LOAD: SV1_GPR_2.31, SV2_GPR_2.31, SV3_GPR_2.31, SV4_GPR_2.31, SV5_GPR_2.31
!GPR_C_ALU_LEFT_ASSERT: SV1_GPR_2.30, SV2_GPR_2.30, SV3_GPR_2.30, SV4_GPR_2.30, SV5_GPR_2.30
!GPR_C_ALU_RIGHT_ASSERT: SV1_GPR_2.20, SV2_GPR_2.20, SV3_GPR_2.20, SV4_GPR_2.20, SV5_GPR_2.20
!GPR_C_ASSERT_MAIN_BUS: SV1_GPR_2.11, SV2_GPR_2.11, SV3_GPR_2.11, SV4_GPR_2.11, SV5_GPR_2.11
!GPR_C_LOAD: SV1_GPR_2.29, SV2_GPR_2.29, SV3_GPR_2.29, SV4_GPR_2.29, SV5_GPR_2.29
!GPR_D_ALU_LEFT_ASSERT: SV1_GPR_2.28, SV2_GPR_2.28, SV3_GPR_2.28, SV4_GPR_2.28, SV5_GPR_2.28
!GPR_D_ALU_RIGHT_ASSERT: SV1_GPR_2.18, SV2_GPR_2.18, SV3_GPR_2.18, SV4_GPR_2.18, SV5_GPR_2.18
!GPR_D_ASSERT_MAIN_BUS: SV1_GPR_2.9, SV2_GPR_2.9, SV3_GPR_2.9, SV4_GPR_2.9, SV5_GPR_2.9
!GPR_D_LOAD: SV1_GPR_2.27, SV2_GPR_2.27, SV3_GPR_2.27, SV4_GPR_2.27, SV5_GPR_2.27
!GPR_X_ALU_LEFT_ASSERT: SV1_GPR_2.26, SV2_GPR_2.26, SV3_GPR_2.26, SV4_GPR_2.26, SV5_GPR_2.26
!GPR_X_ALU_RIGHT_ASSERT: SV1_GPR_2.16, SV2_GPR_2.16, SV3_GPR_2.16, SV4_GPR_2.16, SV5_GPR_2.16
!GPR_X_ASSERT_MAIN_BUS: SV1_GPR_2.7, SV2_GPR_2.7, SV3_GPR_2.7, SV4_GPR_2.7, SV5_GPR_2.7
!GPR_X_LOAD: SV1_GPR_2.25, SV2_GPR_2.25, SV3_GPR_2.25, SV4_GPR_2.25, SV5_GPR_2.25
!RESERVED_ASSERT: SV1_GPR_2.5, SV2_GPR_2.5, SV3_GPR_2.5, SV4_GPR_2.5, SV5_GPR_2.5
!RESERVERD_LOAD: SV1_GPR_2.23, SV2_GPR_2.23, SV3_GPR_2.23, SV4_GPR_2.23, SV5_GPR_2.23
!RESET: SV1_GPR_1.12, SV2_CREG_1.28, SV2_GPR_1.12, SV3_CREG_1.28, SV3_GPR_1.12, SV4_GPR_1.12, SV5_GPR_1.12, SV_CONST_REG_1.12, SV_CREG_1.28, SV_EXT_3.11, SV_XFER_2.10
ADDRESS_BUS_0: R33.1, SV2_CREG_2.33, SV3_CREG_2.33, SV_CREG_2.33, SV_EXT_1.4, SV_XFER_1.4
ADDRESS_BUS_1: R34.1, SV2_CREG_2.31, SV3_CREG_2.31, SV_CREG_2.31, SV_EXT_1.6, SV_XFER_1.6
ADDRESS_BUS_2: R35.1, SV2_CREG_2.29, SV3_CREG_2.29, SV_CREG_2.29, SV_EXT_1.8, SV_XFER_1.8
ADDRESS_BUS_3: R36.1, SV2_CREG_2.27, SV3_CREG_2.27, SV_CREG_2.27, SV_EXT_1.10, SV_XFER_1.10
ADDRESS_BUS_4: R37.1, SV2_CREG_2.25, SV3_CREG_2.25, SV_CREG_2.25, SV_EXT_1.12, SV_XFER_1.12
ADDRESS_BUS_5: R38.1, SV2_CREG_2.23, SV3_CREG_2.23, SV_CREG_2.23, SV_EXT_1.14, SV_XFER_1.14
ADDRESS_BUS_6: R39.1, SV2_CREG_2.21, SV3_CREG_2.21, SV_CREG_2.21, SV_EXT_1.16, SV_XFER_1.16
ADDRESS_BUS_7: R40.1, SV2_CREG_2.19, SV3_CREG_2.19, SV_CREG_2.19, SV_EXT_1.18, SV_XFER_1.18
ADDRESS_BUS_8: R41.1, SV2_CREG_2.17, SV3_CREG_2.17, SV_CREG_2.17, SV_EXT_1.20, SV_XFER_1.20
ADDRESS_BUS_9: R42.1, SV2_CREG_2.15, SV3_CREG_2.15, SV_CREG_2.15, SV_EXT_1.22, SV_XFER_1.22
ADDRESS_BUS_10: R43.1, SV2_CREG_2.13, SV3_CREG_2.13, SV_CREG_2.13, SV_EXT_1.24, SV_XFER_1.24
ADDRESS_BUS_11: R44.1, SV2_CREG_2.11, SV3_CREG_2.11, SV_CREG_2.11, SV_EXT_1.26, SV_XFER_1.26
ADDRESS_BUS_12: R45.1, SV2_CREG_2.9, SV3_CREG_2.9, SV_CREG_2.9, SV_EXT_1.28, SV_XFER_1.28
ADDRESS_BUS_13: R46.1, SV2_CREG_2.7, SV3_CREG_2.7, SV_CREG_2.7, SV_EXT_1.30, SV_XFER_1.30
ADDRESS_BUS_14: R47.1, SV2_CREG_2.5, SV3_CREG_2.5, SV_CREG_2.5, SV_EXT_1.32, SV_XFER_1.32
ADDRESS_BUS_15: R48.1, SV2_CREG_2.3, SV3_CREG_2.3, SV_CREG_2.3, SV_EXT_1.34, SV_XFER_1.34
ALU_LEFT_BUS_0: R9.1, SV1_GPR_1.17, SV2_GPR_1.17, SV3_GPR_1.17, SV4_GPR_1.17, SV5_GPR_1.17, SV_EXT_2.4
ALU_LEFT_BUS_1: R10.1, SV1_GPR_1.15, SV2_GPR_1.15, SV3_GPR_1.15, SV4_GPR_1.15, SV5_GPR_1.15, SV_EXT_2.6
ALU_LEFT_BUS_2: R11.1, SV1_GPR_1.13, SV2_GPR_1.13, SV3_GPR_1.13, SV4_GPR_1.13, SV5_GPR_1.13, SV_EXT_2.8
ALU_LEFT_BUS_3: R12.1, SV1_GPR_1.11, SV2_GPR_1.11, SV3_GPR_1.11, SV4_GPR_1.11, SV5_GPR_1.11, SV_EXT_2.10
ALU_LEFT_BUS_4: R13.1, SV1_GPR_1.9, SV2_GPR_1.9, SV3_GPR_1.9, SV4_GPR_1.9, SV5_GPR_1.9, SV_EXT_2.12
ALU_LEFT_BUS_5: R14.1, SV1_GPR_1.7, SV2_GPR_1.7, SV3_GPR_1.7, SV4_GPR_1.7, SV5_GPR_1.7, SV_EXT_2.14
ALU_LEFT_BUS_6: R15.1, SV1_GPR_1.5, SV2_GPR_1.5, SV3_GPR_1.5, SV4_GPR_1.5, SV5_GPR_1.5, SV_EXT_2.16
ALU_LEFT_BUS_7: R16.1, SV1_GPR_1.3, SV2_GPR_1.3, SV3_GPR_1.3, SV4_GPR_1.3, SV5_GPR_1.3, SV_EXT_2.18
ALU_RIGHT_BUS_0: R8.1, SV1_GPR_1.34, SV2_GPR_1.34, SV3_GPR_1.34, SV4_GPR_1.34, SV5_GPR_1.34, SV_EXT_2.3
ALU_RIGHT_BUS_1: R7.1, SV1_GPR_1.32, SV2_GPR_1.32, SV3_GPR_1.32, SV4_GPR_1.32, SV5_GPR_1.32, SV_EXT_2.5
ALU_RIGHT_BUS_2: R6.1, SV1_GPR_1.30, SV2_GPR_1.30, SV3_GPR_1.30, SV4_GPR_1.30, SV5_GPR_1.30, SV_EXT_2.7
ALU_RIGHT_BUS_3: R5.1, SV1_GPR_1.28, SV2_GPR_1.28, SV3_GPR_1.28, SV4_GPR_1.28, SV5_GPR_1.28, SV_EXT_2.9
ALU_RIGHT_BUS_4: R4.1, SV1_GPR_1.26, SV2_GPR_1.26, SV3_GPR_1.26, SV4_GPR_1.26, SV5_GPR_1.26, SV_EXT_2.11
ALU_RIGHT_BUS_5: R3.1, SV1_GPR_1.24, SV2_GPR_1.24, SV3_GPR_1.24, SV4_GPR_1.24, SV5_GPR_1.24, SV_EXT_2.13
ALU_RIGHT_BUS_6: R2.1, SV1_GPR_1.22, SV2_GPR_1.22, SV3_GPR_1.22, SV4_GPR_1.22, SV5_GPR_1.22, SV_EXT_2.15
ALU_RIGHT_BUS_7: R1.1, SV1_GPR_1.20, SV2_GPR_1.20, SV3_GPR_1.20, SV4_GPR_1.20, SV5_GPR_1.20, SV_EXT_2.17
BUS_CTRL1_REG_A_1: SV_BUS_CONTROL_1.34, SV_EXT_3.34
BUS_CTRL2_REG_A_2: SV_BUS_CONTROL_1.32, SV_EXT_3.32
BUS_CTRL3_REG_A_3: SV_BUS_CONTROL_1.30, SV_EXT_3.30
BUS_CTRL4_REG_A_4: SV_BUS_CONTROL_1.28, SV_EXT_3.28
BUS_CTRL5_REG_L_1: SV_BUS_CONTROL_1.26, SV_EXT_3.26
BUS_CTRL6_REG_L_2: SV_BUS_CONTROL_1.24, SV_EXT_3.24
BUS_CTRL7_REG_L_3: SV_BUS_CONTROL_1.22, SV_EXT_3.22
BUS_CTRL8_REG_L_4: SV_BUS_CONTROL_1.20, SV_EXT_3.20
BUS_CTRL9_16REG_A_ADDR_1: SV_BUS_CONTROL_1.18, SV_EXT_3.18
BUS_CTRL10_16REG_A_ADDR_2: SV_BUS_CONTROL_1.16, SV_EXT_3.16
BUS_CTRL11_16REG_A_ADDR_3: SV_BUS_CONTROL_1.14, SV_EXT_3.14
BUS_CTRL12_CREG_INC_1: SV_BUS_CONTROL_1.12, SV_EXT_3.12
BUS_CTRL13_CREG_INC_2: SV_BUS_CONTROL_1.10, SV_EXT_3.10
BUS_CTRL14_CREG_DEC_1: SV_BUS_CONTROL_1.8, SV_EXT_3.8
BUS_CTRL15_CREG_DEC_2: SV_BUS_CONTROL_1.6, SV_EXT_3.6
BUS_CTRL17_GPR_A_ALU_R_1: SV_BUS_CONTROL_1.29, SV_EXT_3.4
BUS_CTRL18_GPR_A_ALU_R_2: SV_BUS_CONTROL_1.31, SV_EXT_3.33
BUS_CTRL19_GPR_A_ALU_R_3: SV_BUS_CONTROL_1.33, SV_EXT_3.31
BUS_CTRL20_GPR_A_ALU_L_1: SV_BUS_CONTROL_1.23, SV_EXT_3.29
BUS_CTRL21_GPR_A_ALU_L_2: SV_BUS_CONTROL_1.25, SV_EXT_3.27
BUS_CTRL22_GPR_A_ALU_L_3: SV_BUS_CONTROL_1.27, SV_EXT_3.25
CLK: SV1_GPR_1.18, SV2_CREG_1.34, SV2_GPR_1.18, SV3_CREG_1.34, SV3_GPR_1.18, SV4_GPR_1.18, SV5_GPR_1.18, SV_CONST_REG_1.18, SV_CREG_1.34, SV_EXT_3.5, SV_XFER_2.4
GND: C1.-, C2.-, R1.2, R2.2, R3.2, R4.2, R5.2, R6.2, R7.2, R8.2, R9.2, R10.2, R11.2, R12.2, R13.2, R14.2, R15.2, R16.2, R17.2, R18.2, R19.2, R20.2, R21.2, R22.2, R23.2, R24.2, R25.2, R26.2, R27.2, R28.2, R29.2, R30.2, R31.2, R32.2, R33.2, R34.2, R35.2, R36.2, R37.2, R38.2, R39.2, R40.2, R41.2, R42.2, R43.2, R44.2, R45.2, R46.2, R47.2, R48.2, R49.2, R50.2, R51.2, R52.2, R53.2, R54.2, R55.2, R56.2, R57.2, R58.2, R59.2, R60.2, R61.2, R62.2, R63.2, R64.2, SV1_GPR_1.2, SV1_GPR_1.35, SV1_GPR_2.2, SV1_GPR_2.17, SV1_GPR_2.19, SV1_GPR_2.35, SV2_CREG_1.2, SV2_CREG_1.35, SV2_CREG_2.2, SV2_CREG_2.35, SV2_GPR_1.2, SV2_GPR_1.35, SV2_GPR_2.2, SV2_GPR_2.17, SV2_GPR_2.19, SV2_GPR_2.35, SV3_CREG_1.2, SV3_CREG_1.35, SV3_CREG_2.2, SV3_CREG_2.35, SV3_GPR_1.2, SV3_GPR_1.35, SV3_GPR_2.2, SV3_GPR_2.17, SV3_GPR_2.19, SV3_GPR_2.35, SV4_GPR_1.2, SV4_GPR_1.35, SV4_GPR_2.2, SV4_GPR_2.17, SV4_GPR_2.19, SV4_GPR_2.35, SV5_GPR_1.2, SV5_GPR_1.35, SV5_GPR_2.2, SV5_GPR_2.17, SV5_GPR_2.19, SV5_GPR_2.35, SV_BUS_CONTROL_1.2, SV_BUS_CONTROL_1.35, SV_BUS_CONTROL_2.2, SV_BUS_CONTROL_2.35, SV_BUS_CONTROL_3.2, SV_BUS_CONTROL_3.35, SV_BUS_CONTROL_4.2, SV_BUS_CONTROL_4.35, SV_CONST_REG_1.2, SV_CONST_REG_1.35, SV_CONST_REG_2.2, SV_CONST_REG_2.17, SV_CONST_REG_2.19, SV_CONST_REG_2.35, SV_CREG_1.2, SV_CREG_1.35, SV_CREG_2.2, SV_CREG_2.35, SV_EXT_1.2, SV_EXT_1.35, SV_EXT_2.2, SV_EXT_2.35, SV_EXT_3.2, SV_EXT_3.35, SV_EXT_4.2, SV_EXT_4.35, SV_XFER_1.2, SV_XFER_1.35, SV_XFER_2.2, SV_XFER_2.35, SV_XFER_3.2, SV_XFER_3.35, SV_XFER_4.2, SV_XFER_4.35
MAIN_BUS_0: R17.1, SV1_GPR_1.33, SV2_GPR_1.33, SV3_GPR_1.33, SV4_GPR_1.33, SV5_GPR_1.33, SV_CONST_REG_1.33, SV_EXT_2.20, SV_XFER_2.20
MAIN_BUS_1: R18.1, SV1_GPR_1.31, SV2_GPR_1.31, SV3_GPR_1.31, SV4_GPR_1.31, SV5_GPR_1.31, SV_CONST_REG_1.31, SV_EXT_2.22, SV_XFER_2.22
MAIN_BUS_2: R19.1, SV1_GPR_1.29, SV2_GPR_1.29, SV3_GPR_1.29, SV4_GPR_1.29, SV5_GPR_1.29, SV_CONST_REG_1.29, SV_EXT_2.24, SV_XFER_2.24
MAIN_BUS_3: R20.1, SV1_GPR_1.27, SV2_GPR_1.27, SV3_GPR_1.27, SV4_GPR_1.27, SV5_GPR_1.27, SV_CONST_REG_1.27, SV_EXT_2.26, SV_XFER_2.26
MAIN_BUS_4: R21.1, SV1_GPR_1.25, SV2_GPR_1.25, SV3_GPR_1.25, SV4_GPR_1.25, SV5_GPR_1.25, SV_CONST_REG_1.25, SV_EXT_2.28, SV_XFER_2.28
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

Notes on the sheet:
Großer Cap, aber welcher


Board: 2 copper layers, 312.4 x 379.7 mm, 96 parts (0 on the bottom side), 145 nets.

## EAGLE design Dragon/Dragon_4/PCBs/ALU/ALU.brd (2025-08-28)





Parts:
C1, C2, C3, C4, C5, C6, C7, C8, C9, C10, C11, C12, C13, C14, C15, C16, C17, C18, C19, C20, C21, C22, C23, C24, C25, C26, C27, C28, C29: 100pF; C0805
C30, C31, C32, C33: 1µF; C0805
D1, D2, D3, D4, D5, D6, D7, D8, D9, D10, D11, D12, D13, D14, D15, D16, D17, D18, D19, D20, D21, D22, D23, D24, D25, D26, D27, D28, D29, D30, D31, D32: LTST-C193KRKT-5A; LEDC1608X45N
D33, D34, D35, D36, D37, D38, D40, D41, D42, D43, D44, D45, D46, D47, D48, D49, D50, D51, D52, D53, D54, D55, D56: LTST-C193TBKT-5A; 0603
IC1, IC2: 74HC283N; DIL16
IC3: 74HCT154N; DIL24-6
IC4, IC5, IC19, IC20: 74HCT86N; DIL14
IC6, IC7, IC11, IC13: 74HCT08N; DIL14
IC8: 74HCT04N; DIL14
IC9: 74HCT00N; DIL14
IC10, IC17, IC18, IC39: 74HCT32N; DIL14
IC12, IC14, IC15, IC16, IC21, IC22, IC23, IC24, IC25, IC38: 74HCT245N; DIL20
IC36: 74HCT273N; DIL20
IC37: 74HCT02N; DIL14
R1, R2, R3, R4, R5, R6, R7, R8, R9, R10, R11, R12, R13, R14, R15, R16, R17, R18, R19, R20, R21, R22, R23, R24, R25, R26, R27, R28, R29, R30, R31, R32: 1600; R0805
R33, R34, R35, R36, R37, R38, R40, R42, R43, R44, R45, R46, R47, R48, R49, R50, R51, R52, R53, R54, R55, R56, R57: 560; R0805
R41: PULL DOWN; R0805
SV_ALU_1, SV_ALU_2: MA18-2
SV_ALU_SUP1, SV_ALU_SUP2, SV_ALU_SUP3, SV_ALU_SUP4, SV_ALU_SUP5, SV_ALU_SUP6: MA03-2

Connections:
!CTRL_ALU_ASSERT: D40.1 (K2), IC38.19 (G), SV_ALU_2.32
ADC: IC3.2 (1), IC6.2 (I1), IC9.1 (I0), R43.1
ADD: IC3.1 (0), IC6.1 (I0), R42.1
ALU_CARRY_FLAG: IC2.9 (C4), SV_ALU_2.33
ALU_SIGN_FLAG: D1.A, IC12.2 (A1), IC14.2 (A1), IC15.2 (A1), IC16.2 (A1), IC21.2 (A1), IC22.2 (A1), IC23.2 (A1), IC24.2 (A1), IC25.2 (A1), IC36.3 (D1), IC37.2 (I0), SV_ALU_2.29
ALU_ZERO_FLAG: IC39.8 (O), SV_ALU_2.31
AND: IC3.7 (6), IC14.19 (G), R48.1
ARS: IC3.15 (13), IC23.19 (G), R55.1
BUS_!CLK: SV_ALU_1.32
BUS_!RESET: IC36.1 (CLR), SV_ALU_1.28
BUS_CARRY_FLAG: IC7.12 (I0), SV_ALU_2.27
BUS_CLK: D37.2 (A2), IC36.11 (CLK), SV_ALU_1.34
BUS_MAIN_BUS_0: IC38.18 (B1), SV_ALU_2.17
BUS_MAIN_BUS_1: IC38.17 (B2), SV_ALU_2.15
BUS_MAIN_BUS_2: IC38.16 (B3), SV_ALU_2.13
BUS_MAIN_BUS_3: IC38.15 (B4), SV_ALU_2.11
BUS_MAIN_BUS_4: IC38.14 (B5), SV_ALU_2.9
BUS_MAIN_BUS_5: IC38.13 (B6), SV_ALU_2.7
BUS_MAIN_BUS_6: IC38.12 (B7), SV_ALU_2.5
BUS_MAIN_BUS_7: IC38.11 (B8), SV_ALU_2.3
BUS_RESET: D38.2 (A2), SV_ALU_1.30
BUS_SIGN_FLAG: SV_ALU_2.23
BUS_ZERO_FLAG: SV_ALU_2.25
CTRL25_ALU_OP_1: D36.1 (K2), IC3.23 (A), SV_ALU_2.24
CTRL26_ALU_OP_2: D35.1 (K2), IC3.22 (B), SV_ALU_2.26
CTRL27_ALU_OP_3: D34.1 (K2), IC3.21 (C), SV_ALU_2.28
CTRL28_ALU_OP_4: D33.1 (K2), IC3.20 (D), SV_ALU_2.30
DEC: IC3.6 (5), IC6.10 (I1), IC8.5 (I), R47.1
GND: C1.2, C2.2, C3.2, C4.2, C5.2, C6.2, C7.2, C8.2, C9.2, C10.2, C11.2, C12.2, C13.2, C14.2, C15.2, C16.2, C17.2, C18.2, C19.2, C20.2, C21.2, C22.2, C23.2, C24.2, C25.2, C26.2, C27.2, C28.2, C29.2, C30.2, C31.2, C32.2, C33.2, IC1.8 (GND), IC2.8 (GND), IC3.12 (GND), IC3.18 (G1), IC3.19 (G2), IC4.7 (GND), IC5.7 (GND), IC6.7 (GND), IC7.7 (GND), IC8.7 (GND), IC9.7 (GND), IC10.7 (GND), IC11.7 (GND), IC12.1 (DIR), IC12.10 (GND), IC13.7 (GND), IC14.1 (DIR), IC14.10 (GND), IC15.1 (DIR), IC15.10 (GND), IC16.1 (DIR), IC16.10 (GND), IC17.7 (GND), IC18.7 (GND), IC19.7 (GND), IC20.7 (GND), IC21.1 (DIR), IC21.10 (GND), IC22.1 (DIR), IC22.10 (GND), IC23.1 (DIR), IC23.10 (GND), IC24.1 (DIR), IC24.10 (GND), IC25.1 (DIR), IC25.10 (GND), IC36.10 (GND), IC37.7 (GND), IC38.10 (GND), IC39.7 (GND), R1.2, R2.2, R3.2, R4.2, R5.2, R6.2, R7.2, R8.2, R9.2, R10.2, R11.2, R12.2, R13.2, R14.2, R15.2, R16.2, R17.2, R18.2, R19.2, R20.2, R21.2, R22.2, R23.2, R24.2, R25.2, R26.2, R27.2, R28.2, R29.2, R30.2, R31.2, R32.2, R33.2, R34.2, R35.2, R36.2, R37.2, R38.2, R41.2, SV_ALU_1.2, SV_ALU_1.35, SV_ALU_2.2, SV_ALU_2.35, SV_ALU_SUP1.2, SV_ALU_SUP1.4, SV_ALU_SUP1.6, SV_ALU_SUP2.2, SV_ALU_SUP2.4, SV_ALU_SUP2.6, SV_ALU_SUP3.2, SV_ALU_SUP3.4, SV_ALU_SUP3.6, SV_ALU_SUP4.2, SV_ALU_SUP4.4, SV_ALU_SUP4.6, SV_ALU_SUP5.2, SV_ALU_SUP5.4, SV_ALU_SUP5.6, SV_ALU_SUP6.2, SV_ALU_SUP6.4, SV_ALU_SUP6.6
INC: IC3.5 (4), IC6.9 (I0), IC9.5 (I1), R46.1
LRS: IC3.14 (12), IC22.19 (G), R54.1
unnamed: IC4.2 (I1), IC4.5 (I1), IC4.10 (I1), IC4.13 (I1), IC5.2 (I1), IC5.5 (I1), IC5.10 (I1), IC5.13 (I1), IC10.11 (O)
unnamed: IC1.6 (B1), IC4.3 (O)
unnamed: D33.2 (A2), R33.1
unnamed: IC1.2 (B2), IC4.6 (O)
unnamed: D27.A, IC4.9 (I0), IC11.10 (I1), IC17.10 (I1), IC19.10 (I1), SV_ALU_1.7
unnamed: IC1.15 (B3), IC4.8 (O)
unnamed: IC1.11 (B4), IC4.11 (O)
unnamed: IC2.6 (B1), IC5.3 (O)
unnamed: IC2.2 (B2), IC5.6 (O)
unnamed: IC2.15 (B3), IC5.8 (O)
unnamed: IC2.11 (B4), IC5.11 (O)
unnamed: IC1.9 (C4), IC2.7 (C0)
unnamed: IC1.7 (C0), IC39.11 (O)
unnamed: IC1.4 (S1), IC12.18 (B1)
unnamed: IC1.1 (S2), IC12.17 (B2)
unnamed: D16.C, R16.1
unnamed: IC1.13 (S3), IC12.16 (B3)
unnamed: IC1.10 (S4), IC12.15 (B4)
unnamed: IC2.4 (S1), IC12.14 (B5)
unnamed: IC37.1 (O), IC39.1 (I0)
unnamed: IC37.4 (O), IC39.2 (I1)
unnamed: IC37.10 (O), IC39.4 (I0)
unnamed: IC37.13 (O), IC39.5 (I1)
unnamed: D15.C, R15.1
unnamed: IC39.6 (O), IC39.10 (I1)
unnamed: IC39.3 (O), IC39.9 (I0)
unnamed: D34.2 (A2), R34.1
unnamed: D35.2 (A2), R35.1
unnamed: D36.2 (A2), R36.1
unnamed: D40.2 (A2), R40.1
unnamed: IC2.1 (S2), IC12.13 (B6)
unnamed: IC2.13 (S3), IC12.12 (B7)
unnamed: IC2.10 (S4), IC12.11 (B8)
unnamed: IC6.3 (O), IC7.1 (I0)
unnamed: IC6.6 (O), IC7.2 (I1)
unnamed: IC6.8 (O), IC7.4 (I0)
unnamed: IC6.11 (O), IC7.5 (I1)
unnamed: IC7.3 (O), IC7.9 (I0)
unnamed: IC7.6 (O), IC7.10 (I1)
unnamed: IC7.8 (O), IC12.19 (G)
unnamed: IC7.11 (O), IC39.12 (I0)
unnamed: IC9.6 (O), IC39.13 (I1)
unnamed: IC7.13 (I1), IC9.3 (O)
unnamed: IC8.2 (O), IC10.1 (I0)
unnamed: IC8.4 (O), IC10.2 (I1)
unnamed: IC10.3 (O), IC10.4 (I0)
unnamed: IC8.6 (O), IC10.5 (I1)
unnamed: IC8.8 (O), IC10.9 (I0)
unnamed: IC8.10 (O), IC10.10 (I1)
unnamed: D1.C, R1.1
unnamed: IC10.8 (O), IC10.13 (I1)
unnamed: IC10.6 (O), IC10.12 (I0)
unnamed: D41.1 (K2), R42.2
unnamed: IC11.6 (O), IC14.17 (B2)
unnamed: IC11.8 (O), IC14.16 (B3)
unnamed: IC11.11 (O), IC14.15 (B4)
unnamed: IC13.3 (O), IC14.14 (B5)
unnamed: IC13.6 (O), IC14.13 (B6)
unnamed: IC13.8 (O), IC14.12 (B7)
unnamed: IC13.11 (O), IC14.11 (B8)
unnamed: IC16.18 (B1), IC19.3 (O)
unnamed: D14.C, R14.1
unnamed: D21.A, IC2.5 (A1), IC13.1 (I0), IC18.1 (I0), IC20.1 (I0), IC22.15 (B4), IC23.15 (B4), IC24.13 (B6), IC25.15 (B4), SV_ALU_1.27
unnamed: D22.A, IC2.3 (A2), IC13.4 (I0), IC18.4 (I0), IC20.4 (I0), IC22.14 (B5), IC23.14 (B5), IC24.12 (B7), IC25.14 (B5), SV_ALU_1.29
unnamed: D23.A, IC2.14 (A3), IC13.9 (I0), IC18.9 (I0), IC20.9 (I0), IC22.13 (B6), IC23.13 (B6), IC24.11 (B8), IC25.13 (B6), SV_ALU_1.31
unnamed: D24.A, IC2.12 (A4), IC13.12 (I0), IC18.12 (I0), IC20.12 (I0), IC22.12 (B7), IC23.11 (B8), IC23.12 (B7), IC24.18 (B1), IC25.12 (B7), SV_ALU_1.33
unnamed: D2.C, R2.1
unnamed: D32.A, IC5.12 (I0), IC13.13 (I1), IC18.13 (I1), IC20.13 (I1), SV_ALU_1.17
unnamed: IC15.17 (B2), IC17.6 (O)
unnamed: D13.C, R13.1
unnamed: D12.C, R12.1
unnamed: IC15.16 (B3), IC17.8 (O)
unnamed: IC15.15 (B4), IC17.11 (O)
unnamed: IC15.14 (B5), IC18.3 (O)
unnamed: IC15.13 (B6), IC18.6 (O)
unnamed: D38.1 (K2), R38.1
unnamed: D37.1 (K2), R37.1
unnamed: D17.A, IC1.5 (A1), IC11.1 (I0), IC17.1 (I0), IC19.1 (I0), IC24.17 (B2), IC25.11 (B8), SV_ALU_1.19
unnamed: D18.A, IC1.3 (A2), IC11.4 (I0), IC17.4 (I0), IC19.4 (I0), IC22.18 (B1), IC23.18 (B1), IC24.16 (B3), IC25.18 (B1), SV_ALU_1.21
unnamed: D19.A, IC1.14 (A3), IC11.9 (I0), IC17.9 (I0), IC19.9 (I0), IC22.17 (B2), IC23.17 (B2), IC24.15 (B4), IC25.17 (B2), SV_ALU_1.23
unnamed: D20.A, IC1.12 (A4), IC11.12 (I0), IC17.12 (I0), IC19.12 (I0), IC22.16 (B3), IC23.16 (B3), IC24.14 (B5), IC25.16 (B3), SV_ALU_1.25
unnamed: IC15.12 (B7), IC18.8 (O)
unnamed: IC15.11 (B8), IC18.11 (O)
unnamed: IC15.18 (B1), IC17.3 (O)
unnamed: IC16.17 (B2), IC19.6 (O)
unnamed: IC16.16 (B3), IC19.8 (O)
unnamed: IC16.15 (B4), IC19.11 (O)
unnamed: IC16.14 (B5), IC20.3 (O)
unnamed: IC16.13 (B6), IC20.6 (O)
unnamed: IC16.12 (B7), IC20.8 (O)
unnamed: IC16.11 (B8), IC20.11 (O)
unnamed: IC21.18 (B1), IC22.11 (B8), R41.1
unnamed: IC9.9 (I0), IC9.10 (I1), IC9.13 (I1)
unnamed: IC11.3 (O), IC14.18 (B1)
unnamed: D42.1 (K2), R43.2
unnamed: D43.1 (K2), R44.2
unnamed: D44.1 (K2), R45.2
unnamed: D45.1 (K2), R46.2
unnamed: D46.1 (K2), R47.2
unnamed: D47.1 (K2), R48.2
unnamed: D48.1 (K2), R49.2
unnamed: D49.1 (K2), R50.2
unnamed: D50.1 (K2), R51.2
unnamed: D51.1 (K2), R52.2
unnamed: D52.1 (K2), R53.2
unnamed: D53.1 (K2), R54.2
unnamed: D54.1 (K2), R55.2
unnamed: D55.1 (K2), R56.2
unnamed: D56.1 (K2), R57.2
unnamed: D25.A, IC4.1 (I0), IC11.2 (I1), IC17.2 (I1), IC19.2 (I1), SV_ALU_1.3
unnamed: D26.A, IC4.4 (I0), IC11.5 (I1), IC17.5 (I1), IC19.5 (I1), SV_ALU_1.5
unnamed: D28.A, IC4.12 (I0), IC11.13 (I1), IC17.13 (I1), IC19.13 (I1), SV_ALU_1.9
unnamed: D29.A, IC5.1 (I0), IC13.2 (I1), IC18.2 (I1), IC20.2 (I1), SV_ALU_1.11
unnamed: D30.A, IC5.4 (I0), IC13.5 (I1), IC18.5 (I1), IC20.5 (I1), SV_ALU_1.13
unnamed: D31.A, IC5.9 (I0), IC13.10 (I1), IC18.10 (I1), IC20.10 (I1), SV_ALU_1.15
unnamed: D2.A, IC12.3 (A2), IC14.3 (A2), IC15.3 (A2), IC16.3 (A2), IC21.3 (A2), IC22.3 (A2), IC23.3 (A2), IC24.3 (A2), IC25.3 (A2), IC36.4 (D2), IC37.3 (I1)
unnamed: D3.A, IC12.4 (A3), IC14.4 (A3), IC15.4 (A3), IC16.4 (A3), IC21.4 (A3), IC22.4 (A3), IC23.4 (A3), IC24.4 (A3), IC25.4 (A3), IC36.7 (D3), IC37.5 (I0)
unnamed: D4.A, IC12.5 (A4), IC14.5 (A4), IC15.5 (A4), IC16.5 (A4), IC21.5 (A4), IC22.5 (A4), IC23.5 (A4), IC24.5 (A4), IC25.5 (A4), IC36.8 (D4), IC37.6 (I1)
unnamed: D11.C, R11.1
unnamed: D10.C, R10.1
unnamed: D9.C, R9.1
unnamed: D3.C, R3.1
unnamed: D4.C, R4.1
unnamed: D5.C, R5.1
unnamed: D6.C, R6.1
unnamed: D7.C, R7.1
unnamed: D8.C, R8.1
unnamed: D17.C, R17.1
unnamed: D18.C, R18.1
unnamed: D19.C, R19.1
unnamed: D20.C, R20.1
unnamed: D21.C, R21.1
unnamed: D22.C, R22.1
unnamed: D23.C, R23.1
unnamed: D24.C, R24.1
unnamed: D25.C, R25.1
unnamed: D26.C, R26.1
unnamed: D27.C, R27.1
unnamed: D28.C, R28.1
unnamed: D29.C, R29.1
unnamed: D30.C, R30.1
unnamed: D16.A, IC36.19 (Q8), IC38.9 (A8)
unnamed: D15.A, IC36.16 (Q7), IC38.8 (A7)
unnamed: D14.A, IC36.15 (Q6), IC38.7 (A6)
unnamed: D13.A, IC36.12 (Q5), IC38.6 (A5)
unnamed: D12.A, IC36.9 (Q4), IC38.5 (A4)
unnamed: D11.A, IC36.6 (Q3), IC38.4 (A3)
unnamed: D10.A, IC36.5 (Q2), IC38.3 (A2)
unnamed: D9.A, IC36.2 (Q1), IC38.2 (A1)
unnamed: D31.C, R31.1
unnamed: D32.C, R32.1
unnamed: D5.A, IC12.6 (A5), IC14.6 (A5), IC15.6 (A5), IC16.6 (A5), IC21.6 (A5), IC22.6 (A5), IC23.6 (A5), IC24.6 (A5), IC25.6 (A5), IC36.13 (D5), IC37.8 (I0)
unnamed: D7.A, IC12.8 (A7), IC14.8 (A7), IC15.8 (A7), IC16.8 (A7), IC21.8 (A7), IC22.8 (A7), IC23.8 (A7), IC24.8 (A7), IC25.8 (A7), IC36.17 (D7), IC37.11 (I0)
unnamed: D8.A, IC12.9 (A8), IC14.9 (A8), IC15.9 (A8), IC16.9 (A8), IC21.9 (A8), IC22.9 (A8), IC23.9 (A8), IC24.9 (A8), IC25.9 (A8), IC36.18 (D8), IC37.12 (I1)
unnamed: D6.A, IC12.7 (A6), IC14.7 (A6), IC15.7 (A6), IC16.7 (A6), IC21.7 (A6), IC22.7 (A6), IC23.7 (A6), IC24.7 (A6), IC25.7 (A6), IC36.14 (D6), IC37.9 (I1)
NEG: IC3.11 (10), IC6.13 (I1), IC8.11 (I), IC9.4 (I0), R52.1
NOT: IC3.10 (9), IC6.12 (I0), IC8.9 (I), R51.1
OR: IC3.8 (7), IC15.19 (G), R49.1
ROL: IC3.16 (14), IC24.19 (G), R56.1
ROR: IC3.17 (15), IC25.19 (G), R57.1
SBC: IC3.4 (3), IC6.5 (I1), IC8.3 (I), IC9.2 (I1), R45.1
SHL: IC3.13 (11), IC21.19 (G), R53.1
SUB: IC3.3 (2), IC6.4 (I0), IC8.1 (I), R44.1
VCC: C1.1, C2.1, C3.1, C4.1, C5.1, C6.1, C7.1, C8.1, C9.1, C10.1, C11.1, C12.1, C13.1, C14.1, C15.1, C16.1, C17.1, C18.1, C19.1, C20.1, C21.1, C22.1, C23.1, C24.1, C25.1, C26.1, C27.1, C28.1, C29.1, C30.1, C31.1, C32.1, C33.1, D41.2 (A2), D42.2 (A2), D43.2 (A2), D44.2 (A2), D45.2 (A2), D46.2 (A2), D47.2 (A2), D48.2 (A2), D49.2 (A2), D50.2 (A2), D51.2 (A2), D52.2 (A2), D53.2 (A2), D54.2 (A2), D55.2 (A2), D56.2 (A2), IC1.16 (VCC), IC2.16 (VCC), IC3.24 (VCC), IC4.14 (VCC), IC5.14 (VCC), IC6.14 (VCC), IC7.14 (VCC), IC8.13 (I), IC8.14 (VCC), IC9.12 (I0), IC9.14 (VCC), IC10.14 (VCC), IC11.14 (VCC), IC12.20 (VCC), IC13.14 (VCC), IC14.20 (VCC), IC15.20 (VCC), IC16.20 (VCC), IC17.14 (VCC), IC18.14 (VCC), IC19.14 (VCC), IC20.14 (VCC), IC21.20 (VCC), IC22.20 (VCC), IC23.20 (VCC), IC24.20 (VCC), IC25.20 (VCC), IC36.20 (VCC), IC37.14 (VCC), IC38.1 (DIR), IC38.20 (VCC), IC39.14 (VCC), R40.2, SV_ALU_1.1, SV_ALU_1.36, SV_ALU_2.1, SV_ALU_2.36, SV_ALU_SUP1.1, SV_ALU_SUP1.3, SV_ALU_SUP1.5, SV_ALU_SUP2.1, SV_ALU_SUP2.3, SV_ALU_SUP2.5, SV_ALU_SUP3.1, SV_ALU_SUP3.3, SV_ALU_SUP3.5, SV_ALU_SUP4.1, SV_ALU_SUP4.3, SV_ALU_SUP4.5, SV_ALU_SUP5.1, SV_ALU_SUP5.3, SV_ALU_SUP5.5, SV_ALU_SUP6.1, SV_ALU_SUP6.3, SV_ALU_SUP6.5
XOR: IC3.9 (8), IC16.19 (G), R50.1

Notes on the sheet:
Right Hand


Board: 2 copper layers, 228.6 x 163.8 mm, 181 parts (0 on the bottom side), 193 nets.

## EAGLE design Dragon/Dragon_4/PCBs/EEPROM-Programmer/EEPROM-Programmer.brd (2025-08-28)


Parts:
C1: 47µF; E2,5-6E
C2, C3, C4, C5: 0.1µF; C2.5-3
IC1, IC2: 74HC595N; DIL16
MODUL1: ARDUINO_NANO; ARDUINO_NANO2
R1, R2, R3: 10kΩ; 0204/7
U$1: AT28C256

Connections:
3V3: MODUL1.J2.14 (3V3)
AREF: MODUL1.J2.13 (AREF)
GND: C1.-, C2.2, C3.2, C4.2, C5.2, IC1.8 (GND), IC1.13 (G), IC2.8 (GND), IC2.13 (G), MODUL1.J1.4 (GND), MODUL1.J2.2 (GND2), U$1.GND (14)
unnamed: IC1.15 (QA), U$1.A0 (10)
unnamed: IC1.1 (QB), U$1.A1 (9)
unnamed: IC1.2 (QC), U$1.A2 (8)
unnamed: IC1.3 (QD), U$1.A3 (7)
unnamed: IC1.4 (QE), U$1.A4 (6)
unnamed: IC1.5 (QF), U$1.A5 (5)
unnamed: IC1.6 (QG), U$1.A6 (4)
unnamed: IC1.7 (QH), U$1.A7 (3)
unnamed: IC2.15 (QA), U$1.A8 (25)
unnamed: IC2.1 (QB), U$1.A9 (24)
unnamed: IC2.2 (QC), U$1.A10 (21)
unnamed: IC2.3 (QD), U$1.A11 (23)
unnamed: IC2.4 (QE), U$1.A12 (2)
unnamed: IC2.5 (QF), U$1.A13 (26)
unnamed: IC2.6 (QG), U$1.A14 (1)
unnamed: MODUL1.J1.5 (D2), U$1.I/O0 (11)
unnamed: MODUL1.J2.12 (A0), R3.2, U$1.!WE (27)
unnamed: MODUL1.J1.6 (D3), U$1.I/O1 (12)
unnamed: MODUL1.J1.7 (D4), U$1.I/O2 (13)
unnamed: MODUL1.J1.8 (D5), U$1.I/O3 (15)
unnamed: MODUL1.J1.9 (D6), U$1.I/O4 (16)
unnamed: MODUL1.J1.10 (D7), U$1.I/O5 (17)
unnamed: MODUL1.J1.11 (D8), U$1.I/O6 (18)
unnamed: MODUL1.J1.12 (D9), U$1.I/O7 (19)
unnamed: MODUL1.J2.11 (A1), R2.2, U$1.!CE (20)
unnamed: MODUL1.J2.10 (A2), R1.2, U$1.!OE (22)
unnamed: IC2.11 (SCK), MODUL1.J2.9 (A3)
unnamed: IC1.11 (SCK), MODUL1.J2.8 (A4)
unnamed: IC1.14 (SER), IC2.14 (SER), MODUL1.J2.7 (A5)
unnamed: IC1.12 (RCK), IC2.12 (RCK), MODUL1.J2.15 (D13/SCK)
VCC: C1.+, C2.1, C3.1, C4.1, C5.1, IC1.10 (SCL), IC1.16 (VCC), IC2.10 (SCL), IC2.16 (VCC), MODUL1.J2.4 (+5V), R1.1, R2.1, R3.1, U$1.VCC (28)
VIN: MODUL1.J2.1 (VIN)


Board: 2 copper layers, 124.5 x 45.7 mm, 12 parts (0 on the bottom side), 32 nets.

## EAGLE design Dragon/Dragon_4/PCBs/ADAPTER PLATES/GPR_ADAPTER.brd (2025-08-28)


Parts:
SV1, SV2, SV3, SV4: MA18-2

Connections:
unnamed: SV1.36, SV3.36
unnamed: SV1.34, SV3.34
unnamed: SV1.32, SV3.32
unnamed: SV1.30, SV3.30
unnamed: SV1.28, SV3.28
unnamed: SV1.26, SV3.26
unnamed: SV1.24, SV3.24
unnamed: SV1.22, SV3.22
unnamed: SV1.20, SV3.20
unnamed: SV1.18, SV3.18
unnamed: SV1.16, SV3.16
unnamed: SV1.14, SV3.14
unnamed: SV1.12, SV3.12
unnamed: SV1.10, SV3.10
unnamed: SV1.8, SV3.8
unnamed: SV1.6, SV3.6
unnamed: SV1.4, SV3.4
unnamed: SV1.2, SV3.2
unnamed: SV2.34, SV4.34
unnamed: SV2.32, SV4.32
unnamed: SV2.30, SV4.30
unnamed: SV2.28, SV4.28
unnamed: SV2.26, SV4.26
unnamed: SV2.24, SV4.24
unnamed: SV2.22, SV4.22
unnamed: SV2.20, SV4.20
unnamed: SV2.18, SV4.18
unnamed: SV2.16, SV4.16
unnamed: SV2.14, SV4.14
unnamed: SV2.12, SV4.12
unnamed: SV2.10, SV4.10
unnamed: SV2.8, SV4.8
unnamed: SV2.6, SV4.6
unnamed: SV2.4, SV4.4
unnamed: SV2.2, SV4.2
unnamed: SV2.36, SV4.36
unnamed: SV1.3, SV3.3
unnamed: SV1.5, SV3.5
unnamed: SV1.7, SV3.7
unnamed: SV1.9, SV3.9
unnamed: SV1.11, SV3.11
unnamed: SV1.13, SV3.13
unnamed: SV1.15, SV3.15
unnamed: SV1.17, SV3.17
unnamed: SV1.19, SV3.19
unnamed: SV1.21, SV3.21
unnamed: SV1.23, SV3.23
unnamed: SV1.25, SV3.25
unnamed: SV1.27, SV3.27
unnamed: SV1.29, SV3.29
unnamed: SV1.31, SV3.31
unnamed: SV1.33, SV3.33
unnamed: SV1.35, SV3.35
unnamed: SV1.1, SV3.1
unnamed: SV2.3, SV4.3
unnamed: SV2.5, SV4.5
unnamed: SV2.7, SV4.7
unnamed: SV2.9, SV4.9
unnamed: SV2.11, SV4.11
unnamed: SV2.13, SV4.13
unnamed: SV2.15, SV4.15
unnamed: SV2.17, SV4.17
unnamed: SV2.19, SV4.19
unnamed: SV2.21, SV4.21
unnamed: SV2.23, SV4.23
unnamed: SV2.25, SV4.25
unnamed: SV2.27, SV4.27
unnamed: SV2.29, SV4.29
unnamed: SV2.31, SV4.31
unnamed: SV2.33, SV4.33
unnamed: SV2.35, SV4.35
unnamed: SV2.1, SV4.1


Board: 2 copper layers, 127.0 x 55.9 mm, 4 parts (0 on the bottom side), 72 nets.

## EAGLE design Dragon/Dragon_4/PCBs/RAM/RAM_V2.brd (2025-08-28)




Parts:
D1, D2, D3, D4, D5, D6, D7, D8, D9, D10, D11, D12, D13, D14, D15, D16, D17, D18, D19, D20, D21, D22, D23, D24: LTST-C193KRKT-5A; LEDC1608X45N
IC1: 74HCT04N; DIL14
IC2, IC5: 74HCT32N; DIL14
IC3: 74HCT08N; DIL14
IC4: 74HCT245N; DIL20
R1, R2, R3, R4, R5, R6, R7, R8, R9, R10, R11, R12, R13, R14, R15, R16, R17, R18, R19, R20, R21, R22, R23, R24: R-EU_R0805; R0805
SV1, SV2, SV3, SV4: MA18-2
U$1, U$2: AS6C62256

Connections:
!ASSERT_MAIN: IC3.5 (I1)
!CLK: IC2.1 (I0), IC2.13 (I1)
!MW_E: IC3.2 (I1)
!WE: IC3.1 (I0)
ADDRESS_BUS_0: D1.A, U$1.A0, U$2.A0
ADDRESS_BUS_1: D2.A, U$1.A1, U$2.A1
ADDRESS_BUS_2: D3.A, U$1.A2, U$2.A2
ADDRESS_BUS_3: D4.A, U$1.A3, U$2.A3
ADDRESS_BUS_4: D5.A, U$1.A4, U$2.A4
ADDRESS_BUS_5: D6.A, U$1.A5, U$2.A5
ADDRESS_BUS_6: D7.A, U$1.A6, U$2.A6
ADDRESS_BUS_7: D8.A, U$1.A7, U$2.A7
ADDRESS_BUS_8: D9.A, U$1.A8, U$2.A8
ADDRESS_BUS_9: D10.A, U$1.A9, U$2.A9
ADDRESS_BUS_10: D11.A, U$1.A10, U$2.A10
ADDRESS_BUS_11: D12.A, U$1.A11, U$2.A11
ADDRESS_BUS_12: D13.A, U$1.A12, U$2.A12
ADDRESS_BUS_13: D14.A, U$1.A13, U$2.A13
ADDRESS_BUS_14: D15.A, U$1.A14, U$2.A14
ADDRESS_BUS_15: D16.A, IC1.1 (I), IC1.3 (I), IC1.9 (I), IC2.4 (I0), IC5.2 (I1), U$1.!CE
AYETG: IC1.5 (I), IC1.11 (I), IC2.5 (I1), IC2.12 (I0), IC3.3 (O), IC3.4 (I0)
DATA_BUS_0: D17.A, IC4.18 (B1), U$1.I/O0, U$2.I/O0
DATA_BUS_1: D18.A, IC4.17 (B2), U$1.I/O1, U$2.I/O1
DATA_BUS_2: D19.A, IC4.16 (B3), U$1.I/O2, U$2.I/O2
DATA_BUS_3: D20.A, IC4.15 (B4), U$1.I/O3, U$2.I/O3
DATA_BUS_4: D21.A, IC4.14 (B5), U$1.I/O4, U$2.I/O4
DATA_BUS_5: D22.A, IC4.13 (B6), U$1.I/O5, U$2.I/O5
DATA_BUS_6: D23.A, IC4.12 (B7), U$1.I/O6, U$2.I/O6
DATA_BUS_7: D24.A, IC4.11 (B8), U$1.I/O7, U$2.I/O7
GND: IC1.7 (GND), IC2.7 (GND), IC3.7 (GND), IC4.10 (GND), IC5.7 (GND), R1.1, R2.1, R3.1, R4.1, R5.1, R6.1, R7.1, R8.1, R9.1, R10.1, R11.1, R12.1, R13.1, R14.1, R15.1, R16.1, R17.1, R18.1, R19.1, R20.1, R21.1, R22.1, R23.1, R24.1, U$1.GND, U$2.GND
MAIN_BUS_0: IC4.2 (A1)
MAIN_BUS_1: IC4.3 (A2)
MAIN_BUS_2: IC4.4 (A3)
MAIN_BUS_3: IC4.5 (A4)
MAIN_BUS_4: IC4.6 (A5)
MAIN_BUS_5: IC4.7 (A6)
MAIN_BUS_6: IC4.8 (A7)
MAIN_BUS_7: IC4.9 (A8)
unnamed: D1.C, R1.2
unnamed: D2.C, R2.2
unnamed: D3.C, R3.2
unnamed: D4.C, R4.2
unnamed: D5.C, R5.2
unnamed: D6.C, R6.2
unnamed: D7.C, R7.2
unnamed: D8.C, R8.2
unnamed: D9.C, R9.2
unnamed: D10.C, R10.2
unnamed: D11.C, R11.2
unnamed: D12.C, R12.2
unnamed: D13.C, R13.2
unnamed: D14.C, R14.2
unnamed: D15.C, R15.2
unnamed: D16.C, R16.2
unnamed: D17.C, R17.2
unnamed: D18.C, R18.2
unnamed: D20.C, R20.2
unnamed: D21.C, R21.2
unnamed: D22.C, R22.2
unnamed: D23.C, R23.2
unnamed: D24.C, R24.2
unnamed: IC2.3 (O), U$1.!WE
unnamed: IC5.3 (O), U$1.!OE
unnamed: IC2.2 (I1), IC2.6 (O)
unnamed: IC2.8 (O), U$2.!WE
unnamed: IC5.6 (O), U$2.!OE
unnamed: IC1.2 (O), U$2.!CE
unnamed: D19.C, R19.2
unnamed: IC2.10 (I1), IC2.11 (O)
unnamed: IC1.4 (O), IC2.9 (I0)
unnamed: IC1.6 (O), IC5.1 (I0), IC5.4 (I0)
unnamed: IC1.8 (O), IC5.5 (I1)
unnamed: IC1.10 (O), IC4.1 (DIR)
unnamed: IC3.6 (O), IC4.19 (G)
VCC: IC1.14 (VCC), IC2.14 (VCC), IC3.14 (VCC), IC4.20 (VCC), IC5.14 (VCC), U$1.VCC, U$2.VCC

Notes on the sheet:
High = A to B
CE and WE has to be low in order to change address while writing

Board: 2 copper layers, 59 parts (0 on the bottom side), 64 nets, no tracks yet.

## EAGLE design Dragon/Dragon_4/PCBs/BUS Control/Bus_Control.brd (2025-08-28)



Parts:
C1, C2, C3, C4, C5, C6, C7, C8, C9, C10, C11: C-EUC0805; C0805
IC1, IC2: 74HCT154N; DIL24-6
IC3, IC4, IC5, IC6, IC7: 74HCT138N; DIL16
SV_BUS_CONTROL_1, SV_BUS_CONTROL_2, SV_BUS_CONTROL_3, SV_BUS_CONTROL_4: MA18-2

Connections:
!CTRL_ALU_ASSERT: IC1.10 (9), SV_BUS_CONTROL_2.18
!CTRL_CONST_ASSERT: IC1.17 (15), SV_BUS_CONTROL_2.6
!CTRL_CONST_LOAD: IC2.17 (15), SV_BUS_CONTROL_2.33
!CTRL_CREG_ASSERT_ADDR: IC3.12 (Y3), SV_BUS_CONTROL_3.30
!CTRL_CREG_ASSERT_XFER: IC1.9 (8), SV_BUS_CONTROL_2.20
!CTRL_CREG_DEC: IC5.12 (Y3), SV_BUS_CONTROL_3.25
!CTRL_CREG_INC: IC4.12 (Y3), SV_BUS_CONTROL_3.15
!CTRL_CREG_LOAD_XFER: IC2.9 (8), SV_BUS_CONTROL_2.19
!CTRL_DPLY_ENABLE: IC2.11 (10), SV_BUS_CONTROL_2.23
!CTRL_GPR_A_ASSERT: IC1.2 (1), SV_BUS_CONTROL_2.34
!CTRL_GPR_A_ASSERT_ALU_L: IC7.14 (Y1), SV_BUS_CONTROL_3.16
!CTRL_GPR_A_ASSERT_ALU_R: IC6.14 (Y1), SV_BUS_CONTROL_3.26
!CTRL_GPR_A_LOAD: IC2.2 (1), SV_BUS_CONTROL_2.5
!CTRL_GPR_B_ASSERT: IC1.3 (2), SV_BUS_CONTROL_2.32
!CTRL_GPR_B_ASSERT_ALU_L: IC7.13 (Y2), SV_BUS_CONTROL_3.14
!CTRL_GPR_B_ASSERT_ALU_R: IC6.13 (Y2), SV_BUS_CONTROL_3.24
!CTRL_GPR_B_LOAD: IC2.3 (2), SV_BUS_CONTROL_2.7
!CTRL_GPR_C_ASSERT: IC1.4 (3), SV_BUS_CONTROL_2.30
!CTRL_GPR_C_ASSERT_ALU_L: IC7.12 (Y3), SV_BUS_CONTROL_3.12
!CTRL_GPR_C_ASSERT_ALU_R: IC6.12 (Y3), SV_BUS_CONTROL_3.22
!CTRL_GPR_C_LOAD: IC2.4 (3), SV_BUS_CONTROL_2.9
!CTRL_GPR_D_ASSERT: IC1.5 (4), SV_BUS_CONTROL_2.28
!CTRL_GPR_D_ASSERT_ALU_L: IC7.11 (Y4), SV_BUS_CONTROL_3.10
!CTRL_GPR_D_ASSERT_ALU_R: IC6.11 (Y4), SV_BUS_CONTROL_3.20
!CTRL_GPR_D_LOAD: IC2.5 (4), SV_BUS_CONTROL_2.11
!CTRL_GPR_X_ASSERT: IC1.6 (5), SV_BUS_CONTROL_2.26
!CTRL_GPR_X_ASSERT_ALU_L: IC7.10 (Y5), SV_BUS_CONTROL_3.8
!CTRL_GPR_X_ASSERT_ALU_R: IC6.10 (Y5), SV_BUS_CONTROL_3.18
!CTRL_GPR_X_LOAD: IC2.6 (5), SV_BUS_CONTROL_2.13
!CTRL_IR_LOAD: IC2.13 (11), SV_BUS_CONTROL_2.25
!CTRL_PC_ASSERT_ADDR: IC3.14 (Y1), SV_BUS_CONTROL_3.34
!CTRL_PC_ASSERT_XFER: IC1.7 (6), SV_BUS_CONTROL_2.24
!CTRL_PC_DEC: IC5.14 (Y1), SV_BUS_CONTROL_3.21
!CTRL_PC_INC: IC4.14 (Y1), SV_BUS_CONTROL_3.11
!CTRL_PC_LOAD_XFER: IC2.7 (6), SV_BUS_CONTROL_2.15
!CTRL_RAM_ASSERT_MAIN: IC1.11 (10), SV_BUS_CONTROL_2.16
!CTRL_RAM_LOAD_MAIN: IC2.10 (9), SV_BUS_CONTROL_2.21
!CTRL_SP_ASSERT_ADDR: IC3.13 (Y2), SV_BUS_CONTROL_3.32
!CTRL_SP_ASSERT_XFER: IC1.8 (7), SV_BUS_CONTROL_2.22
!CTRL_SP_DEC: IC5.13 (Y2), SV_BUS_CONTROL_3.23
!CTRL_SP_INC: IC4.13 (Y2), SV_BUS_CONTROL_3.13
!CTRL_SP_LOAD_XFER: IC2.8 (7), SV_BUS_CONTROL_2.17
!CTRL_XFER_ASSERT_ADDR: IC3.11 (Y4), SV_BUS_CONTROL_3.28
!CTRL_XFER_ASSERT_XFER: IC1.14 (12), SV_BUS_CONTROL_2.12
!CTRL_XFER_LOAD_XFER: IC2.14 (12), SV_BUS_CONTROL_2.27
!CTRL_XFER_L_ASSERT: IC1.16 (14), SV_BUS_CONTROL_2.8
!CTRL_XFER_L_LOAD: IC2.16 (14), SV_BUS_CONTROL_2.31
!CTRL_XFER_R_ASSERT: IC1.15 (13), SV_BUS_CONTROL_2.10
!CTRL_XFER_R_LOAD: IC2.15 (13), SV_BUS_CONTROL_2.29
BUS_CTRL1_REG_A_1: IC1.23 (A), SV_BUS_CONTROL_1.34
BUS_CTRL2_REG_A_2: IC1.22 (B), SV_BUS_CONTROL_1.32
BUS_CTRL3_REG_A_3: IC1.21 (C), SV_BUS_CONTROL_1.30
BUS_CTRL4_REG_A_4: IC1.20 (D), SV_BUS_CONTROL_1.28
BUS_CTRL5_REG_L_1: IC2.23 (A), SV_BUS_CONTROL_1.26
BUS_CTRL6_REG_L_2: IC2.22 (B), SV_BUS_CONTROL_1.24
BUS_CTRL7_REG_L_3: IC2.21 (C), SV_BUS_CONTROL_1.22
BUS_CTRL8_REG_L_4: IC2.20 (D), SV_BUS_CONTROL_1.20
BUS_CTRL9_16REG_A_ADDR_1: IC3.1 (A), SV_BUS_CONTROL_1.18
BUS_CTRL10_16REG_A_ADDR_2: IC3.2 (B), SV_BUS_CONTROL_1.16
BUS_CTRL11_16REG_A_ADDR_3: IC3.3 (C), SV_BUS_CONTROL_1.14
BUS_CTRL12_CREG_INC_1: IC4.1 (A), SV_BUS_CONTROL_1.12
BUS_CTRL13_CREG_INC_2: IC4.2 (B), SV_BUS_CONTROL_1.10
BUS_CTRL14_CREG_DEC_1: IC5.1 (A), SV_BUS_CONTROL_1.8
BUS_CTRL15_CREG_DEC_2: IC5.2 (B), SV_BUS_CONTROL_1.6
BUS_CTRL17_GPR_A_ALU_R_1: IC6.1 (A), SV_BUS_CONTROL_1.29
BUS_CTRL18_GPR_A_ALU_R_2: IC6.2 (B), SV_BUS_CONTROL_1.31
BUS_CTRL19_GPR_A_ALU_R_3: IC6.3 (C), SV_BUS_CONTROL_1.33
BUS_CTRL20_GPR_A_ALU_L_1: IC7.1 (A), SV_BUS_CONTROL_1.23
BUS_CTRL21_GPR_A_ALU_L_2: IC7.2 (B), SV_BUS_CONTROL_1.25
BUS_CTRL22_GPR_A_ALU_L_3: IC7.3 (C), SV_BUS_CONTROL_1.27
GND: C1.2, C2.2, C3.2, C4.2, C5.2, C6.2, C7.2, C8.2, C9.2, C10.2, C11.2, IC1.12 (GND), IC1.18 (G1), IC1.19 (G2), IC2.12 (GND), IC2.18 (G1), IC2.19 (G2), IC3.4 (G2A), IC3.5 (G2B), IC3.8 (GND), IC4.3 (C), IC4.4 (G2A), IC4.5 (G2B), IC4.8 (GND), IC5.3 (C), IC5.4 (G2A), IC5.5 (G2B), IC5.8 (GND), IC6.4 (G2A), IC6.5 (G2B), IC6.8 (GND), IC7.4 (G2A), IC7.5 (G2B), IC7.8 (GND), SV_BUS_CONTROL_1.2, SV_BUS_CONTROL_1.35, SV_BUS_CONTROL_2.2, SV_BUS_CONTROL_2.35, SV_BUS_CONTROL_3.2, SV_BUS_CONTROL_3.35, SV_BUS_CONTROL_4.2, SV_BUS_CONTROL_4.35
unnamed: IC1.13 (11), SV_BUS_CONTROL_2.14
VCC: C1.1, C2.1, C3.1, C4.1, C5.1, C6.1, C7.1, C8.1, C9.1, C10.1, C11.1, IC1.24 (VCC), IC2.24 (VCC), IC3.6 (G1), IC3.16 (VCC), IC4.6 (G1), IC4.16 (VCC), IC5.6 (G1), IC5.16 (VCC), IC6.6 (G1), IC6.16 (VCC), IC7.6 (G1), IC7.16 (VCC), SV_BUS_CONTROL_1.1, SV_BUS_CONTROL_1.36, SV_BUS_CONTROL_2.1, SV_BUS_CONTROL_2.36, SV_BUS_CONTROL_3.1, SV_BUS_CONTROL_3.36, SV_BUS_CONTROL_4.1, SV_BUS_CONTROL_4.36


Board: 2 copper layers, 190.5 x 55.9 mm, 22 parts (0 on the bottom side), 73 nets.

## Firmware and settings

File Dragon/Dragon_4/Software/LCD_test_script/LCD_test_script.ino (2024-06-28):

const int datapins[] = {9, 8, 7, 6, 5, 4, 3, 2};
const int enablePIN = 10;
const int RW = 12;
const int RS = 11;
const int V0 = 13;
const int contrast = 0;
int input;

void write_data(bool RS_bit, bool RW_bit, byte data) {
  delayMicroseconds(60);
  if (RS_bit == 1) {
    digitalWrite(RS, HIGH);
  } else {
    digitalWrite(RS, LOW);
  }
  if (RW_bit == 1) {
    digitalWrite(RW, HIGH);
  } else {
    digitalWrite(RW, LOW);
  }
  
  for (int  i = 0; i < 8; i++) {
    if (bitRead(data, i) == 1) {
      digitalWrite(datapins[i], HIGH);
    } else {
      digitalWrite(datapins[i], LOW);
    }
   }
  delayMicroseconds(1000);
  digitalWrite(enablePIN, HIGH);
  delayMicroseconds(1);
  digitalWrite(enablePIN, LOW);
}

void initialization() {
  Serial.begin(9600);
  for (int pin = 0; pin < (sizeof(datapins) / 2 ); pin++) {
    pinMode(datapins[pin], OUTPUT);
  }
  pinMode(enablePIN, OUTPUT);
  pinMode(RW, OUTPUT);
  pinMode(RS, OUTPUT);
  pinMode(V0, OUTPUT);
  analogWrite(V0, contrast);

  write_data(0, 0, B00111100);
  write_data(0, 0, B00001000);
  write_data(0, 0, B00000001);
  write_data(0, 0, B00000110);
  write_data(0, 0, B00001110);
}

void setup() {
  delay(1000);
  initialization();
  
  //write_data(RS, RW, DATA);
  
}

void loop() {
  if(Serial.available()){
        input = Serial.read();
        if (input != 10) {
          Serial.println(input);
          write_data(1, 0, input);
          delay(1);
          write_data(0, 0, B00011100);
        }
  }

}

/*
void write_data(bool RS_bit, bool RW_bit, byte data, byte line = 0) {
    delayMicroseconds(60);
    if (RS_bit == 1) {
        digitalWrite(RS, HIGH);
    } else {
        digitalWrite(RS, LOW);
    }
    if (RW_bit == 1) {
        digitalWrite(RW, HIGH);
    } else {
        digitalWrite(RW, LOW);
    }
  
    if (line != 0) { 
    // added the following code
    byte DDRAM_address;
    if (line == 1) {
        DDRAM_address = 0x00;
    } else if (line == 2) {
        DDRAM_address = 0x40;
    } else {
        DDRAM_address = 0x00; // default to line 1
    }
    // send command to set DDRAM address
    for (int i = 0; i < 8; i++) {
        if (bitRead(DDRAM_address, i) == 1) {
            digitalWrite(datapins[i], HIGH);
        } else {
            digitalWrite(datapins[i], LOW);
        }
    }
    
    delayMicroseconds(1000);
    digitalWrite(enablePIN, HIGH);
    delayMicroseconds(1);
    digitalWrite(enablePIN, LOW);
  
    // write data to the desired position
    for (int i = 0; i < 8; i++) {
        if (bitRead(data, i) == 1) {
            digitalWrite(datapins[i], HIGH);
        } else {
            digitalWrite(datapins[i], LOW);
        }
    }
    delayMicroseconds(1000);
    digitalWrite(enablePIN, HIGH);
    delayMicroseconds(1);
    digitalWrite(enablePIN, LOW);
}
*/

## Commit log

2024-06-28 inital commit
    [InstructionSet LED+++.xlsx, Instruction_Microcode_Dragon_4.xlsx, LED+ instructionset.xlsx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]
2024-07-10 refactored Phönix-2 into Dragon-5
    [Dragon-5.xlsx, Phoenix-1.xlsx]
2024-09-28 Dragon 5 is now Phönix-1
    [Dragon-5.xlsx]
2025-06-12 created Dragon-5 instruction-set
    [Dragon-5.xlsx]
2025-06-14 improved Dragon 5 ISA
    [Dragon-5.xlsx]
2025-08-28 added missing files
    [16_Bit_Register.brd, 16_Bit_Register.sch, ALU.brd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]
2025-12-06 Continued microarchitecture, small fixes - continued microarchitecture diagram - fixed jumps explanation in ISA - after careful consideration, omitted the variable instruction length idea because it 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
    [Memory Layout.ods]
2025-12-08 Rethought RAM, began implementing cache in sim. - Reimplemented Register file in simulation after thinking how to implement the register file IRL I noticed that this is pretty much impossible because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
2026-02-11 refactored archive
    [Dragon-5.xlsx, Memory Layout.ods]
2026-03-06 finished implementing caches in logisim - finished instruction cache - finished data cache - thought about RAM implementation
    [Memory Layout.ods]
